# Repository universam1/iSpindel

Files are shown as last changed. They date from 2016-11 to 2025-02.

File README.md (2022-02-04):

# iSpindel - *DIY electronic Hydrometer*

**[www.ispindel.de](http://www.ispindel.de)**

***
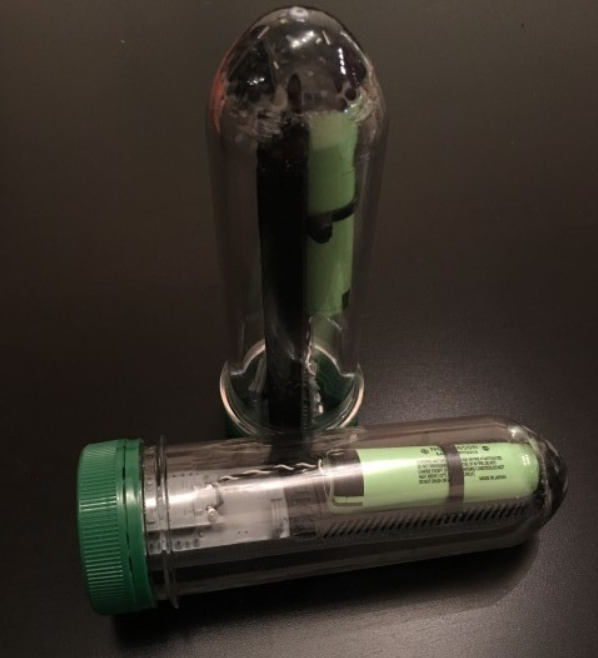
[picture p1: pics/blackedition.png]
Dashboard

***



***

## Featured in german brewing magazine [Braumagazin.de](http://braumagazin.de/?issue=2018-01)

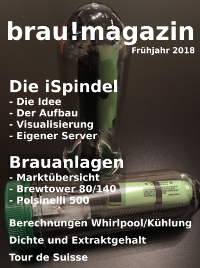
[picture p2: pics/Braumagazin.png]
Braumagazin 1-18 (http://braumagazin.de/?issue=2018-01)


***

If you like that project please vote for the [Hackaday.io *2017 Prize List*](https://hackaday.io/project/20421-ispindel)

Check out [IOT DEVICE PULLS ITS WEIGHT IN HOME BREWING](http://hackaday.com/2017/03/01/iot-device-pulls-its-weight-in-home-brewing/)

## There are FAQs:
### [Deutsche FAQ] - docs/FAQ.md
### [English FAQ] - docs/FAQ-en.md
### [中文 FAQ] - docs/FAQ-zh.md

## Documentation in other languages

### [English Documentation (work in progress)](docs/README_en.md) 🇺🇸

### [Nederlandse Vertaling (lopende werkzaamheden)](docs/README_nl.md) 🇳🇱

### [Documentação em Português (trabalho em andamento)](docs/README_pt.md) 🇧🇷

### [中文文档 (完善中)](docs/README_zh.md) CN

***

***Say thanks with a beer*** :beers:



***

## [Firmware download here](https://github.com/universam1/iSpindel/releases)

***

## ChangeLog

| Date | Note |
| :--- | :--- |
| 10.06.21 | Firmware 7.1.0: Added  support for [BierBot Bricks](https://bierbot.com/#/site/). |
| 05.06.21 | Firmware 7.0.0: migrate to LittleFS (SPIFFS is replaced in favor of LittleFS being its successor) |
| 04.02.21 | Firmware 6.5.1: New tilt equation, support for Brewblox via MQTT, improved calibration tools - thanks for contributions @tomsykes @bdelbosc @vitotai @thegreatgunbantoad and many others |
| 17.11.19 | Firmware 6.2.0: New Calibration routine: The calibration procedure takes now less than 5s only to determine offsets that set the current position of the Accelerometer close as possible to level! Also this new implementation solves a few issues reported where the values have not been saved reliably. Also, the configuration file routine has been improved to support larger strings that were clipped at some point |
| 10.11.19 | Firmware 6.1.3: Extending the length of URL parameter to support API Gateway URLs. Fixes of incompatibilities from #308. Support for latest ESP8266 SDK solving naming collisions |
| 8.11.19 | Firmware 6.1.2: hardening SPIFFS config save routine |
| 27.10.19 | Firmware 6.1.1: Added support for ThingSpeak (#305) (#308), improving documentation, fix for prometheus sender data (#303), updating to new PIO output path |
| 27.10.19 | Firmware 6.1.0:  migrating to ArduinoJSON v6 |
| 27.10.19 | Firmware 6.0.6:  expand size to support longer urls |
| 7.3.2019 | Firmware 6.0.5: Fix Javascript issue with selection of the Service Type |
| 19.12.2018 | Firmware 6.0.4: Higher precision for polynominal possible |
| 19.12.2018 | Firmware 6.0.3: Higher precision for gravity displayed in status page |
| 24.10.2018 | Firmware 6.0.2: Display issues on MacOS resolved |
| 22.08.2018 | **Firmware 6.0.0**:<br>1. Alternative pin for OneWire tempearuture sensor DS18B20 now possible. This allows a different PCB schema to use either pin `D1` or `D6`. <br>2. Auto detection of OneWire pin, successfull detected pin will be saved together with a config `save` action. Output of detailed debug information of OneWire Sensor during searches, helping those with hardware issues. <br>3. Increased battery lifetime of about 20% by reducing the runtime to ~2200ms through various tunings.<br>4. Using *Interrupts* instead of delays to read the Accelerometer, allows significant shorter read intervals <br>5. Shorter read cycles allow  *more precision*, increased samples from 7 to 39 samples that still fit into the necessary wait state for the Temp sensor! |
| 16.08.2018 | Firmware 5.9.1: Fixing Ubidots issue and extending MQTT |
| 09.08.2018 | Firmware 5.9.0: Support for MQTT, InfluxDB (Thanks to jmelhus, iceaway and thorrak) |
| 13.05.2018 | Firmware 5.8.6: allow longer fields for polynominal, SSID and Password |
| 15.03.2018 | Firmware 5.8.5: adding support for Prometheus Pushgateway, thanks to @jankeesv |
| 08.03.2018 | Firmware 5.8.4: adding support for logging temperature data in Fahrenheit and Kelvin, thanks to @iceaway |
| 05.03.2018 | Firmware 5.8.3: Support for InfluxDB as additional backend, thanks to @iceaway |
| 23.02.2018 | New drawer version 'mwx-Edition' using threaded bolt nut and washer - thanks to @mwx |
| 21.02.2018 | Firmware 5.8.2: Extend token size to 40 char to support longer Ubidots token |
| 14.02.2018 | Firmware 5.8.1: HTML encode special character in configuration forms, allows displaying the passwort correctly |
| 09.02.2018 | Firmware 5.8.0: Transmitting the Wifi strength RSSI to insight of the reception |
| 07.02.2018 | Firmware 5.7.1: Allow longer sleep intervals longer up to 99999s == 27 days |
| 03.02.2018 | Firmware 5.7.0: Introduce Factory Reset feature |
| 02.02.2018 | Firmware 5.6.2: Support for Wifi credentials with special characters |
| 07.11.2017 | Firmware 5.6.1: Restoring Wifi credentials, moved to HTTP client library, improved RFCAL resilience to gain more stable Wifi connection |
| 17.10.2017 | Firmware 5.5.4: Various fixes for CraftBeerPi, BrewPiLess and Ubidots |
| 28.09.2017 | Firmware 5.5.0: Recall saved Wifi credential thus persisting over configuration changes |
| 31.08.2017 | iSpindle.py Version 1.3.1: genericTCP Update (local server & prep for public server); Firmware 5.4.2: Memory improvements. |
| 29.08.2017 | Firmware 5.4.1: Rewrite of the upload class to streamline and allow further data items. Also add iSpindel.de as data server as preset. |
| 08.08.2017 | [calibration tool](http://www.ispindel.de/tools/calibration/calibration.htm) to calculate gravity as alternative to the Excel sheet |
| 05.07.2017 | Workaround for BrewPiLess |
| 30.06.2017 | Mentioned in http://preview.mailerlite.com/g6n5p3/660851237247259035/r2w6/ |
| 22.05.2017 | updated build docs |
| 22.05.2017 | switching build environment to platform.io |
| 01.05.2017 | Major Firmware update to 5! Calculate the Gravity now within the iSpindel by expression evaluation! The conversion polynom can be stored per iSpindel and sends as an additional metric (without a unit). Therefore, whether Plato or SG is prefered is up to the user defined polynom. There are two variable available `tilt` and `temp`. Zero point calibration. Firmware update OTA over the Air |
| 12.04.2017 | Mentioned in http://www.homebrewtalk.com/showthread.php?t=598187 |
| 01.03.2017 | Mentioned in hackaday.com http://hackaday.com/2017/03/01/iot-device-pulls-its-weight-in-home-brewing/ |
| 23.02.2017 | English documentation added |
| 14.02.2017 | English documentation added |
| 09.02.2017 | Firmware 4.1.6 |
| 31.01.2017 | Bilder Aufbau Platinenvariante |
| 26.01.2017 | Firmware 4.0: inifinte sleep time developed: the maximum 71min RTC time extends through step-sleeps . Wifi RF calibration introduced when calling configuration. fixed bug of emergency interval. fixed UI numeric formating |
| 25.02.2017 | Firmware 3.5.0: genericTCP: Python Skript um lokal die Daten in eine CSV Datei zu schreiben (thanks to Tozzi) |
| 23.12.2016 | CraftBeerPi Info, FW.3.4.4, Combo-Schlitten |
| 18.12.2016 | FAQ und Ubidots tool |
| 15.11.2016 | Firmware 3.4.2: Supporting now backends: CraftBeerPi, TControl,FHEM, generic HTTP. major Portal rework, added labels for convenience, upload speed improvements, Power saving on empty battery, added custom Battery conversion factor, Bugfixes |
| 11.12.2016 | Sources and drawer online |
| 11.12.2016 | FHEM upload documentation & firmware (thanks @MSBannert!) |
| 07.12.2016 | Schematics |
| 03.12.2016 | Firmware 2.1.2 Wifi improvements |
| 09.11.2016 | Calibration and Excel sheet for conversion to Plato, SG etc. |

***

> Contribution and support is appreciated especially regarding creation and translation of documentation. Feel free to provide a `pull request`.  
>
> Die `iSpindel` befindet sich in andauernder Entwicklung, siehe dazu [den Hobbybrauer.de Thread](http://hobbybrauer.de/forum/viewtopic.php?f=7&t=11235). Mithilfe ist herzlich willkommen und Ergänzungen bitte per Pull Request einreichen. Großes Dank an alle die Unterstützung leisten seitens Grundlagen erarbeiten oder passende Hardware zu finden.

## Inhaltverzeichnis

- [iSpindel - *DIY electronic Hydrometer*](#ispindel-diy-electronic-hydrometer)
  - [Featured in german brewing magazine Braumagazin.de](#featured-in-german-brewing-magazine-braumagazinde)
  - [There are FAQs:](#there-are-faqs)
    - [[Deutsche FAQ] - docs/FAQ.md](#deutsche-faq-docsfaqmd)
    - [[English FAQ] - docs/FAQ-en.md](#english-faq-docsfaq-enmd)
    - [[中文 FAQ] - docs/FAQ-zh.md](#中文-faq-docsfaq-zhmd)
  - [Documentation in other languages](#documentation-in-other-languages)
    - [English Documentation (work in progress) 🇺🇸](#english-documentation-work-in-progress-)
    - [Nederlandse Vertaling (lopende werkzaamheden) 🇳🇱](#nederlandse-vertaling-lopende-werkzaamheden-)
    - [Documentação em Português (trabalho em andamento) 🇧🇷](#documentação-em-português-trabalho-em-andamento-)
    - [中文文档 (完善中) CN](#中文文档-完善中-cn)
  - [Firmware download here](#firmware-download-here)
  - [ChangeLog](#changelog)
  - [Inhaltverzeichnis](#inhaltverzeichnis)
  - [Lizenz](#lizenz)
  - [Prinzip](#prinzip)
    - [*Metazentrum*](#metazentrum)
  - [Aufbau](#aufbau)
    - [Varianten](#varianten)
    - [Bauteile](#bauteile)
    - [Schaltplan](#schaltplan)
    - [Schlitten](#schlitten)
  - [Konfiguration](#konfiguration)
    - [Test Server](#test-server)
    - [Ubidots](#ubidots)
      - [Portal](#portal)
    - [BierBot Bricks](#bierbot-bricks)
    - [Scripting](#scripting)
  - [Anzeige](#anzeige)
    - [Ubidots Graphen](#ubidots-graphen)
    - [CraftBeerPi](#craftbeerpi)
    - [FHEM](#fhem)
    - [iSpindel-TCP-Server](#ispindel-tcp-server)
  - [Kalibrierung](#kalibrierung)
  - [Software](#software)
    - [Firmware flashen](#firmware-flashen)
    - [Compile from Source](#compile-from-source)

***

## Lizenz

> Jeglicher kommerzieller Nachbau oder Verwendung ist prinzipiell untersagt. Geltende Patente werden verletzt.
>
> All rights reserverd, any commercial use is hereby prohibited and will violate applicable patents.

***

## Prinzip

Die Messung der Dichte von Wasser mit Hilfe des krängenden Zylinders ist so einfach wie genial - man braucht keine externe Referenz (außer der Erde) und der Zylinder ist extrem leicht sauber zu halten. Der Neigungswinkel ändert sich im Verhältnis zum Auftrieb und damit im direkten Zusammenhang mit dem Zuckergehalt.
Kein unnötiges Öffnen zum spindeln und evtl. Kontaminieren!

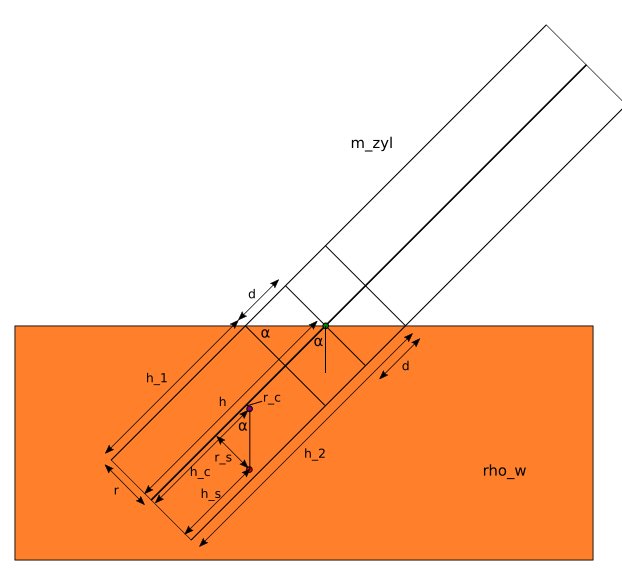
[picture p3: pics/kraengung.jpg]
Kränung


Daher die Idee, ein IoT device mit Wifi zusammen mit einem Beschleunigungssensor und Temperatursensor in einen schwimmenden Zylinder zu legen. Dort wacht er alle bsp. 5min auf, verbindet sich mit meinem Wlan und sendet seinen Neigungswinkel, Temperatur und Akkuspannung an einen Cloudservice wie [Ubidots](www.ubidots.com) oder einen lokalen Server.

### *Metazentrum*

Eigentlich dreht es sich hier um das "Metazentrum", der Zylinder wird solange rotieren bis das Metazentrum im Lot zum Auftriebspunkt ist. Diesen Wert messen wir.

Man kann insofern trimmen, dass man am Boden ein paar Gramm hinzufügt, damit stellt sich der Zylinder mehr auf, oder am Deckel, damit krängt er mehr. 

In der Software berechnent man aus den XYZ Beschleunigungswerten den Euler Winkel für X und Y und bildet daraus den Absolutwinkel. Diesen verrechnen wir mit den kalibrierten Eckwerten zum °Plato.

***

## Aufbau

### Varianten

> Alle drei Varianten sind funktionell identisch

1. [Variante A: Lochrasterplatine & Schlitten](docs/iSpindelbreadboard.md)  
Die Lochrasterplatine ermöglicht den Nachbau jederzeit mit 'Hausmitteln' 
1. [Variante B: nur Platine](docs/iSpindelPCB.md)  
Die fertige Platine über die Sammelbestellung bringt einen komfortablen Aufbau
1. [Variante C: Platine & Schlitten](docs/iSpindelPCB.md)  
Die obige Platine kann (über Trenn-Schnitt) mit dem Kunstoff Schlitten in Kombination verwendet werden der einen spielfreien Sitz garantiert.

### Bauteile

***siehe [Bauteile](docs/Parts.md)***

### Schaltplan

***siehe [Schaltplan](docs/Schaltplan.md)***

### Schlitten

***siehe [Bauteile](docs/Parts.md)***

***

## Konfiguration

### Test Server

[simple test server](tools/TestServer/Readme.md)

### Ubidots

- Zu Beginn muss ein kostenloser Account bei [Ubidots.com](https://ubidots.com) erstellt werden
- Im Menü  `API Credentials` erhält man seinen `Token` durch das die iSpindel die Berechtigung zum Schreiben der Daten erhält.  
***Diesen notieren.***  

Token

#### Portal

Durch mehrmaliges Drücken der `Reset Taste` erstellt der Wemos einen AccessPoint, mit dem verbunden man die nötigen Einstellugen vornehmen kann.

> Die `iSpindel` signalisiert dass sie sich im *Konfiguration-Modus* druch permanentes Blinken im Sekundentakt.  
Man verlässt den *Konfiguration-Modus* durch speichern seiner Einstellungen, durch betätigen des Menüpunkts `Start iSpindel` oder durch warten von 5 Minuten. Danach befindet sie sich im *Betriebsmodus* d.h. sie sendet ihre Daten und geht daraufhin direkt in den "Deep Sleep" Standby Modus. Daher ist sie im normalen Modus nicht erreibar.

- Der Ubidots  `Token` ~~und die  `IDs`~~, welche man oben notiert hat, werden nun an dieser Stelle eingetragen.  

- Ebenfalls stellt man hier den `Intervall` ein in dem sie Daten liefert. Dies hat direkt mit der Akku Lebensdauer zu tun. Es empfiehlt sich in der Praxis etwa `1800` Sekunden (= 30 Minuten) Takt zu wählen.

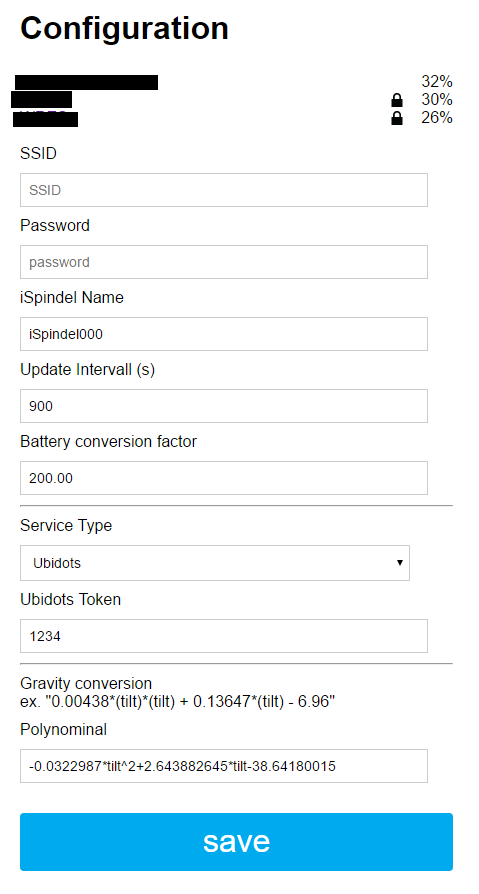
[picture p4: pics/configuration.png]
Setup
   

- Man erreicht es über

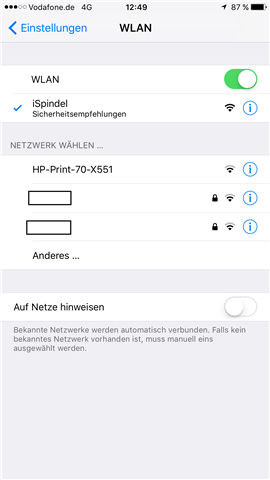
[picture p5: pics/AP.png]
AccessPoint
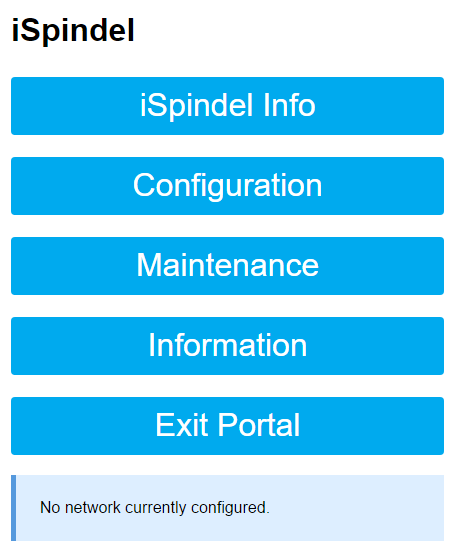
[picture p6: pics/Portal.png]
Portal
   

- Eine Übersicht der Daten kann man über den `Info` Menüpunkt einsehen

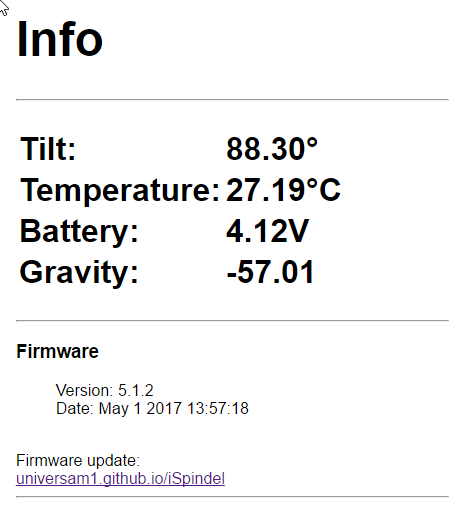
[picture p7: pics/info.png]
Info
  

Nach dem man obige Daten eingetragen und gespeichert hat, wird die Spindel sich mit dem Wlan und Ubidots verbinden und die Daten übertragen.  
Falls noch nicht vorhanden, wird selbständig ein neues `Device` erstellt und die Sensoren angelegt.  
Auf der Ubidots Weboberfläche wird man nun unter `Sources` sehen dass die Daten aktualisiert werden.  

Nun kann man im `Dashboard` sich seine Graphen nach Belieben zusammenstellen.

### BierBot Bricks

Die Einrichtung mit BierBot Bricks ist einfach und kostenlos. Ihr benötigt hierfür die iSpindel Firmware > `7.1.0`. 

1. Zunächst müsst ihr einen kostenlosen Account erstellen. [Zur Registrierung](https://bricks.bierbot.com/#/register).
2. Nach der Registrierung links im Menü auf "Bricks" (siehe 1. im Bild).
3. Dort klickt ihr nun auf den blauen "Add Brick" / "Brick hinzufügen" oben rechts.
4. Wählt den "iSpindel"-Tab im Popup und kopiert den API key in die Zwischenablage.
5. Ruft nun das Konfigurationsportal eurer iSpindel auf (die iSpindel erstellt einen Accesspoint durch mehrmaliges Drücken der Reset-Taste, s. [hier](#portal))
6. Wählt als Service "BierBot Bricks" aus (siehe 2 im Bild).
7. Fügt nun unter "Token/ API key" den API key aus euer Zwischenablage ein und klickt ganz unten auf den blauen Speichern-Button.
8. Geht nun zurück auf [bricks.bierbot.com](https://bricks.bierbot.com/#/) und wählt "Equipment" bzw. "Brauanlagen" auf der linken Seite aus (3 im Bild).
9. Erstellt nun ein neues Gerät (blauber Button rechts oben) vom Typ "**Fermenter**".
10. Weißt nun durch **Drag & Drop** von der iSpindel auf den entsprechenden Platz (grün markiert) des Fermenters den Würzesensor zu (optional könnt ihr dies nun auch für die Temperatur machen).
11. Klickt "Save" / "Speichern".
12. Um die Aufzeichnung zu starten, benötigen wir nun noch ein Rezept. Erstellt dieses unter Rezepte (es reicht eine Fermentationsrast), speichert es, und startet es über den oragenen Knopf in der Rezeptübersicht. 

**Fertig!**

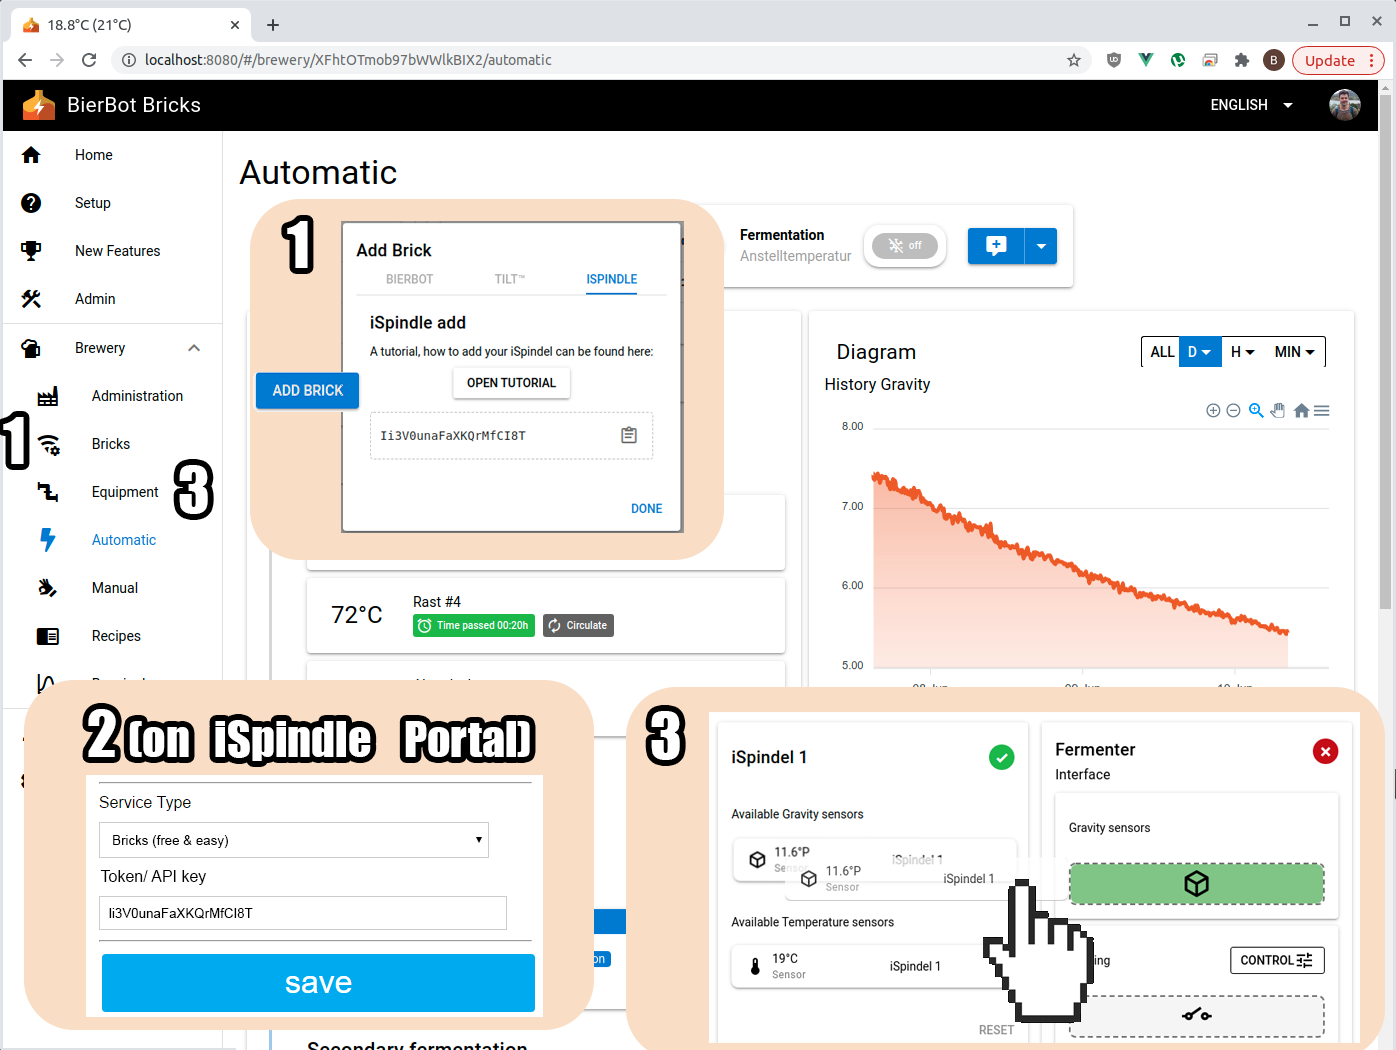
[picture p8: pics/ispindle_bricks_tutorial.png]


### Scripting

Ubidots kann ausserdem an vielen Stellen per Script bedient werden. Eine Dokumentation zu den Funktionen findet sich direkt bei Ubidots. Hiermit können zum Beispiel nicht mehr benötigte Daten in Variablen gelöscht werden.

- [siehe Ubidots-Scripting](docs/ubidotsscripting.md)

***
## Anzeige

Die `iSpindel` kann ihre Daten an verschieden backends senden. Es empfiehlt sich mit dem Cloudservice [Ubidots](www.Ubidots.com) zu beginnen, dort kann man sich einen kostenlosen Account erstellen und die Graphen sich darstellen. Man kann auch weitere Abwandlungen der Daten vornehmen, wie den Plato / SG Wert errechnen, den EVG usw.
Folgende backends werden mittlerweile unterstützt:

### Ubidots Graphen

- [Plato Formel](docs/Kalibrierung.md#formel)

### CraftBeerPi

> Beschreibung von @not:  
*Wenn Du die neueste Firmware auf Deine iSpindel geflasht hast musst Du auch craftbeerpi updaten: dazu brauchst Du den branch "hydrometer". Wenn Du die Spindel dann konfigurierst, gibst Du neben den Einstellungen für Dein WLAN im Dropdown-Menu "CraftbeerPi" an und darunter die IP Adresse Deines im selben Netzwerk gelegenen Craftbeerpi-Servers.
Danach sendet die Spindel an den Raspberry Pi -Rechner und Craftbeerpi registriert die Spindel automatisch . Wenn die Verbindung klappt, findest Du die Spindel "wie von Geisterhand" in der Hardware-Konfiguration von CBP.
Du siehst, dass Daten ankomen, wenn Du Deine Fermentation / Gärung im CBP anschaust, da sind dann nicht nur die Temperatur (ist und soll) , sondern auch Spindeltemperatur und Plato zu sehen (siehe Screenshot oben) mit letztem Zeitstempel.*  
`git clone -b hydrometer https://github.com/Manuel83/craftbeerpi.git`

### FHEM

- [upload zu FHEM](docs/upload-FHEM.md)

### iSpindel-TCP-Server

- [https://github.com/DottoreTozzi/iSpindel-TCP-Server](https://github.com/DottoreTozzi/iSpindel-TCP-Server)

***

## Kalibrierung

Zur Umrechnung von dem gemessenen **Winkel ° in °Plato, SG, %mas** o.ä. ist es initial nötig eine Referenzkurve zu kalibrieren. 
Die gewonnenen Referenzen können dann über eine Excel Tabelle oder das [Online Gravity Calibration tool](http://www.ispindel.de/tools/calibration/calibration.htm) in eine Funktion überführt werden, die zur Darstellung hinterlegt wird. 

Da jede selbstgebaute Spindel andere Messwerte ergeben wird, muss man diesen Prozess einmalig pro iSpindel durchführen.

[siehe Kalibrierung durchführen](docs/Kalibrierung.md)

***

## Software 

### Firmware flashen

- [Firmware flashen](docs/Firmware.md)

### Compile from Source

- [Compile from source](docs/compile.md)

***Gefällt es dir, na dann spende mir halt ein Bier***  :beers:



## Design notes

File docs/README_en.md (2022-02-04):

# iSpindle Documentation

***Translation is work in progress, feel free to contribute!
This translation might be out of sync with the original german one, please double check***

iSpindle (iSpindel) Documentation
===================

**DIY electronic Hydrometer**
***Please consider supporting this project***  



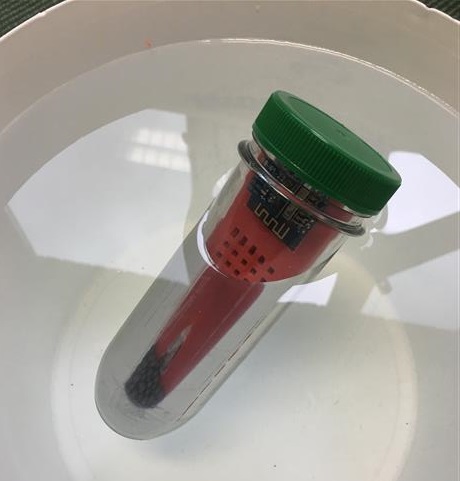
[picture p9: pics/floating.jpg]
iSpindle in clean water

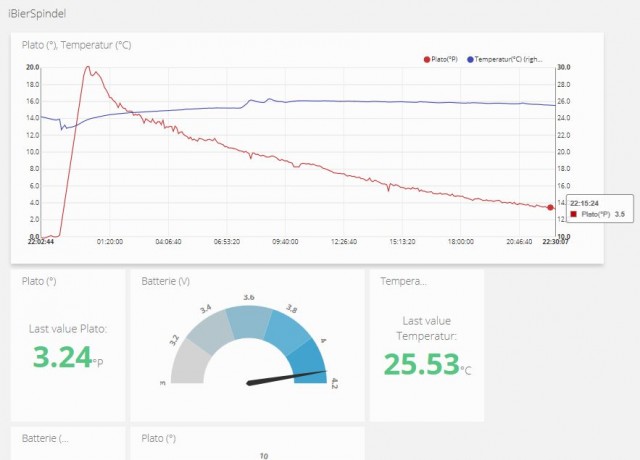
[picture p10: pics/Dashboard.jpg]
Dashboard


## Table of Contents

- [FAQ](FAQ-en.md)
- [Parts](Parts_en.md)
- [Calibration](Calibration_en.md)
- [Circuit Diagram](circuit_diagram_en.md)
- [Upload FHEM](upload-FHEM_en.md)
- [Ubidots scripting](ubidotsscripting_en.md)

- [iSpindle Documentation](#ispindle-documentation)
- [iSpindle (iSpindel) Documentation](#ispindle-ispindel-documentation)
  - [Table of Contents](#table-of-contents)
  - [License](#license)
  - [Principle](#principle)
    - [*Metacentric Height*](#metacentric-height)
  - [Construction](#construction)
    - [see Parts](#see-parts)
    - [see Sourcing](#see-sourcing)
    - [see Circuit Diagram](#see-circuit-diagram)
    - [see iSpindel Breadboard Mounting](#see-ispindel-breadboard-mounting)
    - [Drawer](#drawer)
  - [Configuration](#configuration)
    - [Test Server](#test-server)
    - [Ubidots](#ubidots)
      - [Portal](#portal)
    - [BierBot Bricks](#bierbot-bricks)
    - [Blynk](#blynk)
      - [Cloning the Example](#cloning-the-example)
      - [Using your own App](#using-your-own-app)
    - [MQTT](#mqtt)
      - [Home Assistant](#home-assistant)
      - [Other MQTT broker](#other-mqtt-broker)
  - [Graphical User Interface](#graphical-user-interface)
    - [Calibration](#calibration)
    - [Ubidots Graphen](#ubidots-graphen)
    - [CraftBeerPi](#craftbeerpi)
  - [Software](#software)
    - [Firmware flashing](#firmware-flashing)

***

## License

> All rights reserverd, any commercial use is hereby prohibited and will violate applicable patents.

***

## Principle

Powered by the thread [Alternative to the Spindle](http://hobbybrauer.de/forum/viewtopic.php?f=7&t=11157&view=unread#p170499), the idea was born to reproduce the commercially available electronic tilting spindle using low-cost components.

The system is based around the use of a heeling (or tilting) cylinder, an ingenious and easy concept - you do not need any external reference (except for gravity) and the cylinder is extremely easy to keep clean. The inclination angle changes in relation to the buoyancy and thus directly in relation to the sugar content. There is an angle formed between the center of mass and the center of bouyancy depending on the density of the fluid.

Kränung

Therefore the idea  is to place a Wifi-enable IoT device with an accelerometer and temperature sensor in a floating cylinder. The system will measure the sensors and every x-minutes it will connect to the Wifi and sends its tilt angle, temperature and battery voltage to a cloud service like Ubidots.com to store the data.

With an update interval of 30min it was possible to achive a battery lifetime of almost 3 months!

### *Metacentric Height*

Actually, this is the "metacentre", the cylinder will tilt as the liquid density changes in relation to its center of mass and center of bouyancy. The angle of tilt can then be measured. 

It is possible to trim the cylinder by adding a few grams on the bottom so that the cylinder is more upright, or on the lid, so that it is more tilted.

The software calculates the Euler angle for X and Y from the XYZ acceleration values and forms the absolute angle. We compute these with the calibrated parameters to ° Plato, SG or similar by correlating to measured references.

***

## Construction

### see [Parts](Parts_en.md)

### see [Sourcing](Parts_en.md)

### see [Circuit Diagram](circuit_diagram_en.md)

### see [iSpindel Breadboard Mounting](iSpindelbreadboard_en.md)

***

### Drawer
- A 3D Printed drawer is used to secure the electronics and battery inside the plastic housing as shown below. The 3D model can be found in the repository.
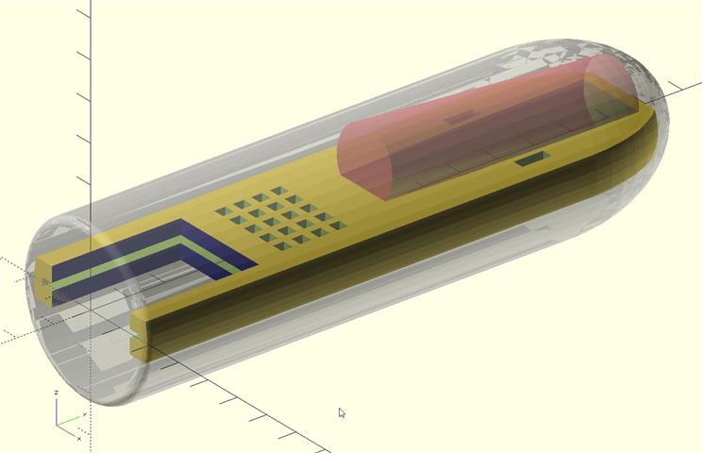
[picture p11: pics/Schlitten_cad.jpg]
Sled

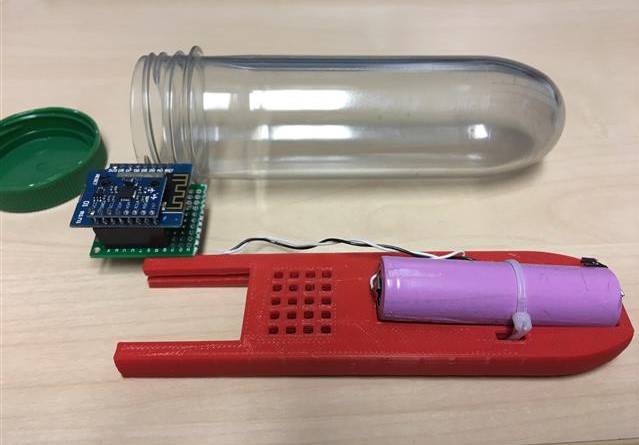
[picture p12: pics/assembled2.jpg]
Assembled

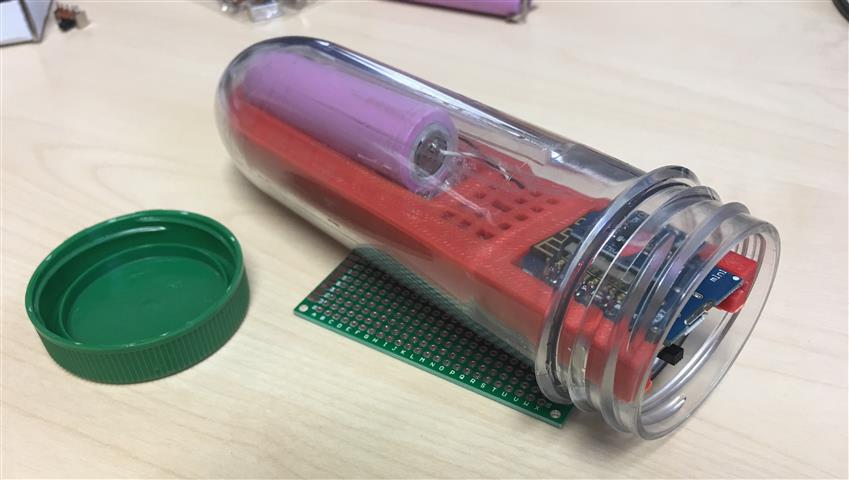
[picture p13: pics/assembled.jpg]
Assembled


<a href="http://www.youtube.com/watch?feature=player_embedded&v=gpVarh8BxhQ" target="_blank">Druck</a>

***

## Configuration

### Test Server

[simple test server](../tools/TestServer/Readme.md)

### Ubidots

- To start, you must create a free account at [Ubidots.com](https://ubidots.com)
- Next, you must go to the menu  ```API Credentials``` to get a ```Token``` to be used by the iSpindle to authorize writing data to the Ubidots account.
***Write this down.***  
Token  

#### Portal

By pressing the  ```Reset Button``` the Wemos creates an access point, which allows you to make the necessary settings to configure the device. **In `operation mode` this portal is not active or accessible because the principle of this design is based on shorted possible acitve time. Basically it will wake up, send its data and deep sleep again. This takes now less than 3s which is directly related to its long life run time.

> The ```iSpindel``` signals the `config mode` by blinking the LED at a 1s interval.  
By saving your settings or waiting timeout of 5min it will end the Portal thus AccessPoint and try to go into `operation mode`.

   Setup

   AccessPointPortal

  Info

> In Ubidots you can monitor the update of data unders ```Sources``` where the iSpindel will create a new device itself.  
In the ```Dashboard``` now you can create your nice graphs.

### BierBot Bricks

The setup with BierBot Bricks is easy and for free. You will need the iSpindle Firmware  `7.1.0` or later. 

1. Create a free BierBot Bricks account [here](https://bricks.bierbot.com/#/register).
2. After Registration, select "Bricks" in the menu on the left (see 1 in the picture).
3. Hit the blue "Add Brick" button in the top right corner.
4. Select "iSpindel" in the popup and copy the displayed API key into your clipboard.
5. Now open the configuration portal of your iSpindel (by pressing reset multiple times, see [portal](#portal) for more info).
6. Select "BierBot Bricks" as service (see 2 in the image).
7. Paste the api key from your clipboard into the "Token/ API key" field and hit the blue save bottom at the bottom.
8. Now go back to [bricks.bierbot.com](https://bricks.bierbot.com/#/) and select "Equipment" in the menu on the left (see 3 in the image).
9. Create a new device (blue button, top right corner), select "**Fermenter**" in the popup.
10. Now assign the gravity sensor from the iSpindle to the respective field of your fermeter by **drag & dropping** - the respective target dropzone on your fermenter will be highlighted green to guide you. You can do the same for your temperature sensor, but this is optional.
11. Hite "Save".
12. To start recording, we will also need a recipe. Go to "Recipes" on the left and create a recipe. You only need to setup one (dummy) fermentation step. Save the recipe and go back to the list of recipes. Start your recipe by clicking the orange play button.

**Done!**

Bricks tutorial

### Blynk

#### Cloning the Example

* For this example you will need 1800 (4x200 + 100 + 900) energy points, which allows to use the free version;
* Download Blynk App: [Android](http://j.mp/blynk_Android) [iOS](http://j.mp/blynk_iOS)
* Touch the QR-code icon and point the camera to the code below


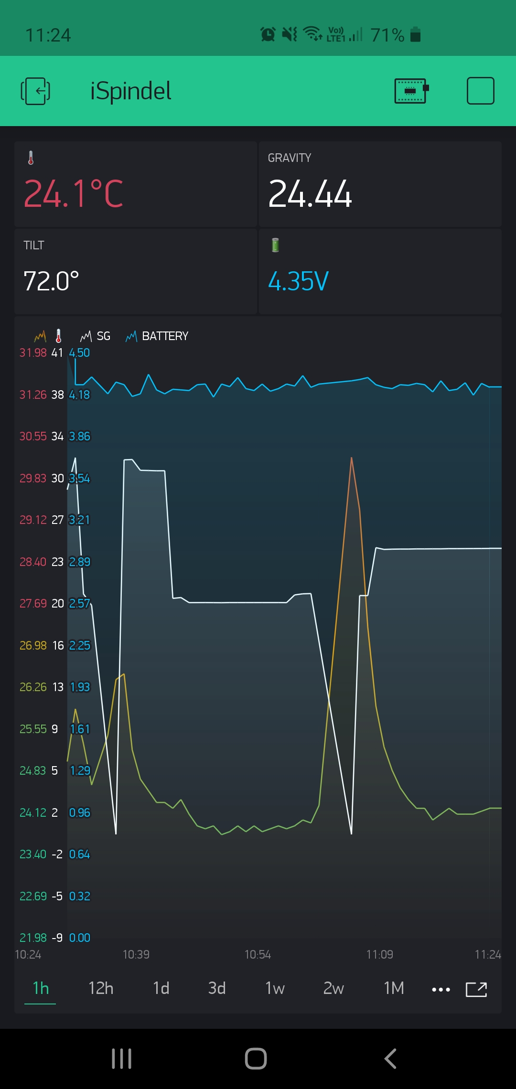
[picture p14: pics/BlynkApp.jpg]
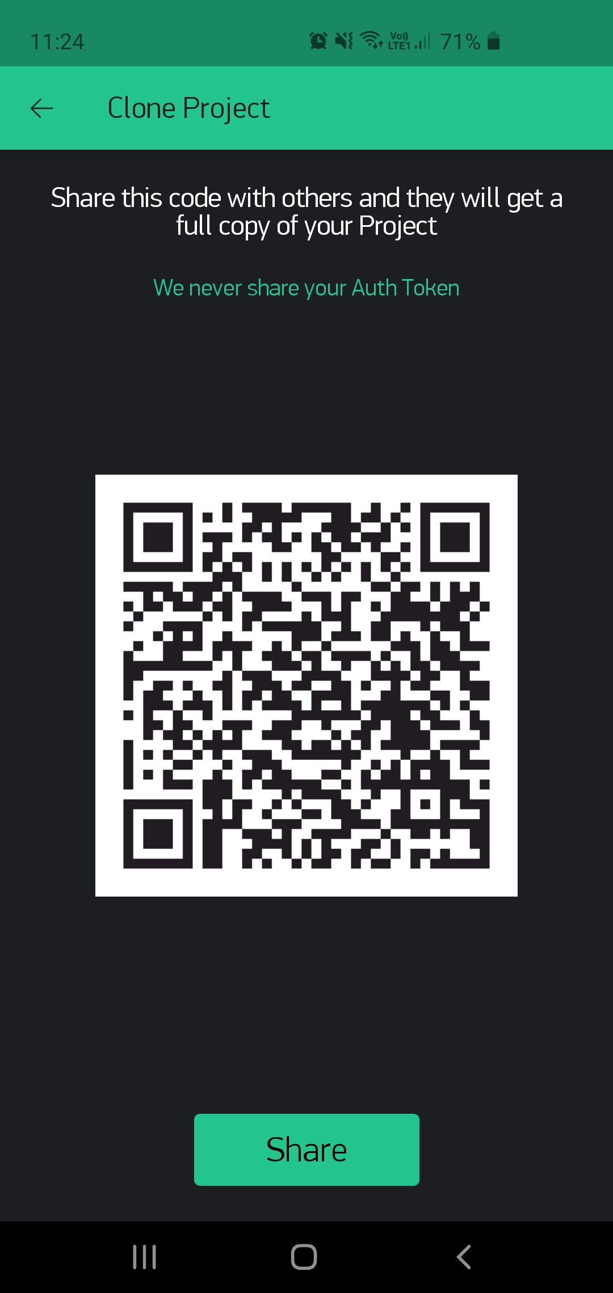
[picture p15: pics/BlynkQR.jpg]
  

* Enjoy the app!

#### Using your own App

* If you want to use your own App or modify the example the Virtual Pins are defined as follows:
1. V20 - Temperature withouth unit;
2. V30 - Battery without unit;
3. V1 - String Tilt in degress;
4. V2 - String Temperature degress `C or F or K`;
5. V3 - String Battery `Volts`;
6. V4 - Gravity;

### MQTT
* You can configure the MQTT broker (server) in the configuration page.

#### Home Assistant
* There is a check box to make iSpindel integration automatically in HomeAssistant using Mosquitto
#### Other MQTT broker
Each value transmitted bu iSplindle is sent on its own topic.
Topics are : 
* ispindel/```Devices' name```/temperature
* ispindel/```Devices' name```/tilt
* ispindel/```Devices' name```/battery
* ispindel/```Devices' name```/RSSI
* ispindel/```Devices' name```/gravity

***
## Graphical User Interface

### Calibration

> In order to convert the measured iSpindle angle to degrees Plato (°Plato), density (SG), or other units, it is necessary to first calibrate the sensor by making several reference measurements of sugar water of known gravities. These reference measurements can then be converted to a mathematical function which is stored for later measurements and display. Since each self-assembled iSpindle will  have different measured values, each device must be individually calibrated after assembly or reassembly to yield accurate measurements. A detailed procedure is below.

[Calibration Procedure](Calibration_en.md)

### Ubidots Graphen

- [Plato Formula](Calibration_en.md#forumla)

### CraftBeerPi

[CraftBeerPi](https://github.com/universam1/iSpindel/issues/3)
***

## Software 

### Firmware flashing

[Firmware flashing](Firmware_en.md)

***if you like it, let me know***  :beers:



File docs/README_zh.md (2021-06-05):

# iSpindle 文档

***翻译工作正在进行中，欢迎大家贡献力量！此翻译基于英语文档进行翻译，可能与德文原文不一致，请悉知***

iSpindle (ispindel) 文档
===================

**DIY 无线比重计**
***请考虑支持这个项目***  



iSpindle in clean water
Dashboard

## 目录

- [常见问题](FAQ-zh.md)
- [组件](Parts_zh.md)
- [校准](Calibration_zh.md)
- [电路图](circuit_diagram_zh.md)
- [FHEM 上传](upload-FHEM_zh.md)
- [Ubidots 脚本](ubidotsscripting_zh.md)

- [iSpindle 文档](#ispindle-文档)

  - [目录](#目录)
  - [声明许可](#声明许可)
  - [原理](#原理)
    - [*稳心高度*](#稳心高度)
  - [构造](#构造)
    - [详见 组件](#详见-组件)
    - [详见 零部件](#详见-零部件)
    - [详见 电路图](#详见-电路图)
    - [详见 iSpindel 面包板接入](#详见-ispindel-面包板接入)
    - [草图](#草图)
  - [配置](#配置)
    - [Ubidots](#ubidots)
    - [设置模式](#设置模式)
    - [Blynk](#blynk)
      - [演示案例](#演示案例)
      - [使用你自己的程序](#使用你自己的程序)
  - [图形用户界面](#图形用户界面)
    - [校准](#校准)
    - [Ubidots 曲线图](#ubidots-曲线图)
    - [CraftBeerPi](#craftbeerpi)
  - [软件](#软件)
    - [固件刷入](#固件刷入)

***

## 声明许可

> 作者保留所有权利，特此禁止任何违反适用专利的商业用途

***

## 原理

受 [Alternative to the Spindle](http://hobbybrauer.de/forum/viewtopic.php?f=7&t=11157&view=unread#p170499) 帖子启发, 诞生了采用低成本组件来复刻商业电子倾斜测量仪器的想法。

该系统是基于倾斜圆柱体的应用，这是一个巧妙而简单的概念。你不需要任何其它外部的参考（重力除外），而且圆柱体也是非常容易保持清洁的。倾斜角度的变化和浮力有关，因此与糖含量直接相关。质量中心与浮力中心之间会形成一个角度公式，取决于所在液体的密度。

Kränung

因此我们的想法是将一个带有加速度传感器以及温度传感器的无线物联网设备放进一个能浮起的圆柱体当中。该系统利用传感器进行测量，每隔x分钟连接到 Wifi 并将其倾斜角度、即时温度以及电池电量发送到云端服务器，比如 Ubidots.com ，以便存储数据。

在 30 分钟的更新间隔下，它可以实现 3 个月左右的电池寿命！

### *稳心高度*

实际上这就是 “稳心”，圆柱体会随着液体密度与其质量中心和浮力中心的变化而倾斜，倾斜角度可以被测量。

调整圆柱体可以通过在底部增加些少许克重，使圆柱体更加直立，或在盖子增加几克，使其更加倾斜。

软件会从 XYZ 加速器得到的 X 和 Y 的数值计算欧拉角度并形成绝对角度，我们通过柏拉图度、比重值或类似相关的测量参考值的校准参数来进行计算。

***

## 构造

### 详见 [组件](Parts_zh.md)

### 详见 [零部件](Parts_zh.md)

### 详见 [电路图](circuit_diagram_zh.md)

### 详见 [iSpindel 面包板接入](iSpindelbreadboard_zh.md)

***

### 草图
- 如下图所示，3D打印的板用来固定塑料外壳内部的电子元件和电池，该 3D 模型可以在代码仓库里找到
Sled
Assembled
Assembled

<a href="http://www.youtube.com/watch?feature=player_embedded&v=gpVarh8BxhQ" target="_blank">Druck</a>

***

## 配置

### Ubidots

- 首先，必须在 [Ubidots.com](https://ubidots.com) 创建一个免费的帐户
- 接下来, 你需要转至菜单  ```API Credentials``` 以获取 ```Token``` 用于 iSpindel 授权向 Ubidots 账户写入数据。
***把它记下来***  
Token  

### 设置模式

通过按下  ```复位按钮``` 创建一个接入点，将允许你进行必要的设置来配置设备。在 `操作模式` 下的接入口是不显示的而且也不可访问，因为设计的原则是基于尽可能地缩短活跃时间。基本上它从醒来到发送数据并再次深度睡眠，需要不到三秒的时间，这样能使系统长时间运行下去。

> ```iSpindel``` 通过以 1s 的间隔闪烁 LED 指示灯显示进入 `配置模式` 。 
通过保存您的设置或等待五分钟的超时，它将结束访问接入点并尝试回到 `操作模式` 。

   ![Setup](/pics/configuration.png)

   ![AccessPoint](/pics/AP.png)![Portal](/pics/Portal.png)

  ![Info](/pics/info.png)

> 在 Ubidots ```Sources``` 一栏你可以监控更新的数据，iSpindel 会自行创建一个新的设备.  
现在你可以在 ```Dashboard``` 中创建好看的图表。

### Blynk

#### 演示案例

* 以这个例子来说，你需要 1800 (4x200 + 100 + 900) 个能量值才可以使用免费的版本;
* 下载 Blynk 应用程序：[Android](http://j.mp/blynk_Android) [iOS](http://j.mp/blynk_iOS)
* 扫描点击二维码图标并将相机对准底下的代码。
<p><img src="https://image.ibb.co/gxZFDz/Untitled.png" height="95" /></p>

<img src="/pics/BlynkApp.jpg" width="35%" />  <img src="/pics/BlynkQR.jpg" width="35%" />

* 请享用！

#### 使用你自己的程序

* 如果你想使用自己的应用程序或者尝试进行修改，传输端口的定义如下：
1. V20 - 不含单位的温度;
2. V30 - 不含单位的电量;
3. V1 - 倾斜角度数值;
4. V2 - `摄氏/华氏/开尔文` 温度数值;
5. V3 - 电量数值 `伏特`;
6. V4 - 重力;

***
## 图形用户界面

### 校准

> 为了将测量的 iSpindle 角度转换为柏拉图度（°Plato）、比重值（SG）或其他单位，有必要首先对传感器进行校准，通过已知比重的糖溶液进行多次参考测量。然后可以将这些参考测量值转换为一个数学函数，存储起来以供后续的测量和显示。由于每个自行组装的 iSpindle 会有不一样的测量数值，所以每个设备在组装或重装后必须单独进行校准，以获得准确的测量结果，详细的过程如下所示。

[校正程序](Calibration_zh.md)

### Ubidots 曲线图

- [柏拉图度计算公式](Calibration_zh.md#forumla)

### CraftBeerPi

[CraftBeerPi](https://github.com/universam1/iSpindel/issues/3)
***

## 软件 

### 固件刷入

[刷入固件](Firmware_zh.md)

***如果你喜欢, 请多多支持***  :beers:

[![Donate](https://www.paypalobjects.com/de_DE/DE/i/btn/btn_donate_LG.gif)](https://www.paypal.me/universam)

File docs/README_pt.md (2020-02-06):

# Documentação do iSpindle

***A tradução é um trabalho em constante progresso. Fique à vontade para contribuir!
Esta tradução talvez esteja dessincronizada com a versão original escrita em alemão. Por favor, tenha isto em mente antes de ler esta versão.***

## [Components](Parts_pt.md)

## [Calibração](Calibration_pt.md)

## [Diagrama do Cirtuito](circuit_diagram_pt.md)

## [Upload para FHEM](upload-FHEM_pt.md)

## [Script para Ubidots](ubidotsscripting_pt.md)

Documentação do iSpindle (iSpindel)
===================

**Densímetro digital DIY**
***http://www.ispindel.de***

***Por favor, considere a possibilidade de patrocinar este projeto***  



iSpindle in clean water
Dashboard

## Table of Contents

- [Licença](#licença)
- [Princípio](#princípio)
  - [Peso metacêntrico](#peso-metacêntrico)
- [Construção](#construção)
  - [Componentes](#componentes)
  - [Diagrama do circuito](#diagrama-circuito)
  - [Gaveta](#gaveta)
- [Configuração](#configuração)
  - [Ubidots](#ubidots)
  - [Portal](#portal)
  - [Blynk](#blynk)
- [Interface Gráfica do Usuário](#interface-gráfica-usuário)
  - [Calibrando o iSpindle](#calibração)
  - [Gráficos Ubidots](#gráficos-ubidots)
  - [CraftBeerPi](#craftbeerpi)
- [Software](#software)

***

## Licença

> Todos os direitos são reservados. Qualquer uso comercial é proibido e violará as patentes aplicáveis.

***

## Princípio

Impulsionada por este tópico [Alternativa ao Spindle](http://hobbybrauer.de/forum/viewtopic.php?f=7&t=11157&view=unread#p170499), a ideia nasceu para reproduzir o produto comercial spindle utilizando componentes de baixo custo.

O sistema é baseado no conceito de inclinação de um cilindro, um conceito ao mesmo tempo simples e engenhoso - você não necessita de nenhuma referência externa (exceto da gravidade) e o cilindro é extremamente simples de limpar. O ângulo de inclinação muda devido ao empuxo e possui relação direta com a concentração de açúcar contida no líquido. Será formado um ângulo entre o centro de massa e o centro do empuxo que é dependente da densidade do líquido.

Kränung

Desta forma a ideia é incluir um dispositivo com funcionalidade Wifi com um acelerômetro e sensor de temperatura dentro de um cilindro que flutuará no líquido. O sistema medirá por meio dos sensores a cada x minutos, conectará à internet via Wifi e enviará informações sobre o ângulo, temperatura e tensão da bateria para um serviço na nuvem como Ubidots.com para armazenamento dos dados.

Com um intervale de update a cada 30 minutos é possível obter uma vida útil da bateria de praticamente 3 meses!

### *Peso metacêntrico*

Este é o conceito de "metacentro": O cilindro mudará o ângulo de inclinação quanda a densidade do líquido mudar em relação ao seu centro de massa e o centro de empuxo. O ângulo de inclinação então poderá ser medido. 

É possível mudar o ângulo de inclinação inicial do cilindro adicional alguns pesos na base do cilindro para que ele fique mais em pé ou na tampa para deixá-lo mais inclinado.

O software calcula o ângulo de Euler devido aos valores de X e Y dos valores de aceleração de XYZ e forma um ângulo absoluto. Nós registramos estes valores com os parâmetros ajustados para ° Plato, SG ou similar correlacionando com as referências medidas.

***

## Construção

### Veja [Componentes](Parts_pt.md)

### Veja [Fontes](Parts_pt.md)

### [Diagrama do Circuito](circuit_diagram_pt.md)
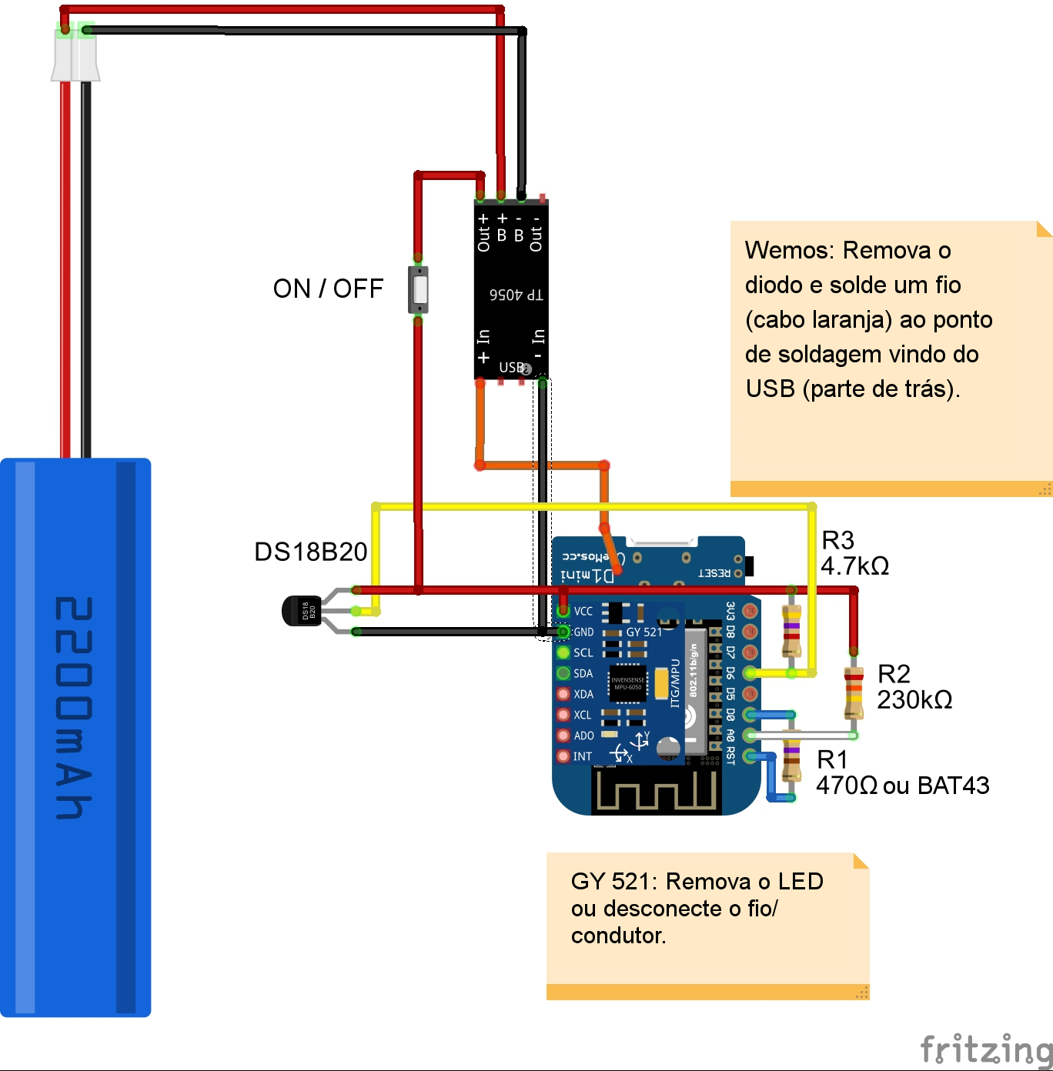
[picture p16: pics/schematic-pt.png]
Schematic


***

### Gaveta
- Uma gaveta impressa em 3D é utilizada para fixar todos os componentes além da bateria dentro do cilindro plástico conforme mostrado a seguir. O modelo 3D pode ser obtido no repositório.
Gaveta
Montada
Montada

<a href="http://www.youtube.com/watch?feature=player_embedded&v=gpVarh8BxhQ" target="_blank">Druck</a>

***

## Configuração

### Ubidots

- Para começar, você deve criar uma conta grátis em [Ubidots.com](https://ubidots.com)
- A seguir vá ao menu  ```API Credentials``` e copie uma ```Token``` para ser utilizada pelo iSpindle. O Token funciona como uma autorização concedida ao iSpindel para postar os dados na conta do Ubidots.
***Anote esta chave em algum lugar.***  
Token  

### Portal

Ao pressionar o botão ```Reset``` da placa Wemos, a mesma criará um ponto de acesso wireless, que permitirá fazer as alterações necessárias para configurar o dispositivo. **No modo `operação` este portal não ficará mais acessível uma vez que o princípio é que o dispositivo fique ativo o menor tempo possível durante o uso. Basicamente o dispositivo acordará, enviará os dados para o portal na nuvem e entrará em modo sleep novamente. Este tempo leva menos de 3 s e possui impacto direto na vida útil da bateria.

> O ```iSpindel``` sinaliza o modo `config` ao piscar o LED a intervalos de 1 s.
Ao salvar as configurações ou após expirar o tempo de 5 minutos o dispositivo encerrará o modo `access point` e iniciará o modo `operation`.

   Setup

   AccessPointPortal

  Info

> No site Ubidots você pode monitorar os dados enviados na aba ```Sources```, local onde o iSpindel criará um dispositivo por conta própria.  
Na aba ```Dashboard``` você poderá criar diversos gráficos customizados.

### Blynk

#### Clonar Exemplo do App

* Para esse exemplo você precisara de 1800 (4x200 + 100 + 900) pontos de energia, que estão inclusos inicialmente no App;
* Download Blynk App: [Android](http://j.mp/blynk_Android) [iOS](http://j.mp/blynk_iOS)
* Clique no icone QR-code e leia o codigo com a camera do celular


  

* Enjoy the app!

#### Using your own App

* Caso você quiser modificar o App ou criar seu próprio layout, a definição dos pinos e a seguinte:
1. V20 - Temperatura sem unidade;
2. V30 - Bateria sem unidade;
3. V1 - String Tilt em graus;
4. V2 - String Temperatura graus `C ou F ou K`;
5. V3 - String Bateria `Volts`;
6. V4 - Gravidade;

***
## Interface Gráfica do Usuário

### Calibração

> Para converter o ângulo medido pelo iSpindle para graus Plato (°Plato), densidade (SG), ou outras unidades, primeiro é necessário calibrar o sensor fazendo várias medições de ângulo a partir de valores de referência de densidade utilizando soluções de água com diferentes concentrações de açúcar. Estes valores de referência serão convertidos a partir de um modelo matemático que será armazenada para futuras medições e visualizações no Ubidots. Tendo em vista que cada dispositivo iSpindle terá diferentes valores medidos (em função dos tamanhos diferentes de tubos, gavetas e etc), cada dispositivo deverá ser calibrado após a montagem para garantir medições precisas. Um procedimento detalhado é mostrado a seguir.

[Procedimento de Calibração](Calibration_pt.md)

### Gráficos Ubidots

- [Fórmula Plato](Calibration_pt.md#formula)

### CraftBeerPi

[CraftBeerPi](https://github.com/universam1/iSpindel/issues/3)
***

## Software 

### Flash do Firmware

[Flash do Firmware](Firmware.md)

***Se gostou, nos escreva para contarw***  :beers:



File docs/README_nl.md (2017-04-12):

## [Samenbouwen](iSpindelbreadboard_nl.pdf)

## [Kalibreren](Calibration_nl.md)

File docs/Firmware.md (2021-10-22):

# Firmware

## Flashen über Web Interface

- download the latest .bin firmware from this repository

    <https://github.com/universam1/iSpindel/releases>

- in `Maintenance` menu select this file and press update

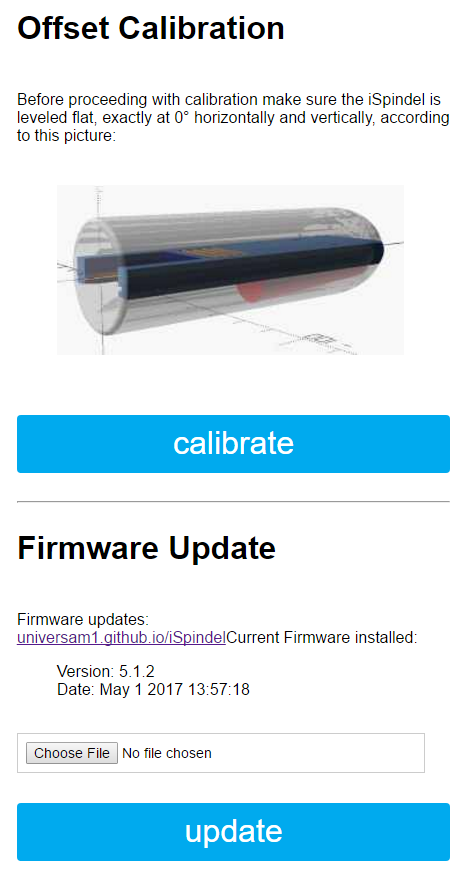
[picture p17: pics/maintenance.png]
flash web
    

## Flashen über USB (Windows)

- Download und Starten von [NodeMCU-Flasher](https://github.com/nodemcu/nodemcu-flasher/raw/master/Win32/Release/ESP8266Flasher.exe)
- neuestes Release aus [/releases Folder](https://github.com/universam1/iSpindel/releases) downloaden

    > Wichtig: `Download` button wählen um die Datei korrekt herunterzuladen

- COM Port den Wemos auswählen
- Tab `Config` als erste Datei die `.bin` auswählen
- Tab `Flashen` klicken, Fortschrittsbalken ist zu sehen
- Nach erfolgreichem Flash `RESET` Taste drücken

    > Evtl. über Serial Monitor (bsp. Arduino IDE) die Statusmeldungen sehen.

    > Der `Config Mode` ist aktiv wenn die LED im 1s Rhythmus blinkt. Man kann ihn beenden über Link im Portal oder über Timeout 5min.

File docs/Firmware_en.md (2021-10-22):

# Firmware

## Flashing via Web Interface

- download the latest .bin firmware from this repository

    <https://github.com/universam1/iSpindel/releases>

- in `Maintenance` menu select this file and press update

    flash web

## Flashing via USB (Windows)

- download and run: [NodeMCU-Flasher](https://github.com/nodemcu/nodemcu-flasher/raw/master/Win32/Release/ESP8266Flasher.exe)
- download the latest firmware Release from the [/releases Folder](https://github.com/universam1/iSpindel/releases/) Folder

    > Important: select the `Download` button to download the file correctly

- Select the COM port for the Wemos
- Use the `Config` tab to select the first `.bin` file
- Clicking the `Flash` button on the `operation` tab shows a progress bar
- After a successful Flash, press the `RESET` key

    > `Config Mode` is active while the LED is blinking at 1s intervals. It can be exited via the Link in the Portal or by waiting for the 5min timeout.

## Flashing via USB (Linux)

- download and unpack the latest version of [esptool](https://github.com/igrr/esptool-ck/releases). Then change directory into the newly unpacked directory, using terminal commands such as:

    ```bash
        wget https://github.com/igrr/esptool-ck/releases/download/0.4.12/esptool-0.4.12-linux64.tar.gz
        tar xf esptool-0.4.12-linux64.tar.gz
        cd esptool-0.4.12-linux64
    ```

- download the latest firmware from the [iSpindel Releases page](https://github.com/universam1/iSpindel/releases) e.g.

    ```bash
        wget https://github.com/universam1/iSpindel/releases/download/7.1.2/firmware.bin
    ```

- determine the iSpindel's device path. This may be found by listing all serial USB devices before and after plugging in the iSpindel e.g. before iSpindel is plugged in:

    ```bash
    ls -l /dev/ttyUSB*
    ls: cannot access '/dev/ttyUSB*': No such file or directory
    ```

    now after iSpindel is plugged in:

    ```bash
    ls -l /dev/ttyUSB*
    crw-rw-rw- 1 root dialout 188, 0 Dec 11 23:20 /dev/ttyUSB0
    ```

    showing that the iSpindel device name is /dev/ttyUSB0

- upload the firmware by running the esptool command with the discovered iSpindel device name (/dev/ttyUSB0 in this case):

    ```bash
    ./esptool -vv -cd nodemcu -cb 921600 -cp /dev/ttyUSB0 -ca 0x00000 -cf ./firmware.bin
    ```

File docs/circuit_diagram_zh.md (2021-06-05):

# 电路图

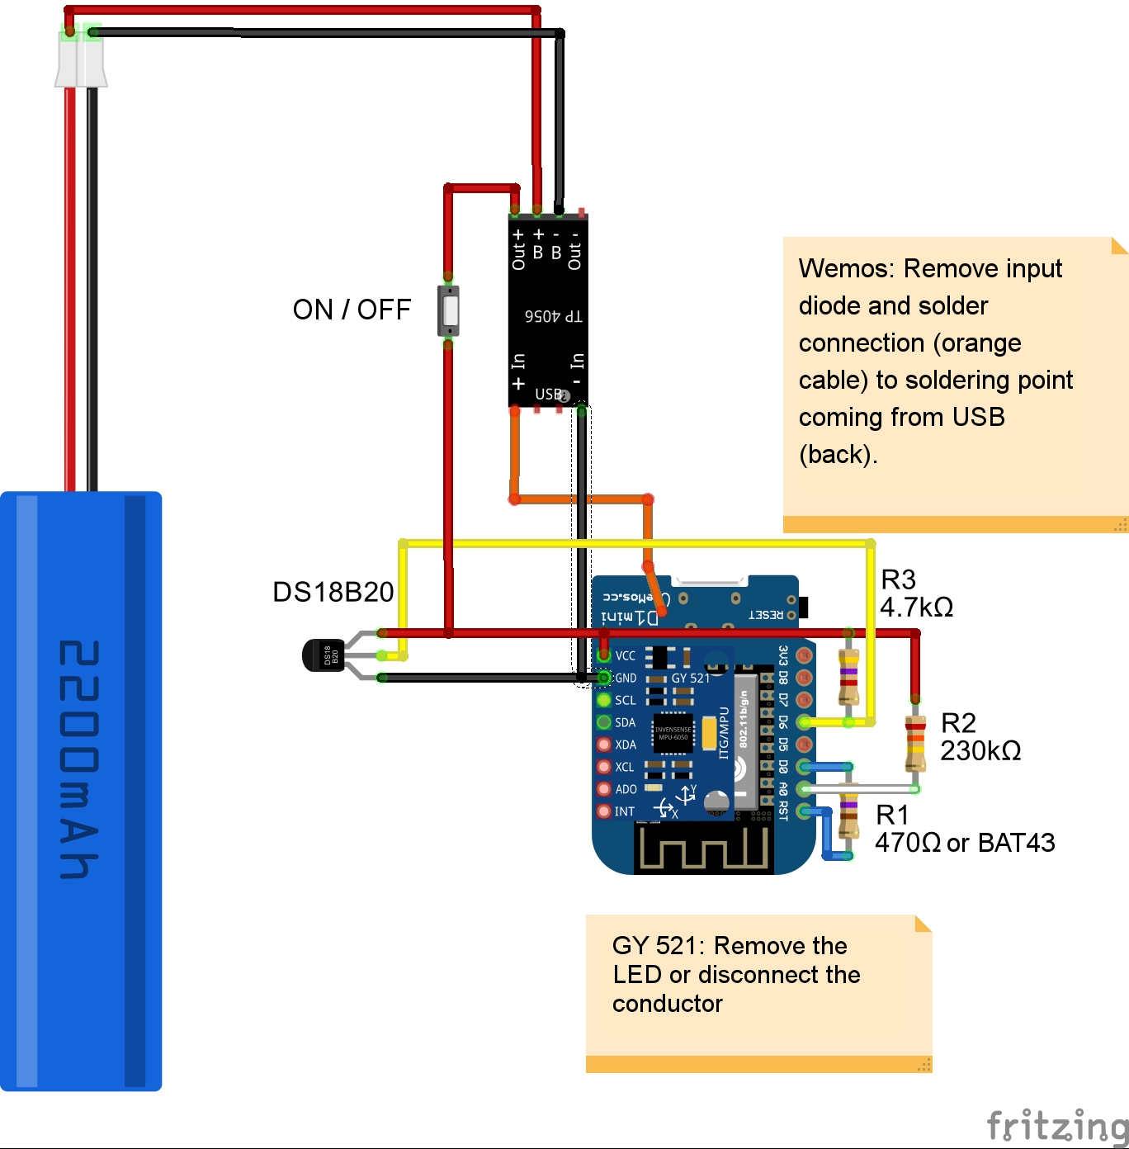
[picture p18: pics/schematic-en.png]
Schematic


## 连接分配

### GY-521

- D4 -> SCL of the GY-521
- D3 -> SDA of the GY-521
- 5V -> VCC
- GND -> GND
- 剩余的端口不被占用
- 拆下 GY LED 的电阻！(不再需要)

### 电阻

- BAT43 或者更好的肖特基二极管 (负极 to D0) 或在 D0 与 RST 之间的 330 欧姆电阻
- 230k ohms of A0 -> 5V
- 4k7 ohms of D6 -> 5V

### DS18B20

- DQ goes to D6
VCC and 5V
- GND -> GND

### Wemos

- 移除输入二极管 (通过 Lipomodul 充电板短路!)
- 切换 / 簧片 在 + 5V 和 Lipomodul `+ OUT` 之间
- GND -> GND

### 锂电池充电模块

- 电池 to `B +` and `B-`
- GND -> GND
- `+ OUT` switch to + 5V Wemos D1 mini
- `+ IN` to USB + 5V of the Wemos D1 mini (选项)

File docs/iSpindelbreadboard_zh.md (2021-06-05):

# 结构变体A：穿孔网格&底座

> 图片的视角始终是 ***左边*** 显示 Wemos cover/USB 端口的方向.

1. 从下面固定住引脚，这样可以降低堆积的高度，从而使所有的东西都能放入瓶中
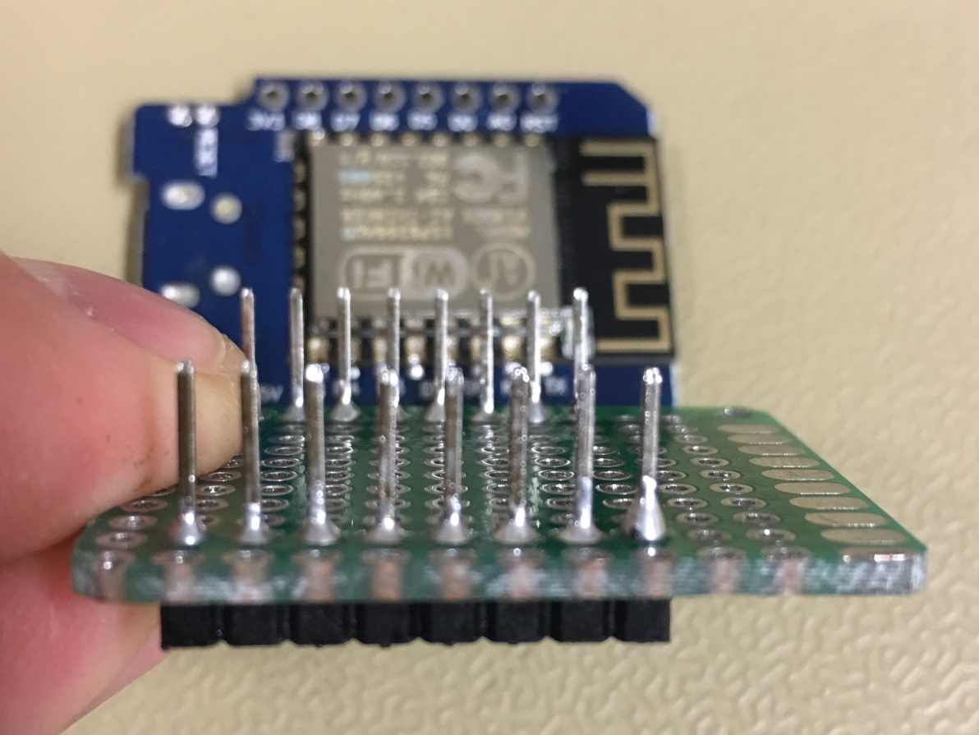
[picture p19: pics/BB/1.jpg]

2. 插入长短排针并焊接 Wemos
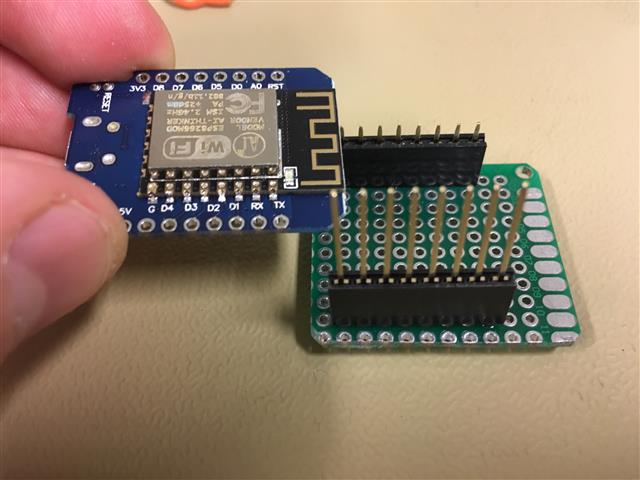
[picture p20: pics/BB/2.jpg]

3. 留下 4 个左边的针脚
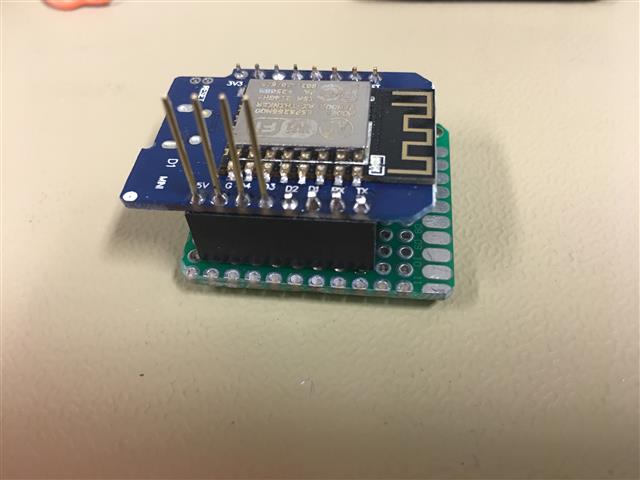
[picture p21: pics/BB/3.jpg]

4. 移除 GY-521 LED，右侧的 4 个引脚不能有任何接触
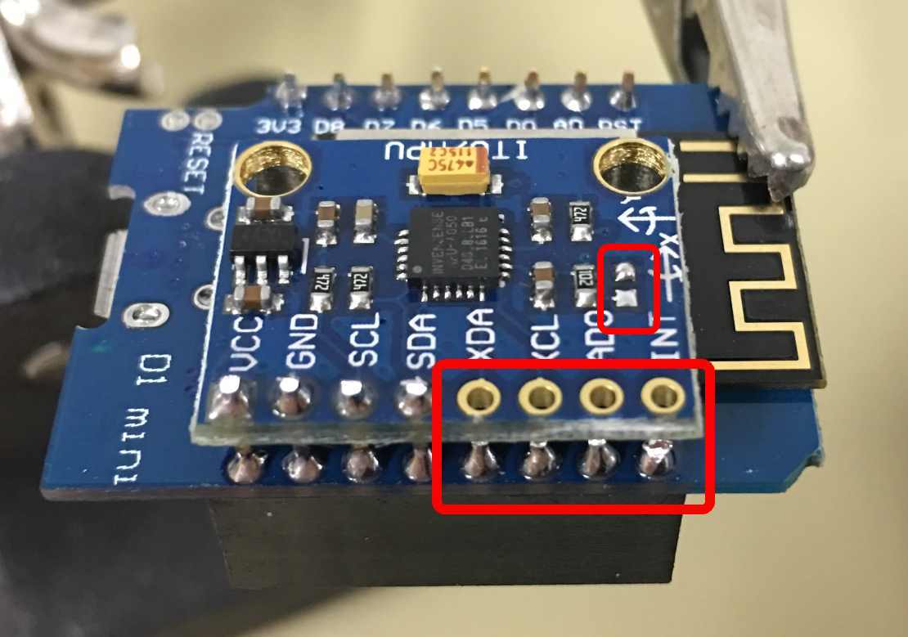
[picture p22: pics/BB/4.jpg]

5. 放置线桥、电阻和开关，焊接顶部使其操作更容易
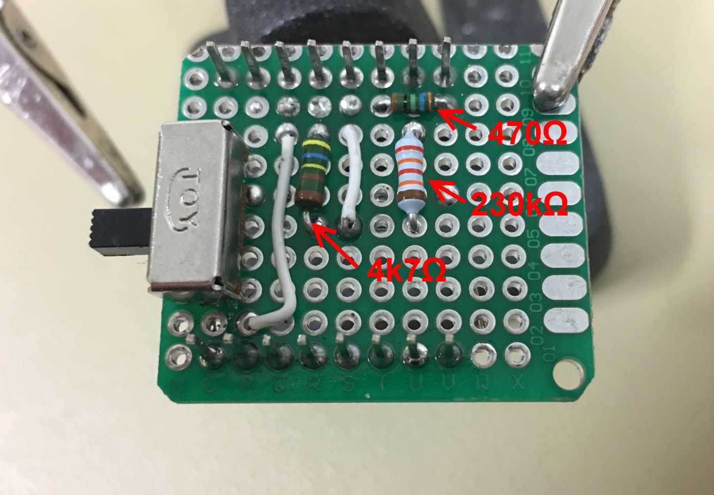
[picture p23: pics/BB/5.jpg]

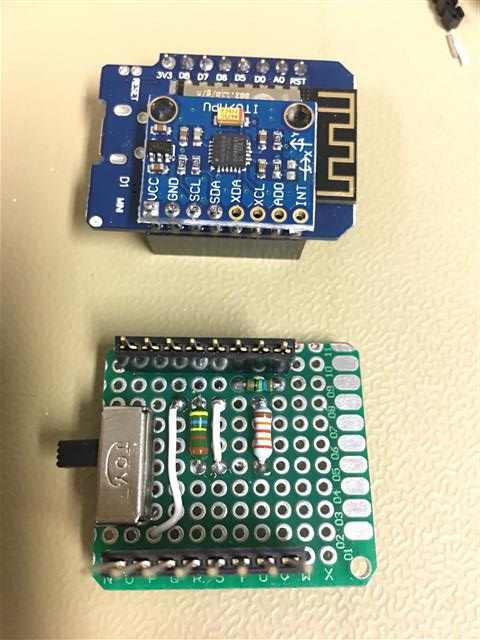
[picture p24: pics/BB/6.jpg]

6. 根据下图连线处于低位
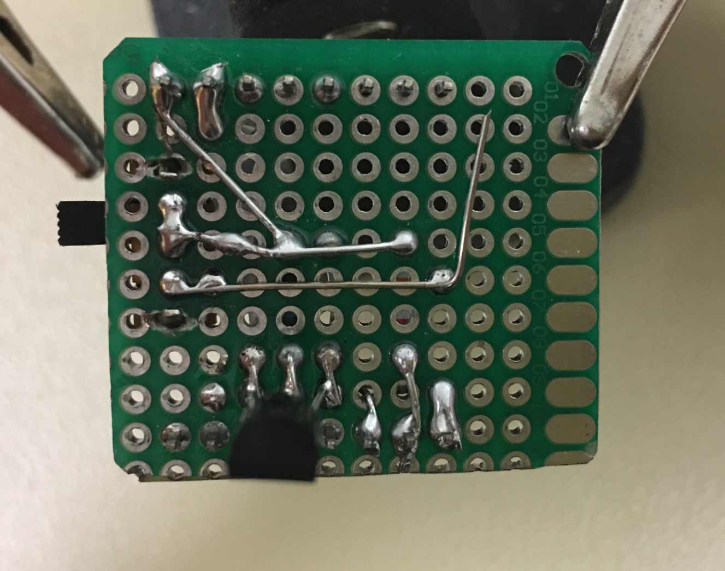
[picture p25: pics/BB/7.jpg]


7. 焊接 DS18B20，只有中间的引脚被 WeMo 引脚上的电阻夹住，不要将另外两个（Vcc、GND）连接到 Wemos 
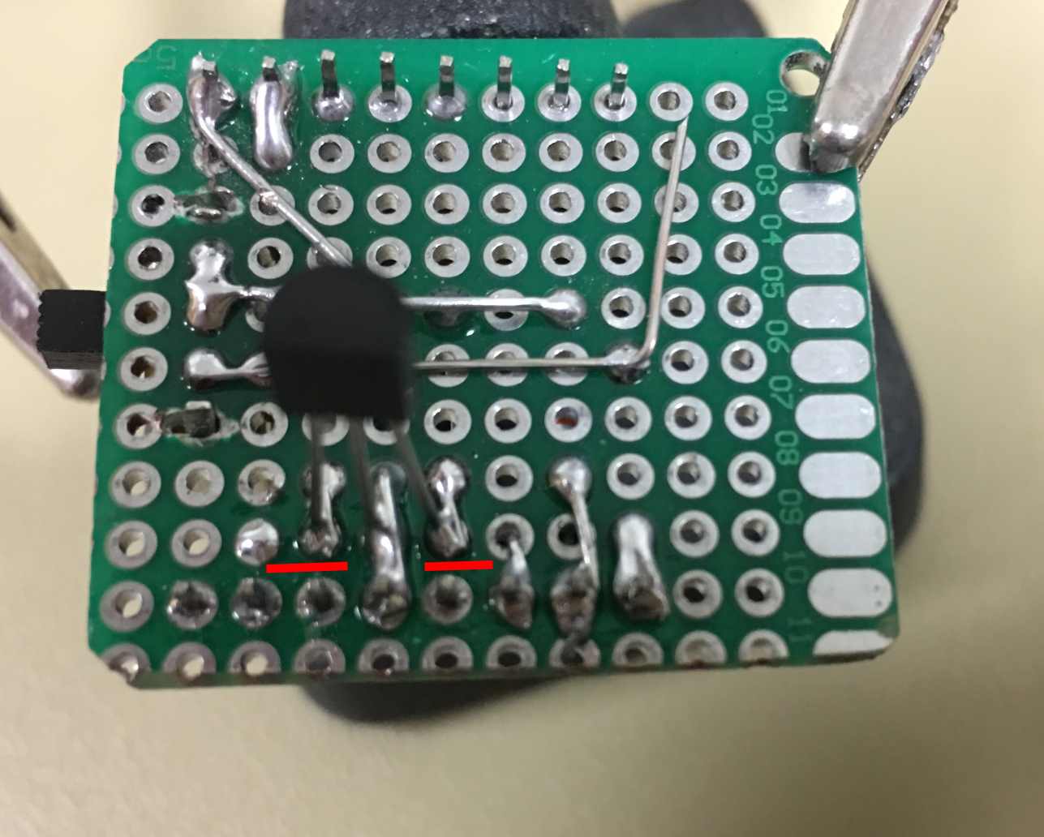
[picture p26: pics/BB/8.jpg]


8. 移除 Wemos 二极管
Install the 4 pins for the lipo charger TP4056. The connections are marked in red.
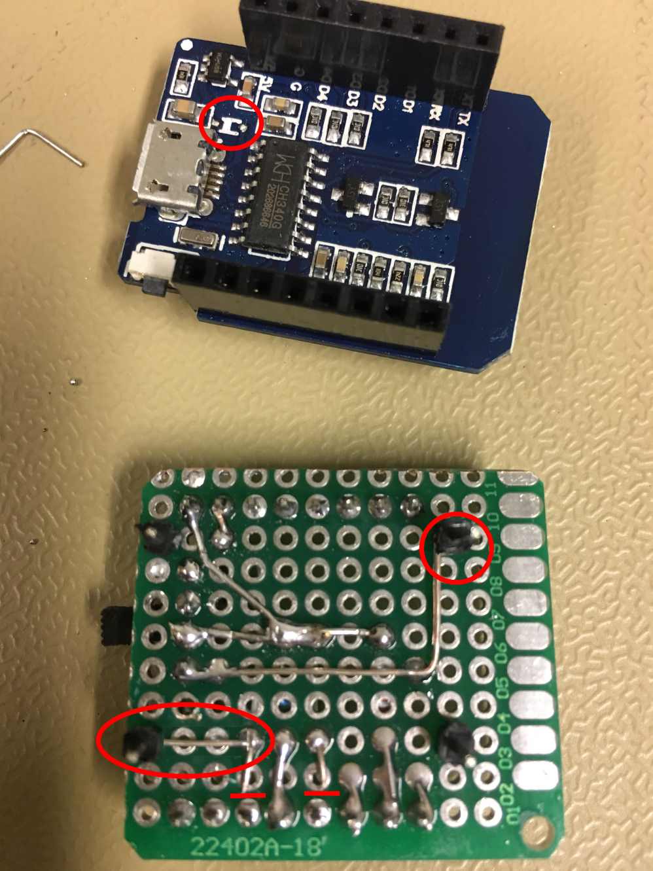
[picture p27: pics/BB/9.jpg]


9. 焊接充电模块，放置固定电池
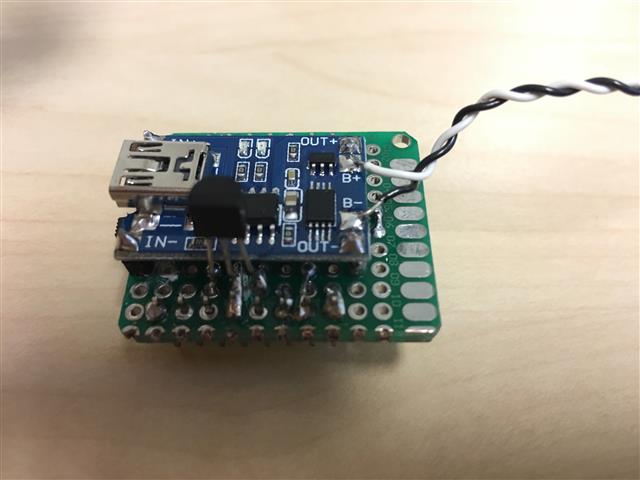
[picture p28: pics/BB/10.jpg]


10. 从俯视视角装配底座


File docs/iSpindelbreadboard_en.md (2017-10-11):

# Construction variant A: perforated grid & sled

> The view of the pictures is always *** left *** shows direction cover/USB port of the Wemos.

1. Pin the pin from below. This reduces the build-up height so everything fits into the petling.

1. Insert the short and long bushing strip and solder the Wemos.

1. Leave the 4 left pins.

1. Remove the GY-521 LED. The right 4 pins must not have any contact.

1. Place wire bridges, resistors and switches. Soldering top makes it easier.


1. Lower the wires according to the following diagram.


1. Solder the DS18B20, only the middle pin is pinched by the resistor on the pin of the Wemo. Do not connect the other two (Vcc, GND) to the Wemos.


1. Remove the Wemos diode.
Install the 4 pins for the lipo charger TP4056. The connections are marked in red.


1. Solder the charging module, the battery is soldered to it.


1. Assembled with the carriage viewed from below.


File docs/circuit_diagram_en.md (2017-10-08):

# Circuit diagram

Schematic

## Connection assignment

### GY-521

- D4 -> SCL of the GY-521
- D3 -> SDA of the GY-521
- 5V -> VCC
- GND -> GND
- remaining ports unoccupied
- Remove the resistor of the GY LED! (Retirement)

### Resistors

- BAT43 or better schottky diode (cathode to D0) or 330 ohms resistor between D0 and RST
- 230k ohms of A0 -> 5V
- 4k7 ohms of D6 -> 5V

### DS18B20

- DQ goes to D6
VCC and 5V
- GND -> GND

### Wemos

- Remove the input diode (short circuit via Lipomodul!)
- Switch / Reed between + 5V and Lipomodul `+ OUT`
- GND -> GND

### Lipo Lademodul

- Battery to `B +` and `B-`
- GND -> GND
- `+ OUT` switch to + 5V Wemos D1 mini
- `+ IN` to USB + 5V of the Wemos D1 mini (optional)

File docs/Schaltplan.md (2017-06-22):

# Schaltplan

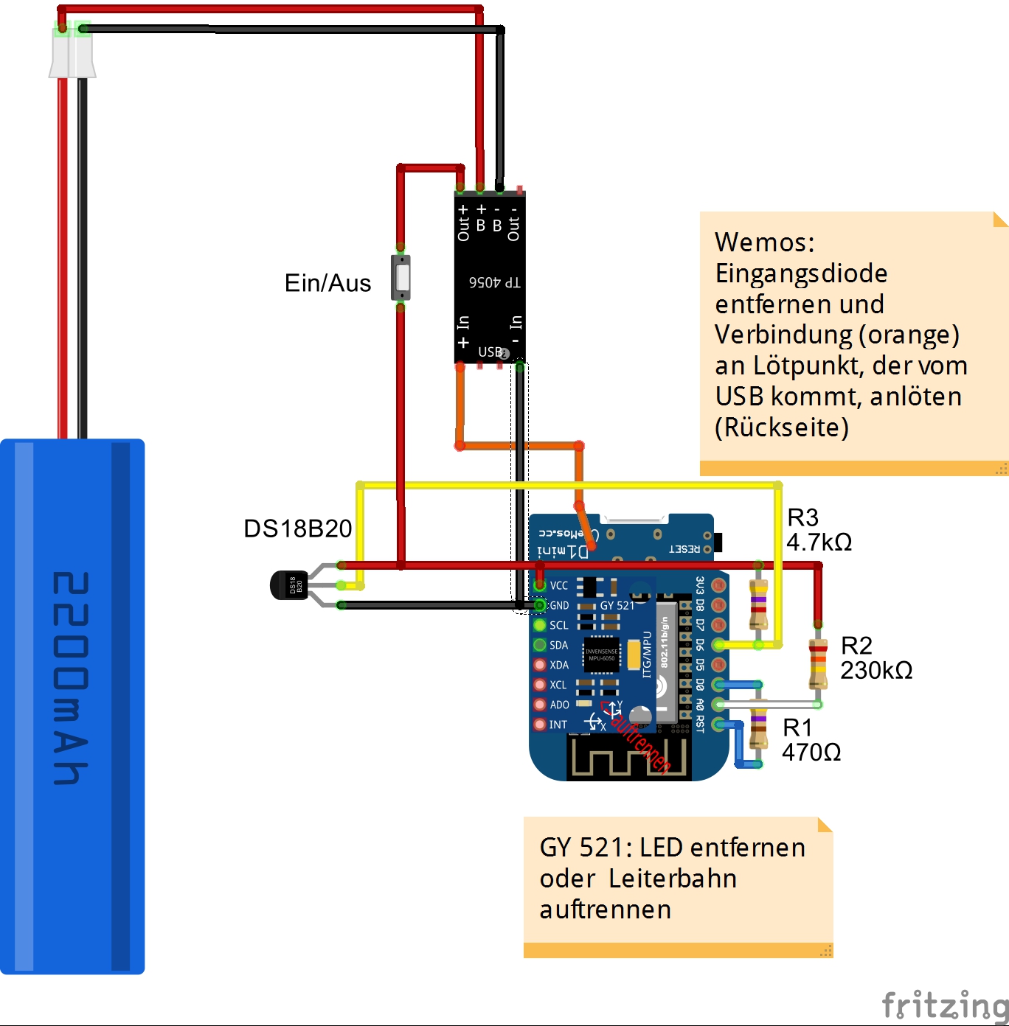
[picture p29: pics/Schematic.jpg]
Schaltplan


## Anschlussbelegung

### GY-521

- D4 --> SCL des GY-521
- D3 --> SDA des GY-521
- 5V --> VCC
- GND --> GND
- restliche ports unbelegt
- Vorwiderstand der GY LED entfernen! (Ruhestrom) 

### Widerstände

- BAT43 Schottky Diode (Kathode zu D0) oder 330 Ohm zwischen D0 und RST
- 230k Ohm von A0 --> 5V
- 4k7 Ohm von D6 --> 5V

### DS18B20

- DQ geht an D6
- VCC and 5V
- GND --> GND

### Wemos

- Eingangs - Diode entfernen (Kurzschluss über Lipomodul!)
- Schalter / Reed zwischen +5V und Lipomodul `+OUT`
- GND --> GND

### Lipo Lademodul

- Akku an `B+` und `B-`
- GND --> GND
- `+OUT` Schalter zu +5V Wemos
- `+IN` an USB +5V des Wemos (optional)

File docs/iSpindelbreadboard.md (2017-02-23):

# Aufbau Variante A: Lochrasterplatine & Schlitten

> Die Ansicht der Bilder ist immer ***links*** zeigt Richtung Deckel / USB Anschluss des Wemos.

1. Pin Stiftleiste von unten durchstecken. Dadurch reduzieren wir die Aufbauhöhe damit alles in den Petling passt.  
  
1. Kurze und lange Buchsenleiste aufstecken und Wemos verlöten.  
  
1. Die linken 4 Pins stehen lassen.  
  
1. Die LED des GY-521 entfernen. Die rechten 4 Pins dürfen keinen Kontakt haben.
  
1. Drahtbrücken, Widerstände und Schalter setzen. Oberseite anlöten macht es einfacher. 
  
  
1. Unterseite die Drähte nach folgendem Schema verdrahten. 
  

1. Den DS18b20 anlöten, nur der mittlere Pin wird durchgebrückt von dem Widerstand auf den Pin des Wemos. Die anderen beiden (Vcc, GND) nicht an den Wemos verbinden.
  

1. Die Diode des Wemos entfernen.  
Die 4 Pins für den Lipo Laderegler TP4056 anbringen. Rot markiert sind die Verbindungen die hergestellt werden.
  

1. Das Lademodul auflöten, der Akku wird daran angelötet.  
  

1. Der Zusammenbaut mit dem Schlitten von unten betrachtet.  


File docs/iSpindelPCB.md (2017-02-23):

# Aufbau Platine mit / ohne Schlitten

## Variante B: nur Platine

### Bilder
01-Schalterbruecke 
02-durchtrennt 
03-Schaltervarianten 
04-SMDReed-Oeffner 
05-Schiebeschalter 
06-Jumper 
07-Jumper 
08-Jumper 
09-Jumper 
10-Widerstaende 
11-SMD-Widerstaende 
12-LED-beim-GY521-entfernt 
13-GYVerschraubung 
14-GYPinleiste 
15-WemosVorbereitung 
16-Wemos-USB-Litze 
17-Jumper 
18-Loetbild-nurnoetigePinsloeten 
19-Akkuposition 
20-Akkuposition 
21-Laderegler 
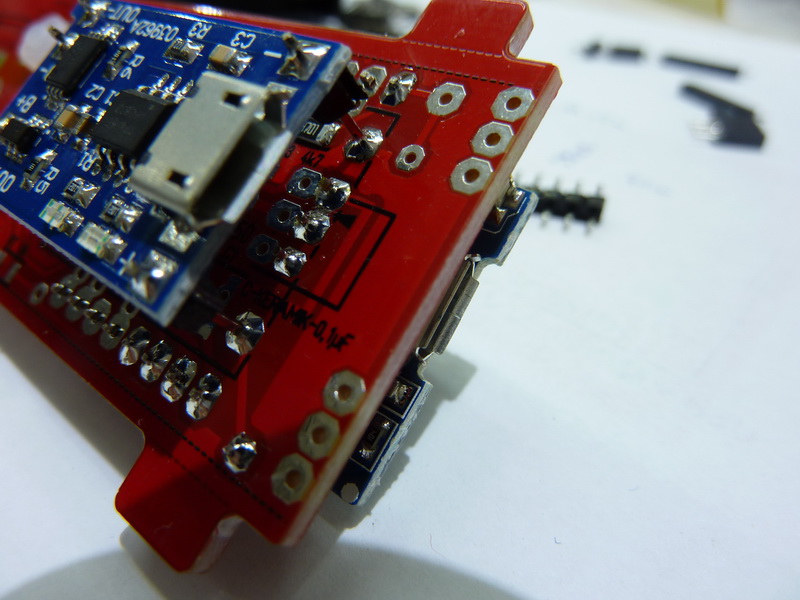
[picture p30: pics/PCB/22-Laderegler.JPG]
22-Laderegler 
23-Zentrierschraube 
24-Zentrierschraube 
25-Pinkuerzung 
26-Pinkuerzung 
27-Kunststoff-BearbeitungamMinuspoldesAkkuhalters_A_Bildgroesseaendern 
28-Kunststoff-BearbeitungamMinuspoldesAkkuhalters_B_Bildgroesseaendern 
29-Kunststoff-BearbeitungamMinuspoldesAkkuhalters_C_Bildgroesseaendern 
30-Akkuhalterposition 
31-Halterverschraubung 
32-Pluspol 
33-VarianteSMD-Reed 
42-MagnetA25mm 
43-MasgnetAmittigPlatine 
44-MagnetB16x11x35 
45-MagnetBmittigReed 
46-MagnetC30x7 

## Variante C: Platine & Schlitten

Um die Platine mit dem Schlitten zu verwenden, folgende Dinge berücksichtigen:
- Die Platine hat eine vorgesehene Schnittkante, in Höhe des Lochs der Schraube, an dieser abtrennen.
- Der DS18B20 wird folglich neben dem GY-521 angelötet
- Der Akku wird an BAT+ und BAT- des TP4056 angelötet

Die Platine in den Falz einschieben, so dass der Wemos sich auf der Akku abgewandten Seite befindet (im schwimmenden Zustand oben).

### Variante C - Step by Step   

#### 1. Platine an der Trennline durchtrennen und die "Ohren" entfernen    
I M G 9255

#### 2. GY-521 LED auslöten und 4 Pins einer Stiftleiste am GY-521 anlöten (VCC, GND, SCL, SDA).    
Die Stifte zeigen dabei nach unten (zur Seite ohne Bauelemente).    
I M G 9256
I M G 9256

#### 3. Abstandhalter der Stiftleiste entfernen   
I M G 9259
I M G 9260

#### 4. Heißklebepistole vorbereiten und den GY-521 so nah wie möglich auf die Platine kleben. Je dichter der GY auf der Platine sitzt, desto besser. Sollte die Klebeschicht zu dick sein, dann müssen später ggf. Stege aus dem Schlitten entfernt werden (s.unten).    
I M G 9262
I M G 9263
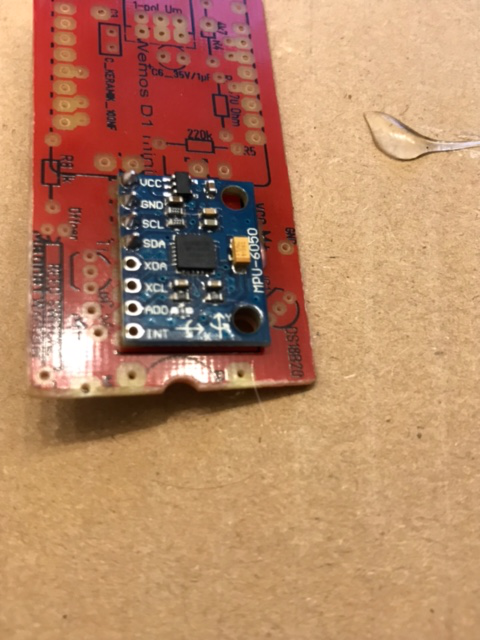
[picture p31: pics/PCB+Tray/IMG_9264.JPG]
I M G 9264


#### 5. Pins des GY-521 verlöten und einkürzen    
I M G 9265

#### 6. Wemos Stiftleisten in die Platine löten und Wemos Sockelleisten auf den Wemos löten    
I M G 9266

#### 7. Wemos Eingangsdiode auslöten   
I M G 9266

#### 8. Stifte für das Lademodul "kupferseitig" auf die Platine löten   
Das Einlöten geht recht leicht, wenn man die Stifte am Kunststoff festhält, "falsch herum" einlötet und den Kunststoffabstandhalter nach dem Einlöten zur Platine drückt.
Wichtig: Die Stifte sollen auf der anderen Seite der Platine nicht herausstehen!
I M G 9272

#### 9. Pins des Schalters ggf. passend zum Rastermaß der Platine leicht zurechtbiegen   
I M G 9273

#### 10. Den, mit dem Pfeil gekennzeichneten, Steg (zwischen den Schalterkontakten der Platine) durchtrennen.
I M G 9279

#### 11. Schalter einsetzen und einlöten     
I M G 9282 
I M G 9281

#### 12. Widerstände einsetzen und einlöten
I M G 9283
I M G 9284

#### 13. Temperatursensor (DS18B20) "kupferseitig" einsetzen und einlöten    
ACHTUNG! Polarität beachten!  Die flache Seite des DS18B20 zeigt beim kupferseitigen Auflöten zur Außenkante der Platine!
I M G 9288

#### 14. Akku Lademodul aufsetzen, verlöten und die Stifte einkürzen   
Lademodul ggf. mit etwas Heißkleber "stabilisieren".
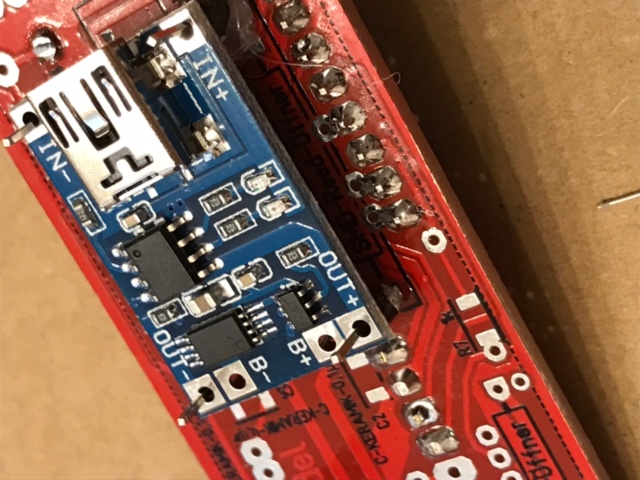
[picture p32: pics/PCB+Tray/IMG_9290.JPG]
I M G 9290

I M G 9291

#### 15. fertige Ansicht der Platine    
I M G 9292
I M G 9293

#### 16. Platine in den Schlitten schieben   
Falls die Klebeschicht zwischen Platine und GY-521 zu dick war, dann müssen ggf. ein paar Stege aus dem Schlitten entfernt werden   
I M G 9294
I M G 9296

#### 17. Kabel an den Akku löten und Akku auf dem Schlitten fixiern  
SEHR VORSICHTIG! Akku beim Löten nicht überhitzen! Brand- und Explosionsgefahr!
I M G 9297
I M G 9298

#### 18. Kabel des Akkus am Lademodul anlöten und lose Kabel mit Heißkleber fixieren
I M G 9299

#### 19. Spindel trimmen    

Vorschlag für etwa 25° Neigung in Leitungswasser
I M G 9300     

Vorschlag für etwa 15° Neigung in Leitungswasser    
I M G 9301

#### 20. Fertiger Schlitten mit Platine
I M G 9303

#### 21. fertige iSpindel
I M G 9304

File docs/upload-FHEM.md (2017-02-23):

# Datenupload nach FHEM

iSpindel kann die Daten an einen lokalen [FHEM](http://fhem.de/fhem.html) Server übertragen, von wo aus sie visualisiert und weiter verarbeitet werden können ( zum Beispiel zum Steuern der Gärtemperatur).
FHEM erwartet Daten per Http Get request:

    http://server:8083/fhem?cmd.Test=set%20iSpindel%2011.5%2022.3%203.3&XHR=1

Zielhost und Port (server:8083) sowie den Namen der Spindel (hier "iSpindel") müssen im KonfigurationsUI der Spindel gesetzt werden. Alle zu Übertragenden Daten werden in der Url mit einem Get übertragen.  Die Reihenfolge ist Neigung - Temperatur - Batterie. Leerzeichen müssen durch %20 ersetzt werden.

In FHEM  (d.h. fhem.cfg) muss ein Device mit dem Namen der Spindel angelegt werden (hier: "iSpindel") sowie noch ein bisschen Perl-Logik, um den Datensatz in die Einzelwerte aufzutrennen. Die resultierenden Werte werden dem Device iSpindelData zugewiesen und können von dort weiterverarbeitet werden.

 ```
    define iSpindel dummy
    define iSpindelData dummy
    
    define iSpindel_Notify notify iSpindel {  \
     my @x= split(/\s/,ReadingsVal("iSpindel","state",0));; \
     my $Neigung=$x[0];; \
     my $Temp=$x[1];; \
     my $Battery=$x[2];; \
     my $Plato=CalcPlato($Neigung, $Temp);; \
     fhem "setreading  iSpindelData Neigung $Neigung";;\
     fhem "setreading  iSpindelData Temp $Temp";;\
     fhem "setreading  iSpindelData Battery $Battery";;\
     fhem "setreading  iSpindelData Plato $Plato";;\
    }
    
    define iSpindel_Values readingsGroup iSpindelData:Temp iSpindelData:Neigung iSpindelData:Battery iSpindelData:Plato
    attr iSpindel_Values room Bier
    
    define FileLog_iSpindel FileLog ./log/iSpindel-%Y.log iSpindelData.*
    attr FileLog_iSpindel logtype text
    
    define weblink_iSpindel SVG FileLog_iSpindel:SVG_FileLog_iSpindel_1:CURRENT
    attr weblink_iSpindel room Bier
```

Die Funktion CalcPlato(Neigung, Temperatur) kann man am besten in 99_MyUtils.pm ablegen:

```
    sub CorrectPlato($$)  #(P, T)
    {
      my $mPlato=shift;
      my $Temp=shift;
      my @k=(56.084,   -0.17885,   -0.13063);
      if ($mPlato>=5) { @k=(69.685,    -1.367,      -0.10621);};
      if ($mPlato>=10){  @k=(77.782,    -1.7288,    -0.10822);};
      if ($mPlato>=15){  @k=(87.895,    -2.3601,    -0.10285);};
      if ($mPlato>=20){  @k=(97.052,    -2.7729,    -0.10596);};
    
      my $cPlato=$k[0]+$k[1]*$Temp+$k[2]*$Temp*$Temp;
      return $mPlato-$cPlato/100;
    }
    
    sub CalcPlato($$)   #(Angle, T)
    {
      my $tilt=shift;
      my $Temp=shift;
      # Get this from Excel Calibration at 20 Degrees 
      my $mPlato=0.00438551*($tilt)*($tilt) + 0.13647658*($tilt) - 6.968821422;
      return CorrectPlato($mPlato,$Temp);
    }
```

Dir Formel für  $mPlato muss dem Kalibrierungsexcelsheet entnommen werden. Zusätzlich wird in CorrectPlato() noch eine Temperaturkorrektur des Platowertes durchgeführt  (Erfordert Kalibrierung bei 20 Grad). Die Temperaturkorrektur ist gültig für den Bereich von 5 bis 30 Grad Celsius.

Zuguterletzt muss nur noch das Diagramm für die Spindelwerte definiert werden; das geht mit dem FHEM -GPlot Editor kinderleicht und könnte in etwa so aussehen:
Definition iSpindel Diagramm

Damit FHEM die Diagramme mit gleitendem Zeitbereich darstellt (anstatt alle 24 Std umzuschalten) muss noch folgendes in die fhem.cfg rein:

    attr WEB endPlotNow 1

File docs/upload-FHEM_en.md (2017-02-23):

# Data upload to FHEM

ISpindel can transfer the data to a local [FHEM](http://fhem.de/fhem.html) server from where it can be visualized and further processed (for example, to control the fermentation temperature).
FHEM expects data by Http Get request:

    http://server:8083/fhem?cmd.Test=set%20iSpindel%2011.5%2022.3%203.3&XHR=1

The target host and port (server: 8083) as well as the name of the spindle (here "iSpindel") must be set in the configurationUI of the spindle. All data to be transferred are transferred in the Url with a Get. The order is tilt - temperature battery. Spaces must be replaced with% 20.

In FHEM (ie fhem.cfg), a device with the name of the spindle (here: "iSpindel") and a bit of Perl logic must be created in order to split the data record into the individual values. The resulting values are assigned to the device iSpindelData and can be further processed from there.

 ```
    define iSpindel dummy
    define iSpindelData dummy
    
    define iSpindel_Notify notify iSpindel {  \
     my @x= split(/\s/,ReadingsVal("iSpindel","state",0));; \
     my $Neigung=$x[0];; \
     my $Temp=$x[1];; \
     my $Battery=$x[2];; \
     my $Plato=CalcPlato($Neigung, $Temp);; \
     fhem "setreading  iSpindelData Neigung $Neigung";;\
     fhem "setreading  iSpindelData Temp $Temp";;\
     fhem "setreading  iSpindelData Battery $Battery";;\
     fhem "setreading  iSpindelData Plato $Plato";;\
    }
    
    define iSpindel_Values readingsGroup iSpindelData:Temp iSpindelData:Neigung iSpindelData:Battery iSpindelData:Plato
    attr iSpindel_Values room Bier
    
    define FileLog_iSpindel FileLog ./log/iSpindel-%Y.log iSpindelData.*
    attr FileLog_iSpindel logtype text
    
    define weblink_iSpindel SVG FileLog_iSpindel:SVG_FileLog_iSpindel_1:CURRENT
    attr weblink_iSpindel room Bier
```

The function CalcPlato (slope, temperature) can be stored in 99_MyUtils.pm:

```
    sub CorrectPlato($$)  #(P, T)
    {
      my $mPlato=shift;
      my $Temp=shift;
      my @k=(56.084,   -0.17885,   -0.13063);
      if ($mPlato>=5) { @k=(69.685,    -1.367,      -0.10621);};
      if ($mPlato>=10){  @k=(77.782,    -1.7288,    -0.10822);};
      if ($mPlato>=15){  @k=(87.895,    -2.3601,    -0.10285);};
      if ($mPlato>=20){  @k=(97.052,    -2.7729,    -0.10596);};
    
      my $cPlato=$k[0]+$k[1]*$Temp+$k[2]*$Temp*$Temp;
      return $mPlato-$cPlato/100;
    }
    
    sub CalcPlato($$)   #(Angle, T)
    {
      my $tilt=shift;
      my $Temp=shift;
      # Get this from Excel Calibration at 20 Degrees 
      my $mPlato=0.00438551*($tilt)*($tilt) + 0.13647658*($tilt) - 6.968821422;
      return CorrectPlato($mPlato,$Temp);
    }
```

The formula for $mPlato must be taken from the calibration sample sheet. CorrectPlato () is also used to perform a temperature correction of the Platower (requires calibration at 20 degrees). The temperature correction is valid for the range of 5 to 30 degrees Celsius.

Lastly, only the diagram for the spindle values has to be defined; This is very easy with the FHEM -GPlot editor and could look something like this:
Definition iSpindel Diagram

Definition iSpindel Diagram

    attr WEB endPlotNow 1

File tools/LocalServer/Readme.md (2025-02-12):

# Local Server

This server collects and plot data for iSpindel on LAN.

Since this simple server uses HTTP, do NOT expose it to the public network!

It can be run simply with `Golang` build environment installed via `go run .` 

An optional `-p` flag can be used to specify the port to run on (Default is `8080`).

E.g. `go run . -p 9000`

Configure the iSpindel with the following settings:

* Method: HTTP
* Host: your local server IP
* Port: port you are running on (default 8080)
* Path: /data

You can run this in a tmux, or as a service.

Data collected are saved as `.csv` under `.../LocalServer/data/<ispindel_name>.csv`.
Therefore changing the device name would start a new save file.

Author: kaihuang201

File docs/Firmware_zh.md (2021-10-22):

# 固件

## 通过 网页接口 刷入

- 从项目仓库里下载最新的 .bin 固件

    <https://github.com/universam1/iSpindel/releases>

- 在 `Maintenance` 一项里选择固件文件并按更新

    flash web

## 通过 USB 刷入 (Windows)

- 下载并运行：[NodeMCU-Flasher](https://github.com/nodemcu/nodemcu-flasher/raw/master/Win32 从 [/releases 路径文件夹](https://github.com/universam1/iSpindel/releases)

    > 重要提示：选择 “下载” 按钮以正确下载文件

- 选择 Wemos 的 COM 端口
- 使用 `Config` 选项 悬着第一个 `.bin` 固件
- 点击 `Flash` 选项显示进度条
- 刷入固件后, 点击 `RESET` 重置键

    > 当 LED 灯以 1 秒的间隔闪烁时，`配置模式` 会处于激活状态，可以通过退出设置模式或等待五分钟超时来退出该模式。

## 通过 USB 刷入 (Linux)

- 下载并解压最新版本的 [esptool](https://github.com/igrr/esptool-ck/releases)，然后使用终端命令将目录更改为新解压的目录，示例：

    ```bash
        wget https://github.com/igrr/esptool-ck/releases/download/0.4.12/esptool-0.4.12-linux64.tar.gz
        tar xf esptool-0.4.12-linux64.tar.gz
        cd esptool-0.4.12-linux64
    ```

- 从 [iSpindel Releases page](https://github.com/universam1/iSpindel/releases) 下载最新的固件，例如：

    ```bash
        wget https://github.com/universam1/iSpindel/releases/download/7.1.2/firmware.bin
    ```

- 确定设备 iSpindel 的路径，这可以通过列出插入 iSpindel 前后的所有串行 USB 设备找到，比如可能在 iSpindel 插入之前。

    ```bash
    ls -l /dev/ttyUSB*
    ls: cannot access '/dev/ttyUSB*': No such file or directory
    ```

    在 iSpindel 插入之后：

    ```bash
    ls -l /dev/ttyUSB*
    crw-rw-rw- 1 root dialout 188, 0 Dec 11 23:20 /dev/ttyUSB0
    ```

    上面显示 iSpindel 设备名称是 /dev/ttyUSB0

- 用找到的 iSpindel 设备名称 (在这个例子是 /dev/ttyUSB0) 通过运行 esptool 指令来上传固件：

    ```bash
    ./esptool -vv -cd nodemcu -cb 921600 -cp /dev/ttyUSB0 -ca 0x00000 -cf ./firmware.bin
    ```

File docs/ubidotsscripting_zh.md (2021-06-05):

# Ubidots 脚本

## Curl
Curl 是一个开源命令行工具。例如， HTML 消息可以发送到 Ubidots.- https://curl.haxx.se/

## Ubidots API
许多 Ubidots 的功能可以通过 HTML-messages 进行脚本控制。
例如，当一个变量不再需要时，可以完全删除它的数据。
- https://ubidots.com/docs/api/#rest-api-reference

## Curl 脚本 用于数据擦除
- 下载 [压缩包](https://github.com/universam1/iSpindel/raw/master/tools/delete_all_values_ispindel.zip) 
- 随即解压文件
- 使用文本编辑器编辑里面的 "delete_all_values_ispindel.bat" ，然后替换成

  `<ID of your variable for Ubidots>`
  
  清空 ID of the variable, 使用你 Ubidots 上的进行代替
  
  `<Token of your account at Ubidots>`
  
  你的密钥。
- 当然你可以随意多次复制该行，如果你想同时清空几个变量的话。
- 启动 "delete_all_values_ispindel.bat" 然后 variable (s) 应该会被清空

## Curl 脚本显示最后一次测量值
- 下载 [压缩包](https://github.com/universam1/iSpindel/raw/master/tools/get_five_values_ispindel.zip) 
- 随即解压文件
- 使用你文本编辑器编辑里面的 "get_five_values_ispindel.bat" ，然后替换成

  `<ID of your variable for Ubidots>`
  
  这个 ID of the variable，你能在 Ubidots 上找到并代替
  
  `<Token of your account at Ubidots>`
  
  你的密钥。
- 当然你可以随意多次复制该行，如果你想同时清空几个变量的话。
- 启动 "get_five_values_ispindel.bat" 读取最后五个 variable (s) 数值。

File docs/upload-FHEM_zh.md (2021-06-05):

# 数据上传到 FHEM

 iSpindel 可以将数据传输到本地的 [FHEM](http://fhem.de/fhem.html) 服务器上，在那里可以对数据进行可视化和进一步处理 (例如，控制发酵温度)。
FHEM 通过 Http Get 请求获取数据:

    http://server:8083/fhem?cmd.Test=set%20iSpindel%2011.5%2022.3%203.3&XHR=1

目标地址和端口 (服务器: 8083) 以及设备的名称 (这里是 "iSpindel") 必须在 spindel 的 configurationUI 里设置好。所以要传输的数据都通过 Get 在 URL 中进行传输。顺序是 倾斜角度 - 温度 电量。空格必须用 % 20 替代。

在 FHEM (ie fhem.cfg)，设备必须创建一个名称 (这里是："iSpindel")以及一些 Perl logic 运算符，以便将数据记录拆分为各个值。产生的数据结果被分配给设备 iSpindelData 并且从那里进一步处理。

 ```
    define iSpindel dummy
    define iSpindelData dummy
    
    define iSpindel_Notify notify iSpindel {  \
     my @x= split(/\s/,ReadingsVal("iSpindel","state",0));; \
     my $Neigung=$x[0];; \
     my $Temp=$x[1];; \
     my $Battery=$x[2];; \
     my $Plato=CalcPlato($Neigung, $Temp);; \
     fhem "setreading  iSpindelData Neigung $Neigung";;\
     fhem "setreading  iSpindelData Temp $Temp";;\
     fhem "setreading  iSpindelData Battery $Battery";;\
     fhem "setreading  iSpindelData Plato $Plato";;\
    }
    
    define iSpindel_Values readingsGroup iSpindelData:Temp iSpindelData:Neigung iSpindelData:Battery iSpindelData:Plato
    attr iSpindel_Values room Bier
    
    define FileLog_iSpindel FileLog ./log/iSpindel-%Y.log iSpindelData.*
    attr FileLog_iSpindel logtype text
    
    define weblink_iSpindel SVG FileLog_iSpindel:SVG_FileLog_iSpindel_1:CURRENT
    attr weblink_iSpindel room Bier
```

函数 CalcPlato (曲线斜率，温度) 可以存储在 99_MyUtils.pm:

```
    sub CorrectPlato($$)  #(P, T)
    {
      my $mPlato=shift;
      my $Temp=shift;
      my @k=(56.084,   -0.17885,   -0.13063);
      if ($mPlato>=5) { @k=(69.685,    -1.367,      -0.10621);};
      if ($mPlato>=10){  @k=(77.782,    -1.7288,    -0.10822);};
      if ($mPlato>=15){  @k=(87.895,    -2.3601,    -0.10285);};
      if ($mPlato>=20){  @k=(97.052,    -2.7729,    -0.10596);};
    
      my $cPlato=$k[0]+$k[1]*$Temp+$k[2]*$Temp*$Temp;
      return $mPlato-$cPlato/100;
    }
    
    sub CalcPlato($$)   #(Angle, T)
    {
      my $tilt=shift;
      my $Temp=shift;
      # Get this from Excel Calibration at 20 Degrees 
      my $mPlato=0.00438551*($tilt)*($tilt) + 0.13647658*($tilt) - 6.968821422;
      return CorrectPlato($mPlato,$Temp);
    }
```

 $mPlato 的公式必须取自校准样本表，CorrectPlato () 还用于对 Platower 进行温度校正 (需要在 20 度下进行校准)。温度校正在 5 到 30 摄氏度的范围内有效。

最后，只剩下图表中的设备测量数值还需定义，使用 FHEM -GPlot 编辑器很容易做到这一点，看起来像这样：
Definition iSpindel Diagram

定义 iSpindel 图表

    attr WEB endPlotNow 1

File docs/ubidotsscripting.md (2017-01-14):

# Scripting für Ubidots

## Curl
Curl ist ein open source command line tool. Hiermit können HTML-Nachrichten z.B. nach Ubidots gesendet werden.
- https://curl.haxx.se/

## Ubidots API
Viele Funktionen von Ubidots lassen sich über Script mittels HTML-Nachrichten steuern.
So lassen sich z.B. die Daten einer Variable komplett löchen, wenn sie nicht mehr benötigt werden.
- https://ubidots.com/docs/api/#rest-api-reference

## Curl Script zur Datenlöschung
- Download [ZIP-Datei](https://github.com/universam1/iSpindel/raw/master/tools/delete_all_values_ispindel.zip) 
- Enthaltener Ordner an beliebiger Stelle entpacken 
- Die enthaltene "delete_all_values_ispindel.bat" mit dem Editor bearbeiten, dort dann statt

  `<ID eurer Variable bei Ubidots>`
  
  die ID der Variable, welche ihr bei Ubidots leeren wollt eintragen und statt
  
  `<Token eures Accounts bei Ubidots>`
  
  euer Token.
- Die Zeile könnt ihr natürlich so oft kopieren, wie ihr wollt, wenn ihr mehrer Variablen gleichzeitig leeren wollt.
- Die "delete_all_values_ispindel.bat" starten und die Variable(n) sollten leer sein.

## Curl Script zur Anzeige der letzten Messwerte
- Download [ZIP-Datei](https://github.com/universam1/iSpindel/raw/master/tools/get_five_values_ispindel.zip) 
- Enthaltener Ordner an beliebiger Stelle entpacken 
- Die enthaltene "get_five_values_ispindel.bat" mit dem Editor bearbeiten, dort dann statt

  `<ID eurer Variable bei Ubidots>`
  
  die ID der Variable, welche ihr bei Ubidots auslesen wollt eintragen und statt
  
  `<Token eures Accounts bei Ubidots>`
  
  euer Token.
- Die Zeile könnt ihr natürlich so oft kopieren, wie ihr wollt, wenn ihr mehrer Variablen gleichzeitig auslesen wollt.
- Die "get_five_values_ispindel.bat" starten und die letzten 5 Werte der Variable(n) sollten ausgelesen werden.

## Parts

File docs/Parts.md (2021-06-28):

# Bauteile

Folgende Bauteile werden benötigt:

## Kunstoff Zylinder

- Kunststoff Zylinder `Petling`. Diese `PET-Preform` sind z.B. in eBay erhältlich.

***

## Schlitten

- Kunststoff Schlitten ([download](https://github.com/universam1/iSpindel/raw/master/drawer/))

Schlitten

Dieser wird dann benötigt, wenn keine Leiterplatte (PCB) verwendet wird.

***

## Akku

- `18650 LiIo Zelle` (z.B. `Panasonic NCR18650B`)

***

## Elektronische Bauteile

- [Wemos D1 mini](https://www.wemos.cc/en/latest/d1/d1_mini.html)
- `GY-521` Gyro & Beschleunigungssensor (MPU-6050 auf passendem Breakout-Board)
- [`DS18B20` Temperatursensor](https://www.maximintegrated.com/en/products/analog/sensors-and-sensor-interface/DS18B20.html)
- Lochrasterplatine 3x4 cm oder Platine aus Sammelbestellung
  - [iSpindel PCB 4.0](https://www.pcbway.com/project/shareproject/iSpndel_4_0.html)
  - [iSpindel The Jeffrey 2.69](https://www.pcbway.com/project/shareproject/iSpindel_The_Jeffrey_2_69___Open_Source_Distilling.html)
- Widerstände
  - 4k7 Ohm
  - 220 kOhm
  - 330 Ohm oder BAT 43 Diode
- [Mikro Schalter](http://www.reichelt.de/Schiebeschalter/SS-ESP201/3/index.html) oder bei Platine [Reed Wechsler](http://www.reichelt.de/Reedrelais/KSK-1C90/3/index.html)   
- Lipo Lademodul `TP4056` (6 pin recommended)

***

# Zusätzliche Informationen

## Shopping Liste:
- [reichelt.de](https://www.reichelt.de/my/1848159) (Hinweis: Abängig von der Platine einen der beiden Batteriehalter wählen)

## GY-521 (Gyro & Beschleunigungssensor)
Es gibt einige Klone des Sensors auf dem Markt. Diese können von schlechter Qualität sein und funktionieren ggf. nicht korrekt. Daher den Sensor am besten bei einem vertrauenswürdigen Händler kaufen – z.B. über den Link in der oben verlinkten Wemos Dokumentation.

Außerdem kann es hilfreich sein, gleich mehrere Sensoren zu bestellen und diese vor dem Verlöten auf dem Board zu testen.

Hier findest du zwei Möglichkeiten den Gyrosensor zu testen:
- [Issue 429 (comment)](https://github.com/universam1/iSpindel/issues/429#issuecomment-766389383) oder [Issue 512 (comment)](https://github.com/universam1/iSpindel/issues/512#issuecomment-864923729)
- [Issue 512 (comment)](https://github.com/universam1/iSpindel/issues/512)

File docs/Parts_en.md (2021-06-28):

# Parts

Following parts are required:

## Plastic cylinder

- plastic cylinder `Petling`. These containers are available at eBay as PET-Preforms.

***

## Drawer

- plastic drawer ([download](https://github.com/universam1/iSpindel/raw/master/drawer/))

Drawer

Only needed if you are not using a printed circuit board.

***

## Battery pack

- `18650 LiIo cell` (e.g. `Panasonic NCR18650B`)

***

## Components

- [Wemos D1 mini](https://www.wemos.cc/en/latest/d1/d1_mini.html)
- `GY-521` Gyro & Acceleration Sensor (MPU-6050 on suitable breakout board)
- [`DS18B20` Temperature Sensor](https://www.maximintegrated.com/en/products/analog/sensors-and-sensor-interface/DS18B20.html)
- Square grid 3x4 cm or a printed circuit board
  - [iSpindel PCB 4.0](https://www.pcbway.com/project/shareproject/iSpndel_4_0.html)
  - [iSpindel The Jeffrey 2.69](https://www.pcbway.com/project/shareproject/iSpindel_The_Jeffrey_2_69___Open_Source_Distilling.html)
- Resistors
  - 4k7 ohms
  - 220k ohms
  - 330 ohms or BAT43 diode
- [Microswitches](http://www.reichelt.de/Schiebeschalter/SS-ESP201/3/index.html) or at the PCB [Reed Wechsler](http://www.reichelt.de/Reedrelais/KSK-1C90/3/index.html)
- Lipo charger `TP4056` (6 pin recommended)

***

# Additional information

## Shopping lists:
- [reichelt.de](https://www.reichelt.de/my/1848159) (Note: select the correct battery holder depending on the used board)

## GY-521 (Gyro & Acceleration Sensor)
There are several clone sensors available that can be of poor quality. So make sure to buy them from a reliable source, e.g. the one linked in the above liked Wemos documentation.

Other then that, it can be helpful to order not just one sensor and test them before soldering them onto the board.

Here you find 2 options how to proceed with testing gyro sensors:
- [Issue 429 (comment)](https://github.com/universam1/iSpindel/issues/429#issuecomment-766389383) or [Issue 512 (comment)](https://github.com/universam1/iSpindel/issues/512#issuecomment-864923729)
- [Issue 512 (comment)](https://github.com/universam1/iSpindel/issues/512)

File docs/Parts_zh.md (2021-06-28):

# 组件

需要以下部件：

## 塑料圆形容器

- 塑料圆柱体 `瓶胚`，这些容器可在 eBay 上以 PET 定制件的形式买到。

***

## 草图

- 塑料模板 [下载](https://github.com/universam1/iSpindel/raw/master/drawer/)

Sled
***

## 电池盒

- `18650 锂电池` (例如` 松下 NCR18650B`)

***

## 零部件

- [Wemos D1 mini](https://www.wemos.cc/en/latest/d1/d1_mini.html) 开发板
- `GY-521`  陀螺仪和加速传感器 ( MPU-6050 在适合的分线板上)
- [DS18B20 温度传感器](https://www.maximintegrated.com/en/products/analog/sensors-and-sensor-interface/DS18B20.html)
- 3x4cm 方形网格或印制电路板
- 电阻
  - 4k7 ohms
  - 220k ohms
  - 330 ohms or BAT43 二极管
- [微型开关](http://www.reichelt.de/Schiebeschalter/SS-ESP201/3/index.html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)
或 电路板上的 [换簧器](http://www.reichelt.de/Reedrelais/KSK-1C90/3/index.html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)
- 锂电充电板 `TP4056` (推荐 6 针)

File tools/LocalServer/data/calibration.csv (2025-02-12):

timestamp | gravity | angle | temperature | temp_units | battery | interval | name | ID | RSSI | token
2025-02-11 16:26:07 | 26.61 | 76.24 | 20.81 | C | 4.11 | 10 | SpinHydro | 6548473 | -62 | 8hyLBUGgsPvEzoDyJpzu
2025-02-11 16:26:18 | 26.61 | 76.24 | 20.81 | C | 4.11 | 10 | SpinHydro | 6548473 | -62 | 8hyLBUGgsPvEzoDyJpzu
2025-02-11 16:26:30 | 26.62 | 76.25 | 20.75 | C | 4.11 | 10 | SpinHydro | 6548473 | -60 | 8hyLBUGgsPvEzoDyJpzu
2025-02-11 16:26:41 | 26.62 | 76.26 | 20.75 | C | 4.11 | 10 | SpinHydro | 6548473 | -61 | 8hyLBUGgsPvEzoDyJpzu
2025-02-11 16:26:52 | 26.62 | 76.26 | 20.81 | C | 4.11 | 10 | SpinHydro | 6548473 | -61 | 8hyLBUGgsPvEzoDyJpzu
2025-02-11 16:27:03 | 26.62 | 76.26 | 20.75 | C | 4.11 | 10 | SpinHydro | 6548473 | -61 | 8hyLBUGgsPvEzoDyJpzu
2025-02-11 16:27:14 | 26.63 | 76.28 | 20.75 | C | 4.11 | 10 | SpinHydro | 6548473 | -62 | 8hyLBUGgsPvEzoDyJpzu
2025-02-11 16:27:25 | 26.62 | 76.27 | 20.75 | C | 4.11 | 10 | SpinHydro | 6548473 | -60 | 8hyLBUGgsPvEzoDyJpzu
2025-02-11 16:27:36 | 26.63 | 76.27 | 20.75 | C | 4.11 | 10 | SpinHydro | 6548473 | -61 | 8hyLBUGgsPvEzoDyJpzu
2025-02-11 16:27:48 | 26.64 | 76.30 | 20.75 | C | 4.11 | 10 | SpinHydro | 6548473 | -57 | 8hyLBUGgsPvEzoDyJpzu
2025-02-11 16:27:59 | 26.64 | 76.30 | 20.75 | C | 4.11 | 10 | SpinHydro | 6548473 | -60 | 8hyLBUGgsPvEzoDyJpzu
2025-02-11 16:28:10 | 26.64 | 76.30 | 20.75 | C | 4.11 | 10 | SpinHydro | 6548473 | -62 | 8hyLBUGgsPvEzoDyJpzu
2025-02-11 16:28:23 | 26.64 | 76.30 | 20.75 | C | 4.10 | 10 | SpinHydro | 6548473 | -57 | 8hyLBUGgsPvEzoDyJpzu
2025-02-11 16:28:34 | 26.64 | 76.30 | 20.81 | C | 4.10 | 10 | SpinHydro | 6548473 | -60 | 8hyLBUGgsPvEzoDyJpzu
2025-02-11 16:28:46 | 26.65 | 76.31 | 20.81 | C | 4.11 | 10 | SpinHydro | 6548473 | -59 | 8hyLBUGgsPvEzoDyJpzu
2025-02-11 16:28:57 | 26.65 | 76.32 | 20.81 | C | 4.11 | 10 | SpinHydro | 6548473 | -58 | 8hyLBUGgsPvEzoDyJpzu
2025-02-11 16:29:08 | 26.64 | 76.30 | 20.81 | C | 4.11 | 10 | SpinHydro | 6548473 | -58 | 8hyLBUGgsPvEzoDyJpzu
2025-02-11 16:29:19 | 26.64 | 76.31 | 20.81 | C | 4.11 | 10 | SpinHydro | 6548473 | -53 | 8hyLBUGgsPvEzoDyJpzu
2025-02-11 16:29:30 | 26.64 | 76.31 | 20.81 | C | 4.11 | 10 | SpinHydro | 6548473 | -58 | 8hyLBUGgsPvEzoDyJpzu
2025-02-11 16:35:15 | 24.95 | 72.99 | 20.50 | C | 4.11 | 10 | SpinHydro | 6548473 | -55 | 8hyLBUGgsPvEzoDyJpzu
2025-02-11 16:35:27 | 24.87 | 72.83 | 20.50 | C | 4.11 | 10 | SpinHydro | 6548473 | -56 | 8hyLBUGgsPvEzoDyJpzu
2025-02-11 16:35:38 | 24.81 | 72.73 | 20.50 | C | 4.11 | 10 | SpinHydro | 6548473 | -55 | 8hyLBUGgsPvEzoDyJpzu
2025-02-11 16:35:49 | 24.76 | 72.62 | 20.50 | C | 4.11 | 10 | SpinHydro | 6548473 | -55 | 8hyLBUGgsPvEzoDyJpzu
2025-02-11 16:36:00 | 24.68 | 72.45 | 20.50 | C | 4.11 | 10 | SpinHydro | 6548473 | -56 | 8hyLBUGgsPvEzoDyJpzu
2025-02-11 16:36:11 | 24.63 | 72.36 | 20.50 | C | 4.11 | 10 | SpinHydro | 6548473 | -55 | 8hyLBUGgsPvEzoDyJpzu
2025-02-11 16:36:33 | 24.59 | 72.28 | 20.50 | C | 4.11 | 10 | SpinHydro | 6548473 | -54 | 8hyLBUGgsPvEzoDyJpzu
2025-02-11 16:36:45 | 24.58 | 72.26 | 20.50 | C | 4.11 | 10 | SpinHydro | 6548473 | -56 | 8hyLBUGgsPvEzoDyJpzu
2025-02-11 16:36:56 | 24.57 | 72.25 | 20.44 | C | 4.11 | 10 | SpinHydro | 6548473 | -55 | 8hyLBUGgsPvEzoDyJpzu
2025-02-11 16:37:07 | 24.56 | 72.23 | 20.44 | C | 4.11 | 10 | SpinHydro | 6548473 | -54 | 8hyLBUGgsPvEzoDyJpzu
2025-02-11 16:37:18 | 24.55 | 72.21 | 20.44 | C | 4.11 | 10 | SpinHydro | 6548473 | -55 | 8hyLBUGgsPvEzoDyJpzu
2025-02-11 16:37:29 | 24.53 | 72.17 | 20.44 | C | 4.11 | 10 | SpinHydro | 6548473 | -54 | 8hyLBUGgsPvEzoDyJpzu
2025-02-11 16:37:40 | 24.52 | 72.16 | 20.50 | C | 4.11 | 10 | SpinHydro | 6548473 | -55 | 8hyLBUGgsPvEzoDyJpzu
2025-02-11 16:37:51 | 24.51 | 72.13 | 20.44 | C | 4.11 | 10 | SpinHydro | 6548473 | -55 | 8hyLBUGgsPvEzoDyJpzu
2025-02-11 16:38:03 | 24.50 | 72.12 | 20.44 | C | 4.11 | 10 | SpinHydro | 6548473 | -55 | 8hyLBUGgsPvEzoDyJpzu
2025-02-11 16:38:14 | 24.51 | 72.12 | 20.44 | C | 4.11 | 10 | SpinHydro | 6548473 | -54 | 8hyLBUGgsPvEzoDyJpzu
2025-02-11 16:38:25 | 24.50 | 72.11 | 20.44 | C | 4.11 | 10 | SpinHydro | 6548473 | -57 | 8hyLBUGgsPvEzoDyJpzu
2025-02-11 16:38:36 | 24.48 | 72.07 | 20.44 | C | 4.11 | 10 | SpinHydro | 6548473 | -55 | 8hyLBUGgsPvEzoDyJpzu
2025-02-11 16:38:47 | 24.47 | 72.06 | 20.44 | C | 4.11 | 10 | SpinHydro | 6548473 | -54 | 8hyLBUGgsPvEzoDyJpzu
2025-02-11 16:38:58 | 24.47 | 72.05 | 20.44 | C | 4.11 | 10 | SpinHydro | 6548473 | -54 | 8hyLBUGgsPvEzoDyJpzu
2025-02-11 16:39:09 | 24.46 | 72.03 | 20.44 | C | 4.11 | 10 | SpinHydro | 6548473 | -54 | 8hyLBUGgsPvEzoDyJpzu
2025-02-11 16:39:20 | 24.45 | 72.02 | 20.44 | C | 4.11 | 10 | SpinHydro | 6548473 | -56 | 8hyLBUGgsPvEzoDyJpzu
2025-02-11 16:39:32 | 24.45 | 72.02 | 20.44 | C | 4.11 | 10 | SpinHydro | 6548473 | -56 | 8hyLBUGgsPvEzoDyJpzu
2025-02-11 16:39:43 | 24.45 | 72.01 | 20.44 | C | 4.11 | 10 | SpinHydro | 6548473 | -56 | 8hyLBUGgsPvEzoDyJpzu
2025-02-11 16:39:54 | 24.45 | 72.00 | 20.44 | C | 4.11 | 10 | SpinHydro | 6548473 | -55 | 8hyLBUGgsPvEzoDyJpzu
2025-02-11 16:40:05 | 24.44 | 72.00 | 20.44 | C | 4.11 | 10 | SpinHydro | 6548473 | -56 | 8hyLBUGgsPvEzoDyJpzu
2025-02-11 16:40:16 | 24.43 | 71.98 | 20.44 | C | 4.11 | 10 | SpinHydro | 6548473 | -55 | 8hyLBUGgsPvEzoDyJpzu
2025-02-11 16:40:27 | 24.43 | 71.97 | 20.44 | C | 4.11 | 10 | SpinHydro | 6548473 | -55 | 8hyLBUGgsPvEzoDyJpzu
2025-02-11 16:40:41 | 24.43 | 71.97 | 20.44 | C | 4.10 | 10 | SpinHydro | 6548473 | -56 | 8hyLBUGgsPvEzoDyJpzu
2025-02-11 16:40:52 | 24.42 | 71.96 | 20.50 | C | 4.11 | 10 | SpinHydro | 6548473 | -55 | 8hyLBUGgsPvEzoDyJpzu
2025-02-11 16:41:03 | 24.43 | 71.97 | 20.50 | C | 4.11 | 10 | SpinHydro | 6548473 | -55 | 8hyLBUGgsPvEzoDyJpzu
2025-02-11 16:41:14 | 24.43 | 71.97 | 20.50 | C | 4.11 | 10 | SpinHydro | 6548473 | -54 | 8hyLBUGgsPvEzoDyJpzu
2025-02-11 16:41:26 | 24.42 | 71.95 | 20.50 | C | 4.11 | 10 | SpinHydro | 6548473 | -55 | 8hyLBUGgsPvEzoDyJpzu
2025-02-11 16:41:37 | 24.43 | 71.97 | 20.50 | C | 4.11 | 10 | SpinHydro | 6548473 | -57 | 8hyLBUGgsPvEzoDyJpzu
2025-02-11 16:44:29 | 24.84 | 72.77 | 20.56 | C | 4.10 | 10 | SpinHydro | 6548473 | -60 | 8hyLBUGgsPvEzoDyJpzu
2025-02-11 16:44:40 | 24.84 | 72.78 | 20.56 | C | 4.11 | 10 | SpinHydro | 6548473 | -60 | 8hyLBUGgsPvEzoDyJpzu
2025-02-11 16:44:51 | 24.84 | 72.77 | 20.56 | C | 4.11 | 10 | SpinHydro | 6548473 | -59 | 8hyLBUGgsPvEzoDyJpzu
2025-02-11 16:45:03 | 24.84 | 72.77 | 20.56 | C | 4.11 | 10 | SpinHydro | 6548473 | -60 | 8hyLBUGgsPvEzoDyJpzu
2025-02-11 16:45:14 | 24.85 | 72.79 | 20.56 | C | 4.11 | 10 | SpinHydro | 6548473 | -58 | 8hyLBUGgsPvEzoDyJpzu
2025-02-11 16:45:25 | 24.84 | 72.77 | 20.56 | C | 4.11 | 10 | SpinHydro | 6548473 | -60 | 8hyLBUGgsPvEzoDyJpzu
2025-02-11 16:45:36 | 24.84 | 72.77 | 20.50 | C | 4.11 | 10 | SpinHydro | 6548473 | -59 | 8hyLBUGgsPvEzoDyJpzu
2025-02-11 16:45:47 | 24.85 | 72.79 | 20.50 | C | 4.11 | 10 | SpinHydro | 6548473 | -60 | 8hyLBUGgsPvEzoDyJpzu
2025-02-11 16:45:58 | 24.84 | 72.78 | 20.56 | C | 4.11 | 10 | SpinHydro | 6548473 | -60 | 8hyLBUGgsPvEzoDyJpzu
2025-02-11 16:46:12 | 24.83 | 72.76 | 20.50 | C | 4.10 | 10 | SpinHydro | 6548473 | -63 | 8hyLBUGgsPvEzoDyJpzu
2025-02-11 16:46:23 | 24.82 | 72.74 | 20.56 | C | 4.10 | 10 | SpinHydro | 6548473 | -60 | 8hyLBUGgsPvEzoDyJpzu
2025-02-11 16:46:34 | 24.83 | 72.75 | 20.56 | C | 4.11 | 10 | SpinHydro | 6548473 | -59 | 8hyLBUGgsPvEzoDyJpzu
2025-02-11 16:46:45 | 24.81 | 72.72 | 20.56 | C | 4.11 | 10 | SpinHydro | 6548473 | -60 | 8hyLBUGgsPvEzoDyJpzu
2025-02-11 16:46:56 | 24.81 | 72.72 | 20.56 | C | 4.11 | 10 | SpinHydro | 6548473 | -60 | 8hyLBUGgsPvEzoDyJpzu
2025-02-11 16:47:07 | 24.81 | 72.72 | 20.56 | C | 4.10 | 10 | SpinHydro | 6548473 | -60 | 8hyLBUGgsPvEzoDyJpzu
2025-02-11 16:47:19 | 24.81 | 72.72 | 20.56 | C | 4.11 | 10 | SpinHydro | 6548473 | -59 | 8hyLBUGgsPvEzoDyJpzu
2025-02-11 16:47:30 | 24.83 | 72.75 | 20.56 | C | 4.11 | 10 | SpinHydro | 6548473 | -60 | 8hyLBUGgsPvEzoDyJpzu
2025-02-11 16:47:43 | 24.83 | 72.76 | 20.56 | C | 4.10 | 10 | SpinHydro | 6548473 | -70 | 8hyLBUGgsPvEzoDyJpzu
2025-02-11 16:47:54 | 24.83 | 72.76 | 20.56 | C | 4.11 | 10 | SpinHydro | 6548473 | -69 | 8hyLBUGgsPvEzoDyJpzu
2025-02-11 16:48:05 | 24.83 | 72.76 | 20.62 | C | 4.11 | 10 | SpinHydro | 6548473 | -68 | 8hyLBUGgsPvEzoDyJpzu
2025-02-11 16:48:17 | 24.80 | 72.71 | 20.62 | C | 4.10 | 10 | SpinHydro | 6548473 | -67 | 8hyLBUGgsPvEzoDyJpzu
2025-02-11 16:48:28 | 24.83 | 72.76 | 20.56 | C | 4.11 | 10 | SpinHydro | 6548473 | -67 | 8hyLBUGgsPvEzoDyJpzu
2025-02-11 16:48:39 | 24.83 | 72.76 | 20.62 | C | 4.11 | 10 | SpinHydro | 6548473 | -66 | 8hyLBUGgsPvEzoDyJpzu
2025-02-11 16:48:50 | 24.84 | 72.78 | 20.56 | C | 4.11 | 10 | SpinHydro | 6548473 | -68 | 8hyLBUGgsPvEzoDyJpzu
2025-02-11 16:49:01 | 24.84 | 72.78 | 20.56 | C | 4.10 | 10 | SpinHydro | 6548473 | -67 | 8hyLBUGgsPvEzoDyJpzu
2025-02-11 16:49:12 | 24.83 | 72.76 | 20.56 | C | 4.11 | 10 | SpinHydro | 6548473 | -67 | 8hyLBUGgsPvEzoDyJpzu
2025-02-11 16:49:23 | 24.84 | 72.77 | 20.56 | C | 4.11 | 10 | SpinHydro | 6548473 | -67 | 8hyLBUGgsPvEzoDyJpzu
2025-02-11 16:49:35 | 24.83 | 72.75 | 20.56 | C | 4.11 | 10 | SpinHydro | 6548473 | -67 | 8hyLBUGgsPvEzoDyJpzu
2025-02-11 16:49:46 | 24.84 | 72.78 | 20.56 | C | 4.11 | 10 | SpinHydro | 6548473 | -67 | 8hyLBUGgsPvEzoDyJpzu
2025-02-11 16:49:57 | 24.84 | 72.77 | 20.56 | C | 4.10 | 10 | SpinHydro | 6548473 | -67 | 8hyLBUGgsPvEzoDyJpzu
2025-02-11 16:50:08 | 24.83 | 72.76 | 20.56 | C | 4.11 | 10 | SpinHydro | 6548473 | -66 | 8hyLBUGgsPvEzoDyJpzu
2025-02-11 16:50:19 | 24.85 | 72.79 | 20.56 | C | 4.10 | 10 | SpinHydro | 6548473 | -66 | 8hyLBUGgsPvEzoDyJpzu
2025-02-11 16:50:30 | 24.84 | 72.77 | 20.56 | C | 4.10 | 10 | SpinHydro | 6548473 | -69 | 8hyLBUGgsPvEzoDyJpzu
2025-02-11 16:50:44 | 24.83 | 72.76 | 20.56 | C | 4.10 | 10 | SpinHydro | 6548473 | -68 | 8hyLBUGgsPvEzoDyJpzu
2025-02-11 16:51:00 | 24.83 | 72.76 | 20.56 | C | 4.10 | 10 | SpinHydro | 6548473 | -71 | 8hyLBUGgsPvEzoDyJpzu
2025-02-11 16:51:11 | 24.83 | 72.76 | 20.75 | C | 4.10 | 10 | SpinHydro | 6548473 | -68 | 8hyLBUGgsPvEzoDyJpzu
2025-02-11 16:51:22 | 24.84 | 72.78 | 20.75 | C | 4.10 | 10 | SpinHydro | 6548473 | -67 | 8hyLBUGgsPvEzoDyJpzu
2025-02-11 16:51:33 | 24.85 | 72.80 | 20.81 | C | 4.10 | 10 | SpinHydro | 6548473 | -67 | 8hyLBUGgsPvEzoDyJpzu
2025-02-11 16:51:45 | 24.85 | 72.79 | 20.81 | C | 4.10 | 10 | SpinHydro | 6548473 | -67 | 8hyLBUGgsPvEzoDyJpzu
2025-02-11 16:51:56 | 24.85 | 72.80 | 20.75 | C | 4.10 | 10 | SpinHydro | 6548473 | -68 | 8hyLBUGgsPvEzoDyJpzu
2025-02-11 16:52:07 | 24.85 | 72.80 | 20.75 | C | 4.11 | 10 | SpinHydro | 6548473 | -65 | 8hyLBUGgsPvEzoDyJpzu
2025-02-11 16:52:20 | 24.85 | 72.80 | 20.75 | C | 4.10 | 10 | SpinHydro | 6548473 | -69 | 8hyLBUGgsPvEzoDyJpzu
2025-02-11 16:52:31 | 24.85 | 72.80 | 20.75 | C | 4.10 | 10 | SpinHydro | 6548473 | -68 | 8hyLBUGgsPvEzoDyJpzu
2025-02-11 16:52:43 | 24.85 | 72.80 | 20.75 | C | 4.10 | 10 | SpinHydro | 6548473 | -73 | 8hyLBUGgsPvEzoDyJpzu
2025-02-11 16:55:19 | 24.22 | 71.56 | 20.62 | C | 4.10 | 10 | SpinHydro | 6548473 | -67 | 8hyLBUGgsPvEzoDyJpzu
2025-02-11 16:55:30 | 24.21 | 71.55 | 20.62 | C | 4.10 | 10 | SpinHydro | 6548473 | -65 | 8hyLBUGgsPvEzoDyJpzu
2025-02-11 16:55:41 | 24.22 | 71.57 | 20.62 | C | 4.10 | 10 | SpinHydro | 6548473 | -65 | 8hyLBUGgsPvEzoDyJpzu
2025-02-11 16:55:52 | 24.22 | 71.57 | 20.62 | C | 4.10 | 10 | SpinHydro | 6548473 | -65 | 8hyLBUGgsPvEzoDyJpzu
2025-02-11 16:56:03 | 24.23 | 71.58 | 20.56 | C | 4.11 | 10 | SpinHydro | 6548473 | -63 | 8hyLBUGgsPvEzoDyJpzu
2025-02-11 16:56:20 | 24.23 | 71.59 | 20.56 | C | 4.10 | 10 | SpinHydro | 6548473 | -65 | 8hyLBUGgsPvEzoDyJpzu
2025-02-11 16:56:36 | 24.22 | 71.57 | 20.69 | C | 4.10 | 10 | SpinHydro | 6548473 | -66 | 8hyLBUGgsPvEzoDyJpzu
2025-02-11 16:56:47 | 24.24 | 71.60 | 20.81 | C | 4.10 | 10 | SpinHydro | 6548473 | -64 | 8hyLBUGgsPvEzoDyJpzu
2025-02-11 16:56:58 | 24.24 | 71.60 | 20.88 | C | 4.10 | 10 | SpinHydro | 6548473 | -66 | 8hyLBUGgsPvEzoDyJpzu
2025-02-11 16:57:09 | 24.25 | 71.62 | 20.88 | C | 4.10 | 10 | SpinHydro | 6548473 | -65 | 8hyLBUGgsPvEzoDyJpzu
2025-02-11 16:57:20 | 24.25 | 71.62 | 20.88 | C | 4.10 | 10 | SpinHydro | 6548473 | -65 | 8hyLBUGgsPvEzoDyJpzu
2025-02-11 16:57:32 | 24.23 | 71.59 | 20.81 | C | 4.10 | 10 | SpinHydro | 6548473 | -65 | 8hyLBUGgsPvEzoDyJpzu
2025-02-11 16:57:43 | 24.23 | 71.59 | 20.81 | C | 4.10 | 10 | SpinHydro | 6548473 | -65 | 8hyLBUGgsPvEzoDyJpzu
2025-02-11 16:57:54 | 24.24 | 71.60 | 20.81 | C | 4.10 | 10 | SpinHydro | 6548473 | -65 | 8hyLBUGgsPvEzoDyJpzu
2025-02-11 16:58:05 | 24.24 | 71.59 | 20.75 | C | 4.10 | 10 | SpinHydro | 6548473 | -65 | 8hyLBUGgsPvEzoDyJpzu
2025-02-11 16:58:16 | 24.24 | 71.60 | 20.75 | C | 4.10 | 10 | SpinHydro | 6548473 | -64 | 8hyLBUGgsPvEzoDyJpzu
2025-02-11 16:58:27 | 24.23 | 71.59 | 20.75 | C | 4.10 | 10 | SpinHydro | 6548473 | -65 | 8hyLBUGgsPvEzoDyJpzu
2025-02-11 16:58:38 | 24.25 | 71.61 | 20.69 | C | 4.10 | 10 | SpinHydro | 6548473 | -65 | 8hyLBUGgsPvEzoDyJpzu
2025-02-11 16:58:50 | 24.26 | 71.65 | 20.75 | C | 4.10 | 10 | SpinHydro | 6548473 | -66 | 8hyLBUGgsPvEzoDyJpzu
2025-02-11 16:59:01 | 24.26 | 71.64 | 20.69 | C | 4.10 | 10 | SpinHydro | 6548473 | -66 | 8hyLBUGgsPvEzoDyJpzu
2025-02-11 16:59:14 | 24.25 | 71.62 | 20.69 | C | 4.10 | 10 | SpinHydro | 6548473 | -66 | 8hyLBUGgsPvEzoDyJpzu
2025-02-11 16:59:25 | 24.25 | 71.63 | 20.75 | C | 4.10 | 10 | SpinHydro | 6548473 | -66 | 8hyLBUGgsPvEzoDyJpzu
2025-02-11 16:59:36 | 24.26 | 71.65 | 20.75 | C | 4.10 | 10 | SpinHydro | 6548473 | -67 | 8hyLBUGgsPvEzoDyJpzu
2025-02-11 16:59:48 | 24.26 | 71.65 | 20.69 | C | 4.10 | 10 | SpinHydro | 6548473 | -68 | 8hyLBUGgsPvEzoDyJpzu
2025-02-11 16:59:59 | 24.26 | 71.63 | 20.69 | C | 4.10 | 10 | SpinHydro | 6548473 | -68 | 8hyLBUGgsPvEzoDyJpzu
2025-02-11 17:00:12 | 24.25 | 71.63 | 20.69 | C | 4.10 | 10 | SpinHydro | 6548473 | -70 | 8hyLBUGgsPvEzoDyJpzu
2025-02-11 17:00:26 | 24.25 | 71.63 | 20.69 | C | 4.10 | 10 | SpinHydro | 6548473 | -68 | 8hyLBUGgsPvEzoDyJpzu
2025-02-11 17:00:37 | 24.25 | 71.62 | 20.75 | C | 4.10 | 10 | SpinHydro | 6548473 | -69 | 8hyLBUGgsPvEzoDyJpzu
2025-02-11 17:00:50 | 24.25 | 71.63 | 20.81 | C | 4.10 | 10 | SpinHydro | 6548473 | -70 | 8hyLBUGgsPvEzoDyJpzu
2025-02-11 17:01:01 | 24.25 | 71.63 | 20.88 | C | 4.10 | 10 | SpinHydro | 6548473 | -67 | 8hyLBUGgsPvEzoDyJpzu
2025-02-11 17:01:13 | 24.25 | 71.63 | 20.88 | C | 4.10 | 10 | SpinHydro | 6548473 | -67 | 8hyLBUGgsPvEzoDyJpzu
2025-02-11 17:01:26 | 24.25 | 71.63 | 20.81 | C | 4.10 | 10 | SpinHydro | 6548473 | -70 | 8hyLBUGgsPvEzoDyJpzu
2025-02-11 17:01:37 | 24.27 | 71.66 | 20.88 | C | 4.10 | 10 | SpinHydro | 6548473 | -65 | 8hyLBUGgsPvEzoDyJpzu
2025-02-11 17:01:48 | 24.26 | 71.64 | 20.88 | C | 4.10 | 10 | SpinHydro | 6548473 | -73 | 8hyLBUGgsPvEzoDyJpzu
2025-02-11 17:01:59 | 24.26 | 71.64 | 20.88 | C | 4.10 | 10 | SpinHydro | 6548473 | -67 | 8hyLBUGgsPvEzoDyJpzu
2025-02-11 17:02:10 | 24.26 | 71.65 | 20.88 | C | 4.10 | 10 | SpinHydro | 6548473 | -70 | 8hyLBUGgsPvEzoDyJpzu
2025-02-11 17:02:22 | 24.26 | 71.64 | 20.81 | C | 4.10 | 10 | SpinHydro | 6548473 | -71 | 8hyLBUGgsPvEzoDyJpzu
2025-02-11 17:02:33 | 24.26 | 71.63 | 20.81 | C | 4.10 | 10 | SpinHydro | 6548473 | -71 | 8hyLBUGgsPvEzoDyJpzu
2025-02-11 17:02:46 | 24.25 | 71.63 | 20.81 | C | 4.10 | 10 | SpinHydro | 6548473 | -73 | 8hyLBUGgsPvEzoDyJpzu
2025-02-11 17:02:57 | 24.26 | 71.64 | 20.81 | C | 4.10 | 10 | SpinHydro | 6548473 | -71 | 8hyLBUGgsPvEzoDyJpzu
2025-02-11 17:03:11 | 24.25 | 71.63 | 20.88 | C | 4.10 | 10 | SpinHydro | 6548473 | -73 | 8hyLBUGgsPvEzoDyJpzu
2025-02-11 17:03:22 | 24.26 | 71.64 | 20.88 | C | 4.10 | 10 | SpinHydro | 6548473 | -71 | 8hyLBUGgsPvEzoDyJpzu
2025-02-11 17:03:33 | 24.26 | 71.65 | 20.88 | C | 4.10 | 10 | SpinHydro | 6548473 | -72 | 8hyLBUGgsPvEzoDyJpzu
2025-02-11 17:03:44 | 23.49 | 70.15 | 20.88 | C | 4.10 | 10 | SpinHydro | 6548473 | -58 | 8hyLBUGgsPvEzoDyJpzu
2025-02-11 17:03:55 | 24.65 | 72.39 | 20.88 | C | 4.10 | 10 | SpinHydro | 6548473 | -62 | 8hyLBUGgsPvEzoDyJpzu
2025-02-11 17:04:06 | 24.84 | 72.78 | 20.88 | C | 4.10 | 10 | SpinHydro | 6548473 | -65 | 8hyLBUGgsPvEzoDyJpzu
2025-02-11 17:04:18 | 24.30 | 71.72 | 20.81 | C | 4.10 | 10 | SpinHydro | 6548473 | -76 | 8hyLBUGgsPvEzoDyJpzu
2025-02-11 17:04:29 | 24.35 | 71.81 | 20.81 | C | 4.10 | 10 | SpinHydro | 6548473 | -86 | 8hyLBUGgsPvEzoDyJpzu
2025-02-11 17:04:43 | 24.35 | 71.82 | 20.75 | C | 4.10 | 10 | SpinHydro | 6548473 | -73 | 8hyLBUGgsPvEzoDyJpzu
2025-02-11 17:04:54 | 24.34 | 71.80 | 20.81 | C | 4.10 | 10 | SpinHydro | 6548473 | -67 | 8hyLBUGgsPvEzoDyJpzu
2025-02-11 17:05:05 | 24.35 | 71.82 | 20.81 | C | 4.10 | 10 | SpinHydro | 6548473 | -64 | 8hyLBUGgsPvEzoDyJpzu
2025-02-11 17:05:16 | 24.34 | 71.80 | 20.81 | C | 4.10 | 10 | SpinHydro | 6548473 | -64 | 8hyLBUGgsPvEzoDyJpzu
2025-02-11 17:07:18 | 23.81 | 70.76 | 20.69 | C | 4.10 | 10 | SpinHydro | 6548473 | -64 | 8hyLBUGgsPvEzoDyJpzu
2025-02-11 17:07:30 | 23.76 | 70.67 | 20.62 | C | 4.10 | 10 | SpinHydro | 6548473 | -62 | 8hyLBUGgsPvEzoDyJpzu
2025-02-11 17:07:41 | 23.76 | 70.67 | 20.69 | C | 4.10 | 10 | SpinHydro | 6548473 | -63 | 8hyLBUGgsPvEzoDyJpzu
2025-02-11 17:07:52 | 23.77 | 70.69 | 20.62 | C | 4.10 | 10 | SpinHydro | 6548473 | -63 | 8hyLBUGgsPvEzoDyJpzu
2025-02-11 17:08:03 | 23.78 | 70.70 | 20.62 | C | 4.10 | 10 | SpinHydro | 6548473 | -64 | 8hyLBUGgsPvEzoDyJpzu
2025-02-11 17:08:14 | 23.78 | 70.70 | 20.56 | C | 4.10 | 10 | SpinHydro | 6548473 | -64 | 8hyLBUGgsPvEzoDyJpzu
2025-02-11 17:08:59 | 23.79 | 70.72 | 20.56 | C | 4.10 | 10 | SpinHydro | 6548473 | -64 | 8hyLBUGgsPvEzoDyJpzu
2025-02-11 17:09:10 | 23.79 | 70.73 | 20.56 | C | 4.10 | 10 | SpinHydro | 6548473 | -64 | 8hyLBUGgsPvEzoDyJpzu
2025-02-11 17:09:21 | 23.78 | 70.71 | 20.50 | C | 4.10 | 10 | SpinHydro | 6548473 | -64 | 8hyLBUGgsPvEzoDyJpzu
2025-02-11 17:09:32 | 23.77 | 70.69 | 20.56 | C | 4.10 | 10 | SpinHydro | 6548473 | -63 | 8hyLBUGgsPvEzoDyJpzu
2025-02-11 17:09:43 | 23.79 | 70.72 | 20.50 | C | 4.10 | 10 | SpinHydro | 6548473 | -64 | 8hyLBUGgsPvEzoDyJpzu
2025-02-11 17:09:54 | 23.78 | 70.71 | 20.50 | C | 4.10 | 10 | SpinHydro | 6548473 | -63 | 8hyLBUGgsPvEzoDyJpzu
2025-02-11 17:10:05 | 23.78 | 70.70 | 20.50 | C | 4.10 | 10 | SpinHydro | 6548473 | -63 | 8hyLBUGgsPvEzoDyJpzu
2025-02-11 17:10:19 | 23.78 | 70.71 | 20.50 | C | 4.10 | 10 | SpinHydro | 6548473 | -63 | 8hyLBUGgsPvEzoDyJpzu
2025-02-11 17:10:30 | 23.78 | 70.70 | 20.56 | C | 4.10 | 10 | SpinHydro | 6548473 | -63 | 8hyLBUGgsPvEzoDyJpzu
2025-02-11 17:10:44 | 23.78 | 70.70 | 20.56 | C | 4.10 | 10 | SpinHydro | 6548473 | -64 | 8hyLBUGgsPvEzoDyJpzu
2025-02-11 17:10:55 | 23.78 | 70.71 | 20.62 | C | 4.10 | 10 | SpinHydro | 6548473 | -63 | 8hyLBUGgsPvEzoDyJpzu
2025-02-11 17:11:08 | 23.77 | 70.68 | 20.62 | C | 4.10 | 10 | SpinHydro | 6548473 | -63 | 8hyLBUGgsPvEzoDyJpzu
2025-02-11 17:11:19 | 23.78 | 70.71 | 20.69 | C | 4.10 | 10 | SpinHydro | 6548473 | -63 | 8hyLBUGgsPvEzoDyJpzu
2025-02-11 17:11:30 | 23.78 | 70.70 | 20.69 | C | 4.10 | 10 | SpinHydro | 6548473 | -64 | 8hyLBUGgsPvEzoDyJpzu
2025-02-11 17:11:42 | 23.78 | 70.71 | 20.69 | C | 4.10 | 10 | SpinHydro | 6548473 | -63 | 8hyLBUGgsPvEzoDyJpzu
2025-02-11 17:11:53 | 23.78 | 70.71 | 20.62 | C | 4.10 | 10 | SpinHydro | 6548473 | -63 | 8hyLBUGgsPvEzoDyJpzu
2025-02-11 17:12:04 | 23.79 | 70.73 | 20.69 | C | 4.10 | 10 | SpinHydro | 6548473 | -63 | 8hyLBUGgsPvEzoDyJpzu
2025-02-11 17:12:15 | 23.79 | 70.72 | 20.62 | C | 4.10 | 10 | SpinHydro | 6548473 | -63 | 8hyLBUGgsPvEzoDyJpzu
2025-02-11 17:12:28 | 23.78 | 70.71 | 20.62 | C | 4.10 | 10 | SpinHydro | 6548473 | -63 | 8hyLBUGgsPvEzoDyJpzu
2025-02-11 17:12:42 | 23.78 | 70.70 | 20.69 | C | 4.10 | 10 | SpinHydro | 6548473 | -62 | 8hyLBUGgsPvEzoDyJpzu
2025-02-11 17:12:53 | 23.78 | 70.71 | 20.69 | C | 4.10 | 10 | SpinHydro | 6548473 | -63 | 8hyLBUGgsPvEzoDyJpzu
2025-02-11 17:13:07 | 23.78 | 70.71 | 20.75 | C | 4.10 | 10 | SpinHydro | 6548473 | -63 | 8hyLBUGgsPvEzoDyJpzu
2025-02-11 17:13:18 | 23.79 | 70.73 | 20.75 | C | 4.10 | 10 | SpinHydro | 6548473 | -64 | 8hyLBUGgsPvEzoDyJpzu
2025-02-11 17:13:29 | 23.79 | 70.73 | 20.81 | C | 4.10 | 10 | SpinHydro | 6548473 | -63 | 8hyLBUGgsPvEzoDyJpzu
2025-02-11 17:13:40 | 23.79 | 70.72 | 20.81 | C | 4.10 | 10 | SpinHydro | 6548473 | -64 | 8hyLBUGgsPvEzoDyJpzu
2025-02-11 17:13:51 | 23.78 | 70.71 | 20.75 | C | 4.10 | 10 | SpinHydro | 6548473 | -63 | 8hyLBUGgsPvEzoDyJpzu
2025-02-11 17:14:02 | 23.78 | 70.71 | 20.75 | C | 4.10 | 10 | SpinHydro | 6548473 | -63 | 8hyLBUGgsPvEzoDyJpzu
2025-02-11 17:14:13 | 23.79 | 70.73 | 20.75 | C | 4.10 | 10 | SpinHydro | 6548473 | -63 | 8hyLBUGgsPvEzoDyJpzu
2025-02-11 17:14:24 | 23.78 | 70.71 | 20.75 | C | 4.10 | 10 | SpinHydro | 6548473 | -63 | 8hyLBUGgsPvEzoDyJpzu
2025-02-11 17:14:36 | 23.79 | 70.72 | 20.69 | C | 4.10 | 10 | SpinHydro | 6548473 | -63 | 8hyLBUGgsPvEzoDyJpzu
2025-02-11 17:14:47 | 23.78 | 70.71 | 20.69 | C | 4.10 | 10 | SpinHydro | 6548473 | -63 | 8hyLBUGgsPvEzoDyJpzu
2025-02-11 17:14:58 | 23.78 | 70.71 | 20.69 | C | 4.10 | 10 | SpinHydro | 6548473 | -63 | 8hyLBUGgsPvEzoDyJpzu
2025-02-11 17:15:09 | 23.78 | 70.71 | 20.69 | C | 4.10 | 10 | SpinHydro | 6548473 | -63 | 8hyLBUGgsPvEzoDyJpzu
2025-02-11 17:15:20 | 23.79 | 70.72 | 20.62 | C | 4.10 | 10 | SpinHydro | 6548473 | -63 | 8hyLBUGgsPvEzoDyJpzu
2025-02-11 17:15:31 | 23.78 | 70.71 | 20.62 | C | 4.10 | 10 | SpinHydro | 6548473 | -63 | 8hyLBUGgsPvEzoDyJpzu
2025-02-11 17:15:42 | 23.78 | 70.71 | 20.69 | C | 4.10 | 10 | SpinHydro | 6548473 | -62 | 8hyLBUGgsPvEzoDyJpzu
2025-02-11 17:15:54 | 23.78 | 70.71 | 20.62 | C | 4.10 | 10 | SpinHydro | 6548473 | -62 | 8hyLBUGgsPvEzoDyJpzu
2025-02-11 17:16:05 | 23.78 | 70.71 | 20.62 | C | 4.10 | 10 | SpinHydro | 6548473 | -63 | 8hyLBUGgsPvEzoDyJpzu
2025-02-11 17:16:16 | 23.79 | 70.72 | 20.62 | C | 4.10 | 10 | SpinHydro | 6548473 | -62 | 8hyLBUGgsPvEzoDyJpzu
2025-02-11 17:16:29 | 23.78 | 70.72 | 20.56 | C | 4.10 | 10 | SpinHydro | 6548473 | -63 | 8hyLBUGgsPvEzoDyJpzu
2025-02-11 17:16:40 | 23.79 | 70.73 | 20.62 | C | 4.10 | 10 | SpinHydro | 6548473 | -63 | 8hyLBUGgsPvEzoDyJpzu
2025-02-11 17:16:52 | 23.79 | 70.72 | 20.62 | C | 4.10 | 10 | SpinHydro | 6548473 | -63 | 8hyLBUGgsPvEzoDyJpzu
2025-02-11 17:17:03 | 23.79 | 70.72 | 20.62 | C | 4.10 | 10 | SpinHydro | 6548473 | -63 | 8hyLBUGgsPvEzoDyJpzu
2025-02-11 17:17:16 | 23.78 | 70.70 | 20.62 | C | 4.10 | 10 | SpinHydro | 6548473 | -63 | 8hyLBUGgsPvEzoDyJpzu
2025-02-11 17:17:27 | 23.79 | 70.73 | 20.69 | C | 4.10 | 10 | SpinHydro | 6548473 | -63 | 8hyLBUGgsPvEzoDyJpzu
2025-02-11 17:17:38 | 23.79 | 70.72 | 20.69 | C | 4.10 | 10 | SpinHydro | 6548473 | -62 | 8hyLBUGgsPvEzoDyJpzu
2025-02-11 17:17:50 | 23.79 | 70.73 | 20.69 | C | 4.10 | 10 | SpinHydro | 6548473 | -63 | 8hyLBUGgsPvEzoDyJpzu
2025-02-11 17:18:03 | 23.78 | 70.71 | 20.69 | C | 4.10 | 10 | SpinHydro | 6548473 | -65 | 8hyLBUGgsPvEzoDyJpzu
2025-02-11 17:18:14 | 23.78 | 70.71 | 20.69 | C | 4.10 | 10 | SpinHydro | 6548473 | -63 | 8hyLBUGgsPvEzoDyJpzu
2025-02-11 17:18:25 | 23.78 | 70.71 | 20.75 | C | 4.10 | 10 | SpinHydro | 6548473 | -64 | 8hyLBUGgsPvEzoDyJpzu
2025-02-11 17:18:36 | 23.79 | 70.73 | 20.75 | C | 4.10 | 10 | SpinHydro | 6548473 | -61 | 8hyLBUGgsPvEzoDyJpzu
2025-02-11 17:18:48 | 23.80 | 70.74 | 20.75 | C | 4.10 | 10 | SpinHydro | 6548473 | -61 | 8hyLBUGgsPvEzoDyJpzu
2025-02-11 17:18:59 | 23.80 | 70.74 | 20.75 | C | 4.10 | 10 | SpinHydro | 6548473 | -61 | 8hyLBUGgsPvEzoDyJpzu
2025-02-11 17:22:08 | 23.39 | 69.95 | 20.50 | C | 4.10 | 10 | SpinHydro | 6548473 | -63 | 8hyLBUGgsPvEzoDyJpzu
2025-02-11 17:22:25 | 23.39 | 69.95 | 20.50 | C | 4.10 | 10 | SpinHydro | 6548473 | -71 | 8hyLBUGgsPvEzoDyJpzu
2025-02-11 17:22:36 | 23.39 | 69.94 | 20.62 | C | 4.10 | 10 | SpinHydro | 6548473 | -61 | 8hyLBUGgsPvEzoDyJpzu
2025-02-11 17:22:49 | 23.40 | 69.97 | 20.69 | C | 4.10 | 10 | SpinHydro | 6548473 | -65 | 8hyLBUGgsPvEzoDyJpzu
2025-02-11 17:23:00 | 23.39 | 69.96 | 20.69 | C | 4.10 | 10 | SpinHydro | 6548473 | -72 | 8hyLBUGgsPvEzoDyJpzu
2025-02-11 17:23:11 | 23.40 | 69.96 | 20.69 | C | 4.10 | 10 | SpinHydro | 6548473 | -68 | 8hyLBUGgsPvEzoDyJpzu
2025-02-11 17:23:22 | 23.40 | 69.97 | 20.69 | C | 4.10 | 10 | SpinHydro | 6548473 | -61 | 8hyLBUGgsPvEzoDyJpzu
2025-02-11 17:23:34 | 23.40 | 69.98 | 20.69 | C | 4.10 | 10 | SpinHydro | 6548473 | -64 | 8hyLBUGgsPvEzoDyJpzu
2025-02-11 17:23:45 | 23.39 | 69.95 | 20.69 | C | 4.10 | 10 | SpinHydro | 6548473 | -65 | 8hyLBUGgsPvEzoDyJpzu
2025-02-11 17:23:58 | 23.40 | 69.97 | 20.69 | C | 4.10 | 10 | SpinHydro | 6548473 | -71 | 8hyLBUGgsPvEzoDyJpzu
2025-02-11 17:24:15 | 23.39 | 69.95 | 20.69 | C | 4.10 | 10 | SpinHydro | 6548473 | -68 | 8hyLBUGgsPvEzoDyJpzu
2025-02-11 17:24:26 | 23.40 | 69.97 | 20.81 | C | 4.10 | 10 | SpinHydro | 6548473 | -64 | 8hyLBUGgsPvEzoDyJpzu
2025-02-11 17:24:37 | 23.40 | 69.97 | 20.88 | C | 4.10 | 10 | SpinHydro | 6548473 | -61 | 8hyLBUGgsPvEzoDyJpzu
2025-02-11 17:24:48 | 23.41 | 69.98 | 20.88 | C | 4.10 | 10 | SpinHydro | 6548473 | -64 | 8hyLBUGgsPvEzoDyJpzu
2025-02-11 17:24:59 | 23.41 | 69.99 | 20.81 | C | 4.10 | 10 | SpinHydro | 6548473 | -66 | 8hyLBUGgsPvEzoDyJpzu
2025-02-11 17:25:10 | 23.41 | 69.99 | 20.81 | C | 4.10 | 10 | SpinHydro | 6548473 | -66 | 8hyLBUGgsPvEzoDyJpzu
2025-02-11 17:25:22 | 23.40 | 69.96 | 20.81 | C | 4.10 | 10 | SpinHydro | 6548473 | -83 | 8hyLBUGgsPvEzoDyJpzu
2025-02-11 17:25:33 | 23.40 | 69.97 | 20.81 | C | 4.10 | 10 | SpinHydro | 6548473 | -70 | 8hyLBUGgsPvEzoDyJpzu
2025-02-11 17:25:44 | 23.40 | 69.97 | 20.81 | C | 4.10 | 10 | SpinHydro | 6548473 | -71 | 8hyLBUGgsPvEzoDyJpzu
2025-02-11 17:25:55 | 23.41 | 69.99 | 20.75 | C | 4.10 | 10 | SpinHydro | 6548473 | -67 | 8hyLBUGgsPvEzoDyJpzu
2025-02-11 17:26:06 | 23.41 | 69.99 | 20.75 | C | 4.10 | 10 | SpinHydro | 6548473 | -67 | 8hyLBUGgsPvEzoDyJpzu
2025-02-11 17:26:17 | 23.40 | 69.97 | 20.75 | C | 4.10 | 10 | SpinHydro | 6548473 | -62 | 8hyLBUGgsPvEzoDyJpzu
2025-02-11 17:26:28 | 23.40 | 69.97 | 20.69 | C | 4.10 | 10 | SpinHydro | 6548473 | -61 | 8hyLBUGgsPvEzoDyJpzu
2025-02-11 17:26:42 | 23.42 | 70.01 | 20.69 | C | 4.10 | 10 | SpinHydro | 6548473 | -63 | 8hyLBUGgsPvEzoDyJpzu
2025-02-11 17:26:53 | 23.41 | 69.99 | 20.69 | C | 4.10 | 10 | SpinHydro | 6548473 | -62 | 8hyLBUGgsPvEzoDyJpzu
2025-02-11 17:27:04 | 23.41 | 69.98 | 20.75 | C | 4.10 | 10 | SpinHydro | 6548473 | -65 | 8hyLBUGgsPvEzoDyJpzu
2025-02-11 17:27:15 | 23.41 | 69.99 | 20.75 | C | 4.10 | 10 | SpinHydro | 6548473 | -63 | 8hyLBUGgsPvEzoDyJpzu
2025-02-11 17:27:26 | 23.41 | 69.98 | 20.69 | C | 4.10 | 10 | SpinHydro | 6548473 | -62 | 8hyLBUGgsPvEzoDyJpzu
2025-02-11 17:27:37 | 23.40 | 69.96 | 20.69 | C | 4.10 | 10 | SpinHydro | 6548473 | -63 | 8hyLBUGgsPvEzoDyJpzu
2025-02-11 17:27:49 | 23.39 | 69.95 | 20.69 | C | 4.10 | 10 | SpinHydro | 6548473 | -62 | 8hyLBUGgsPvEzoDyJpzu
2025-02-11 17:28:00 | 23.40 | 69.96 | 20.62 | C | 4.10 | 10 | SpinHydro | 6548473 | -63 | 8hyLBUGgsPvEzoDyJpzu
2025-02-11 17:28:11 | 23.39 | 69.95 | 20.62 | C | 4.10 | 10 | SpinHydro | 6548473 | -63 | 8hyLBUGgsPvEzoDyJpzu
2025-02-11 17:28:22 | 23.40 | 69.96 | 20.62 | C | 4.10 | 10 | SpinHydro | 6548473 | -62 | 8hyLBUGgsPvEzoDyJpzu
2025-02-11 17:28:33 | 23.39 | 69.95 | 20.62 | C | 4.10 | 10 | SpinHydro | 6548473 | -62 | 8hyLBUGgsPvEzoDyJpzu
2025-02-11 17:28:44 | 23.38 | 69.93 | 20.62 | C | 4.10 | 10 | SpinHydro | 6548473 | -63 | 8hyLBUGgsPvEzoDyJpzu
2025-02-11 17:28:55 | 23.39 | 69.94 | 20.56 | C | 4.10 | 10 | SpinHydro | 6548473 | -62 | 8hyLBUGgsPvEzoDyJpzu
2025-02-11 17:29:09 | 23.38 | 69.94 | 20.62 | C | 4.10 | 10 | SpinHydro | 6548473 | -66 | 8hyLBUGgsPvEzoDyJpzu
2025-02-11 17:29:20 | 23.38 | 69.93 | 20.62 | C | 4.10 | 10 | SpinHydro | 6548473 | -68 | 8hyLBUGgsPvEzoDyJpzu
2025-02-11 17:29:34 | 23.40 | 69.97 | 20.62 | C | 4.10 | 10 | SpinHydro | 6548473 | -61 | 8hyLBUGgsPvEzoDyJpzu
2025-02-11 17:29:45 | 23.40 | 69.97 | 20.69 | C | 4.10 | 10 | SpinHydro | 6548473 | -61 | 8hyLBUGgsPvEzoDyJpzu
2025-02-11 17:33:05 | 23.08 | 69.34 | 20.50 | C | 4.10 | 10 | SpinHydro | 6548473 | -68 | 8hyLBUGgsPvEzoDyJpzu
2025-02-11 17:33:16 | 23.01 | 69.20 | 20.50 | C | 4.10 | 10 | SpinHydro | 6548473 | -74 | 8hyLBUGgsPvEzoDyJpzu
2025-02-11 17:33:27 | 23.09 | 69.37 | 20.50 | C | 4.10 | 10 | SpinHydro | 6548473 | -71 | 8hyLBUGgsPvEzoDyJpzu
2025-02-11 17:33:38 | 23.10 | 69.38 | 20.50 | C | 4.10 | 10 | SpinHydro | 6548473 | -71 | 8hyLBUGgsPvEzoDyJpzu
2025-02-11 17:33:54 | 23.09 | 69.36 | 20.50 | C | 4.10 | 10 | SpinHydro | 6548473 | -69 | 8hyLBUGgsPvEzoDyJpzu
2025-02-11 17:34:28 | 23.09 | 69.36 | 20.81 | C | 4.10 | 10 | SpinHydro | 6548473 | -71 | 8hyLBUGgsPvEzoDyJpzu
2025-02-11 17:34:39 | 23.10 | 69.38 | 20.94 | C | 4.10 | 10 | SpinHydro | 6548473 | -66 | 8hyLBUGgsPvEzoDyJpzu
2025-02-11 17:34:52 | 23.10 | 69.38 | 20.94 | C | 4.10 | 10 | SpinHydro | 6548473 | -74 | 8hyLBUGgsPvEzoDyJpzu
2025-02-11 17:35:03 | 23.10 | 69.38 | 21.00 | C | 4.10 | 10 | SpinHydro | 6548473 | -73 | 8hyLBUGgsPvEzoDyJpzu
2025-02-11 17:35:14 | 23.10 | 69.39 | 21.06 | C | 4.10 | 10 | SpinHydro | 6548473 | -77 | 8hyLBUGgsPvEzoDyJpzu
2025-02-11 17:35:26 | 23.10 | 69.38 | 21.00 | C | 4.10 | 10 | SpinHydro | 6548473 | -71 | 8hyLBUGgsPvEzoDyJpzu
2025-02-11 17:35:37 | 23.10 | 69.38 | 21.00 | C | 4.10 | 10 | SpinHydro | 6548473 | -70 | 8hyLBUGgsPvEzoDyJpzu
2025-02-11 17:35:48 | 23.10 | 69.38 | 20.94 | C | 4.10 | 10 | SpinHydro | 6548473 | -71 | 8hyLBUGgsPvEzoDyJpzu
2025-02-11 17:35:59 | 23.09 | 69.37 | 20.94 | C | 4.10 | 10 | SpinHydro | 6548473 | -72 | 8hyLBUGgsPvEzoDyJpzu
2025-02-11 17:36:10 | 23.09 | 69.37 | 20.94 | C | 4.10 | 10 | SpinHydro | 6548473 | -74 | 8hyLBUGgsPvEzoDyJpzu
2025-02-11 17:36:21 | 23.10 | 69.38 | 20.88 | C | 4.10 | 10 | SpinHydro | 6548473 | -68 | 8hyLBUGgsPvEzoDyJpzu
2025-02-11 17:36:32 | 23.10 | 69.39 | 20.88 | C | 4.10 | 10 | SpinHydro | 6548473 | -68 | 8hyLBUGgsPvEzoDyJpzu
2025-02-11 17:36:46 | 23.10 | 69.38 | 20.88 | C | 4.10 | 10 | SpinHydro | 6548473 | -71 | 8hyLBUGgsPvEzoDyJpzu
2025-02-11 17:36:57 | 23.11 | 69.40 | 20.88 | C | 4.10 | 10 | SpinHydro | 6548473 | -74 | 8hyLBUGgsPvEzoDyJpzu
2025-02-11 17:37:08 | 23.09 | 69.37 | 20.88 | C | 4.10 | 10 | SpinHydro | 6548473 | -70 | 8hyLBUGgsPvEzoDyJpzu
2025-02-11 17:37:19 | 23.10 | 69.38 | 20.88 | C | 4.10 | 10 | SpinHydro | 6548473 | -75 | 8hyLBUGgsPvEzoDyJpzu
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

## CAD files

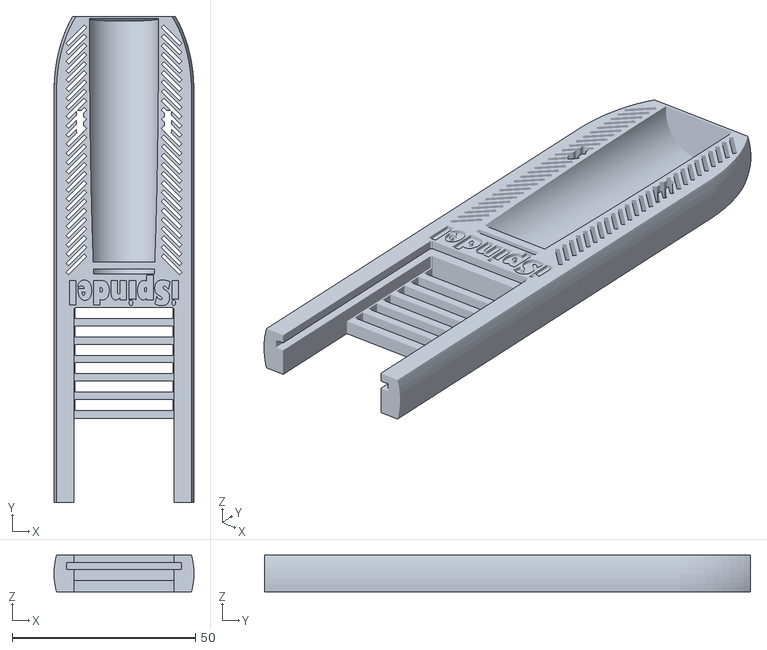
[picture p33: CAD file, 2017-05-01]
drawer/drawer-combo-short-spring.stl
38.2 x 132.7 x 10.0

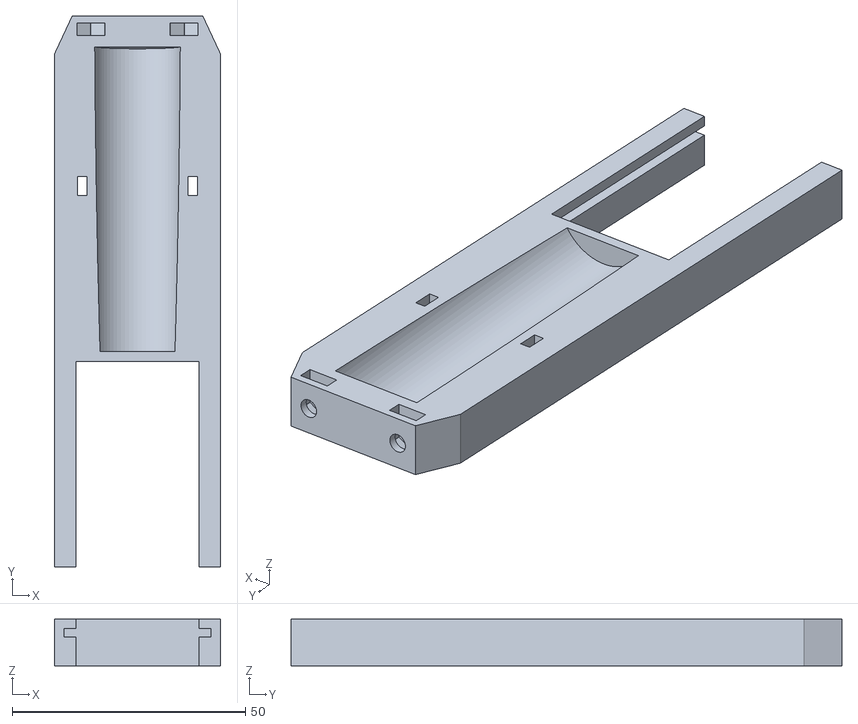
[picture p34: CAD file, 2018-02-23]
drawer/mwx-Edition/iSpindelBackbone2.stl
35.6 x 118.0 x 10.0

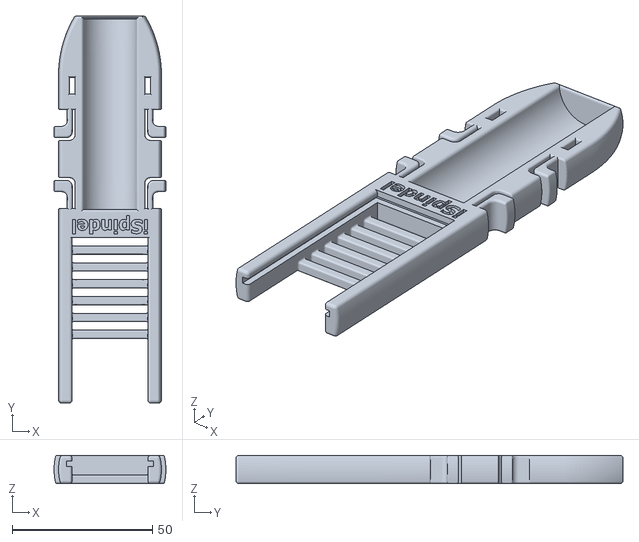
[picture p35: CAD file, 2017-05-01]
drawer/iSpindel mechatronics.stl
39.9 x 138.0 x 10.0

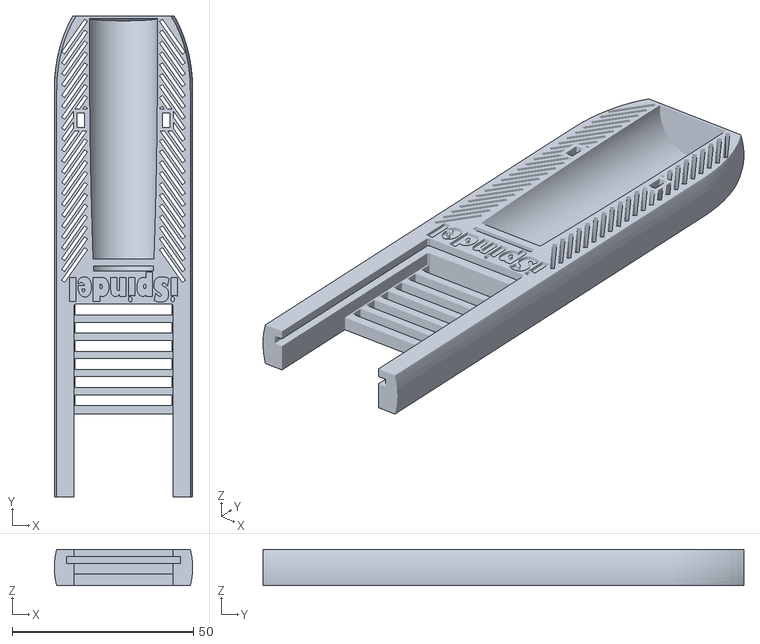
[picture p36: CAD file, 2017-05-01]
drawer/drawer-combo-short-spring2.stl
38.2 x 132.7 x 10.0

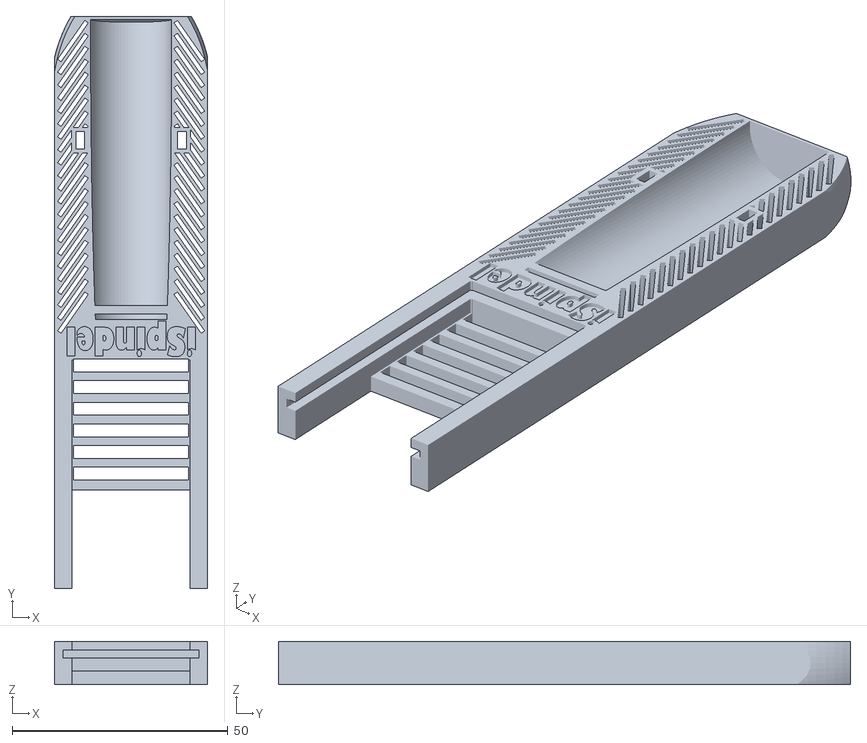
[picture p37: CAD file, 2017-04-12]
drawer/drawer-36x133-thing2231986.stl
35.5 x 132.7 x 10.0

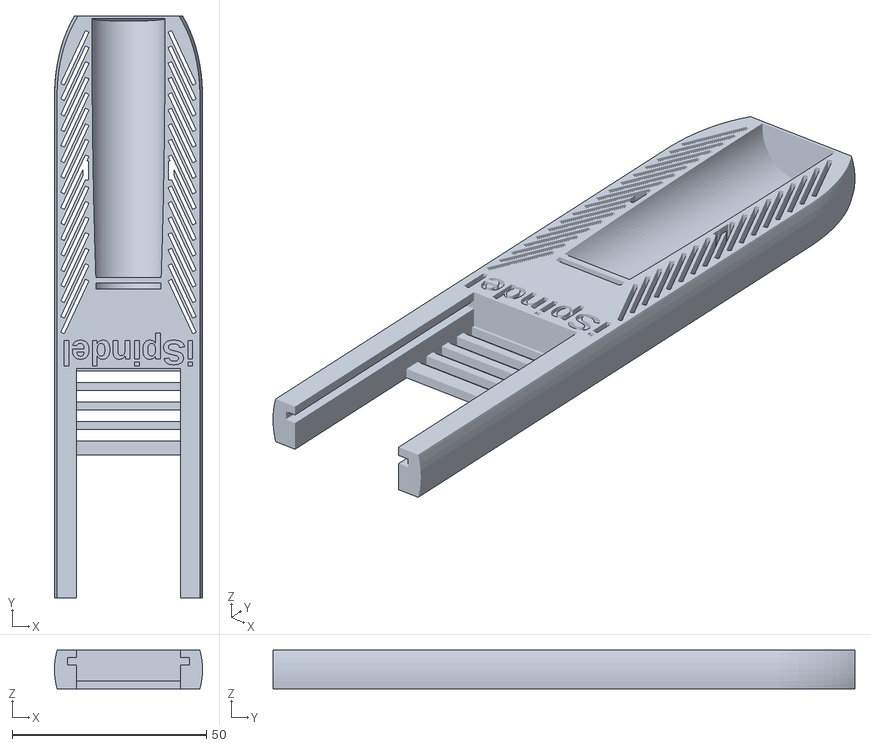
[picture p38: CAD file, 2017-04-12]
drawer/drawer-38x150-Geocaching.stl
38.1 x 149.7 x 10.0

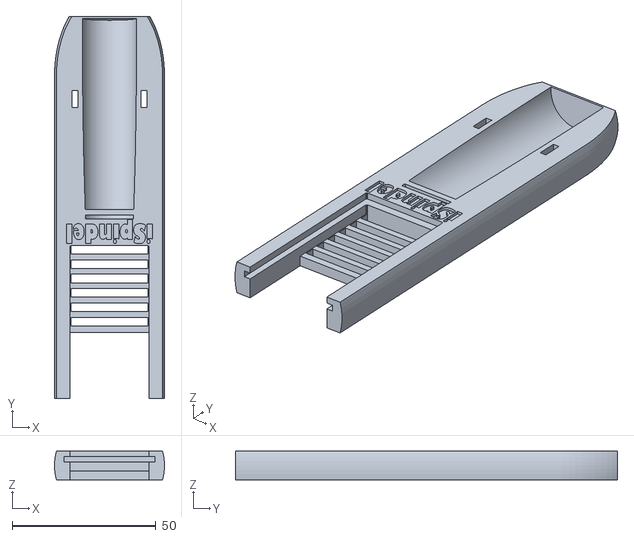
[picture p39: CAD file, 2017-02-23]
drawer/drawer-38x133.stl
38.2 x 132.7 x 10.0

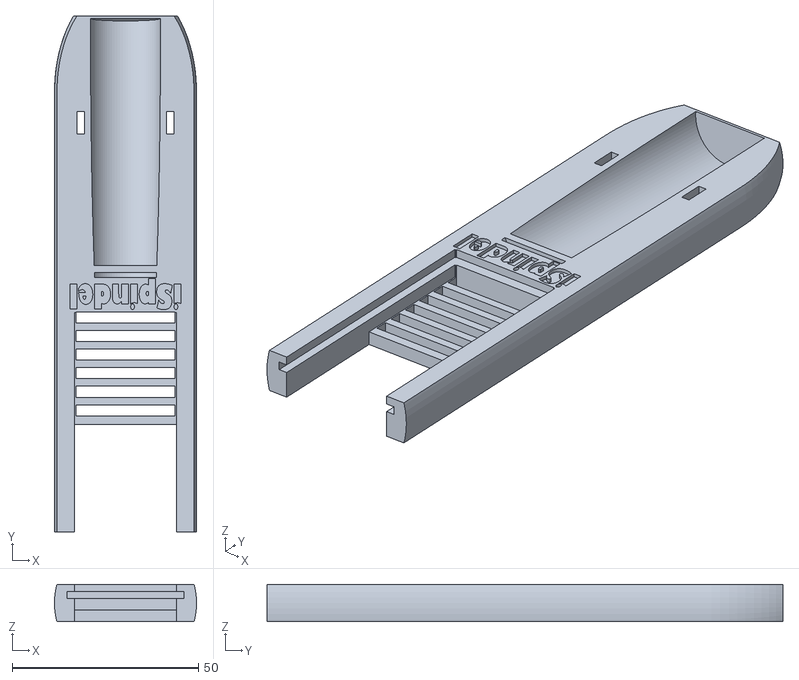
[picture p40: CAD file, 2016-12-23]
drawer/drawer-38x139.stl
38.2 x 138.7 x 10.0

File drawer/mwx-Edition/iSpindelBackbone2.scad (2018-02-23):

$fn=128;

l=118;    // total length
pl=44;    // boasrd length

co=15;    // cut offset

nw=6;     // nut width
nd=2.7;   // nut slot wifth
nso=-1.5; // nut slot offset

h=3.5;    // mounting hole diameter
ho=10;    // mounting hole offset

difference() {
  union() {

    difference() {
      union() {
        difference() {
          translate([-17.78,0,-5]) cube([4.6,l,10]);
          translate([-15.75,-1,1.15]) cube([2.65,47,1.9]);
        }
        difference() {
          translate([17.78-4.6,0,-5]) cube([4.6,l,10]);
          translate([15.75-2.65,-1,1.15]) cube([2.65,47,1.9]);
        }
        translate([-17.78,pl,-5]) cube([17.78*2,l-pl,10]);
      }


      translate([14,l,0]) 
        rotate([0,0,25]) 
          translate([0,-20,-10]) cube([40,40,20]);
      
      translate([-14,l,0]) 
        rotate([0,0,-25]) 
          translate([-40,-20,-10]) cube([40,40,20]);

      rotate([-3,0,0])
        translate([0,65+pl+2,12]) 
          rotate([90,0,0]) 
            cylinder(65.2,18.5/2,18.5/2);

      translate([-12.8,pl+3+(65.2/2),-6]) cube([2,4,12]);
      translate([12.8-2,pl+3+(65.2/2),-6]) cube([2,4,12]);

      translate([ho,l+0.01,0]) rotate([90,0,0]) cylinder(8,h/2,h/2);
      translate([-ho,l+0.01,0]) rotate([90,0,0]) cylinder(8,h/2,h/2);

      translate([-ho,l+nso,0]) rotate([90,30,0]) nut(nw,nd);
      translate([-nw/2-ho,l-nd+nso,0]) cube([nw,nd,10]);

      translate([ho,l+nso,0]) rotate([90,30,0]) nut(nw,nd);
      translate([-nw/2+ho,l-nd+nso,0]) cube([nw,nd,10]);

    }
  }
}

module nut(d,h) { 
  translate([0,0,h/2]) {
    cube(size = [d/1.75,d,h], center = true);
    rotate([0,0,60]) cube(size = [d/1.75,d,h], center = true);
    rotate([0,0,-60]) cube(size = [d/1.75,d,h], center = true);
  }
}

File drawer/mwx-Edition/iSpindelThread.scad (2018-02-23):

$fn=64;

bl=28;   // base length
bh=4;    // base height
  
bw=10;   // outer base width

cl=8;    // cutout length
ch=2;    // cutout height

tl=22;   // thread 

cr=3;    // corner radius

sw=5.2;  // sensor hole width

h=3.5;   // mounting hole diameter
ho=10;   // mounting hole offset

hh=6.5;  // screw head diameter
hd=2.5;  // screw head depth

difference() {
  union() {
    translate([0,0,bh]) thread("M12",tl);
    translate([-bl/2,-bw/2,0]) cube([bl,bw,bh]); 
  }

  translate([0,0,-1]) cylinder(tl+bh+2,sw/2,sw/2);

  translate([-ho,0,-1]) cylinder(bh+2,h/2,h/2);
  translate([ho,0,-1]) cylinder(bh+2,h/2,h/2);

  translate([-ho,0,bh-hd]) cylinder(bh+2,hh/2,hh/2);
  translate([ho,0,bh-hd]) cylinder(bh+2,hh/2,hh/2);

  translate([-(cl/2),-7,-0.01]) cube([cl,14,ch]);
}

module thread(name="M12",length=20){
  df=_get_screw_fam(name);
  lead=df[3];
  orad=df[1]/2;
  _thread(orad,length,lead);
}

module _thread(orad,tl,p) { 
  r = [orad-0/18*p, orad-1/18*p, orad-2/18*p, orad-3/18*p, orad-4/18*p, orad-5/18*p,
    orad-6/18*p, orad-7/18*p, orad-8/18*p, orad-9/18*p, orad-10/18*p, orad-11/18*p,
    orad-12/18*p, orad-13/18*p, orad-14/18*p, orad-15/18*p, orad-16/18*p, orad-17/18*p,
    orad-p];

  translate([0,0,tl/2])
  linear_extrude(height = tl, convexity = 10, twist = -360.0*tl/p, center = true)
    polygon([[ r[ 0]*cos(  0), r[ 0]*sin(  0)], [r[ 1]*cos( 10), r[ 1]*sin( 10)],
      [ r[ 2]*cos( 20), r[ 2]*sin( 20)], [r[ 3]*cos( 30), r[ 3]*sin( 30)],
      [ r[ 4]*cos( 40), r[ 4]*sin( 40)], [r[ 5]*cos( 50), r[ 5]*sin( 50)],
      [ r[ 6]*cos( 60), r[ 6]*sin( 60)], [r[ 7]*cos( 70), r[ 7]*sin( 70)],
      [ r[ 8]*cos( 80), r[ 8]*sin( 80)], [r[ 9]*cos( 90), r[ 9]*sin( 90)],
      [ r[10]*cos(100), r[10]*sin(100)], [r[11]*cos(110), r[11]*sin(110)],
      [ r[12]*cos(120), r[12]*sin(120)], [r[13]*cos(130), r[13]*sin(130)],
      [ r[14]*cos(140), r[14]*sin(140)], [r[15]*cos(150), r[15]*sin(150)],
      [ r[16]*cos(160), r[16]*sin(160)], [r[17]*cos(170), r[17]*sin(170)],
      [ r[18]*cos(180), r[18]*sin(180)], [r[17]*cos(190), r[17]*sin(190)],
      [ r[16]*cos(200), r[16]*sin(200)], [r[15]*cos(210), r[15]*sin(210)],
      [ r[14]*cos(220), r[14]*sin(220)], [r[13]*cos(230), r[13]*sin(230)],
      [ r[12]*cos(240), r[12]*sin(240)], [r[11]*cos(250), r[11]*sin(250)],
      [ r[10]*cos(260), r[10]*sin(260)], [r[ 9]*cos(270), r[ 9]*sin(270)],
      [ r[ 8]*cos(280), r[ 8]*sin(280)], [r[ 7]*cos(290), r[ 7]*sin(290)],
      [ r[ 6]*cos(300), r[ 6]*sin(300)], [r[ 5]*cos(310), r[ 5]*sin(310)],
      [ r[ 4]*cos(320), r[ 4]*sin(320)], [r[ 3]*cos(330), r[ 3]*sin(330)],
      [ r[ 2]*cos(340), r[ 2]*sin(340)], [r[ 1]*cos(350), r[ 1]*sin(350)]
      ]);
}

function _get_screw_fam(n) = data_screw_fam[search([n], data_screw_fam)[0]];

data_screw_fam = [
  // desc,th_outerdia,th_innerdia,lead,key,key_depth,head_height,head_dia,nut_key,nut_height
  ["M1.6", 1.6, "xx", 0.35, 1.5,  0.7, 1.6,   3, 3.2,  1.3],
  ["M2",     2, "xx",  0.4, 1.5,    1,   2, 3.8,   4,  1.6],
  ["M2.5", 2.5, "xx", 0.45,   2,  1.1, 2.5, 4.5,   5,    2],
  ["M3",     3, "xx",  0.5, 2.5,  1.3,   3, 5.5, 5.5,  2.4],
  ["M4",     4, "xx",  0.7,   3,    2,   4,   7,   7,  3.2],
  ["M5",     5, "xx",  0.8,   4,  2.5,   5, 8.5,   8,  4.7],
  ["M6",     6, "xx",    1,   5,    3,   6,  10,  10,  5.2],
  ["M8",     8, "xx", 1.25,   6,    4,   8,  13,  13,  6.8],
  ["M10",   10, "xx",  1.5,   8,    5,  10,  16,  16,  8.4],
  ["M12",   12, "xx", 1.75,  10,    6,  12,  18,  18, 10.8],
  ["M16",   16, "xx",    2,  14,    8,  16,  24,  24, 14.8],
  ["M20",   20, "xx",  2.5,  17,   10,  20,  30,  30,   18],
];

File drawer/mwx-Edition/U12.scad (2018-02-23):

$fn=128;

difference() {
	cylinder(2.4,11.5,11.5);
	translate([0,0,-1]) cylinder(5,6.25,6.25);
}

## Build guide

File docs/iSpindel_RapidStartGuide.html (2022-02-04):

iSpindel Rapid Start - Contents

1. Overview

1. Preface

2. Cherry Philip Board Layout

2. Batteries

3. Charging

4. First Contact - WiFi connection

5. BrewFather Connection

6. Gravity Calculation Polynomial Generation (Rapid Version)

The longer ‘iSpindel_QuickStartGuide.pptx’ guide can be found here:

https://github.com/universam1/iSpindel/tree/master/docs

(https://github.com/universam1/iSpindel/tree/master/docs)

1 Overview - Preface

The iSpindel uses the same theory as the Tilt. The angle of

an unbalanced floating body can be plotted against the

gravity and hence gravity derived from that angle.

First up the documentation is pretty good and it’s here:

http://www.ispindel.de/docs/README_en.html

(http://www.ispindel.de/docs/README_en.html)

1 Overview – Cherry Philip v4.0 Board

Layout

1. Battery

2. Resistors and

Diode

3. Lipo Charger

4. Reset Contacts

5. Temp Sensor

6. Gyro Board

7. Wemos Board

8. Charge Port

9. On/Off switch

10.Programming Port

1

2

3

5

6

7

8

4

9

4

10

2 Batteries

There are a lot of fake batteries out there so stay away from eBay and

use Amazon with great care

They can be dangerous but usually are just very low capacity

Batteries are any of the 18650 types and should weigh over 42g.

If the seller doesn’t advertise battery weight don’t buy from them

If the capacity is much over 3000 mAh it’s fake, like the one opposite

I’d suggest only buying from sites with a real address and phone number

who only really sell batteries

These guys seem legitimate:

https://18650.uk/shop/button-top-batteries/

https://www.buyabattery.co.uk/

https://www.batterystation.co.uk/

• The battery

above is fake

no one makes

a 9800 mAh

battery

(https://18650.uk/shop/button-top-batteries/) (https://www.buyabattery.co.uk/)

(https://www.batterystation.co.uk/)

3 Charging

There is no need to remove the PCB from the tube to charge the

iSpindel, simply plug a USB cable into the charging port noted on slide 3

(Label 8)

Red LED means charging

Blue/Green LED means charged

If the battery is not making contact you will notice that one of the LEDs

on the charge board (Slide 3, Label 3) lights and the other dimly

flickers.

4 First Contact – WiFi connection

Make sure the battery has a good charge in it, see Slide 5 for

charging

Turn on the iSpindel and the blue LED (near the top) should blink

repeatedly. (If the LED does not blink short the reset contacts

twice, see Slide 3, Label 4).

On a mobile device go to your WiFi and join the iSpindel network

It should prompt you to Sign-In, when you do it will take you to

its portal

Left long enough this portal will time out (not while you are

connected though) to save battery. The device will go to sleep,

wake up to send a reading and go back to sleep. To make it

serve its portal again you need to short the reset contacts twice.

5 BrewFather Connection

Your iSpindel is setup to report in SG. For brewfather, you must end the name

of your device with “[SG]”. I.e. “MyiSpindel[SG]”

See the Brewfather instructions they are pretty good:

https://docs.brewfather.app/integrations/ispindel

(https://docs.brewfather.app/integrations/ispindel)

6 Gravity Calculation Polynomial Generation

(Rapid Version)

Pop your iSpindel in room temperature tap water

Connect to the portal to read the iSpindel tilt reading

The following spreadsheet can be used to estimate the

polynomial needed based on readings from other Cherry Philip

based iSpindels:

https://drive.google.com/file/d/1HSDzV-Ri2Rl4ieSaZXOEopSM4OtsoCW1/view?usp=sharing

Follow the instructions to generate the polynomial and copy

into the Polynomail box in the iSpindel setup page.

iSpindelRapidPoly

Estimator

(https://drive.google.com/file/d/1HSDzV-Ri2Rl4ieSaZXOEopSM4OtsoCW1/view?usp=sharing)

Enjoy playing with the iSpindel project!

Thanks go to:

The project creator: https://github.com/universam1

The PCB Designer: https://github.com/cherryphilip74

(https://github.com/universam1) (https://github.com/cherryphilip74)

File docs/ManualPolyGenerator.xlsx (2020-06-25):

Angle | SG
18 | 0.977643497 |  |  |  | Poly for iSpindel | (1.0000E-6*(tilt^3))+(-1.3137E-4*(tilt^2))+(6.9680E-3*tilt)+(8.8895E-1)
21 | 0.986605712
24 | 0.994337213
27 | 1.001 | 1 | 2 | 3 | 4
30 | 1.006756073 | 1e-06 | -0.000131373 | 0.006967952 | 0.888953213
33 | 1.011767432 | 1.0000E-6 | -1.3137E-4 | 6.9680E-3 | 8.8895E-1
36 | 1.016196077
39 | 1.020204008
42 | 1.023953225
45 | 1.027605728
48 | 1.031323517
51 | 1.035268592
54 | 1.039602953
57 | 1.0444886
60 | 1.050087533
63 | 1.056561752
66 | 1.064073257
69 | 1.072784048

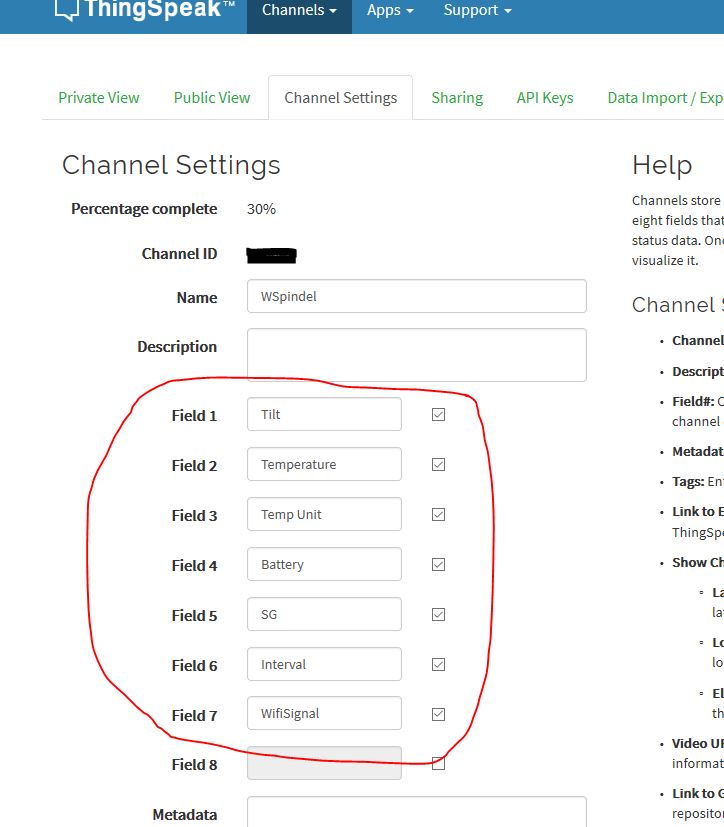
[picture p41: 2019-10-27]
pics/ThingSpeakSetup2.JPG

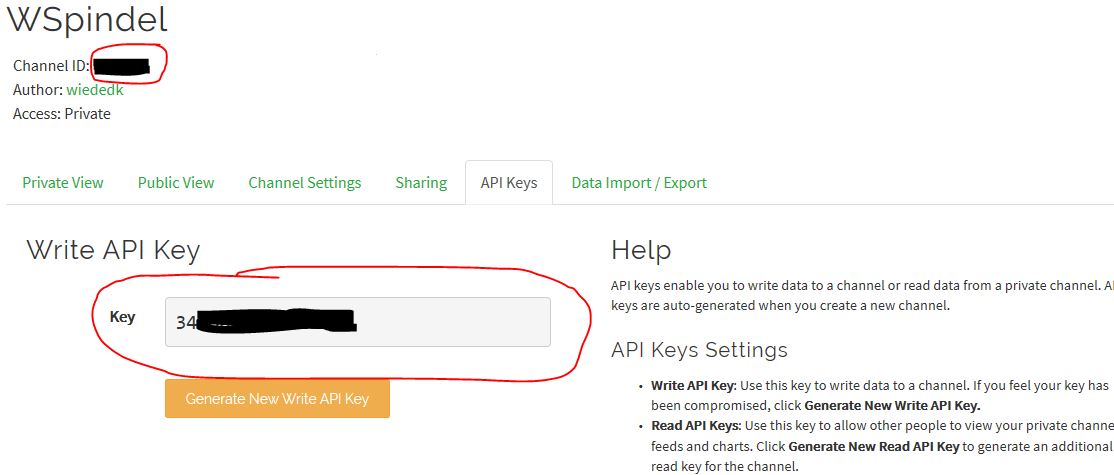
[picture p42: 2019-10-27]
pics/ThingSpeakSetup1.JPG

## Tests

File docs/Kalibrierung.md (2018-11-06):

# Kalibrierung

>Zur Umrechnung von Winkel ° in °Plato, SG, %mas o.Ä. ist es initial nötig eine Referenzkurve zu kalibrieren. Die gewonnenen Referenzen können dann vereinfacht über eine Excel Tabelle in eine Funktion überführt werden, die zur Darstellung hinterlegt wird. Da jede selbstgebaute Spindel andere Messwerte ergeben wird, muss man diesen Prozess einmalig durchführen.

>Stelle sicher dass die iSpindel im normalen Wasser ca. 25° Neigung von der Vertikalen aufweist. Gegebenenfalls noch weiter austarieren. Meistens sind ca. 20g an zusätzlichem Gewicht nötig.

***

# Inhalt

- [Kalibrierung](#kalibrierung)
- [Inhalt](#inhalt)
  - [Variante A (vereinfacht)](#variante-a-vereinfacht)
  - [Variante B Schnellvergärung (genauer)](#variante-b-schnellverg%C3%A4rung-genauer)
  - [Variante C Referenzen ziehen (empfohlen)](#variante-c-referenzen-ziehen-empfohlen)
- [Formel](#formel)
- [Speichern](#speichern)
  - [in iSpindel hinterlegen](#in-ispindel-hinterlegen)
  - [Alternativ: in Ubidots nach-berechnen](#alternativ-in-ubidots-nach-berechnen)

***

## Variante A (vereinfacht)

> Zum Ablessen des Neigungswinkels empfiehlt es sich, die iSpindel mit Ubidots zu verbinden und einen sehr kurzen Intervall (20 Sekunden) zu setzen. Damit kann die Neigung über die Webseite verfolgt werden.  
>  
>  Alternativ: Im Konfigurationsmodus kann die ```Info``` Seite aufgerufen werden und dort den Winkel abgelesen werden.

1. iSpindel in Reinwasser 0 °Plato legen, ***Winkel notieren (sollte ca. 25° Neigung aus der Vertikalen sein)***
2. Zuckerwasser mit ca. 20 °Plato herstellen, oder höchsten Wert den man voraussichtlich erreichen wird. ***Plato messen und Winkel notieren***  
*Beispiel 400ml Wasser + 100g Kristallzucker auflösen*
1. Wasser weiter verdünnen auf ca. 15 °Plato, ***Plato messen und Winkel notieren***   
*Beispiel +166ml Wasser hinzufügen*
1. Wasser weiter verdünnen auf ca. 10 °Plato, ***Plato messen und Winkel notieren***   
*Beispiel +333ml Wasser hinzufügen*
1. Wasser weiter verdünnen auf ca. 7,5 °Plato, ***Plato messen und Winkel notieren***   
*Beispiel +333ml Wasser hinzufügen*
1. Wasser weiter verdünnen auf ca. 5 °Plato, ***Plato messen und Winkel notieren***   
*Beispiel +666ml Wasser hinzufügen*
1. Wasser weiter verdünnen auf ca. 2,5 °Plato, ***Plato messen und Winkel notieren***   
*Beispiel +2000ml Wasser hinzufügen*

**gemessene Werte werden in das [Excel Sheet](#formel) eingetragen** 

***

## Variante B Schnellvergärung (genauer)

**Diese Variante ist genauer, da der CO2 Auftriebsfehler mit ein - kalibriert wird**

> Zum Ablessen des Neigungswinkels empfiehlt es sich, die iSpindel mit Ubidots zu verbinden und einen sehr kurzen Intervall (20 Sekunden) zu setzen. Damit kann die Neigung über die Webseite verfolgt werden.  

1. iSpindel in Reinwasser 0 °Plato legen, ***Winkel notieren (sollte ca. 25° Neigung aus der Vertikalen sein)***
1. Zuckerwasser mit ca. 20 °Plato herstellen, oder höchsten Wert den man voraussichtlich erreichen wird.  
*Beispiel 800ml Wasser + 200g Kristallzucker auflösen*
1. Hefe hinzufügen und Spindel einlegen. ***Plato messen und Winkel notieren*** 
1. bis x. :  Nun nimmt man regelmässig Plato Messwerte und den jeweilig korrelierenden Winkel und trägt dies in die Excel Tabelle ein. 
> Achtung: Sollte man hier einen Refraktometer verwenden darf man die Korrektur dessen nicht vergessen: [Refraktometerrechner](http://www.maischemalzundmehr.de/index.php?inhaltmitte=toolsrefraktorechner)

## Variante C Referenzen ziehen (empfohlen)

> Die einfachste und vermeintlich genaueste Variante ist sie in eine Gärung zu bringen und einige Referenzen zu ziehen. Man notiert sich die Stammwürze und den entsprechenden Winkel den man zB. bei Ubidots zu diesem Zeitpunkt sieht. Im Verlauf der Gärung nimmt man weiter 3 oder mehr solcher Referenzen ( gespindelte Stammwürze / Winkel ) notiert diese bis zum Gärende. Damit erhält man praxisnahe Werte die übrigens den CO2 Einfluss beinhalten bzw. berücksichtigen.
Danach kann man mit dem errechnen der Formel fortfahren, und diesen fest in der iSpindel dann hinterlegen.

***

# Formel
Folgende Varianten existieren um das Polynome leicht zu errechnen:

- ## [Online Gravity Calibration tool](http://www.ispindel.de/tools/calibration/calibration.htm)

Die Messwerte werden in das Feld `Plato` oder `Brix` eingetragen mit dem korrespondierendem Neigungswinkel unter `Tilt`. Daraus errechnet sich dann ein Polynom 2. oder 3. Grades welches dann in der Firmware hinterlegt wird.

***

- ## Excel Tabelle

> Obige Meßwerte können nun anhand dieser Excel Tabelle in eine annähernde Formel überführt werden.  
Diese hinterlegt man in Ubidots um die Anzeige des °Plato zu erhalten.  
> Andere Darstellung wie EVG, %mas, SG, Alc. werden nach gleichem Prinzip über eine ```Derived``` Variable aus vorhandenen Werten errechnet

1. Die obigen Meßwerte in die Excel Tabelle eintragen  
  [Download Excel Tabelle](Kalibrierung.xlsm)
1. ```Formel update``` Macro durch den Button starten, stellt die Trendlinie als Formal dar  
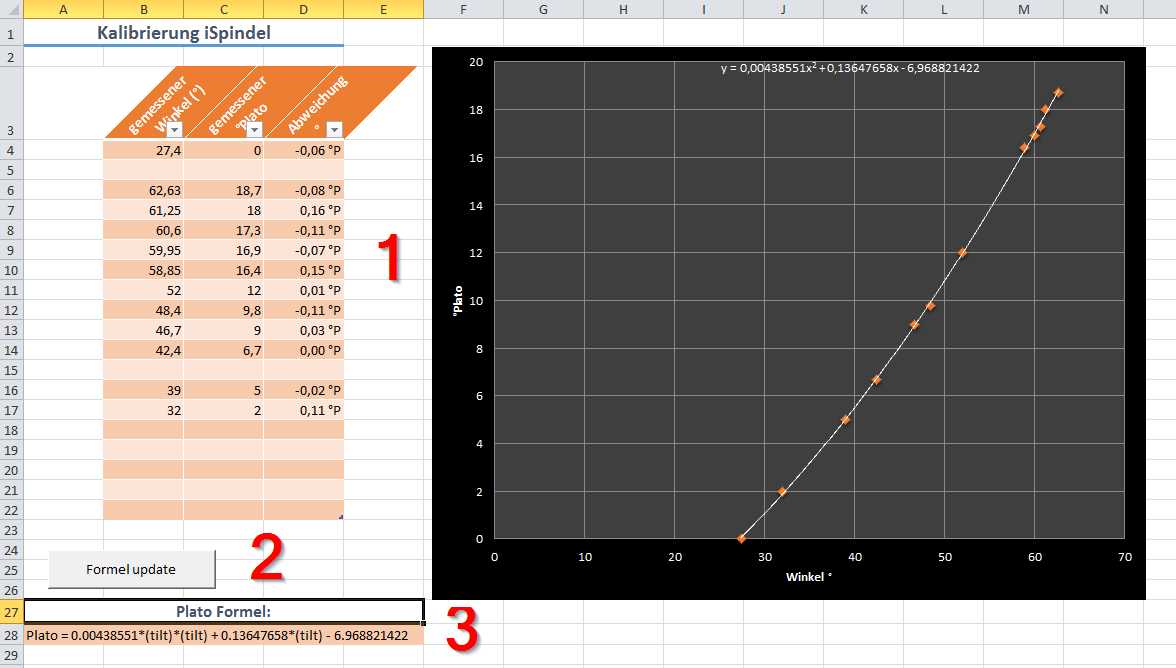
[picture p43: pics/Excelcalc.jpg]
Formel update


# Speichern

## in iSpindel hinterlegen

> Das Polynome kann nun in der iSpindel gespeichert werden, welcher in Laufzeit evaluiert und berechnet wird. Damit liefert die iSpindel nun die Dichte direkt als Datensatz.

Plato

## Alternativ: in Ubidots nach-berechnen

1. Ubidots eine ```Derived``` Variable erstellen, d.h. eine berechnete die auf anderen Daten aufbaut.  
1. Bei Ubidots auf Sources gehen
1. Source ISpindel wählen
1. (+) Add variable wählen
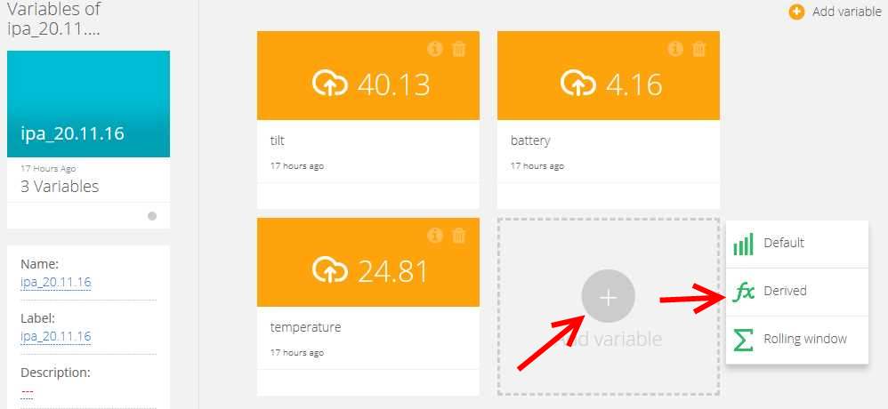
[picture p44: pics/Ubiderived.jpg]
1. Derived wählen 
1. Dort kann dann die Excel Formel eingetragen werden.  
```tilt``` ersetzt man durch ```instert Variable``` und wählt dort ```tilt``` aus 
![Plato](/pics/Ubiplato.jpg)
1. Im ```Dashboard``` erstellt man dann einen neuen Graphen mit den Datenquelle ```Plato```

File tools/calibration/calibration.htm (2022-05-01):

iSpindel Calibration

Gravity Unit: Measurement: Reading: Temperature Corrected. Wort Temperature CAL@ Reading:°P @Wort Correction: Tilt: SG: Plato: °P Add Data

Save Load:

| Tilt | Plato SG | Degree 1 Value | Degree 1 Error | Degree 2 Value | Degree 2 Error | Degree 3 Value | Degree 3 Error
Degree 1:
Degree 2:
Degree 3:

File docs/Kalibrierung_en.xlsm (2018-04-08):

Calibration of the iSpindel |  |  |  | Plato Formel: | -0.050364959*tilt^2 + 6.868698667*tilt - 185.8498673
Measured Angle (°) | Measured SG | Measured °Plato | Deviation °
39.000 | 1.000 | -0.003 | -5.427
44.400 | 1.010 | 2.561 | -17.272
65.150 | 1.047 | 11.674 | -36.197
70.990 | 1.070 | 17.056 | -30.885

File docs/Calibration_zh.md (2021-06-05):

# 校准

> iSpindle 漂浮在麦汁当中的倾斜角度可以转换成柏拉图度（ºPlato）、比重值（SG）或者其他单位。为了能够做到这一点，应该在 iSpindle 的倾斜度与所选择单位之间建立起参照.。必须对参考值进行测量，并使用 Excel 表格制作图表以及生成公式。 Excel 会计算 iSpindle 的倾斜角度与柏拉图度、比重值或其他单位之间的关系。 由于每个自己做的 iSpindle 会有所不同，因此需要对单独每个 iSpindle 进行参考测量，但只需要进行一次。

***

# 目录
- [简易方法 (I)](#easy-method-(I))
- [改进方法利用快速发酵 (II)](#improved-method-using-fast-fermenting-(II))
- [ Excel 图表公式](#formula)

***

## 简易方法 (I)

建议您将 iSpindel 与 [Ubidots](https://ubidots.com/) 连接，方便读取测量的倾斜角度。此外，明智的做法是更改 iSpindel 中的设置，以便每 20 秒发送一次新的读数。在如此短的时间间隔内，可以在 [Ubidots](https://ubidots.com/) 网站上轻松地跟踪测量结果。

1. 将 iSpindel 放入干净的清水中 (柏拉图 0 度，比重值 1.000) 
> ***记下 iSpindel 的倾斜角度***

2. 制作达到最大预期密度的糖水溶液。如果你要酿造初始比重较高的烈性啤酒，你应该在这个高比重范围内的预期参考测量值。对于大多数酿酒师来说，比重在 1.085 左右或 柏拉图 20 度 左右的目标密度溶液就够了。   
> *糖溶液示例: 400 毫升 和 100 克糖*     
> ***测量比重值或者柏拉图度并和 iSpindel 倾斜角度一起记下来***

3. 用水稀释上述溶液，直到它达到 柏拉图 15 度 或者 比重 1.061       
>*示例：用 166 毫升水稀释第 2 点的溶液*     
>***测量比重值或者柏拉图度并和 iSpindel 倾斜角度一起记下来***        

4. 从上一点稀释溶液，直到达到约 柏拉图 10 度 或者 比重 1.040       
>*示例：用 333 毫升水稀释第 3 点的溶液*        
>***测量比重值或者柏拉图度并和 iSpindel 倾斜角度一起记下来***     

5. 从上一点稀释溶液，直到达到约 柏拉图 7.5 度 或者 比重 1.030
>*示例：用 333 毫升水稀释第 4 点的溶液*        
>***测量比重值或者柏拉图度并和 iSpindel 倾斜角度一起记下来***     

6. 从上一点稀释溶液，直到达到约 柏拉图 5 度 或者 比重 1.020
>*示例：用 666 毫升水稀释第 5 点的溶液*        
>***测量比重值或者柏拉图度并和 iSpindel 倾斜角度一起记下来***   

7. 从上一点稀释溶液，直到达到约 柏拉图 2.5 度 或者 比重 1.010     
>*示例：用 2000 毫升水稀释第 6 点的溶液*      
>***测量比重值或者柏拉图度并和 iSpindel 的倾斜角度一起记下来        
>在 Excel 表格中输入测量点（见下文），此 Excel 表格将计算出参考公式***

***
 
## 改进方法利用快速发酵 (II)

这种方法更为精确，因为它会考虑到发酵过程中产生的二氧化碳对 iSpindel 造成的影响。

建议您将 iSpindel 与 [Ubidots](https://ubidots.com/) 连接，方便读取测量的倾斜角度。此外，明智的做法是更改 iSpindel 中的设置，以便每 20 秒发送一次新的读数。在如此短的时间间隔内，可以在 [Ubidots](https://ubidots.com/) 网站上轻松地跟踪测量结果。

1. 将 iSpindel 放入干净的（自来）水中 (柏拉图 0 度，比重值 1.000)       
>***记下 iSpindel 测量的倾斜角度***

2. 制作达到最大预期密度的糖水溶液。如果你要酿造初始比重较高的烈性啤酒，你应该在这个高比重范围内的预期参考测量值。对于大多数酿酒师来说，比重在 1.085 左右或 柏拉图 20 度 左右的目标密度溶液就够了。  
>*糖溶液示例: 800 毫升 水 + 200 克 冰糖*

3. 加入酵母到糖溶液，让 iSpindel 在溶液中漂浮         
>***测量比重值或者柏拉图度并和 iSpindel 倾斜角度一起记下来***

4. 每隔一段时间测量液体的比重值以及 iSpindle 相应的倾斜角度，直至发酵结束。      
>***在 Excel 表格中输入记录下来的测量值，得出校准曲线公式***     
>
>***注意：如果使用折光仪来测量白利糖度，则必须重新计算得到的测量值，加上酒精度数以进行校正*** 

***

# 公式

- ## [在线比重校准工具](http://www.ispindel.de/tools/calibration/calibration.htm)

可以在不同的选项 比重/柏拉图或者白利糖度 中输入相对应的测量值以及倾斜角度。它将计算出第二回和第三回的角度公式，获取倾斜角度的读数就可以预测出比重值或柏拉图度。必须在固件中输入角度公式才能得到比重值或柏拉图度的数值。

***

- ## Excel 表格

获取的测量值可以输入到Excel表格中,该表格将计算出一个公式来预测给定倾斜值的比重值或柏拉图度。这个公式必须输进固件配置中，以便能够获取比重值或柏拉图度的读数。
其它读数例如表观衰减度或者酒精百分比，可以通过使用 [Ubidots](https://ubidots.com/) 中的 'Derived Variable'（衍生变量)以类似的方式获得。

1. 首先在 Excel 中输入测量值：
[下载 Excel 表格](https://github.com/universam1/iSpindel/blob/master/docs/Kalibrierung_zh.xlsm)
2. 通过点击按钮启动宏 **公式更新** ，接着公式将会被更新。 
Excelcalc
3. 在 [Ubidots](https://ubidots.com/) 账号中必须添加 **Derived Variable** （衍生变量）。这是一个以其他变量为来源进行计算的变量，这可以通过执行接下来的步骤来完成。
4. 在 [Ubidots](https://ubidots.com/) 中转到 **Source** 这一项
5. 选择 iSpindel 为来源
6. 点击 **(+) 添加变量** 
7. 选择 **Derived** 这一项      
Derived
1. 现在你可以将 Excel 中的公式填写进去。公式中 ***(tilt)*** 的部分必须被替换掉。为此请单击 ***insert variable*** 然后选取 **tilt**，给新创建的变量一个有意义的名字，比如比重或柏拉图。    
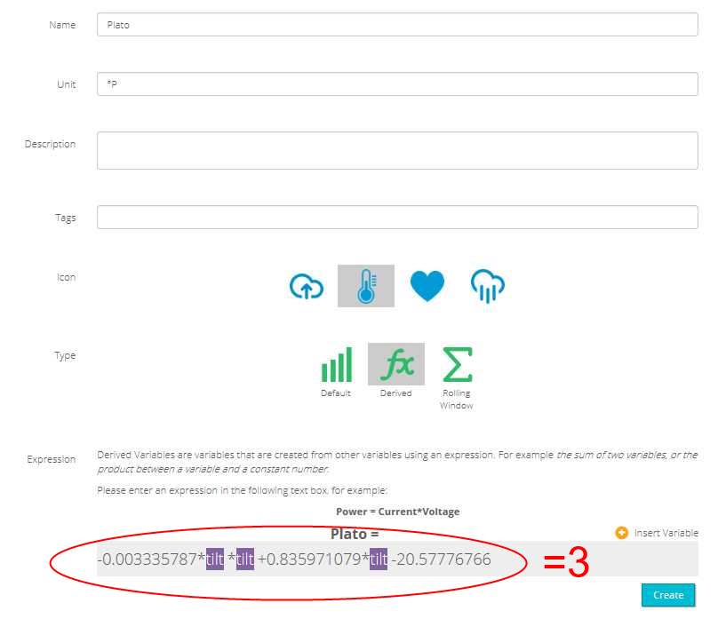
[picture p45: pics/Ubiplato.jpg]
Ubiplato

9. 在 **Dashboard** 你可以创建测量数据的图形演示。

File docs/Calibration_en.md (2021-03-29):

# Calibration

>The tilt of the iSpindle floating in the wort can be converted into degrees Plato (ºPlato), density (SG) or other units. To be able to do so, a reference should be made between the degrees of tilt of the iSpindle and the chosen unit. Reference values will have to be measured and with the use of an Excel table a graph and formula is made. Excel will calculate the relation between the tilt of the iSpindle and Plato degrees, density or others. As each self built iSpindle will differ, the reference measurement is needed to be done for each individual iSpindle, but only once. 

***

# Content
- [Easy method (I)](#easy-method-(I))
- [Improved method using fast fermenting (II)](#improved-method-using-fast-fermenting-(II))
- [Formula Excel tabel](#formula)

***

## Easy method (I)

It's recommended you connect the iSpindel with [Ubidots](https://ubidots.com/) for easy reading of the measured tilts. Furthermore it is wise to change settings of the iSpindel so it sends new readings every 20 seconds. With such a short interval the measurements can be easily followed on the [Ubidots](https://ubidots.com/) website.

1. Put the iSpindel in clean water (0 degrees Plato, SG 1.000).   
> ***Write down the tilt of the iSpindel***

2. Make a solution of sugar in water with the highest anticipated density. If you are brewing strong beers with a high starting density, you should have reference measurements in this high range. For most brewers a solution with a density around 1.085 or around 20 degrees Plato will do.      
> *Example for sugar solution: 400 ml with 100 g sugar*     
> ***Measure the density or the degrees Plato and write it down with the tilt of the iSpindel***

3. Dilute the solution above with water until it reaches 15 degrees Plato or density 1.061       
>*Example for sugar solution: dilute the solution of point 2 with 166 ml of water*     
>***Measure the density or the degrees Plato and write it down with the tilt of the iSpindel***        

4. Dilute the solution from the point above till it reaches approximately 10 degrees Plato, SG 1.040 of 10 degrees Brix.       
>*Example: Dilute the solution from point 3 with 333 ml of water.*        
>***Measure the density or the degrees Plato and write it down with the tilt of the iSpindel***     

5. Dilute the solution from the point above till it reaches approximately 7.5 degrees Plato, SG 1.030 or 7.5 degrees Brix.
>*Example: Dilute the solution from point 4 with 333 ml of water.*        
>***Measure the density or the degrees Plato and write it down with the tilt of the iSpindel***     

6. Dilute the solution from the point above till it reaches approximately 5 degrees Plato, SG 1.020 or 5 degrees Brix
>*Example: Dilute the solution from point 5 with 666 ml of water*        
>***Measure the density or the degrees Plato and write it down with the tilt of the iSpindel***   

7. Dilute the solution from the point above till it reaches approximately 2.5 degrees Plato, SG 1.010 or 2.5 degrees Brix.     
>*Example: Dilute the solution from point 6 with 2000 ml of water.*      
>***Measure the density or the degrees Plato and write it down with the tilt of the iSpindel        
>Enter the measured points in the Excel sheet (see below). This Excel sheet will calculate the formula for the reference***

***
 
## Improved method using fast fermenting (II)

This method is more precise since it will take the affect of CO2 formed during fermenting into account.

It's recommended you connect the iSpindel with [Ubidots](https://ubidots.com/) for easy reading of the measured tilts. Furthermore it is wise to change settings of the iSpindel so it sends new readings every 20 seconds. With such a short interval the measurements can be easily followed on the [Ubidots](https://ubidots.com/) website.

1. Put the iSpindel in clean (tap) water (0 º Plato or SG 1.000)      
>***Write down the measured tilt of the iSpindel***

2. Make a solution of sugar in water with the highest anticipated density. If you are brewing strong beers with a high starting density you should have reference measurements in this high range. For most brewers a solution with a density around 1.085 or around 20 degrees Plato will do.     
>*Example: 800 ml of water + 200 g crystal sugar.*

3. Add yeast to the sugar solution and let the iSpindel float in the solution         
>***Measure the density or the degrees Plato and write it down with the tilt of the iSpindel***

4. Measure the density of the fluid and the corresponding tilt of the iSpindle at regular intervals till the end of fermentation has been reached.      
>***Enter the measured values in the Excel sheet. This sheet will show the formula of the calibration curve.***     
>
>****Caution: if you measure in Brix value with a refractometer you have to recalculate the measured value to correct for the alcohol reading*** 

***

# Formula

- ## [Online Gravity Calibration tool](http://www.ispindel.de/tools/calibration/calibration.htm)

The measured values can be entered in the field SG/Plato or BRIX plus the corresponding Tilt. It will calculate a formula of 2nd or 3rd degree that will predict the density or the degrees of Plato given an tilt value. This formula has to be entered in Firmware to be able to get readings in density or degrees Plato.

***

- ## Excel Sheet

The measured values can be entered in the Excel sheet. This sheet will calculate a formula that will predict the density or the degrees of Plato given an tilt value. This formula has to be entered in Firmware to be able to get readings in density or degrees Plato.
Other readings, such as apparent attenuation or alcohol % can be obtained in similar manners with the use of a 'Derived Variable' in [Ubidots](https://ubidots.com/).

1. First enter the measured values in Excel:    
[Download Excel table](https://github.com/universam1/iSpindel/blob/master/docs/Kalibrierung_en.xlsm)
2. Start the macro **Formule update** by clicking on the button. The formula will be updated.     
Excelcalc
3. In the account of [Ubidots](https://ubidots.com/) a **Derived Variable** has to be added. This is a variable that is calculated with other variables as source. This can be done by following the next steps.
4. In [Ubidots](https://ubidots.com/) go to **Source**
5. Choose iSpindel as source
6. Click on **(+) Add variable** 
7. Choose **Derived**      
Derived
8. Now you can fill in the formula from Excel. De parts in the formula shown as ***(tilt)*** has to be replaced. To do so click on ***insert variable*** and choose **tilt**. Give the newly created variable a name that does make sense, i.e. Density or Plato     
Ubiplato
9. Under **Dashboard** you can create graphical presentations of your data.

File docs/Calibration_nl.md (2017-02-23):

# Kalibreren

>Om de hellingshoek van de iSpindle van graden (º) in ºplato, SG of andere waarden om te rekenen is het nodig om eerst een referentiegrafiek te maken. De gevonden referentiewaarden worden daarbij eenvoudig door middel van een Excel tabel in een functie omgezet. Omdat iedere zelfgebouwde meter een andere waarde zal geven moet deze referentiemeting eenmalig voor iedere meter uitgevoerd worden. De referentiemeting kan in graden Plato of als SG met een hydrometer uitgevoerd worden.

***

# Inhoud
- [Vereenvoudigde methode (I)](#vereenvoudigde-methode-(I))
- [Precieze methode via snelvergisting (II)](#precieze-methode-via-snelvergisting-(II))
- [Formule Excel tabel](#formule)

***

## Vereenvoudigde methode (I)

Voor het aflezen van de hellingshoek wordt aanbevolen om de iSpindel via Ubidots te verbinden en de iSpindel in te stellen op een korte meetinterval (20 seconden). Daardoor kan de helling van de sensor eenvoudig via een webpagina gevolgd worden.

1. iSpindel in schoon water leggen (0ºPlato, SG 1.000).   
> ***Noteer de hellingshoek***

1. Suikerwater maken met de voor de toekomst verwachtte hoogste meetwaarde. Als je bijvoorbeeld erg sterke bieren brouwt (hoge begin SG) dan zal je ook in dit hogere bereik een referentiewaarde moeten hebben. Voor de meeste brouwers zal suikerwater met ca. 20ºPlato of SG 1.083 voldoen.      
> *Voorbeeld suikeroplossing: Oplossing van 400 ml water en 100 g kristalsuiker.*     
> ***Meet je gemaakte oplossing (in SG of ºPlato) en noteer deze waarde met de bijbehorende hellingshoek van de iSpindel***

1. De oplossing van punt 2 met water verdunnen tot circa 15ºPlato of SG 1.061.      
>*Voorbeeld: oplossing van punt 2  verdunnen met 166 ml water.*     
>***Meet de gemaakte oplossing (SG of ºPlato) en noteer deze waarde met de bijbehorende hellingshoek van de iSpindel.***        

1. De oplossing van punt 3 met water verdunnen tot circa 10 graden Plato, SG 1,040 of 10 graden Brix.       
>*Voorbeeld: Oplossing van punt 3 met 333 ml water.*        
>***Meet de gemaakte oplossing (SG of Plato) en noteer met de bijbehorende hoek van de iSpindel.***     

1. De oplossing van punt 4 met water verdunnen tot circa 7,5 graden Plato, SG 1,030 of 7,5 graden Brix.
>*Voorbeeld: Oplossing van punt 4 met 333 ml water.*        
>***Meet de gemaakte oplossing (SG of Plato) en noteer met de bijbehorende hoek van de iSpindel.***     

1. De oplossing van punt 5 met water verdunnen tot circa 5 graden Plato, SG 1,020 of 5 graden Brix
>*Voorbeeld: Oplossing van punt 5 met 666 ml water.*        
>***Meet de gemaakte oplossing (SG of Plato) en noteer met de bijbehorende hoek van de iSpindel.***     

1. De oplossing van punt 6 met water verdunnen tot circa 2,5 graden Plato, SG 1,010 of 2,5 graden Brix.     
>*Voorbeeld: Oplossing van punt 6  met 2000 ml water.*      
>***Meet de gemaakte oplossing (SG of Plato) en noteer met de bijbehorende hoek van de iSpindel.        
>De gemeten waarden invoeren in het Excel blad. Hieruit volgt direct de formule van de referentiegrafiek.***

***
 
## Precieze methode via snelvergisting (Variant B)

Deze variant is preciezer, omdat er rekening wordt gehouden met de invloed van CO2 gedurende de vergisting.

Voor het aflezen van de hellingshoek wordt aanbevolen om de iSpindel  via Ubidots te verbinden en de iSpindel in te stellen op een korte meetinval (20 seconden). Daardoor kan de helling van de sensor eenvoudig via een webpagina gevolgd worden.
1. Ispindel in schoon water leggen (0 º Plato of SG 1,000)      
>***Noteer de hoek***

1. Suikerwater maken met het hoogste voor de toekomst verwachtte bereik. Voor de meeste brouwers zal 20 ºplato of  SG 1,083 voldoende zijn.     
>*Voorbeeld: 800 ml water + 200 g kristalsuiker.*

1. Gist toevoegen en de iSpinel in de vloeistof leggen.         
>***Meet je gemaakte oplossing (SG of Plato) en noteer met de bijbehorende hoek van de iSpindel.***

1. Tot het onderste bereik van de meetrange is bereikt regelmatig de vloeistof meten en de bijbehorende hoek noteren.       
>***De gemeten waarden invoeren in het Excel blad. Hieruit volgt direct de formule van de referentiegrafiek.***     
>
>****Opletten: bij een meting in Brix moet wel de correctie meegenomen worden.**** 

***

## Formule

De meetwaarden kunnen aan de hand van de Excel tabel in een formule gezet worden die het verloop bij benadering kan berekenen. Deze formule wordt in Ubidots ingevoerd om de weergaven in graden Plato of SG te verkrijgen.
Andere weergaven, zoals bijvoorbeeld de SVG of alcohol % zijn op vergelijkbare manier via een **Derived variabele** te berekenen.

1. De hierboven verkregen meetwaarden invoeren in de Excel tabel.       
[Download Excel tabel](https://github.com/universam1/iSpindel/blob/master/docs/Kalibrierung.xlsm)
2. Macro **Formule update** starten door op de button te klikken. De formule wordt dan bijgewerkt.      
Excelcalc
3. In je account van Ubidots een **Derived Variabele** maken. Dat is een variabele die van andere gegevens afhankelijk is. Volg hiervoor de onderstaande stappen:
4. Ga in Ubidots naar Sources
5. Kies de iSpindel als source (bron).
6. (+) Add variable kiezen
7. Derived kiezen.      
Ubiderived
8. Hier kan de Excel formule ingevoerd worden. De onderdelen ***(tilt)*** die uit Excel komen moet je hier vervangen door op ***insert Variable*** te klikken en tilt te kiezen. Geef de variabele een logische naam (Bijvoorbeeld SG of Plato)     
Ubiplato
9. Op het Dashboard kan je dan een nieuwe grafiek maken met als data bron je zojuist gemaakte variabele SG of Plato.

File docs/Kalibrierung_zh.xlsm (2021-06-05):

iSpindel 校准 |  |  |  |  | 公式: | 0.009032287*tilt^2 - 0.486907804*tilt + 5.695521157
 | 角度 | 比重值 | 柏拉图度 | 标准偏差
Measured Angle (°) | Measured SG | Measured °Plato | Deviation °
39.000 | 1.000 | -0.003 | -0.447
44.400 | 1.010 | 2.561 | 0.678
65.150 | 1.047 | 11.674 | -0.638
70.990 | 1.070 | 17.056 | 0.407

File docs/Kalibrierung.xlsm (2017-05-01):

Kalibrierung iSpindel
 | gemessener Winkel (°) | gemessener °Plato | Abweichung °
 | 39 | 0 | -0.54 °P
 | 44.4 | 2.8 | 0.82 °P
 | 65.15 | 11.5 | -0.77 °P
 | 70.99 | 17 | 0.49 °P
Plato Formel:
0.008699786*tilt^2 - 0.457563239*tilt + 5.15023517

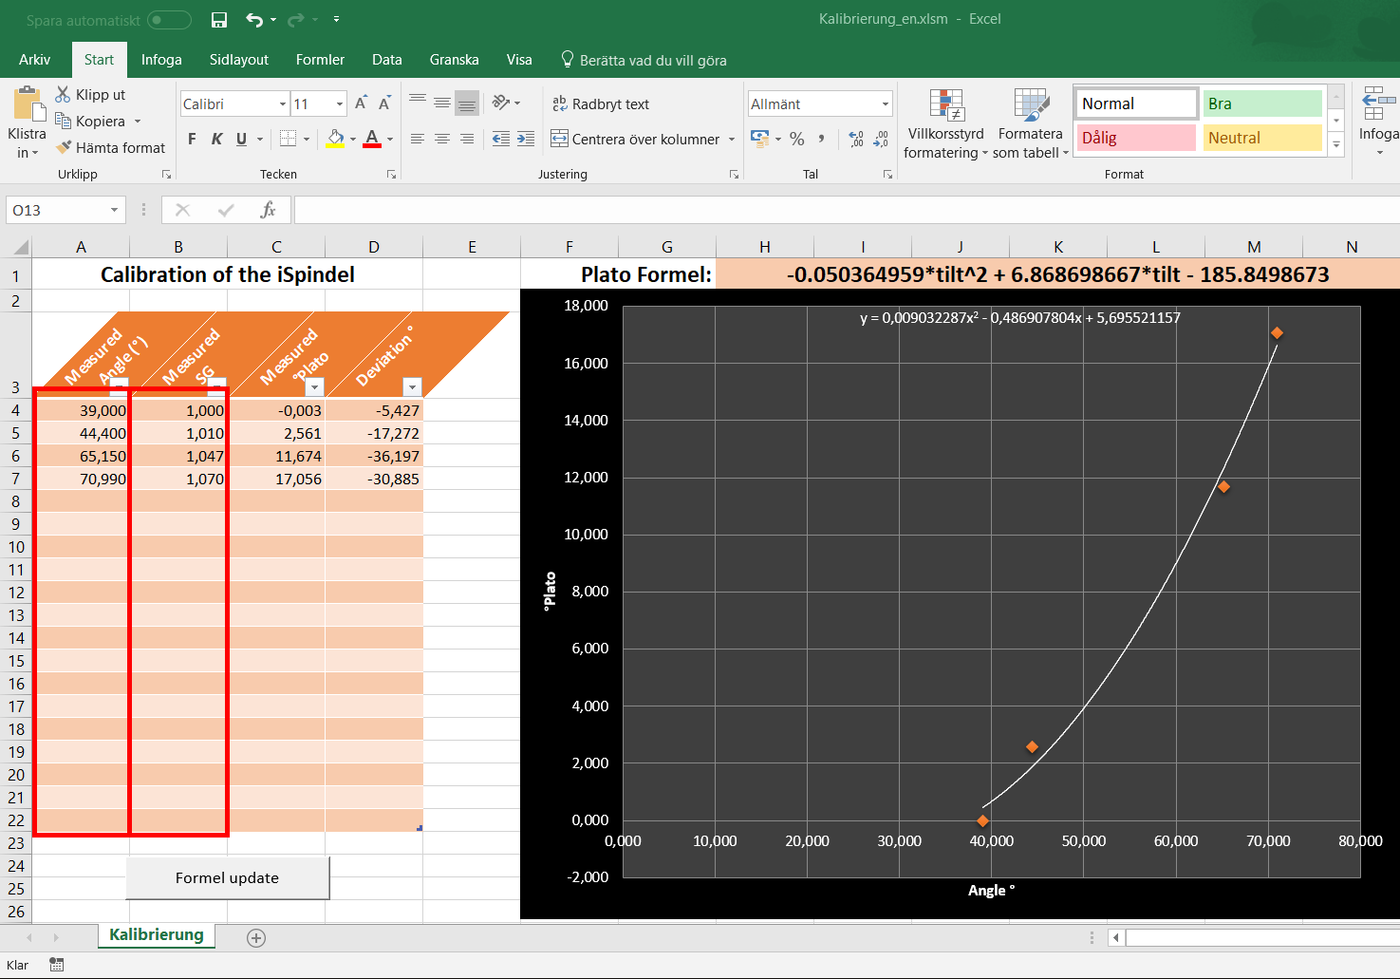
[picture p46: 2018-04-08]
pics/Calibration_Sheet_EN_marked_fields.png

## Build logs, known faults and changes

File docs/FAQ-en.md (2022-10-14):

# Questions and answers FAQ

- ***Do I have to tare the iSpindle with weights?***  
It is indispensable to enable the iSpindle functionality! Add weights such as nuts, lead balls etc. to the bottom  until the inclination is 25° from the vertical. See also example pictures in the documentation. Normally about 20g are sufficient. +/- 5° deviations are often still acceptable.
If you're too close to 30deg, it will be too close to 90 deg at high sg measurements (your starting sg won't be accurate).
If you're too close to 15deg, it will be too close to 0 deg at low sg measurements (you won't be able to read sg's below .95).

- ***It doesn't work, I don't see anything***  
The best way to find out what the iSpindle is doing  is to read its log. This can be done via a serial monitor like HTerm or Arduino IDE. Connect the spindle via Micro USB, then open the £COM Port with the serial monitor above and read it. Set baud rate to `115200`. It brings light into the dark.

Here is a youtube how-to (in German): https://youtu.be/6xDW5GbIbUw

- ***How get to the iSpindel - the portal***  
Switch it on, press the reset button 3-4 times which sets up an access point. That means you will see a new Wifi network "iSpindel_######" where you connect to with your computer, smartphone or tablet. Now the browser should automatically redirect you to the page [http://192.168.4.1](http://192.168.4.1). If not, navigate there yourself.
If you are now on the portal page, under `Configuration` you can enter your token and the wifi password that you need for your network. Then click on `save` and it will send the data to Ubidots. This means that the **iSpindel is not reachable in normal operation**, until you manually start the portal again.

- ***Why can't I access the iSpindle in normal operation***  
The critical part of the battery life time is that the iSpindle is active as short as possible and maximum time being in`deep sleep`! The Wemos in active operation requires more than 300x of energy, so this trick is indispensable to achieve the runtime.

- ***The Micro USB port is for program updates?***
Correct, see Firmware Update

- ***How can I calibrate the voltage display?***
From firmware 3.0 on you can adjust the conversion factor. By default, factor 191.8 is used. You can adjust by this formula:
````
(displayed voltage / measured voltage) * current factor (191.8) = new factor

The new factor should be between current factor more or less 20% (191.8*0.8 - 191.8*1.2).
````
- ***Can I operate it in a stainless steel container? Is it possible to get through the faradic cage?***
To achieve a sufficient WLAN signal strength you can do the following things:

  - Break open the faradic cage. This is possible by electrically separating the lid from the pot. Can be achieved by applying a silicone sealant between the two parts.
  - Use a passive antenna. Use a shielded cable that is stripped from both ends (i. e. Lambda/4), where one side ends in the pot, exactly 32mm. This is transmitted passively from the inside to the outside and vice versa. A good example can be found here: http://hobbybrauer.de/forum/viewtopic.php?p=208782#p208782
  - Install a wifi range extender next to the barrel to increase the signal level.

-  ***What should I do if my iSpindel isn't working properly after flashing it with the firmware?***

For unclear reasons sometimes it looks like flashing of the iSpindel went well while it actually didn’t which could lead to unpredictable behavior.
This behavior could be but is not limited to:
-	the blue LED of the wemos stays on permanently
-	parts of configuration is not saved, e.g. offset tilt

The solution to this can be initializing the memory of the wemos before flashing it with the iSpindel firmware.(as if you were formatting a new harddrive before you can use it)

Here is how to do that using NODEMUCU FIRMWARE PROGRAMMER

To initialize:

In the Config Tab
````
		1st column		2nd column
1st Line:	INTERNAL://NODEMCU	0x00000
2nd Line:	INTERNAL://BLANK	0x01000
````
In the Advanced Tab
Set the Baudrate to 115200

In the Operation Tab
Click Flash(E) and wait till the flashing is done

To flash with the iSpindel firmware:

In the Config Tab
````
		1st column		2nd column
1st Line: 	C:\iSpindel-6.0.6.bin 	0x00000
````
Where “C:\iSpindel-6.0.6.bin” is to be replaced by the path to your firmware file
Make sure all the other lines in the Config tab are cleared and only the checkbox in front of your firmware path is checked.

In the Advanced Tab
Set the Baudrate to 115200

In the Operation Tab
Click Flash(E) and wait till the flashing is done

It now should work properly.

Source: https://www.homebrewtalk.com/forum/threads/ispindle-diy-electronic-hydrometer.598187/page-19#post-8366882

-  ***Improvements that have issues***
These are "frequently suggested improvements" that have issues that aren't obvious at first; feel free to try them, but
keep watch for problems:

1. "Let's seal it and use inductive charging!"
  a)The Qi chargers are larger than the PETling so they have to be bent.  Some Qi chargers get very unhappy about 
    that (overheating/fire), while others work but are *very* picky about placement on the Qi charging pad.
    There are inductive chargers that fit inside the cap [not Qi] (eg: https://amzn.to/3wslaLO , but they haven't 
    been tried yet).
    *Try it, but watch for heat!*

  b)The seal for the PETling is at the top/inside; yeast and bacteria  will get in the "threaded area" and will be 
    impossible to wash out.  Right now, it's recommended to take the cap off and clean/sanitize the cap and the 
    PETling separately.

2. Doesn't krausen/CO2 affect the readings?
  It certainly does with the commercial version; if you think it's settled prematurely, rock/stir your wort and 
  see what happens.
  
3. Can the iSpindel be used in a pressurized fermenter?
  You can try... the default PETling seal is "on the inside" so that it makes a better seal as the pressure inside 
  increases (sodas are carbonated), which is the wrong direction, but the screw theads do make a seal, so...

- ***Why do I get a connection error with HTTPS POST?***  
Unlike HTTP, the HTTPS POST method requires using the full URL to the server for the Server Address setting. e.g. `https://example.com` instead of just the hostname `example.com`.

## AWS IoT Conectivity

ADVANCED USERS ONLY

Recently we have started to add support for AWS IOT Core using the Secure MQTT option.

This option currently requires you to manually input your keys and certs into the secrets.h file, compile and upload yourself.
We are looking to add the ability to upload a certificate in future.

0. Configure AWS IoT core including creating your thing, certificates, policies and download your certs and keys
1. Download the Repo
2. Edit secrets.h to supply AWS Root Cert, Device Private Cert, Device Private Key
3. Compile and upload to your iSpindel
4. Configure using the config menu as normal with the AWSIOTMQTT option

Note: Secure MQTT (required by AWS) using a lot more battery as the device has to be on longer during each send. It needs to sync to an NTP server and establish and encrypted connection - both of which require processing time and hence battery use on the ESP8266.

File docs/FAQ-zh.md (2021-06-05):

# 常见问题解答

- ***我是否必须通过增加克重来平衡 iSpindle ?***  
将螺母、铅球等重物添加到底部，直到与垂直方向倾斜 25° ，是使 iSpindle 功能正常运行必不可少的条件。另见文档里的示例图片，一般 20g 左右就够了，+/- 5° 偏差通常仍然使可以接受的。如果太接近 30 度，在高比重测量时就会太接近 90 度（你的初始比重将不准确）；如果太接近 15 度，在低比重测量时就会太接近 0 度（你将无法读取低于 0.95 的比重值）。

- ***它没有在运行, 我看不到任何反应***  
找出 iSpindle 正在发生什么的最好方法是读取其日志，这可以通过像 HTerm 或 Arduino IDE 这样的串行监视器来完成。通过 Micro USB 连接设备，然后用上面的串口监视器打开 £COM 端口并读取它。设置波特率为 `115200` ，将给黑暗带来光明。

  这里有一个油管上的教程 (德语): https://youtu.be/6xDW5GbIbUw

- ***如何进入 iSpindel 设置模式入口***  
打开设备, 按复位键 3-4 次，建立一个接入点。这就意味着你将看到一个新的 Wif i网络 "iSpindel_######" ，你可以用你的电脑、智能手机或平板电脑进行连接。网页浏览器应该会自动将您重定向到页面 [http://192.168.4.1](http://192.168.4.1)， 如果不是，请自行导航到那里。
如果你在设置模式的界面, 在 `配置` 一项里可以输入你的密钥和无线密码。然后点击 `保存` ，接着它会把数据上传到 Ubidots。这意味着 **正常操作下无法访问 iSpindel **，直到你再次手动启动设置模式。

- ***为什么我无法在正常操作中访问 iSpindle***  
电池寿命的关键部分是 iSpindle 处于活动状态的时间越短越好，并且要尽可能长时间处于深度睡眠状态！主动运行的 Wemos 需要超过 300 倍的电量，所以这个技巧对于实现目标运行时间是必不可少的。

- ***Micro USB 端口是用于程序更新？***
没错，请参阅固件更新

- ***我如何校准电压显示？***
从固件 3.0 开始，你可以调整转换系数。默认情况下的使用因子是 191.8，可以通过下面的公式进行调整:
````
(displayed voltage / measured voltage) * current factor (191.8) = new factor

新的系数应介于当前系数之间，或多或少约为20% (191.8*0.8 - 191.8*1.2)
````
- ***我可以在不锈钢容器里连接上吗？信号是否有可能穿透法拉第牢笼？***
为了达到足够的 WLAN 信号强度，你可以做以下事情:

  - 打开法拉第笼，将盖子从桶身电性分离开来，通过在两部分之间涂抹硅酮密封剂来实现。
  - 使用外部天线，从两端剥去的屏蔽电缆（即 Lambda/4），并让另一端朝向桶内，正好3.2毫米。这是从内部被动传递到外部，反之亦然。一个很好的例子可以在这里找到：http://hobbybrauer.de/forum/viewtopic.php?p=208782#p208782
  - 在桶旁边安装一个 wifi 放大器以增加信号强度

-  ***如果我在刷入固件后 iSpindel 无法正常工作，我该怎么办?***

由于不明的原因，有时看起来 iSpindel 刷入过程非常顺利。但实际上并不是的，这可能导致各种不可预测的状况。
状况的发生可能是但不限于以下几种:
-	Wemos 的蓝色 LED 灯一直常亮
-	部分配置未被保存，如倾角偏移

解决这个问题的办法是，在给 iSpindel 刷入固件之前，先初始化 wemos 的内存（就像你在使用一个新的硬盘之前对它进行格式化一样）。

以下是如何使用 NODEMUCU FIRMWARE PROGRAMMER 进行操作

初始化：

在 Config 项
````
		1st column		2nd column
1st Line:	INTERNAL://NODEMCU	0x00000
2nd Line:	INTERNAL://BLANK	0x01000
````
在 Advanced 项
设置 Baudrate 为 115200

在 Operation 项
点击 Flash(E)，然后等待固件刷入完成

要和 iSpindel 的固件一同刷入：

在 Config 项
````
		1st column		2nd column
1st Line: 	C:\iSpindel-6.0.6.bin 	0x00000
````
替代 “C:\iSpindel-6.0.6.bin” 到你下载固件文件的路径，确保清除掉 Config 项里面的所有其它行，只有固件路径前面的复选框被选中。

在 Advanced 项
设置 Baudrate 为 115200

在 Operation 项
点击 Flash(E)，然后等待固件刷入完成

现在它应该可以正常工作了。

来源: https://www.homebrewtalk.com/forum/threads/ispindle-diy-electronic-hydrometer.598187/page-19#post-8366882

-  ***改进过后仍有问题***
这些是 "经常建议的改进"，其问题在一开始并不明显；勇于尝试，但要时刻关注问题的出现：

1. "让我们把它密封起来，并使用无线充电!"
   
  a) Qi 充电器比瓶胚大，所以需要被弯曲。部分这样做会导致充电过热或着火，另一些可以正常工作但对 Qi 充电板的位置会 *非常* 挑剔。
    有些感应式充电器能放在盖子里面 [不是 Qi] (例如: https://amzn.to/3wslaLO , 但还没有尝试过)。
    *试试看，但要注意热量！*

  b) 瓶胚的密封是在顶层内部, 酵母和细菌会进入 "螺纹区域" ，无法清洗掉。现在的建议是将瓶盖取下来，分别对盖子和瓶胚进行清洗、消毒。

2. 主发酵期产生的二氧化碳不会影响读数吗？
  商业版本的机器肯定也会有的。如果你认为它过早地沉淀下来，摇晃并搅拌你的麦汁，看看会发生什么。
  
3. iSpindel 能否用于加压发酵罐？
  你可以试试... 常规的瓶胚密封是 "在里面" 的，这样随着内部压力的增加，它的密封性能会更好 (苏打被碳酸化)，这是一个错误的方向，但是螺纹的确可以密封，所以...

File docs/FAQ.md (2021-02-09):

# Fragen und Antworten FAQ

- ***Muss ich die iSpindel mit Gewichten tarieren?***  
Dies ist unabdingbar um die Funktion der iSpindel überhaupt zu ermöglichen! Füge am Boden des Petlings Gewichte wie Muttern, Bleikugeln o.ä. hinzu bis die Neigung 25° von der Vertikalen beträgt. Siehe dazu auch Beispielbilder in der Dokumentation. Normalerweise sind etwa 20g ausreichend. +/- 5° Abweichung sind oft noch akzeptabel.

- ***Es funktioniert nicht, ich sehe nichts***  
Am Besten du liest mit was die Spindel als Informationen ausgiebt. Das geht über einen Serial Monitor wie HTerm oder Arduino. Die Spindel per Micro USB anschliessen, dann den Com Port mit obigen Serial Monitor öffnen und mitlesen, Baud `115200`. 
Ein Youtube HowTo: https://youtu.be/6xDW5GbIbUw

- ***Wie komme ich auf die iSpindel - das Portal***  
Anschalten, 3-4 maliges drücken der Reset Taste stellt sie einen Access Point auf. D.h. du siehst ein neues WLAN "iSpindel_######" mit dem du dich verbindest. Jetzt wirst den Browser automatisch auf die Seite [http://192.168.4.1](http://192.168.4.1) dich weiterleiten. Falls nicht steuer sie selbst an.
Wenn du nun auf der Portalseite bist, unter `Configuration` dann kannst du deinen Token eingeben und das WLAN Passwort dass du für dein Netzwerk benötigst. dann klickst du auf `safe` und sie wird ihre Daten an Ubidots senden. Damit ist sie im Normalbetrieb und nicht mehr zu erreichen

- ***mein Wlan-Passwort bleibt nicht gespeichert***  
Das ist korrekt, wenn man das Portal wieder startet (reset Taste) werden die Wlan Daten gelöscht. Zur Zeit so implementiert.

- ***Wenn die Spindel außerhalb des Sekundenintvallblinkmodus ist, kann ich sie erst wieder erreichen wenn ich die Resettaste betätigt habe***  
Reset Taste wäre nur sinnvoll wenn man was ändern möchte. Normalerweise wacht sie selber auf nach dem Intervall und geht in 'Normalbetrieb'. 
Man kann die Spindel im Normalbetrieb _nicht_ erreichen, sie sendet ausschließlich. (Powermanagement)

- ***Warum kann ich auf die iSpindel nicht im Normalbetrieb zugreifen***  
Der kritische Teil der Laufzeit ist dass die iSpindel so kurz wie nur möglich aktiv ist und sich die maximale Zeit im `deep sleep`  befindet! Der Wemos im Aktiv - Betrieb hat einen über 300x Energiebedarf, um daher die Laufzeit zu erreichen ist dieser Trick unumgänglich.
- ***Die Micro USBBuchse ist für Programmaktualisierungen?***
Korrekt, siehe Firmwareaktualisierung
- ***Wie kann ich die Spannungsanzeige kalibrieren?***
Ab Firmware 3 kann man den Umrechnungfaktor anpassen. Standardmässig ist der Faktor 191.8, diesen umrechnen:
```
angezeigte Spannung / gemessene Spannung  * jetziger Faktor (191.8) = neuer Faktor
```
- ***Kann ich sie in einem Edelstahl Behälter betreiben? Geht es auch durch den faradischen Käfig?***
Um eine ausreichende WLAN Signalstärke zu erreichen kann man z.B. folgende Dinge unternehmen:

  - Den faradischen Käfig aufbrechen. Dies ist möglich, indem man den Deckel vom Topf elektrisch trennt. Kann durch Aufbringen einer Silikondichtmasse zwischen die beiden Teile erreicht werden.
  - Eine passive Antenne einsetzen. Benutzen Sie ein abgeschirmtes Kabel, das von beiden Enden (d. h. Lambda/4), wo eine Seite im Topf endet, exakt 3,2mm abgemantelt ist. Diese wird passiv von innen nach außen und umgekehrt übertragen. Ein gutes Beispiel gibt es hier: http://hobbybrauer.de/forum/viewtopic.php?p=208782#p208782
  - Einen Wifi Range Extender direkt neben dem Fass installieren, um den Signalpegel zu erhöhen.

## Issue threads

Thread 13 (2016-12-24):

Use DS18S20 instead of DS18B20

jaapz, 2016-12-24:
My supplier sent me the wrong temperature chips, so instead of the DS18B20 I got the DS18S20. This sensor does not support setting the resolution but other than that it should work the same.
However, I'm getting the "OW disconnected" error, which means (i think) that the one wire protocol did not initialise correctly. I commented out the part where the resolution is set and rebuilt the software. I'm still getting the error though...

Do you think this is a hardware problem, or are there other parts of the code that need to be changed to also support the DS18S20 temperature sensor?

jaapz, 2016-12-24:
As far as I can see the sensor should just work fine, the DallasTemperature library doesn't do anything when setting the resolution on this type of sensor... I'm going to re-check my breadboard for any mistakes.

universam1, 2016-12-25:
I think the S20 should work out of the box without modification. But I would highly discourage using it because the lower resolution makes it pretty useless for monitoring fermentation or even more the temperature controlling we do with CBP or TControl.

jaapz, 2016-12-25:
Yeah, I've already ordered the B20 because the 0.5 degrees resolution is pretty bad.
Anyway, I'm getting the OW disconnected error still, and I have checked and re-checked my breadboard, but I couldn't find any problems, the temperature sensor is connected exactly like on the schematics.

I have already tried shortening the data cable, it was about 10cm long so I thought maybe that was too much. The shorter cable is a 2 or 3 cm long but I'm still getting the error.

Do you have any idea where the problem might lie?

Happy holidays by the way.

universam1, 2016-12-25:
I did also have a dead DS18b20 delivered, lost quite some time figuring that out. So just replacing might solve.

jaapz, 2016-12-25:
I tried two different S20's already, but not with the shorter data cable. I'm going to try that later today, thanks.

jaapz, 2016-12-26:
Never mind, looks like when the GY-521 chip is faulty it also affected the initialisation of the 1-Wire bus. I replaced the GY-521 chip and both the gyro and the temperature chip work now.

universam1, 2016-12-26:
That's very interesting observation, just had the exact same happening with me today...

Closed 2016-12-26.

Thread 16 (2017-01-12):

JSON to TCP Socket (no http)

DottoreTozzi, 2017-01-12:
As we already discussed by email, I'd like to write a small, very basic Python script that receives the iSpindle's data over a TCP socket, without any higher-level application protocol such as http.
The goal is to have a dedicated platform independent server for the spindle, with minimum overhead and battery drain.

The first step will be to simply write the data to a CSV file on a network share for Excel import.
Later I want to expand the capabilities to include database support and perhaps some http server functionality for client-side data retrieval.
The source code will of course be made available (it's Python, anyway..).

In order to accomplish this, I suggest the spindle sends a JSON string in the already defined format to a configurable IP Address (host name resolution would be nice-to-have) and TCP port (I suggest 9501 as a default).
After the transmission, the connection could simply be closed by the spindle, or I implement some response (no problem), for example ASCII 6 (ACK), and ASCII 21 (NAK) in case the transmission failed for some reason, perhaps even triggering the spindle to retry for a defined number of times before giving up.

On my side, I'm fully open to suggestions. Whatever works best for you.

Thanks again for your hard work!

DottoreTozzi, 2017-01-13:
I've had quite a productive night shift, so the first preliminary version of my script is done.
It's just ~50 lines of code. My first Python script ever, but I can already tell I quite like it.
Things can be done really fast with it.
Took me just a couple of hours to put this together, even as a complete noob. ;)

Right now, all my script does is listen to port 9501 and send ACK (ASCII 6) if data is received according to specifications, NAK (ASCII 21) if it's not. Excel Timestamps are incorporated in the CSV output per default. Connection won't be dropped by the server by default, however, this would just be a matter of uncommenting a line or two inside the code.

For now, it then just appends the data to a CSV file.
The filename is generated from "name" and "ID" of the JSON input, so it should be thread-safe under normal circumstances, even if two or more spindles try to connect at the same time.
The TCP listener forks accordingly.

No external libraries are required, it all "just works" in plain vanilla Python 2.7 or later.
Configuration still means editing the file itself. No big deal, though.

I've attached it, so you can play with it when you find some time.

Cheers
Stephan

[iSpindle.py.gz](https://github.com/universam1/iSpindel/files/703574/iSpindle.py.gz)

universam1, 2017-01-13:
Awesome!

Had no time to test your work but I did my part as well! :)

Please try https://github.com/universam1/iSpindel/raw/genericTCP/bin/testing/iSpindel.3.6.0.bin
There is currently no testing against your response, but it's printed to Serial for your debugging.
You will be able to select as API now "TCP".

Let me know how things go, you can check the code at the "genericTCP" branch.

DottoreTozzi, 2017-01-14:
OK I've had some trouble flashing the firmware from my mac, (Windows inside a VM didn't work) and had to use native Windows in Bootcamp, which worked...

After that, during configuration, the Wemos crashed a few times.
Can't reproduce that now, however, it seems to work now.
Also, switching to TCP mode at first still showed the Ubidots token as input field, only when switching to it for a second time, it showed the ip address and port fields.

Now it works and the good news is I am receiving data.

But:
My script expects the JSON to come in one line.
Looks like the spindle sends the leading "{" first, then the rest of the JSON.
This could of course also be just due to my q&d implementation.

Here's my debug output:
`waiting for connection... listening on port: 9501
('192.168.2.28', 25603) received:'{'
('192.168.2.28', 25603) Error: Expecting object: line 1 column 1 (char 0)
('192.168.2.28', 25603) NAK sent. Waiting for Retry.
('192.168.2.28', 25603) received:'"name":"iSpindel01","ID":"14236088","angle":31.09,"temperature":25.25,"battery":4.30}'
('192.168.2.28', 25603) Error: Extra data: line 1 column 7 - line 1 column 86 (char 6 - 85)
('192.168.2.28', 25603) NAK sent. Waiting for Retry.`

DottoreTozzi, 2017-01-14:
Never mind, I've fixed it.
It will now gather incoming data until it encounters "}" (as it should have in the first place).
The socket is being closed after that (or when it times out).
[iSpindle.py.gz](https://github.com/universam1/iSpindel/files/705742/iSpindle.py.gz)

Works like a charm now. Might want to take a look at the other issues I've mentioned before, though.

Latest version of my tiny lil' script:
[iSpindle.py.gz](https://github.com/universam1/iSpindel/files/705745/iSpindle.py.gz)

universam1, 2017-01-14:
Great I will to cache the tcp data before sending if that makes a difference.
Also I wonder what a close signal should be sent.
It is not closing because it is waiting for the reply of your script, I guess that's the reason. Can you ack and close?

DottoreTozzi, 2017-01-14:
Yes that's what I've done now. I send ACK or NAK and close the connection server side.

universam1, 2017-01-14:
Nice, do you mind to add your script and a bit description to the Repo?

DottoreTozzi, 2017-01-14:
Sure thing! Just been waiting for your OK to do so. Where should I put it?

universam1, 2017-01-16:
Great!
What about this folder https://github.com/universam1/iSpindel/tree/master/tools maybe make a subfolder and add some description in `/docs` folder?
Thanks

DottoreTozzi, 2017-01-17:
Done. Sorry for spamming Pull Requests, I've worked with GIT before but sometimes its features are still a bit elusive... (ashamed smily here)...

universam1, 2017-01-17:
Thats just perfect! Thanks so much, have to link to your work now in the Readme's. If there's something more to do feel free to open.

Closed 2017-01-17.

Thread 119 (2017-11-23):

Remove WEMOS input diode

cwilling, 2017-11-23:
This is just a request for clarification about removing the WEMOS input diode, as mentioned in [this circuit diagram](https://github.com/universam1/iSpindel/blob/master/docs/circuit_diagram_en.md) and issue #47.

Is it correct to say that any danger only occurs when the iSpindel is connected by the USB port? For developers, connection by USB is sometimes more convenient e.g. for faster firmware flashing, but the normal user would not normally use this mode.

A second related question; if WEMOS is connected by USB but no battery attached, is the danger still there? I presume no charging current would be drawn in this case (LiPo  led is green if it has USB power attached with no battery).

universam1, 2017-12-12:
Yes this is correct.

einaruk, 2018-02-26:
As I understand from circuit diagram, even if you do not remove the diode, but be careful to turn OFF the switch when you connect the Wemos to USB, there is no danger of creating overvoltage on the battery, thus no risk. (No risk only, If you are very careful and do not forget to switch off every time you connect the Wemos to USB.)
Correct?

JensW2000, 2018-02-26:
Nope! If you do not the Wemos diode, and put an USB cable into the Wemos port, then the battery gets uncontrolled 5V. This can cause a battery explosion in worst case. The better cases are possible damage of the Wemos, the TP4056 or both.

You would like to remove the diode, right? :-)

einaruk, 2018-02-27:
Hi @JensW2000,
  I guess you missed the prerequisite for my statement. I said, "if you switch off the switch".
If you switch off the switch when connecting to USB, how can you deliver 5V to battery?

Am I missing sth? I do not know the function details of the LiPo charger but will 5V input to +IN pin create any damage?

Thanks

Closed 2017-12-12.

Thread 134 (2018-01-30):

WiFi config not saving?

jfarcher, 2018-01-30:
Started building a couple of devices tonight, flashed the image to 2 Wemos D1 with gyros attached,
I'm getting the initial config mode portal, but when I add the SSID and passphrase it doesn't seem to save.
Upon attaching a serial monitor, both devices are slightly different.
device 1 after reboot:

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

> ERROR config corrupted
> ...........
> ERROR no Wifi credentials

> going to Config Mode
> reboot RFCAL
> sd␀$��|␀�l�<␃␌␄␄�␄l�␄c|��␃�␓�r�#l�c��gn�dog���␄c␜8ćlsd;l␛�;�g�c�'c8␀�

and it just freezes

Second device:
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

> going to Config Mode
> reboot RFCAL
> {l␀l��|␀�d�|␂␄␄␌�␌d�␌b<��␃�␛�{�c$�#��og�l'o���␌#␜p��${ls$␓�s��n�c�ocp␀�

Both devices hang there until the reset button is pressed, which then drops them back into config mode.

Any ideas?

jfarcher, 2018-01-30:
I just flashed the original (Arduino based) WiFiManager example to the device and it configures wifi and saves the configuration ok.

universam1, 2018-01-30:
You are missing the ~300Ohm resistor btw. D0 and RST!
Try to shortcut these pins for testing.

jfarcher, 2018-01-30:
I haven't finished soldering up the boards yet, didn't realise there was a dependency for everything to be in place. Will try shorting out d0 and rst this evening.

Thanks

universam1, 2018-01-30:
These kind of issue reports usually cost a beer! 😋

jfarcher, 2018-01-30:
Shorted D0 and RST with a resistor, the boot process doesn't seem to hang any more but its still failing to save the settings.
FW 5.6.2
2.1.0(deb1901)
Worker run!
Boot-Mode: 5
mounting FS... mounted!
reading config file
opened config file

parsed json
applying offsets
parsed config:
{"Name":"iSpindel000","Token":"","Sleep":900,"Server":"","API":0,"Port":80,"URL":"","Vfact":191.8,"SSID":"",
"PSK":"","POLY":"-0.00031*tilt^2+0.557*tilt-14.054","aX":640,"aY":3280,"aZ":1070}...........
ERROR no Wifi credentials

jfarcher, 2018-01-30:
I guess I'll get all fully soldered up and retry once all components are connected.

universam1, 2018-01-30:
Can you post the log immediately when pressing the save button?
What browser are you using? Chrome is optimized for.

jfarcher, 2018-01-30:
Log:
*WM: Sent wifi save page
ERROR: OW DISCONNECTED

Exception (9):
epc1=0x40104a55 epc2=0x00000000 epc3=0x00000000 excvaddr=0xffffffff depc=0x00000000

ctx: sys
sp: 3ffffdb0 end: 3fffffb0 offset: 01a0

>>>stack>>>
3fffff50:  00000056 00000001 40104186 3ffee890
3fffff60:  4022a599 3ffef670 00000001 00000000

3fffff70:  4023eb57 00000004 00000000 00000000
3fffff80:  3fff22a4 4023e506 3fffdab0 00000000
3fffff90:  3fffdcc0 3ffea820 00000000 40249637
3fffffa0:  3ffea820 40000f49 3fffdab0 40000f49
<<<stack<<<

 ets Jan  8 2013,rst cause:2, boot mode:(3,6)

load 0x4010f000, len 1384, room 16
tail 8
chksum 0x2d
csum 0x2d
v00000000
~ld

And I'm using Chrome.

jfarcher, 2018-01-30:
Further up the log:

*WM: WiFi save
*WM: Parameter
*WM: name
*WM: iSpindel000
*WM: Parameter
*WM: sleep
*WM: 900
*WM: Parameter
*WM: vfact
*WM: 191.80

*WM: Parameter
*WM:
*WM:
*WM: Parameter
*WM:
*WM:
*WM: Parameter
*WM: selAPI
*WM: 0
*WM: Parameter
*WM: token
*WM:
*WM: Parameter
*WM: server
*WM:
*WM: Parameter
*WM: port
*WM: 80
*WM: Parameter
*WM: url
*WM:
*WM: Parameter
*WM:
*WM:
*WM: Parameter
*WM: POLYN

*WM: -0.00031*tilt^2+0.557*tilt-14.054
*WM: Sent wifi save page

Not sure if its by design, but there doesn't seem to be any SSID or WiFi details listed

universam1, 2018-01-31:
Uh line #2 is already the answer, you have no DS18b20 connected and as you see that’s where it is crashing!
Looks like it’s going to be a sixpack 😁

jfarcher, 2018-01-31:
Yeah, as I previously mentioned I didn't realise there was a reliance on all components to be present to test.

Cheers.

Closed 2018-01-31.

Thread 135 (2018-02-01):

Tilt = 0.00

kjenset, 2018-02-01:
Hi

My ISpindel not showing the degrees. I have tried the calibration under maintenance, but even after 15min the blue led dosen't change from solid to blink.

The temperature is correct and the connection to ubidots works!

Any clue?

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

Regards
Kjenset

JensW2000, 2018-02-01:
Either the connections to the GY-251 have cold solder joints or a short circuit or the GY-521 is broken.

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

Naesstrom, 2019-10-22:
What was the problem, mine is showing 0.0 to

studawg66, 2020-01-22:
Did anyone find the answer to this?  I have re-soldered joints and replaced the gyro board and I still get 0.0. The LED on the gyro module is lit when it gets power and all other functions work just fine. Any ideas?  Can I just add jumper wires from the board to the D1 board to see if my PCB is bad?

Naesstrom, 2020-01-28:
I read somewhere else that the adress of the gyro might differ from one source to another and that makes it show 0 as tilt... Wish there would be a fix in the software for it since I have 5 ispindels soldered and ready that doesn't work right now!

universam1, 2020-01-28:
High guessing. Please attach your console logs at least

studawg66, 2020-01-28:
In my case, 2 out of the 5 gyros I ordered (same batch) did not work.  I tried some troubleshooting of the GY-521 board, but couldn't identify the issue.  Replaced the GY-521 with a new one and the iSpindel reads the angle as it should.  I have read that these GY-521 boards are really flaky.  If you are going to build 5 iSpindels, order 10 of the GY-521 to be safe.  They are cheap.

Naesstrom, 2020-01-29:
I wonder if it's related to this: https://github.com/universam1/iSpindel/issues/302
That some gyros have the correct adress and some don't depending on production

studawg66, 2020-01-29:
Could be related, but mine were from the same batch and the two that reported 0.0 reported 0.0 to Ubidots as well, so that seems to be a different issue.

Closed 2018-02-02.

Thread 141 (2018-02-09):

Alternative hardware

FernandoGarcia, 2018-02-09:
Hi!

I found this project yesterday and seems very cool.

I have to say thanks to all contributors.

Looking to buy parts I found [this board](https://pt.aliexpress.com/item/WeMos-D1-Esp-Wroom-02-Motherboard-ESP8266-Mini-WiFi-Nodemcu-Module-18650-Battery/32828007433.html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,searchweb201602_2_10152_10151_10065_10344_10068_10547_10342_10343_10340_10548_10341_10084_10083_10618_10307_5722313_5711215_10313_10059_10534_100031_10103_10624_10623_10622_10621_10620_10142,searchweb201603_28,ppcSwitch_5&algo_expid=a254017a-f86e-4c8f-a426-b56a76ebab79-0&algo_pvid=a254017a-f86e-4c8f-a426-b56a76ebab79&priceBeautifyAB=0) that seems very good option to replace Wemos + TP4056 + Micro switch and 330 ohms resistor (or BAT43 diode).

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

It has an Esp-Wroom-02 on board, the description say it's as a nodeMCU.

For me the big advantage is that this board don't need be turned off to charging. So using a wireless charger won't be need to open the container at all.

Someone know this board? It's a good option?

Best regards.

universam1, 2018-02-09:
Nice board indeed.

Now first, there is no obligation to turn the iSpindel off during charging, not sure what you mean with this.

Not to open the container any more is not a technical problem by all means but a hygienical!  It turned out to infect the worth sooner or later by yeast you can’t remove in the thread.

Now the biggest problem is the weight displacement. The battery has to be in the very bottom while the antenna has to be on the very top, above the water level. That unfortunately seems to be a problem with this board.

Good luck and report back.

FernandoGarcia, 2018-02-09:
Hi!

I found [this posts](https://www.homebrewtalk.com/forum/threads/ispindle-diy-electronic-hydrometer.598187/page-13#post-8108612) talking about the problem with switch and calibration.

Best regards.

FernandoGarcia, 2018-02-21:
I bought the parts let's see what happens. :D

universam1, 2018-03-26:
no progress on this one, closing for now

FernandoGarcia, 2018-08-30:
Hi @universam1!

I built the controller using this board.

I'll post a tutorial coming soon.

The pinout used is:
A0 for battery monitor;
D1 - D2 for I2C BUS;
D7 for DS18B20.

Here the link for 3D printed part.

https://www.thingiverse.com/thing:3075683

Best regards.

universam1, 2018-08-30:
Be informed that I do not tolerate that my project is being sold or commercialized without my permission. Check the license associated.

FernandoGarcia, 2018-08-30:
Of course!

I'm not selling any hardware or software just tube and support.

FernandoGarcia, 2018-08-30:
Maybe you should call yours advocates for this guy. :D

https://produto.mercadolivre.com.br/MLB-1062940698-ispindel-densimetro-digital-montado-completo-_JM

aagilang, 2025-01-19:
how to flash this board.. i cant connect

FernandoGarcia, 2025-01-19:
Hi!
This board is a waste of time and money.
The battery won't last 2 days.
It has serious engineering problems.
Anyway [here](https://github.com/FernandoGarcia/iSpindel-for-MQTT-only/blob/master/platformio.ini) you can see the configuration to flash this board.
Best regards.

Closed 2018-03-26.

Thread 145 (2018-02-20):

Circuit diagram

Perimec, 2018-02-20:
Dear,
thanks again for the wonderful tool that you have been developing here.

I'm building my first ispidel and I have a question regarding the circuit diagram (https://github.com/universam1/iSpindel/blob/master/docs/circuit_diagram_en.md). The orange cable connecting the the +in lipo to the +5v of the wemos is optional if understood correctly. What is it for? and then if I will not use it, shall I still remove the input diode on the wemos? and what does it mean in the description : Remove the input diode (short circuit via Lipomodul!)??? is that optional too?

thanks in advance

universam1, 2018-02-21:
The orange is optional, you can also just use the USB connector of the charging module to charge.

The diode is to be removed to prevent uncontrolled charging of the LiPo through the USB connector of the Wemos, so if you love your home you should remove it in order to prevent battery explosion. :)

Closed 2018-02-21.

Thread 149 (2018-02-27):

Please help me -Ispindel config - no com port

SimonHanson, 2018-02-27:
Windows 10
When i plug in my ispendel i can not getting a com port showing in device manager
Therefore cant flash it

JensW2000, 2018-02-27:
Do you probably forgot to install the CH350G Device driver?
https://wiki.wemos.cc/downloads

SimonHanson, 2018-02-27:
Installed still not working

________________________________
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

JensW2000, 2018-02-27:
Please connect a USB cable to the charging module (TP4056).
Wich lights does lit after a single reset? What lights does lit if you turn off the power switch?

SimonHanson, 2018-03-04:
Switch position one
PLug in USB Blue light on, tiny orange flash on the other led
hit reset  nothing

Switch position 2
Plug in uds blue and orange lights on
hit reset blue light on the other board

SimonHanson, 2018-03-05:
Please can anyone help me with this problem

universam1, 2018-03-26:
no progress on this one, closing

SimonHanson, 2018-03-26:
I still need to get an answer

________________________________
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

Closed 2018-03-26.

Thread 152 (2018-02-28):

Configuration problem (wrong SSID & firmware problem)

juhanius, 2018-02-28:
Hi,

After soldering the iSpindel kit, I did not manage to proceed with the instructions. When switched on and after pressing reset, the appearing wifi is not named "iSpindel", but "ESP_4EED91".
The wifi allows me to connect, but doesn't appear to do anything. The address 192.168.4.1 is not found. Also, the blue LED keeps blinking in about 2 s interval also beyond the 5 minute period.

I continued with these instructions in order to access the log:
https://www.youtube.com/watch?v=6xDW5GbIbUw

I managed to access the device with Baud rate 74880 (not 115200, which were instructed). What happens is when I press the reset button, the following appears in the log:

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

Nothing else seems to happen. When pressing reset again, exactly the same log text reappears.

I tried to flash the firmware, (with these instructions, Windows & USB: https://github.com/universam1/iSpindel/blob/master/docs/Firmware_en.md) but NodeMCU only gives me the following error: "Error:Serial port connect failed, please check it."
NodeMCU seems to automatically find the device in COM3 port (from where I found the log with PuTTY), but I have no idea how to proceed here. I tried both baudrates (115200, which was in the documentation and 74880, which worked with PuTTY and the log), but with no success.

I understood that configuring the device even without first updating the firmware should be possible. So, is there something wrong with this device? Or is the problem only in the firmware update (where I apparently don't know how to use the NodeMCU)?

All help is appreciated!

universam1, 2018-02-28:
Without uploading the firmware the esp8266 is brain dead! How did you come to the conclusion this is not required?

You might need to install the drivers first, go to Wemos to download them for your operating system. Then you can select the com port an upload.

juhanius, 2018-02-28:
Ah, like I somehow suspected, the main problem indeed was between chair and keyboard! As the firmware upload was not listed as a step in the configuration instructions, I assumed that there would be an existing firmware. Thank you for clarifying this!
The driver download solved this, resulting in succesfully uploading the firmware. However, now the log looks like this after pressing reset:

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

The "ERROR: OW DISCONNECTED" keeps repeating. Is this a symptom of a faulty temperature sensor or some other component? (or a faulty soldering).

Closed 2018-03-02.

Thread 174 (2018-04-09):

Still no com port - second kit not working

SimonHanson, 2018-04-09:
This is the second kit i have had put together professionally for me.
First ones there was no com port showing in device manager?
Second one it showed a com3  for a very brief amount of time and it them never re-appeared
Any advice on helping me to get it sorted

universam1, 2018-04-09:
check your usb cable, is it only a charging one?
Try another computer, on Windows. Driver installed?
Did you charge the battery fully?

SimonHanson, 2018-04-09:
I have USB cable attached to both ports
Witch position should the switch be in
      one with blue light on red flashed very low
      one with blue and red on
Tried i win 10 and win 7 computer
Driver is installed
How long does it take to charge the battery?

JensW2000, 2018-04-09:
Blue AND Red together means that you've soldered somewhere a short circuit or either the Wemos or the GY-521 is broken.

SimonHanson, 2018-04-09:
Any more advice?

JensW2000, 2018-04-09:
Not sure what kind of advice you are looking for Simon.
Take a good magnifying glass and search all solder joints for short circuits. The 3 DS18B20 pins are often a candidate for this.
If can't find any short circurits, then solder down the GY-521. If the battery can then be charged and the firmware can be flashed, the GY-521 is defective. Otherwise the Wemos is broken (or maybe both - Wemos and GY-521).

Closed 2018-07-12.

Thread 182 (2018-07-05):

Temperature reads 25 C or ambient then -127 C at random intervals on two of three ispindels built.

yakam-doolday, 2018-07-05:
Hi,
Its not the temp probe or the rest of the circuit, I have narrowed it down the wemos, but i don't know whats wrong, anybody got any ideas?

I have used the pcb thats available and tested all three boards with the wemos that definitely works.
The two that work intermittently read the correct angle all the time but the temp suddenly goes from ambient say 25 degrees to -127 degree randomly, and the wemos won't save the wifi configuration either.
Please help, I am not an expert in electronics or computing but have managed to make one work.

yakam-doolday, 2018-07-06:
Thanks for your reply ollinator2000.
The 18b20 sensor the resistors and the diode are all on a separate board that the wemos/GY-521 plug into.  All 3 of these boards work. However 2 of the wemos/GY-521 do not wok reliably.  I will try to capture the data from the serial monitor and post here this weekend.

yakam-doolday, 2018-07-06:
Whoops pressed the wrong button.

yakam-doolday, 2018-07-06:
After 10hrs Investigating this, I've found and fixed the problem.
The batch of 5 wemos'es I ordered from china, all had the ESP8266 sub board soldered to the wemos board with the absolute minimum of solder if any. The A0 pin was just resting on the pad hence the intermittent temperature readings.  Got my magnifying glass out and resoldered all 16 connections to wemos board.  Now working.
Everyone beware cheap isn't always better. Cheap just wasted about 10 hours of my life.

Closed 2018-07-06.

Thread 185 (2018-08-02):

deep sleep even with a BAT43

craboune, 2018-08-02:
Hi everybody,

I encounter some issues with my ispindel even if I have replaced the 390 ohms resistance by a diode BAT43.
I can communicate with my ispindel and also load a firmware without difficulties.
I use Ubidots server to send my data. I bought component on the website 3D-mechatronics.de

When I finished to configure my ispindel on my wifi lan, the blue led stops blinking and that all. I have yet set a period of 15s but nothing happened. I have only one data point on ubidots ...

could you help me please ?

crab a lost french brewer ;-)))

thank a lot

here is my log (PuTTY)

 FW 5.8.6
2.2.1(cfd48f3)
Worker run!
Boot-Mode: 5
mounting FS... mounted!
reading config file
opened config file

parsed json
applying offsets
parsed config:
{"Name":"Red","Token":"A1E-0xIdXsxiew7Jzeaxxxxxxxxxxxxxxxxxxx","Sleep":15,"Server":"                                                                                                                                                             Monitor.beer","API":0,"Port":80,"URL":"/ispindel/?craboune","DB":"ispindel","Job                                                                                                                                                             ":"ispindel","Instance":"000","Vfact":191.8,"TS":0,"SSID":"Appart","PSK":"xxxxxxxxxxxxxxxxx","POLY":"2*tilt","aX":-3387,"aY":-257,"aZ":1209}
                                                               woken from deepsl                                                                                                                                                             eep, normal mode

WARNING: low Battery
Spl 0: 48.12
Spl 1: 50.84
Spl 2: 53.38
Spl 3: 58.56
Spl 4: 62.73
Spl 5: 65.44
Spl 6: 68.29

a: -1756        -15470  5992    absTilt: 58.22  T: 32.32        V: 2.94 owT: 31.                                                                                                                                                             37      Gravity: 116.44
After waiting 3001ms, result 3
IP: 192.168.0.30

calling Ubidots
{"tilt":58.22008,"temperature":31.375,"battery":2.940563,"gravity":116.4402,"int                                                                                                                                                             erval":15,"RSSI":-67}Sender: Ubidots posting
POST /api/v1.6/devices/Red?token=A1E-0xIdXsxiew7Jzeaxxxxxxxxxxxxxxxxxxxxxxx HTTP/1.1
Host: things.ubidots.com
User-Agent: ESP8266
Connection: close
Content-Type: application/json
Content-Length: 101

POST /api/v1.6/devices/Red?token=A1E-0xIdXsxiew7Jzeaxxxxxxxxxxxxxxxxxxxxxxxx HTTP/1.1
Host: things.ubidots.com
User-Agent: ESP8266
Connection: close
Content-Type: application/json
Content-Length: 101

HTTP/1.1 200 OK
Server: nginx
Date: Thu, 02 Aug 2018 21:36:42 GMT
Content-Type: application/json
Transfer-Encoding: chunked
Connection: close
Vary: Accept-Encoding
Vary: Cookie
Allow: GET, POST, HEAD, OPTIONS

d1
{"temperature": [{"status_code": 201}], "battery": [{"status_code": 201}], "tilt                                                                                                                                                             ": [{"status_code": 201}], "interval": [{"status_code": 201}], "gravity": [{"sta                                                                                                                                                             tus_code": 201}], "rssi": [{"status_code": 201}]}
0

WARNING: low Battery

Final-sleep: 3600s; RT:5861

universam1, 2018-08-04:
Look at the two last lines, you are falling into emergency mode because of voltage issue. Fix that and all will work.

craboune, 2018-08-05:
hi,
thanks for your reply. I saw the warning " low battery" but the battery was pretty full or something like that but not discharged. It is a Samsung 18650 - 3,6V - 3500mAh

the voltage was about 2.9V during the test (seen on ubidots dashboard)

do you think the issue still provides from the battery ?

thank a lot

universam1, 2018-08-05:
Yes, you need to correct the voltage factor

craboune, 2018-08-05:
Ok, thank you very much because it seems working well now !
I completely recharged the battery and the Ispindel is now sending datas. That's great !

may I ask you a last question please ?

the voltage factor is the same as "battery conversion factor" I suppose that I found in the configuration setup of Ispindel ? So how can I modify / correct the voltage factor ? do I need to measure something (battery voltage, ...)

many thanks !

Closed 2018-08-04.

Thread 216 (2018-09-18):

Possible Deep sleep issue ?

tonarii, 2018-09-18:
Hi, i'm sorry to post a new issue that might not be a new one, but i don't know if i have a deep sleep issue or if this is from something else.
I used last Cherry Philip PCB (frome here on issue #154) and replaced the 470 resitor by the Bat 43 diode Schottky.
Here is a report when i try to send data to my database.
I would like to know if this can be a soldering problem or something like that.
Thanks.
Regards.
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

JohnnyGunn, 2018-09-20:
Hi,

I'm using the same PCB and I'm getting the same issue on the most recent firmware. I can sync to Ubidots, but I'm only getting 1 set of readings, the first ones. No updates to any of the readings after that.

JohnnyGunn, 2018-09-21:
My issue has been resolved. I updated the firmware via the portal, and reduced the interval time to 5 seconds for testing and all is good now.

tonarii, 2018-09-21:
Hi, ok good to know and good for you :)
Me i'm waiting for some news parts to build a brand new device and see if it's ok or not.
I will try the update from the portal.

tonarii, 2018-09-27:
To close, i proceed to a clean and fresh build and now it's working properly :)

MattCordell, 2018-10-03:
Was about to post my logs for help (having the same issue, same board). However, I used the 330ohm instead of Diode... I'll try update firmware via the portal tonight (Hopefully that works).

tonarii, 2018-10-03:
To me the issue came from a soldering problem, i hope you'll fix your ispindel :)

MattCordell, 2018-10-03:
OK Thanks. Fortunately I purchased 5 of all the parts I needed. Except the Diode... Looks like I'll need to track one of those down. I don't think I'm going to be able to pull the one I've built apart to access the resistors (already done it once, not fun). Sigh.

tonarii, 2018-10-03:
I agree not fun at all ! ^^

simduchaine, 2019-02-27:
I seem to have the same problem. @tonarii what was your soldering problem?

Closed 2018-09-27.

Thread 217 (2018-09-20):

offset calibration result not maintained after power off

lweydert, 2018-09-20:
Hi iSpindel developpers and contributors,

Thanks for the whole project and for its great documentation.

When surfing through the iSpindels configuration websites I came accross the "Offset Calibration" procedure from "Maintenance" screen.
My current assumption is that this "offset calibration" intends to align the accelerometer orientation with the tube direction (for example when during soldering, the user slightly misaligns the accelerometer with the wemos, which happened also in my case).
I preformed the "offset calibration" and in fact the procedure itself went well.
After calibration the new tilt value was close to 90° when lying on a horizontal surface and the new tilt values also seemed okay when tilting the iSpindel .

The problem I am facing now is that after powering off and on the iSpindel,
the offset calibration result seems to get lost (so not properly saved after/during the "offset calibration" procedure).
To make my current iSpindel work,
I would have to redo this "offset calibration" procedure after every power on.

I flashed the latest firmware 6.0.0 and
I base my findings based on the tilt values shown in the "iSpindel Info" website.

Hence here my questions:
1) Is this behavior according to the iSpindels intended behavior ? (Should the offset calibration procedure be done at every use after power on)
2) If yes, what is the reason for forcing the user to do it ? I assume that if everything is well fixed and no mechanical changes occured on the iSpindel, this should not be necessary ?

Thanks for your help,
Cheers

universam1, 2018-09-20:
Check the console logs especially about message for loading the offsets.

Actually after the calibration the iSpindel reboots and you monitor good calibration that is calculated from stored config. Hence your observation is not technically totally possible but the log output may give you the insight.
Another option is that your sensor is somewhere broken.

lweydert, 2018-09-24:
Dear universam1,

Many thanks for you super fast support !

I checked the console log and indeed offset values were correctly saved.
Also the console log indicated that sensor tests during the offset calibration went fine.
Despite  the following console log:
"reading config file
applying offsets
parsed config:
{"Name":"iSpindelBoufferBouwen","Token":"A1E-qHLPoqFUGeZA84kgxBJPt7yuyxaxCp","Sleep":300,"Server":"","API":0,"Port":80,"URL":"","DB":"ispindel","Username":"","Password":"","Job":"ispindel","Instance":"000","Vfact":191.8,"TS":0,"OWpin":12,"SSID":"0024A5BCBC1E","PSK":"3y4da87g6msbn","POLY":"-0.00031*tilt^2+0.557*tilt-14.054","aX":563,"aY":2040,"aZ":1227}"
I still experienced that the tilt value did not seem to consider the offset calibration results after manually powering off/on.

I also used the X,Y,Z values from console log in order to check whether sensor readings make sense appropriate and they do.

For above reasons, I decided to downgrade firmware version to 5.8.6. and
now my iSpindel works as expected (keeps the calibration result also after manual power off/on).

Thanks for your support.

the51craw, 2019-05-18:
> Check the console logs especially about message for loading the offsets.
> Actually after the calibration the iSpindel reboots and you monitor good calibration that is calculated from stored config. Hence your observation is not technically totally possible but the log output may give you the insight.
> Another option is that your sensor is somewhere broken.

Hi universam1, and thanks for this great firmware!

I really hate to contradict you now, on my first contact with you, but 'not technically totally possible' seems to be possible after all. I have found that my iSpindel looses calibration data (but not settings) after power cycle using f/w 6.0.0 or later.  However, calibration data is saved as expected after power cycle using f/w 5.8.6.

There is a difference between reboot and power cycle, and the problem probably lies there. I have analyzed the source code between versions 5.8.6 and 6.0.0, but there are a lot of differences. Unfortunately the two versions in between are not supplied as binaries, and I do not have the platform.io compiler, so I cannot narrow it down further.

I believe that this may be what happens:
After calibration the platform saves the calibration data and reboots.
During reboot, the calibration data fails to be read back for some reason (problem during write or read).
Since the platform has been under power all the time, the calibration therefore remains in RAM.
When power cycling the platform, RAM data is lost, and the calibration data still cannot be read.

However, there was one different that caught my eye. Near the bottom of the source code (line 1023) the following line was removed from version 6.0.0:

delay(100); // workaround for https://github.com/esp8266/Arduino/issues/2750

I checked the issue, and it is still open, so I believe that line should not have been removed.

I would gladly supply log information (and also read the log myself) but I have not been able to figure out how to obtain them from the platform. (I have worked a lot with embedded platforms, so I feel a bit silly for not finding out...)

Hope this helps.

stefschin, 2019-05-20:
Hi, I have same problem with one of mine Ispindels with 6.0.5 firmware version. As I have others without problems I assume that firmware isn't the problem, as say Samuel, I assume it's a hardware problem with sensor... I need more tests to confirm that

universam1, 2019-05-20:
From my experience if the voltage of the battery is under 4V I could encounter issues to update the flash storage properly.
Turns out that the ESP8266 requires a higher voltage for this write operation than for normal intervals.

Especially this chip is very famous to be picky with power supply or creating various issues if under voltage.
Might be good to check how that actually looks like on these devices. And _always_ take the effort to attach the USB - serial console and monitor whats actually happening. The output should give you perfect insight if the data could be saved and read back later

stefschin, 2019-05-21:
My console monitor shows after calibration shows:

```
Testing device connections...
MPU6050 connection successful
averaging 1000 readings each time
expanding:
	XAccel			YAccel				ZAccel
[0,0] --> [22675,22408]	[0,0] --> [25171,24816]	[0,0] --> [5656,5912]
[-1000,0] --> [13502,22408]	[-1000,0] --> [16975,24816]	[0,0] --> [5654,5912]
[-2000,0] --> [4133,22408]	[-2000,0] --> [8599,24816]	[0,0] --> [5647,5912]
[-3000,0] --> [-5257,22408]	[-3000,0] --> [225,24816]	[0,0] --> [5649,5912]
[-3000,0] --> [-5474,22408]	[-4000,0] --> [-8169,24816]	[0,0] --> [5641,5912]
	XAccel			YAccel				ZAccel
[-3000,0] --> [-5474,22034]	[-4000,0] --> [-8169,24416]	[0,0] --> [5641,5644]
[-3000,0] --> [-5474,22657]	[-4000,0] --> [-8169,25141]	[0,1000] --> [5641,14207]
[-3000,0] --> [-5474,22661]	[-4000,0] --> [-8169,25142]	[0,2000] --> [5641,22945]
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
stefschin, 2019-05-21:
And after power ON:

```
s$
FW 6.0.6
3.0.0-dev(c0f7b44)
Worker run!
mounting FS... mounted!
reading config file
applying offsets
parsed config:
{"Name":"iSpindel002","Token":"97utjst0v334l8he32pgu89xxx","Sleep":30,"Server":"brew-spy.com","API":3,"Port":80,"URL":"/api/ispindel","DB":"ispindel","Username":"","Password":"","Job":"ispindel","Instance":"000","Vfact":198.1,"TS":0,"OWpin":12,"SSID":"WiFi-Arnet-rxxx","PSK":"xxx","POLY":"-0.00031*tilt^2+0.557*tilt-14.054","aX":-2417,"aY":-3001,"aZ":1231}
Boot-Mode: Deep-Sleep Wake

woken from deepsleep, normal mode
Samples:42 min:67.74 max:67.85 time:756
x: 7468 y: 17424 z: -4110
Tilt: 67.79
Tacc: 21.79
Volt: 4.01
Temp: 20.62
Gravity: 22.28
IP: 192.168.1.5

calling HTTP
{"name":"iSpindel002","ID":13067955,"token":"97utjst0v334l8he32pgu89xxx","angle":67.79447,"temperature":20.625,"temp_units":"C","battery":4.008077,"gravity":22.28273,"interval":30,"RSSI":-55}HTTPAPI: posting
code: 200
{
  "status" : 200,
  "ts" : "2019-05-20 23:01:10",
  "data" : { }
}

Final-sleep: 30s; RT: 1885
```
Can you traslate me where is the problem that Offset configuration goes back from 90º to 67º aprox?

ErikdBr, 2019-05-21:
I had the exact same problem, offset tilt went back from 89.999 something to 67 after a power off after  calibration and on the next day a power on.
I started the calibration again and laid the Ispindel on the exact same location where I measured the offset before. Outcome was about the same tilt of 89,something. Saved the configuration and power off and on again, after that everything seems fine. Voltage was above 4V and version of the firmware is 6.05

the51craw, 2019-05-21:
So, ErikdBr, if I understand you right, this is a problem that occurs only sometimes, not always nor never?
In that case maybe timing is an issue. Maybe the save operation not always is completed at the re-boot that occurs after calibration.

the51craw, 2019-05-21:
universam1, what you write makes absolute sense. So, there is nothing to do in the firmware unless some re-read check is done with an extra try to write. I do not think that makes much of a difference, it is better so make the recommendation to always fully charge the battery before calibration. Thanks for your info!

ErikdBr, 2019-05-21:
@the51craw It occured after the very first calibration. Next time I will pay more attention to this particular eledged problem, I still have to remove the input diode on the wemos and tweak the exact postion of the Ispindel in the tube. So I have to do the calibration over again anyway.

ErikdBr, 2019-05-22:
This is defenitely a problem. Yesterday I turned my Ispindel on and laid it flat on a 100% spirit level surface.
I expect to see a tilt of about 90 but I got 68.

stefschin, 2019-05-22:
Me too, every time I turn my Ispindel on I get 66-68 degrees. With full battery charge, maybe my battery is not working well, I will try with other hardware with same battery.

ErikdBr, 2019-05-22:
@stefschin did you remove the input diode on the wemos? If you didn't, did you by any chance hook up the wemos thru usb while a battery was attached?

stefschin, 2019-05-31:
Yes @ErikdBr , input diode is removed. I change Wemos D1 and problem still there. I changed the rest of hardware and just keep battery, and now is working great. Maybe it's a hardware problem that doesn't affect when it's version 5.8.6... I will continue to track the issue

CBBC2020, 2020-04-18:
Can anyone help me with my problem whereby my ISpindel is failing to connect to Brewfather. I attach Arduino Serial monitor output. TIA.
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

Closed 2018-09-24.

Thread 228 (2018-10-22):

Strange behaviour - Not sending data if not restarting under USB cable and Putty

Perimec, 2018-10-22:
Hi,
I'm experience a very strange behaviour of the inspidel. I have installed the lasted available firmware (6.0.1 even if it says 6.0.0 on the information tab). the inspidel is not sending data. It send the data only when pressing the reset button. However, if I reset while connecting the usb cable and with putty open, everything work fine. I have also tried to removed the usb connection and everything works after that.

I have tried also to switch it off and on again (while not connected and after that it was working) and again it stop sending data.

It seems that to let it start working i need the usb connection and putty.

I must admit, that because some wrong resistor on the battery reading, the battery is reading the wrong voltage of 4.7 but rather than that all the rest seems fine

thanks in advance for the help

Perimec, 2018-10-22:
Hi,
I'm experience a very strange behaviour of the inspidel. I have installed the lasted available firmware (6.0.1 even if it says 6.0.0 on the information tab). the inspidel is not sending data. It send the data only when pressing the reset button. However, if I reset while connecting the usb cable an using putty, everything work fine.

I must admit, that because some wrong resistor on the battery reading, the battery is reading the wrong voltage of 4.7 but rather than that all the rest seems fine

thanks in advance for the help

Perimec, 2018-10-22:
and yes confirmed, even removing the usb connection, everything work.

Perimec, 2018-10-22:
PS: I did not removed the diode on the wemos... going to do it asap... but still it should be not the problem for this.

universam1, 2018-10-23:
Set the interval to 10s and let it post several times. Attach these console logs here that should shed some light.

BTW there is the battery correction factor you need to adjust to reflect your correct voltage, but make sure your battery is charged fully!

Perimec, 2018-10-23:
Thanks :) I will do it later today :)

Perimec, 2018-10-23:
Hi, following the log.

I have checked again the connection, there was a small problem with the voltage. Fixed it and all the rest seems ok. However still not working propertly. If I plug the usb, it works fine (even after removing the USB), otherwise it doesn't work (send data only when pressing the reset).

thanks again for the help.

{dd▒▒|▒d▒<
▒
l▒c|▒▒▒{▒b▒
b▒▒og▒dno▒▒▒
cp▒▒$sd{dp▒o▒
▒d
▒▒
c
g▒|d▒
▒c▒▒no▒l▒▒d`▒gn$`'s▒▒▒o
c▒lr▒▒n
#
▒l▒
l`▒n▒
     FW 6.0.0
2.2.1(cfd48f3)
Worker run!
mounting FS... mounted!
reading config file
offsets not available
parsed config:
{"Name":"iSpindel000","Token":"XXXXXXXXXXXXXXX","Sleep":20,"S                                                                                                      erver":"","API":0,"Port":80,"URL":"","DB":"ispindel","Username":"","Password":""                                                                                                      ,"Job":"ispindel","Instance":"000","Vfact":229,"TS":0,"OWpin":12,"SSID":"Telenor                                                                                                      9498vel","PSK":"XXXXXXXXXXXX","POLY":"-0.00031*tilt^2+0.557*tilt-14.054","aX":0                                                                                                      ,"aY":0,"aZ":0}
Boot-Mode: Deep-Sleep Wake

woken from deepsleep, normal mode
Samples:42 min:85.22 max:86.01 time:755
x: 876 y: 16544 z: -966
Tilt: 85.57
Tacc: 25.69
Volt: 4.47
Temp: 21.44
Gravity: 31.34
After waiting 501ms, result 3
IP: 10.0.0.55

calling Ubidots
{"tilt":85.57055,"temperature":21.4375,"battery":4.471616,"gravity":31.33888,"in                                                                                                      terval":20,"RSSI":-63}
                      Sender: Ubidots posting
POST /api/v1.6/devices/iSpindel000?token=XXXXXXXXXXXXXXXXX HTTP                                                                                                      /1.1
Host: things.ubidots.com
User-Agent: ESP8266
Connection: close
Content-Type: application/json
Content-Length: 102

HTTP/1.1 200 OK
Server: nginx
Date: Tue, 23 Oct 2018 19:55:28 GMT
Content-Type: application/json
Transfer-Encoding: chunked
Connection: close
Vary: Accept-Encoding
Vary: Cookie
Allow: GET, POST, HEAD, OPTIONS

d1
{"temperature": [{"status_code": 201}], "battery": [{"status_code": 201}], "tilt                                                                                                      ": [{"status_code": 201}], "interval": [{"status_code": 201}], "gravity": [{"sta                                                                                                      tus_code": 201}], "rssi": [{"status_code": 201}]}
0

Final-sleep: 20s; RT: 2743
sdl▒▒|▒l▒|▒
l▒b|▒▒▒{▒c▒
c▒▒oo▒lgn▒▒▒
cx▒▒dsl{dx▒n▒
▒dĜ
bo▒|l▒▒c▒▒'n▒l▒▒l ▒gd`gsǓ▒o
c
▒l{▒▒gc
▒d▒
d`▒g▒
     FW 6.0.0
2.2.1(cfd48f3)
Worker run!
mounting FS... mounted!
reading config file
offsets not available
parsed config:
{"Name":"iSpindel000","Token":"XXXXXXXXXXXXXXXXXX,"Sleep":20,"S                                                                                                      erver":"","API":0,"Port":80,"URL":"","DB":"ispindel","Username":"","Password":""                                                                                                      ,"Job":"ispindel","Instance":"000","Vfact":229,"TS":0,"OWpin":12,"SSID":"Telenor                                                                                                      9498vel","PSK":"XXXXXXXXXXXXXX","POLY":"-0.00031*tilt^2+0.557*tilt-14.054","aX":0                                                                                                      ,"aY":0,"aZ":0}
Boot-Mode: Deep-Sleep Wake

woken from deepsleep, normal mode
Samples:42 min:85.63 max:85.77 time:755
x: 814 y: 16456 z: -960
Tilt: 85.69
Tacc: 25.59
Volt: 4.47
Temp: 21.50
Gravity: 31.40
After waiting 2101ms, result 3
IP: 10.0.0.55

calling Ubidots
{"tilt":85.69248,"temperature":21.5,"battery":4.471616,"gravity":31.40032,"inter                                                                                                      val":20,"RSSI":-58}
                   Sender: Ubidots posting
POST /api/v1.6/devices/iSpindel000?token=XXXXXXXXXXXXXXXXXXXXXX HTTP                                                                                                      /1.1
Host: things.ubidots.com
User-Agent: ESP8266
Connection: close
Content-Type: application/json
Content-Length: 99

HTTP/1.1 200 OK
Server: nginx
Date: Tue, 23 Oct 2018 19:55:52 GMT
Content-Type: application/json
Transfer-Encoding: chunked
Connection: close
Vary: Accept-Encoding
Vary: Cookie
Allow: GET, POST, HEAD, OPTIONS

d1
{"temperature": [{"status_code": 201}], "battery": [{"status_code": 201}], "tilt                                                                                                      ": [{"status_code": 201}], "interval": [{"status_code": 201}], "gravity": [{"sta                                                                                                      tus_code": 201}], "rssi": [{"status_code": 201}]}
0

Final-sleep: 20s; RT: 4273
rll▒▒|▒l▒|
▒l▒
c|▒▒▒▒s▒c▒
c▒▒nn▒lgg▒▒▒cp▒▒l;lslx▒g▒▒
l▒▒
cn▒|l▒
▒c▒▒gg▒d▒▒l`▒g
l`o;▒▒▒nc
▒${▒▒g
c▒d▒
d`▒g▒
     FW 6.0.0
2.2.1(cfd48f3)
Worker run!
mounting FS... mounted!
reading config file
offsets not available
parsed config:
{"Name":"iSpindel000","Token":"XXXXXXXXXXXXXXXXXXX","Sleep":20,"S                                                                                                      erver":"","API":0,"Port":80,"URL":"","DB":"ispindel","Username":"","Password":""                                                                                                      ,"Job":"ispindel","Instance":"000","Vfact":229,"TS":0,"OWpin":12,"SSID":"Telenor                                                                                                      9498vel","PSK":"XXXXXXXXXXXXXXX","POLY":"-0.00031*tilt^2+0.557*tilt-14.054","aX":0                                                                                                      ,"aY":0,"aZ":0}
Boot-Mode: Deep-Sleep Wake

woken from deepsleep, normal mode
Samples:42 min:86.02 max:86.12 time:754
x: 646 y: 16450 z: -946
Tilt: 86.07
Tacc: 25.49
Volt: 4.47
Temp: 21.50
Gravity: 31.59
After waiting 600ms, result 3
IP: 10.0.0.55

calling Ubidots
{"tilt":86.07482,"temperature":21.5,"battery":4.471616,"gravity":31.59292,"inter                                                                                                      val":20,"RSSI":-56}
                   Sender: Ubidots posting
POST /api/v1.6/devices/iSpindel000?token=XXXXXXXXXXXXXXXXXXXXX HTTP                                                                                                      /1.1
Host: things.ubidots.com
User-Agent: ESP8266
Connection: close
Content-Type: application/json
Content-Length: 99

HTTP/1.1 200 OK
Server: nginx
Date: Tue, 23 Oct 2018 19:56:14 GMT
Content-Type: application/json
Transfer-Encoding: chunked
Connection: close
Vary: Accept-Encoding
Vary: Cookie
Allow: GET, POST, HEAD, OPTIONS

d1
{"temperature": [{"status_code": 201}], "battery": [{"status_code": 201}], "tilt                                                                                                      ": [{"status_code": 201}], "interval": [{"status_code": 201}], "gravity": [{"sta                                                                                                      tus_code": 201}], "rssi": [{"status_code": 201}]}
0

Final-sleep: 20s; RT: 2936
sll▒▒|▒l▒|
▒l▒
c|▒▒▒▒s▒c▒
c▒▒no▒lgg▒▒▒cx▒▒lrlslx▒g▒
▒
l▒▒
cn▒|l▒
▒c▒▒gg▒dćl`▒g
d`or▒▒▒n
#
▒l{▒▒g
c▒d▒
d`▒▒g▒
      FW 6.0.0
2.2.1(cfd48f3)
Worker run!
mounting FS... mounted!
reading config file
offsets not available
parsed config:
{"Name":"iSpindel000","Token":"XXXXXXXXXXXXXXXXXX","Sleep":20,"S                                                                                                      erver":"","API":0,"Port":80,"URL":"","DB":"ispindel","Username":"","Password":""                                                                                                      ,"Job":"ispindel","Instance":"000","Vfact":229,"TS":0,"OWpin":12,"SSID":"Telenor                                                                                                      9498vel","PSK":"XXXXXXXXXXXX","POLY":"-0.00031*tilt^2+0.557*tilt-14.054","aX":0                                                                                                      ,"aY":0,"aZ":0}
Boot-Mode: Deep-Sleep Wake

woken from deepsleep, normal mode
Samples:42 min:85.72 max:85.97 time:756
x: 724 y: 16482 z: -946
Tilt: 85.87
Tacc: 25.33
Volt: 4.47
Temp: 21.44
Gravity: 31.49
After waiting 2001ms, result 3
IP: 10.0.0.55
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
Perimec, 2018-10-26:
Hi, so anything strange that youy can spot?

thanks

Perimec, 2018-10-26:
check the voltage... 4.1V.... charged sometime ago... then I really don't know where it can be the problem.. I shuld check the voltage under load. keep you posted.. but I can use as it is anyway... just need to let it start while connected under USB...

thanks again for this amazing project.

bye

Perimec, 2018-10-26:
bzttery fine also under loading...

rasale12, 2018-12-07:
Hello Perimec
i've the same problem, my two ispindle sends data to craftbeerpi only when I push the reset button. i never use Putty, what i have to do with?

Perimec, 2018-12-10:
just download putty, select the rigth com port and then plug the usb in the wemos. Reastart the womos and wait check the info on the screen

universam1, 2019-02-27:
no activity here, going to close

Closed 2019-02-27.

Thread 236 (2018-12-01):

wifi visibility problem

rasale12, 2018-12-01:
Hello folks, i'm trying my new setup for controlling the fermentation of 4 keg with craftbeerpi and all works fine. I want to use 2 ispindle i've bought for take the input temperature but i didn't find the devices over wi-fi. I pull the switch of the ispindle, the blu led blink 3 times very fast but nothing happens..

Misenkooo, 2018-12-01:
You need to press it twice within a second to switch into config mode - blue diode must be blinking. Otherwise you will never see them because they are not in AP mode. You may connect in into PC and check in debug mode what's going on.

rasale12, 2018-12-07:
Hello, now i config my two ispindle and I connect to my wifi network. I create in craftbeerpi my 2 fermenter and I create 3 sensor (temperature, battery voltage, density) each ones. At the moment I create the sensor I can see the right value but there is no refresh (i set 15s in ap mode). If reset manually the ispindle pressing the switch there is a refresh of the value. what's going wrong?
thank you
Alessio

universam1, 2018-12-10:
Your reset pin wiring is not correct. Also always investigate the log output first

Closed 2018-12-10.

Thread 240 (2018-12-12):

Missing reports from iSpindel

terragady, 2018-12-12:
I have set iSpindel to report every 15 minutes, I do use brewpiless in the AP+Station mode so iSpindel is directly reporting to BrewPiless network.
Every some time I am missing reports, sometimes even 2-3 in a row. Does anyone has this issue?

universam1, 2018-12-14:
check your wifi reception RSSI to be good enough

terragady, 2018-12-14:
RSSI of brewpiless? I can check only that but this is RSSI of BrewPiLess <-> my router and iSpindel is reporting directly to BPL station (to 192.168.4.1) and not my home network as there is no signal in the freezer of my home network. The BPL device is attached to freezer wall so the distance is 10-15cm between iSpindel and BPL, of course there is also a freezer wall in between but it should be good.
Anyway to check the RSSI of iSpindel<->BPL connection? Now it is in mid fermentation so can not switch to service mode in iSpindel

Misenkooo, 2018-12-14:
I had the same problem, transmission was very unreliable and lost lot of reports despite a repeater next to the fermentor. Also had very poor battery life. Switched to firmware v5.x and problems solved. But I switched to raspberry pi and tcp server so this may helped as well.

terragady, 2018-12-14:
yes I also heard from Vito that on his test setup iSpindel was stopping reporting after some time and he went back to version before v6. I have no problems with battery life. 14 days went from 4.21 to 4.18 with 15min interval time and some playing and calibrating at the beginning.
@Misenkooo you mean you do not use BPL at all? You just collect data from iSpindel on RPi? Is that right?

For next brew or tests after brew I will switch back to 5.x version and check if that helps.

universam1, 2018-12-18:
If the iSpindel cannot make a Wifi connection within 5s it will break and go to sleep until next iteration. This can happen if you are on the border of wifi limits. Thats why I mention check the RSSI sent metric to see if that is the case.

Closed 2019-05-19.

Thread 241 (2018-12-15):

Single post to Ubidots

mrpalmer84, 2018-12-15:
Hi there,

I've got the iSpindel built and running, looking at the config pages it appears that the accelerometers and temp sensors are working well. The same with ubidots, however, I only ever get one post to Ubidots coming out of config and then nothing more, reading the logs I get one good output then something unintelligible, probably related to baud rate, and then nothing more. Is this something that someone has had before?

Thanks

R

tizoc, 2018-12-16:
I had this issue, looking at the logs my conclusion was that there was a timeout when trying to connect to the router. I changed the source code to increase the timeout (the value is hardcoded and not configurable), and thats how I solved the issue.

What I did was increase this number: https://github.com/universam1/iSpindel/blob/master/pio/src/iSpindel.cpp#L1200

A better solution would be to make this configurable.

mrpalmer84, 2018-12-16:
Thank you for the suggestion.

Unfortunately that doesn't appear to be my issue, I raised the wait to 15000 and with the 100 millisecond delay per iteration that should have produced a noticable delay to the output in the log if I was looping there but it appeared immediately on the 20s that I have configured to debug this.

Thanks anyway

R

tizoc, 2018-12-16:
@mrpalmer84 one thing, note that the variable that holds the wait variable is an `uint_8`, that makes 255 the maximum value you can use there, you may want to try 255 instead (or increase the delay from 100 to something bigger).

If you apply this diff you are going to get a new setting that lets you set the timeout in seconds:

https://gist.github.com/tizoc/81b241498879af15496220e7ec86a1b0

255 seconds is the maximum value, but if thats not enough to solve timeout issues nothing is.

@universam1 let me know if you want me to submit that change as a pull request (not sure if you are interested in adding that setting).

mrpalmer84, 2018-12-17:
Hi there,

I checked again, it doesn't appear to be the Wifi issue (at least as far as I can tell). I dropped some debugging logging in the disconnected while loop and I never hit it when listening with putty.

The last few lines of my log output are:

Final-sleep: 20s; RT: 3661
rld▒▒|▒d▒|
▒d▒b|▒▒▒▒r▒cl▒c▒▒nn▒lgg▒▒▒
cp▒▒lslsl▒s▒g▒c▒gcx

I'm hoping this means something to someone, I suspect that the baud rate is reset so I'm not getting good logging after waking

R

universam1, 2018-12-18:
thats a definite hardware issue. Your device does not boot up after reset. Either your power is too low (test it with voltage >4V) or the ESP is really broken. Also a floating RST pin could make that issue.

universam1, 2018-12-18:
@tizoc This value is actually a 'fuse' to prevent your iSpindle to forever unhappily wait on a Wifi connection when not possible for some reason, and draining your battery in a short time. Anyway you are in an unhappy connection state, but next iteration might be better - better than a dead battery.

Closed 2018-12-18.

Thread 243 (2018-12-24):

6.x.x not come into config mode

brunoheins, 2018-12-24:
Hi,
I’m trying to update to 6.x version but I can’t start the config mode. The flashing led is very short when I reboot the ESP to enter configuration mode. I see the wifi point, but the power drops when I try to connect. I don't know what's wrong, but it doesn't happen with 5.x.x versions only for all 6.x version.
Any idea?

universam1, 2018-12-24:
Where is the log file?

brunoheins, 2018-12-24:
Log for 5.9.4 version - working config mode

PORT OPEN 115200

Communication with MCU..Got answer! Communication with MCU established.
AutoDetect firmware...

Can't autodetect firmware, because proper answer not received (may be unknown firmware).
Please, reset module or continue.
FW 5.9.1
3.0.0-dev(c0f7b44)
Worker run!
Boot-Mode: 5
mounting FS... mounted!

ERROR config corrupted
...........
ERROR no Wifi credentials

going to Config Mode
I2C ERROR: 0 con:0
ERROR: OW DISCONNECTED
I2C ERROR: 0 con:0
ERROR: OW DISCONNECTED
*WM: Scan done
*WM: DUP AP: #NET-CLARO-WIFI
*WM: DUP AP: #NET-CLARO-WIFI
*WM: Adding parameter
*WM: name
*WM: Adding parameter
*WM: sleep
*WM: Adding parameter
*WM: vfact
*WM: Adding parameter
*WM:
*WM: Adding parameter
*WM:
*WM: Adding parameter
*WM: tempscale
*WM: Adding parameter
*WM:
*WM: Adding parameter
*WM:
*WM: Adding parameter
*WM: selAPI
*WM: Adding parameter
*WM: token
*WM: Adding parameter
*WM: server
*WM: Adding parameter
*WM: port
*WM: Adding parameter
*WM: url
*WM: Adding parameter
*WM: db
*WM: Adding parameter
*WM: username
*WM: Adding parameter
*WM: password
*WM: Adding parameter
*WM: job
*WM: Adding parameter
*WM: instance
*WM: Adding parameter
*WM:
*WM: Adding parameter
*WM: POLYN
started Portal
*WM: SET AP
*WM:
*WM: Configuring access point...
*WM: iSpindel
*WM: Custom AP IP/GW/Subnet
*WM: AP IP address:
*WM: 192.168.244.1
*WM: HTTP server started
I2C ERROR: 0 con:0
ERROR: OW DISCONNECTED
I2C ERROR: 0 con:0
ERROR: OW DISCONNECTED
I2C ERROR: 0 con:0
ERROR: OW DISCONNECTED
I2C ERROR: 0 con:0
ERROR: OW DISCONNECTED
I2C ERROR: 0 con:0
ERROR: OW DISCONNECTED

PORT CLOSED

brunoheins, 2018-12-24:
log for 6.0.4 - not working config mode

PORT OPEN 115200

Communication with MCU..Got answer! Communication with MCU established.
AutoDetect firmware...

Can't autodetect firmware, because proper answer not received (may be unknown firmware).
Please, reset module or continue.

FW 6.0.4
2.2.1(cfd48f3)
Worker run!
mounting FS... mounted!
scanning for OW device on pin: 5
No devices found!
scanning for OW device on pin: 12
No devices found!
scanning for OW device on pin: 116
No devices found!
scanning for OW device on pin: 121
No devices found!
ERROR: cannot find a OneWire Temperature Sensor!
Acc Test Connection ERROR!
Boot-Mode: External System
power-cycle or reset detected, config mode

Double Reset detected
...........
ERROR no Wifi credentials

going to Config Mode
reboot RFCAL

FW 6.0.4
2.2.1(cfd48f3)
Worker run!
mounting FS... mounted!
scanning for OW device on pin: 5
No devices found!
scanning for OW device on pin: 12
No devices found!
scanning for OW device on pin: 116
No devices found!
scanning for OW device on pin: 121
No devices found!
ERROR: cannot find a OneWire Temperature Sensor!
Acc Test Connection ERROR!
Boot-Mode: Deep-Sleep Wake

Double Reset detected
...........
ERROR no Wifi credentials

going to Config Mode
Acc Test Connection ERROR!

Exception (28):
epc1=0x4020e5c3 epc2=0x00000000 epc3=0x00000000 excvaddr=0x00000000 depc=0x00000000

ctx: sys
sp: 3fffed00 end: 3fffffb0 offset: 01a0

>>>stack>>>
3fffeea0:  00339913 c160dd2f 3fff1ffc 401006dc
3fffeeb0:  00000002 00000004 3fff1ffc 4020118d
3fffeec0:  00339913 3ffef6a0 3fff1ffc 40209bc0
3fffeed0:  3ffe8e0f 3fffef10 00000000 00000000
3fffeee0:  3ffe8e14 3fffef08 00000000 00000000
3fffeef0:  00000000 00000000 00000000 40209478
3fffef00:  00339913 3ffef6a0 3ffefed8 4020eed2
3fffef10:  00000000 00000000 3ffefca0 40209314
3fffef20:  00339913 3ffef6a0 3fff1d7c 40209c4c
3fffef30:  60000600 3fff1d7c 3ffef6a0 40249175
3fffef40:  402491ba 3fffdab0 00000000 3fffdcb0
3fffef50:  3ffef6c8 3fffdab0 00000000 00000004
3fffef60:  40000f49 40000f49 3fffdab0 40000f49
3fffef70:  40000e19 40001878 00000002 00000000
3fffef80:  3fffff10 aa55aa55 00000045 4010441c
3fffef90:  40104422 00000002 00000000 86bac8be
3fffefa0:  4010000d 558042ff abffe145 28596d93
3fffefb0:  40100764 3fffef4c 40100705 3ffffb78
3fffefc0:  3fffffd0 00000000 00000000 feefeffe
3fffefd0:  feefeffe feefeffe feefeffe feefeffe
3fffefe0:  feefeffe feefeffe feefeffe feefeffe
3fffeff0:  feefeffe feefeffe feefeffe feefeffe
3ffff000:  feefeffe feefeffe feefeffe feefeffe
3ffff010:  feefeffe feefeffe feefeffe feefeffe
3ffff020:  feefeffe feefeffe feefeffe feefeffe
3ffff030:  feefeffe feefeffe feefeffe feefeffe
3ffff040:  feefeffe feefeffe feefeffe feefeffe
3ffff050:  feefeffe feefeffe feefeffe feefeffe
3ffff060:  feefeffe feefeffe feefeffe feefeffe
3ffff070:  feefeffe feefeffe feefeffe feefeffe
3ffff080:  feefeffe feefeffe feefeffe feefeffe
3ffff090:  feefeffe feefeffe feefeffe feefeffe
3ffff0a0:  feefeffe feefeffe feefeffe feefeffe
3ffff0b0:  feefeffe feefeffe feefeffe feefeffe
3ffff0c0:  feefeffe feefeffe feefeffe feefeffe
3ffff0d0:  feefeffe feefeffe feefeffe feefeffe
3ffff0e0:  feefeffe feefeffe feefeffe feefeffe
3ffff0f0:  feefeffe feefeffe feefeffe feefeffe
3ffff100:  feefeffe feefeffe feefeffe feefeffe
3ffff110:  feefeffe feefeffe feefeffe feefeffe
3ffff120:  feefeffe feefeffe feefeffe feefeffe
3ffff130:  feefeffe feefeffe feefeffe feefeffe
3ffff140:  feefeffe feefeffe feefeffe feefeffe
3ffff150:  feefeffe feefeffe feefeffe feefeffe
3ffff160:  feefeffe feefeffe feefeffe feefeffe
3ffff170:  feefeffe feefeffe feefeffe feefeffe
3ffff180:  feefeffe feefeffe feefeffe feefeffe
3ffff190:  feefeffe feefeffe feefeffe feefeffe
3ffff1a0:  feefeffe feefeffe feefeffe feefeffe
3ffff1b0:  feefeffe feefeffe feefeffe feefeffe
3ffff1c0:  feefeffe feefeffe feefeffe feefeffe
3ffff1d0:  feefeffe feefeffe feefeffe feefeffe
3ffff1e0:  feefeffe feefeffe feefeffe feefeffe
3ffff1f0:  feefeffe feefeffe feefeffe feefeffe
3ffff200:  feefeffe feefeffe feefeffe feefeffe
3ffff210:  feefeffe feefeffe feefeffe feefeffe
3ffff220:  feefeffe feefeffe feefeffe feefeffe
3ffff230:  feefeffe feefeffe feefeffe feefeffe
3ffff240:  feefeffe feefeffe feefeffe feefeffe
3ffff250:  feefeffe feefeffe feefeffe feefeffe
3ffff260:  feefeffe feefeffe feefeffe feefeffe
3ffff270:  feefeffe feefeffe feefeffe feefeffe
3ffff280:  feefeffe feefeffe feefeffe feefeffe
3ffff290:  feefeffe feefeffe feefeffe feefeffe
3ffff2a0:  feefeffe feefeffe feefeffe feefeffe
3ffff2b0:  feefeffe feefeffe feefeffe feefeffe
3ffff2c0:  feefeffe feefeffe feefeffe feefeffe
3ffff2d0:  feefeffe feefeffe feefeffe feefeffe
3ffff2e0:  feefeffe feefeffe feefeffe feefeffe
3ffff2f0:  feefeffe feefeffe feefeffe feefeffe
3ffff300:  feefeffe feefeffe feefeffe feefeffe
3ffff310:  feefeffe feefeffe feefeffe feefeffe
3ffff320:  feefeffe feefeffe feefeffe feefeffe
3ffff330:  feefeffe feefeffe feefeffe feefeffe
3ffff340:  feefeffe feefeffe feefeffe feefeffe
3ffff350:  feefeffe feefeffe feefeffe feefeffe
3ffff360:  feefeffe feefeffe feefeffe feefeffe
3ffff370:  feefeffe feefeffe feefeffe feefeffe
3ffff380:  feefeffe feefeffe feefeffe feefeffe
3ffff390:  feefeffe feefeffe feefeffe feefeffe
3ffff3a0:  feefeffe feefeffe feefeffe feefeffe
3ffff3b0:  feefeffe feefeffe feefeffe feefeffe
3ffff3c0:  feefeffe feefeffe feefeffe feefeffe
3ffff3d0:  feefeffe feefeffe feefeffe feefeffe
3ffff3e0:  feefeffe feefeffe feefeffe feefeffe
3ffff3f0:  feefeffe feefeffe feefeffe feefeffe
3ffff400:  feefeffe feefeffe feefeffe feefeffe
3ffff410:  feefeffe feefeffe feefeffe feefeffe
3ffff420:  feefeffe feefeffe feefeffe feefeffe
3ffff430:  feefeffe feefeffe feefeffe feefeffe
3ffff440:  feefeffe feefeffe feefeffe feefeffe
3ffff450:  feefeffe feefeffe feefeffe feefeffe
3ffff460:  feefeffe feefeffe feefeffe feefeffe
3ffff470:  feefeffe feefeffe feefeffe feefeffe
3ffff480:  feefeffe feefeffe feefeffe feefeffe
3ffff490:  feefeffe feefeffe feefeffe feefeffe
3ffff4a0:  feefeffe feefeffe feefeffe feefeffe
3ffff4b0:  feefeffe feefeffe feefeffe feefeffe
3ffff4c0:  feefeffe feefeffe feefeffe feefeffe
3ffff4d0:  feefeffe feefeffe feefeffe feefeffe
3ffff4e0:  feefeffe feefeffe feefeffe feefeffe
3ffff4f0:  feefeffe feefeffe feefeffe feefeffe
3ffff500:  feefeffe feefeffe feefeffe feefeffe
3ffff510:  feefeffe feefeffe feefeffe feefeffe
3ffff520:  feefeffe feefeffe feefeffe feefeffe
3ffff530:  feefeffe feefeffe feefeffe feefeffe
3ffff540:  feefeffe feefeffe feefeffe feefeffe
3ffff550:  feefeffe feefeffe feefeffe feefeffe
3ffff560:  feefeffe feefeffe feefeffe feefeffe
3ffff570:  feefeffe feefeffe feefeffe feefeffe
3ffff580:  feefeffe feefeffe feefeffe feefeffe
3ffff590:  feefeffe feefeffe feefeffe feefeffe
3ffff5a0:  feefeffe feefeffe feefeffe feefeffe
3ffff5b0:  feefeffe feefeffe feefeffe feefeffe
3ffff5c0:  feefeffe feefeffe feefeffe feefeffe
3ffff5d0:  feefeffe feefeffe feefeffe feefeffe
3ffff5e0:  feefeffe feefeffe feefeffe feefeffe
3ffff5f0:  feefeffe feefeffe feefeffe feefeffe
3ffff600:  feefeffe feefeffe feefeffe feefeffe
3ffff610:  feefeffe feefeffe feefeffe feefeffe
3ffff620:  feefeffe feefeffe feefeffe feefeffe
3ffff630:  feefeffe feefeffe feefeffe feefeffe
3ffff640:  feefeffe feefeffe feefeffe feefeffe
3ffff650:  feefeffe feefeffe feefeffe feefeffe
3ffff660:  feefeffe feefeffe feefeffe feefeffe
3ffff670:  feefeffe feefeffe feefeffe feefeffe
3ffff680:  feefeffe feefeffe feefeffe feefeffe
3ffff690:  feefeffe feefeffe feefeffe feefeffe
3ffff6a0:  feefeffe feefeffe feefeffe feefeffe
3ffff6b0:  feefeffe feefeffe feefeffe feefeffe
3ffff6c0:  feefeffe feefeffe feefeffe feefeffe
3ffff6d0:  feefeffe feefeffe feefeffe feefeffe
3ffff6e0:  feefeffe feefeffe feefeffe feefeffe
3ffff6f0:  feefeffe feefeffe feefeffe feefeffe
3ffff700:  feefeffe feefeffe feefeffe feefeffe
3ffff710:  feefeffe feefeffe feefeffe feefeffe
3ffff720:  feefeffe feefeffe feefeffe feefeffe
3ffff730:  feefeffe feefeffe feefeffe feefeffe
3ffff740:  feefeffe feefeffe feefeffe feefeffe
3ffff750:  feefeffe feefeffe feefeffe feefeffe
3ffff760:  feefeffe feefeffe feefeffe feefeffe
3ffff770:  feefeffe feefeffe feefeffe feefeffe
3ffff780:  feefeffe feefeffe feefeffe feefeffe
3ffff790:  feefeffe feefeffe feefeffe feefeffe
3ffff7a0:  feefeffe feefeffe feefeffe feefeffe
3ffff7b0:  feefeffe feefeffe feefeffe feefeffe
3ffff7c0:  feefeffe feefeffe feefeffe feefeffe
3ffff7d0:  feefeffe feefeffe feefeffe feefeffe
3ffff7e0:  feefeffe feefeffe feefeffe feefeffe
3ffff7f0:  feefeffe feefeffe feefeffe feefeffe
3ffff800:  feefeffe feefeffe feefeffe feefeffe
3ffff810:  feefeffe feefeffe feefeffe feefeffe
3ffff820:  feefeffe feefeffe feefeffe feefeffe
3ffff830:  feefeffe feefeffe feefeffe feefeffe
3ffff840:  feefeffe feefeffe feefeffe feefeffe
3ffff850:  feefeffe feefeffe feefeffe feefeffe
3ffff860:  feefeffe feefeffe feefeffe feefeffe
3ffff870:  feefeffe feefeffe feefeffe feefeffe
3ffff880:  feefeffe feefeffe feefeffe feefeffe
3ffff890:  feefeffe feefeffe feefeffe feefeffe
3ffff8a0:  feefeffe feefeffe feefeffe feefeffe
3ffff8b0:  feefeffe feefeffe feefeffe feefeffe
3ffff8c0:  feefeffe feefeffe feefeffe feefeffe
3ffff8d0:  feefeffe feefeffe feefeffe feefeffe
3ffff8e0:  feefeffe feefeffe feefeffe feefeffe
3ffff8f0:  feefeffe feefeffe feefeffe feefeffe
3ffff900:  feefeffe feefeffe feefeffe feefeffe
3ffff910:  feefeffe feefeffe feefeffe feefeffe
3ffff920:  feefeffe feefeffe feefeffe feefeffe
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
vytux-com, 2018-12-24:
It's been noted before that this firmware will only work if everything is properly built and you seem to be missing the temp sensor so of cause it's not going to work.

BTW both versions are giving you the same error

universam1, 2018-12-25:
Thanks for the comment, that’s indeed true and the case here. Hence we can close the issue

brunoheins, 2018-12-29:
You're right, I did not read the notes. I'm sorry for this. Happy 2019 for everyone. Tks!!

Closed 2018-12-25.

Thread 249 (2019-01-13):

iSpindel not working on battery power

xned, 2019-01-13:
Not sure if this is good place to post this but I could not find any other English forums, feel free to refer me to a forum better suited for this issue.

Background (feel free to skip to the problem part):
I order the iSpindel kit from http://3D-Mechatronics.de, received it well packaged and with no visible damage to any components.

I soldered the components according to the English soldering guide (https://brewlab.blog/wp-content/uploads/2017/10/DIY_Spindel_Anleitung_En.pdf) I don't think my soldering was any worse than it normally is so it should be okay.

I did final assembly, powered trough the charging USB and flashed firmware trough the WeMos USB. That done I managed to connect to the iSpindel SSID, did basic config for WiFi, changed interval to every 20sec for testing and setup, created a ubidots account, put the token in the iSpindel config and looking at ubidots I can see that the iSpindel created a device and is sending data.

The Problem:
When disconnecting the USB to the charger the iSpindel dies. All diodes go dark and it stops reporting data. I Thought it might just be power saving (deep sleep) so I left if for a couple of hours, still no data. I'm not sure how the WeMos is powered but I saw someone mentioned the 5v pin so I took a multimeter to that and what I can see is that when the charger is connected to USB and everything is working I get about 4v on the 5v pin, running on battery it fluctuates from0,8v to 1,7v. Measuring directly on the battery I get 3,65V.

Any idea what I'm doing wrong here? Or do I maybe have a bad battery or charging unit?

universam1, 2019-02-27:
Probably the battery charging module is defect

Closed 2019-02-27.

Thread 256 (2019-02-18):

6.0.4 - cloud service parameters not saved

ploufe, 2019-02-18:
Hi,

Since I updated my device in 6.0.4. version I can no longer saved my service cloud configuration.
I'd like to use a HTTP server.
I write all config parameters, clic on "save" button,
but after reboot my ispindle always display "Ubidot" (instead of "HTTP")...

Any idea to solve it?

universam1, 2019-02-18:
Please send a log output

ckrack, 2019-02-24:
I can confirm the problem on 6.0.2

I'm posting my log - I set the TCP server yesterday and upon first switching the device on it sends data correctly.

```log
12:32:44.040 -> FW 6.0.2
12:32:44.040 -> 3.0.0-dev(c0f7b44)
12:32:44.040 -> Worker run!
12:32:44.040 -> mounting FS... mounted!
12:32:44.040 -> reading config file
12:32:44.040 -> offsets not available
12:32:44.040 -> parsed config:
12:32:44.075 -> {"Name":"Spindel_Stern","Token":"foobar","Sleep":900,"Server":"example.com","API":6,"Port":61085,"URL":"","DB":"ispindel","Username":"","Password":"","Job":"ispindel","Instance":"000","Vfact":191.8,"TS":0,"OWpin":12,"SSID":"Foobar","PSK":"foobar","POLY":"-0.00031*tilt^2+0.557*tilt-14.054","aX":0,"aY":0,"aZ":0}
Boot-Mode: Deep-Sleep Wake
12:32:44.248 ->
12:32:44.248 -> woken from deepsleep, normal mode
Samples:42 min:63.64 max:63.67 time:755
12:32:45.014 -> x: -9992 y: 12492 z: -1928
12:32:45.014 -> Tilt: 63.66
12:32:45.014 -> Tacc: 16.72
12:32:45.014 -> Volt: 5.34
12:32:45.048 -> Temp: 19.44
12:32:45.048 -> Gravity: 20.15
12:32:45.048 -> After waiting 201ms, result 3
12:32:45.255 -> IP: 192.168.178.40
12:32:45.255 ->
12:32:45.255 -> calling TCP
12:32:45.255 -> {"name":"Spindel_Stern","ID":3937792,"token":"foobar","angle":63.66018,"temperature":19.4375,"temp_units":"C","battery":5.338894,"gravity":20.14841,"interval":900,"RSSI":-68}
12:32:45.322 -> Sender: TCP stream

12:32:47.485 -> Final-sleep: 900s; RT: 3512
rld⸮⸮|⸮l⸮|

⸮
d⸮ c|⸮⸮ ⸮ ⸮r⸮c⸮
#⸮⸮no⸮loo⸮⸮⸮
c
x⸮⸮drlslp⸮o⸮

⸮
l
⸮⸮   c
o⸮| l⸮

⸮#⸮⸮no⸮$⸮⸮l` ⸮  oo l`   gr⸮⸮⸮'  c ⸮ l {ےg

c
⸮ l⸮

l` ⸮⸮o⸮
12:34:41.982 -> FW 6.0.2
12:34:41.982 -> 3.0.0-dev(c0f7b44)
12:34:41.982 -> Worker run!
12:34:41.982 -> mounting FS... mounted!
12:34:41.982 -> reading config file
12:34:41.982 -> offsets not available
12:34:41.982 -> parsed config:
12:34:41.982 -> {"Name":"Spindel_Stern","Token":"foobar","Sleep":900,"Server":"example.com","API":6,"Port":61085,"URL":"","DB":"ispindel","Username":"","Password":"","Job":"ispindel","Instance":"000","Vfact":191.8,"TS":0,"OWpin":12,"SSID":"Foobar","PSK":"foobar","POLY":"-0.00031*tilt^2+0.557*tilt-14.054","aX":0,"aY":0,"aZ":0}
rld⸮⸮|⸮d⸮|

 ⸮ d⸮ c|⸮⸮ ⸮ ⸮s⸮c⸮ b⸮⸮oo⸮lgg⸮⸮⸮
c
p⸮dslslp⸮g⸮

⸮ d ⸮⸮

c
g⸮| l⸮  ⸮b⸮⸮oo⸮l⸮⸮l` ⸮  oo
l`   gsǓ⸮n  c
⸮ l r⸮⸮g
 c ⸮ l⸮

l  ⸮⸮o⸮
12:34:42.177 -> FW 6.0.2
12:34:42.177 -> 3.0.0-dev(c0f7b44)
12:34:42.177 -> Worker run!
12:34:42.211 -> mounting FS... mounted!
12:34:42.211 -> reading config file
12:34:42.211 -> offsets not available
12:34:42.211 -> parsed config:
12:34:42.211 -> {"Name":"Spindel_Stern","Token":"foobar","Sleep":900,"Server":"example.com","API":6,"Port":61085,"URL":"","DB":"ispindel","Username":"","Password":"","Job":"ispindel","Instance":"000","Vfact":191.8,"TS":0,"OWpin":12,"SSID":"Foobar","PSK":"foobar","POLY":"-0.00031*tilt^2+0.557*tilt-14.054","aX":0,"aY":0,"aZ":0}
;ld⸮⸮|⸮l⸮|

⸮
d⸮ b|⸮⸮ ⸮ ⸮r⸮b⸮
c⸮⸮no⸮$oo⸮⸮⸮
c
x⸮⸮drlrlp⸮o⸮

⸮
l
⸮⸮   c o⸮| l⸮

⸮c⸮⸮no⸮d⸮⸮l` ⸮  oo l`   gr⸮⸮⸮g  c ⸮ l {⸮⸮g

c
⸮ l⸮

l` ⸮⸮n⸮
12:34:42.630 -> FW 6.0.2
12:34:42.630 -> 3.0.0-dev(c0f7b44)
12:34:42.630 -> Worker run!
12:34:42.663 -> mounting FS... mounted!
12:34:42.663 -> reading config file
12:34:42.663 -> offsets not available
12:34:42.663 -> parsed config:
12:34:42.663 -> {"Name":"Spindel_Stern","Token":"foobar","Sleep":900,"Server":"example.com","API":6,"Port":61085,"URL":"","DB":"ispindel","Username":"","Password":"","Job":"ispindel","Instance":"000","Vfact":191.8,"TS":0,"OWpin":12,"SSID":"Foobar","PSK":"foobar","POLY":"-0.00031*tilt^2+0.557*tilt-14.054","aX":0,"aY":0,"aZ":0}
rld⸮⸮|⸮l⸮|

⸮
d⸮ c|⸮⸮ ⸮ ⸮r⸮c⸮
#⸮⸮no⸮$oo⸮⸮⸮
c
x⸮drlslp⸮o⸮

⸮
l
⸮⸮   c
o⸮| l⸮

⸮#⸮⸮no⸮$⸮⸮l` ⸮  oo l`   gr⸮⸮⸮'  c ⸮ l {ےg

c
⸮ l⸮

l` ⸮⸮o⸮
12:34:43.021 -> FW 6.0.2
12:34:43.021 -> 3.0.0-dev(c0f7b44)
12:34:43.021 -> Worker run!
12:34:43.021 -> mounting FS... mounted!
12:34:43.021 -> reading config file
offsets not available
12:34:43.058 -> parsed config:
12:34:43.058 -> {"Name":"Spindel_Stern","Token":"foobar","Sleep":900,"Server":"example.com","API":6,"Port":61085,"URL":"","DB":"ispindel","Username":"","Password":"","Job":"ispindel","Instance":"000","Vfact":191.8,"TS":0,"OWpin":12,"SSID":"Foobar","PSK":"foobar","POLY":"-0.00031*tilt^2+0.557*tilt-14.054","aX":0,"aY":0,"aZ":⸮{dl⸮⸮|⸮l⸮|

⸮
l⸮
c|⸮⸮ ⸮ ⸮{⸮c⸮
c⸮⸮gg⸮dno⸮⸮⸮
c
p⸮l{d{dp⸮n⸮    ⸮
l
⸮⸮

b n⸮| d⸮

⸮c⸮⸮gg⸮d⸮⸮d` ⸮  gn d`   o{⸮⸮⸮g

c
⸮ l {⸮⸮o

#
⸮ d⸮
      l` ⸮⸮g⸮
12:34:43.334 -> FW 6.0.2
12:34:43.334 -> 3.0.0-dev(c0f7b44)
12:34:43.334 -> Worker run!
12:34:43.367 -> mounting FS... mounted!
12:34:43.367 -> reading config file
12:34:43.367 -> offsets not available
12:34:43.367 -> parsed config:
12:34:43.367 -> {"Name":"Spindel_Stern","Token":"foobar","Sleep":900,"Server":"example.com","API":6,"Port":61085,"URL":"","DB":"ispindel","Username":"","Password":"","Job":"ispindel","Instance":"000","Vfact":191.8,"TS":0,"OWpin":12,"SSID":"Foobar","PSK":"foobar","POLY":"-0.00031*tilt^2+0.55⸮{dd⸮⸮|⸮l⸮|

⸮
l⸮ b|⸮⸮ ⸮ ⸮{⸮b⸮
c⸮⸮nn⸮doo⸮⸮⸮
c
x⸮l{lrlp⸮o⸮

⸮
l
⸮⸮   c o⸮| l⸮

⸮c⸮⸮nn⸮d⸮⸮l` ⸮  no d`   gr⸮⸮⸮g
 c ⸮ l {⸮⸮o

b
⸮ $⸮

l` ⸮⸮n⸮
12:34:43.755 -> FW 6.0.2
12:34:43.755 -> 3.0.0-dev(c0f7b44)
12:34:43.755 -> Worker run!
12:34:43.791 -> mounting FS... mounted!
12:34:43.791 -> reading config file
12:34:43.791 -> offsets not available
12:34:43.791 -> parsed config:
12:34:43.791 -> {"Name":"Spindel_Stern","Token":"foobar","Sleep":900,"Server":"example.com","API":6,"Port":61085,"URL":"","DB":"ispindel","Username":"","Password":"","Job":"ispindel","Instance":"000","Vfact":191.8,"TS":0,"OWpin":12,"SSID":"Foobar","PSK":"foobar","POLY":"-0.00031*tilt^2+0.557*tilt-14.054","aX":0,"aY":0,"aZ":0}
{dd⸮⸮|⸮l⸮|

⸮
l⸮ b|⸮⸮ ⸮ ⸮{⸮b⸮
c⸮⸮nn⸮doo⸮⸮⸮
c
x⸮⸮l{drlp⸮o⸮

⸮
l
⸮⸮
  b o⸮| l⸮

⸮c⸮⸮nn⸮d⸮⸮l` ⸮  nn d`   o;⸮⸮⸮g

c ⸮ l {⸮⸮o

b
⸮ d⸮

l` ⸮⸮n⸮
12:34:44.182 -> FW 6.0.2
12:34:44.182 -> 3.0.0-dev(c0f7b44)
12:34:44.182 -> Worker run!
12:34:44.216 -> mounting FS... mounted!
12:34:44.216 -> reading config file
12:34:44.216 -> offsets not available
12:34:44.216 -> parsed config:
12:34:44.216 -> {"Name":"Spindel_Stern","Token":"foobar","Sleep":900,"Server":"example.com","API":6,"Port":61085,"URL":"","DB":"ispindel","Username":"","Password":"","Job":"ispindel","Instance":"000","Vfact":191.8,"TS":0,"OWpin":12,"SSID":"Foobar","PSK":"foobar","POLY":"-0.00031*tilt^2+0.557*tilt-14.054","aX":0,"aY":0,"aZ":0}
sdl⸮⸮|⸮l⸮|    ⸮
l⸮
c|⸮⸮ ⸮ ⸮{⸮c⸮
c⸮⸮gg⸮l'n⸮⸮⸮ c
p⸮l{d{dx⸮g⸮    ⸮ l
⸮⸮

c
'⸮| d⸮  ⸮c⸮⸮gg⸮l⸮⸮d` ⸮  gg
d`   o{⸮⸮⸮o

b
⸮ d s⸮⸮o  c
⸮ d⸮

    d` ⸮⸮g⸮
12:34:44.596 -> FW 6.0.2
12:34:44.596 -> 3.0.0-dev(c0f7b44)
12:34:44.596 -> Worker run!
12:34:44.629 -> mounting FS...{ld⸮⸮|⸮l⸮|

⸮
l⸮ b|⸮⸮ ⸮ ⸮r⸮b⸮
c⸮⸮no⸮doo⸮⸮⸮
c
x⸮lrlrlp⸮o⸮

⸮
l
⸮⸮   c o⸮| l⸮

⸮c⸮⸮no⸮d⸮⸮l` ⸮  oo l`   gr⸮⸮⸮g  c ⸮ l {⸮⸮g

c
⸮ l⸮
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
ploufe, 2019-02-24:
Thanks because I don't know how to get the log :)

universam1, 2019-02-27:
@ckrack Would you therefor state that the functionality is fine, only displaying might be wrong?

@ploufe See the FAQ doc how to get the terminal debug log

ckrack, 2019-02-27:
Hi @universam1.
Yes, I could not reproduce an actually incorrect saving - although I thought there was at first, when I "lost" a floating spindle to Ubidots.

It's a problem with the mirroring between the form inputs on the config page.
There is one `<select #API>` and one <input hidden #selAPI>`.
I saved the HTML of the config locally and it works fine, TCP is selected after loading.
However, when loaded via the Captive on the actual device, it's not selected.

I debugged it in the console in several breakpoints.

````
document.getElementById('selAPI').value

"6"
document.getElementById('API').value

""
document.getElementById('API').value

""
document.getElementById('API').value

""
document.getElementById('API').value = document.getElementById('selAPI').value;

"6"
document.getElementById('API').value

""
document.getElementById('API').value

"0"
document.getElementById('API').value = document.getElementById('selAPI').value;

"6"
```

Seems like setting the value of #API (which is the select) does not work as expected.

ckrack, 2019-02-27:
Actually this should work in all browsers - the problem is, that the `<option>`s are rendered twice.
This might confuse browsers.. My fix uses `querySelector`, which will stop after the first option it found.

```html
<select id="API" onchange="sAPI(this.options[this.selectedIndex].value);"><option value="0">Ubidots</option><option value="2">CraftBeerPi</option><option value="3">HTTP</option><option value="4">TControl</option><option value="5">FHEM</option><option value="6">TCP</option><option value="7">iSpindel.de</option><option value="8">InfluxDB</option><option value="9">Prometheus</option><option value="10">MQTT</option><option value="0">Ubidots</option><option value="2">CraftBeerPi</option><option value="3">HTTP</option><option value="4">TControl</option><option value="5">FHEM</option><option value="6">TCP</option><option value="7">iSpindel.de</option><option value="8">InfluxDB</option><option value="9">Prometheus</option><option value="10">MQTT</option></select>
```

ploufe, 2019-02-28:
I'm totaly unskill to understand the discution, but I just share that I downgrade my ispindle on 6.0.1 version and it solve the issue

ckrack, 2019-02-28:
I think this addition leads to the options appearing twice:
https://github.com/universam1/iSpindel/commit/07141b9d9e2a3b6fb4122155f7111a4f485f3431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

universam1, 2019-02-28:
Thanks @ckrack for debugging the conditions!

universam1, 2019-03-07:
@ckrack there was another issue with the order of the calls. Fixed with 6.0.5. Please make sure to `reset` under `Maintenance` menu

universam1, 2019-03-14:
Assuming this is fixed

Closed 2019-03-14.

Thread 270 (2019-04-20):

InfluxDB not working in 6.0.5

pompel82, 2019-04-20:
InfluxDB reporting is not working in 6.0.5. I reverted to 6.0.2 and it solved the issue. Have seen other issues reported on this e.g. #215, #218 but these are closed and fix included (I assume) in 6.0.5 so seems this is another issue or fix is not working. Don't have any info on the error, could not find any trace of connection in influxdb log and no info found in network packet capture so seems iSpindel is not even connecting to the influxdb server.

SunSun1979, 2019-04-21:
+1, have this problem, revert to 6.0.2

finchlt, 2019-05-04:
I did a little debugging on this issue this morning. Seems that the fix for #257 and #258 changed the URL generation logic to build a complete URL string instead of pass in the host, port, uri separately.
Prior (works for me):
``
http.begin(server, port, uri);
``
Currently:
``
http.begin(server + ':' + port + uri);
``
So it seems that for the current code it doesn't correctly parse the protocol. (i.e. http://). The code looks for the first ':' character and since this won't be until after the server string this won't work. If you include http:// in the server host configuerd in the config webpage it works or if you add http:// to the URL string programmatically. However the Http client library usage of the current method signature below is deprecated so the fix is probably revert the #258 merge the figure more what caused PR #257.
``
http.begin(String url);
``
I can put together a pull request later today or tomorrow.

universam1, 2019-05-05:
Thanks that’s welcome!

Antti1111, 2019-06-29:
Is the same problem 6.0.6 ?

FW 6.0.6
3.0.0-dev(c0f7b44)
Worker run!
mounting FS... mounted!
reading config file
applying offsets
parsed config:
{"Name":"iSpindel","Token":"","Sleep":900,"Server":"192.168.0.192","API":8,"Port":8086,"URL":"","DB":"spindel","Username":"spindel","Password":"spindel","Job":"","Instance":"","Vfact":191.8,"TS":0,"OWpin":12,"SSID":"AABBCC","PSK":"12062013","POLY":"-0.00031*tilt^2+0.557*tilt-14.054","aX":-691,"aY":-821,"aZ":1903}
Boot-Mode: Deep-Sleep Wake

woken from deepsleep, normal mode
Samples:42 min:63.53 max:63.54 time:755
x: 12696 y: 12746 z: 922
Tilt: 63.54
Tacc: 26.65
Volt: 4.17
Temp: 27.00
Gravity: 20.08
After waiting 200ms, result 3
IP: 192.168.0.204

calling InfluxDB
Sending to db: spindel w/ credentials: spindel:spindel
INFLUXDB: posting to db: /write?db=spindel
POST data: measurements,source=iSpindel tilt=63.5372,temperature=27,temp_units="C",battery=4.171011,gravity=20.08476,interval=900,RSSI=-62
code: -1
[HTTP] POST... failed, error: connection refused

Final-sleep: 900s; RT: 1413

mharbach, 2019-09-03:
I also still have this issue in 6.1.1. Here's the iSpindel log

`calling InfluxDB
Sending to db: ispindel w/ credentials: ispindel:m76LBQuty8vR
INFLUXDB: posting to db: /write?db=ispindel
POST data: measurements,source=iSpindelMH
code: 400
calling InfluxDB
Sending to db: ispindel w/ credentials: ispindel:m76LBQuty8vR
INFLUXDB: posting to db: /write?db=ispindel
POST data: measurements,source=iSpindelMH
code: 400
`

and here's the influxDB access.log entry:

`109.41.192.51 - ispindel [03/Sep/2019:11:01:29 +0200] "POST /write?db=ispindel HTTP/1.1" 400 77 "-" "ESP8266HTTPClient" 6adecc26-ce29-11e9-85b2-b827ebdf3768 344
`

I guess the probelm might be that the POST data does not include any actual measurements. Accordingly, the access.log reports only 344 bytes in the request. When I create a manual request using curl, the size is somewhere in the 24000 bytes range. here's the curl command I use (except for password and host ;)):

`curl -X POST --data-binary 'measurements,source=iSpindelMH tilt=65.22439,temperature=23.9375,temp_units="C",battery=4.144943,gravity=19.42556,interval=30,RSSI=-42' -u ispindel:mypass http://myhost:18086/write?db=ispindel
`

TheNetStriker, 2019-09-25:
+1 I can also confirm this problem. Reverted to 6.0.2.

TheNetStriker, 2019-09-26:
I guess I found out what was causing my problem. My post data only contained measurements,source=iSpindel001, so there was no actual data in the http request. I found a simple fix for the problem. I changed the line in SenderClass::sendInfluxDB
from:
for (const auto &kv : _doc.to<JsonObject>())
to:
for (const auto &kv : _doc.as<JsonObject>())

Now the post contains data again and it also get's saved by the InfluxDB.

Closed 2019-10-27.

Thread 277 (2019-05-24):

Using multimeter to test ispindel-battery life

Gkire, 2019-05-24:
I bought a new 3000mah 18650 battery  with soldering strips from a respectable vendor in the Netherlands, and loaded it fully until the charger indicated blue.
Source: https://www.123accu.nl/UltraFire-18650-batterij-met-soldeerlippen-2-stuks-3000-mAh-i11094.html

I configered my ispindel to 6.0.6 and placed it in the water since 22 may with intervals of 900seconds

This morning my Ispindel stopped sending reports regularly:
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

I have bought a multi meter to establish what might be the problem.
However, apart from soldering and following instructions I have no electronic knowhow.

Could someone point me in the right direction as to what things to measure with the multimeter to find the root cause?

universam1, 2019-05-24:
did you follow the build instructions to remove the LED?

stefschin, 2019-05-24:
Did you set battery calibration factor? Ispindel turn off when it detects under 3V, but you should have to calibrate the sensor with this factor. Look at [FAQ](https://github.com/universam1/iSpindel/blob/master/docs/FAQ-en.md)

ErikdBr, 2019-05-26:
Any news on this?
Cause I didn't think that this was very important because I use a 3500mah battery. But after seeing this post I measured the voltage of the battery with a multimeter and I found that there was a difference of 0.4V between the displayed voltage(4.11) and the measured voltage(4.51). So I used the formula to calculate a new battery conversion factor and now the displayed value = measured value.

The formula to do this is you'll find in the FAQ that stefschin pointed out.

Other then that when I look at your figures I see a voltage drop of 0.6V in 3 hours and 20 minutes. I started a test 24 hours ago and I have a voltage drop of 0.03V with no leds removed what so ever. I don't know what that might be but I would try the conversion factor first.

Gkire, 2019-05-28:
Update:
To previous questions: Yes all leds are removed with the exception of the wemos itself.
Additionally I did 2 things in the last 4 days:

1. I corrected the battery conversion factor on my "3- Zwart Geel" ispindel from 191.8 to 192.2. I recharged it and had an other run.  Its progress has been as follows:
27 may 2019 13:13: 4.14V
27may 2019 23:59: 3.96V
27 may 2019 13:09 3.78V
28 may 2019 20:48: 3.51V

2. I built a second Ispindel with the second battery from the pack I bought I mentioned in my first post.
This one is called "6-Geel-Wit". Its progress has been as follows:
27 may 2019 14:26: 3.96V
27 may 2019 23:58: 3.96V
28 may 2019 14:30: 3.93V
28 may 2019 20:42 3.91V

My second Ispindel seems to use less energy. Both are on 6.0.6 so I am sure it is hardware related.
Any ideas what to measure in order to establish which component might be the culprit?

ErikdBr, 2019-06-02:
Other then that I agree that this is a hardware issue I only can say check all soldering points.
I am happy to say my battery (samsung 3500mah) is performing well, it is in a bucket with a fermenting sugar solution since last sunday with a 2 minutes update interval and here are the results of the battery:
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
So I am pretty sure it can survive a week of fermenting beer at a 15 minutes interval.

JETET, 2019-10-05:
how do I measure the battery on or off?
with what charge do I do the battery correction factor?

Closed 2019-10-09.

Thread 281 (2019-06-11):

Device will not reboot

Quernon, 2019-06-11:
Firstly, thank you for all your ongoing efforts on this great project.

I've been trying to get this to work for a while now but keep running into the same issue. I can configure the device to connect to my WiFi network and send data, and the data is correctly recorded. However, data is only sent once and only after pressing the reset button. After that, the device never wakes up again and never sends data.

I've looked at the serial log using putty. When the reset button is pressed it shows everything correctly. Then, after the time out, it just displays one line of unrecognisable characters and stops there.

I started with a resistor between RST and D0 but have changed that to a BAT43 diode (Cathode at D0) but the issue persists. I have now tried 3 different D1 Mini boards but all have had the same issue.

Looking at the regulator on the boards, it looks like they have the weak 150mA version. Could this be the cause? If so, do you know where it's possible to source boards which carry the correct regulator?

universam1, 2019-06-11:
For testing short cut the RST and D0 and see if it changes. How about the voltage

Quernon, 2019-06-11:
Do you mean that I should connect the RST and D0 pins directly, without the use of a diode or resistor?

And where should I be measuring the voltage between? RST and D0?

Thanks for your help.

Quernon, 2019-06-11:
Okay, so I've measured the voltage across D0 and RST. On first plugging in / turning on the D1 Mini it stays at a flat 0V. If I press the reset button it briefly flicks up to 1-2V but then stays at 0V thereafter.

If I hot wire the RST and D0 pins then the behaviour stays the same.

Quernon, 2019-06-13:
I have ordered an official board from Wemos/Lolin's aliexpress page and will update this when it arrives. If there is anything else I should try in the meantime please let me know.

universam1, 2019-06-13:
Yes short cut the RST and D0 to see if it’s about the resistor. Check that supply voltage is above 4V. If it is then still not working you got a hardware issue

Quernon, 2019-06-13:
I tried shorting RST and D0 yesterday but it made no difference. I'll try a more robust short this evening (I was trying to avoid soldering anything when I last tried).

Pretty sure supply voltage was above 4V but I'll double check and get back to you. This would be measured across 5V and GND, correct?

Quernon, 2019-06-17:
Shorting the RST and D0 pins made no difference. Supply voltage was >4V.

Looks like I have a hardware issue, probably due to the knockoff boards that I bought. I've ordered replacements and will update here when they arrive.

trafim-uakraine, 2019-06-17:
I bought 5 esp8266 https://ru.aliexpress.com/item/Smart-Electronics-D1-mini-Mini-NodeMcu-4M-bytes-Lua-WIFI-Internet-of-Things-development-board-based/32659152063.html ? spm = a2g0s.9042311.0.0.31ad33edDinub0
Two weeks suffered and came to the conclusion that these boards are not compatible with deep sleep.
DOIT.AM is written on the WiFi module.
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

ErikdBr, 2019-06-17:
I use these: € 3,17 | LOLIN D1 mini V3.1.0-WEMOS WIFI Internet van Dingen development board gebaseerd ESP8266 4 mb MicroPython Nodemcu Arduino Compatibel
https://s.click.aliexpress.com/e/pbB4qQQZd

Quernon, 2019-06-17:
@ErikdBr , those are the official ones from Wemos/Lolin so should be a safe bet. I've ordered the same.

pamarovis, 2019-06-19:
Hello, have you got any news? I have the same mistake with sending data only once.
I bought this board : https://www.aliexpress.com/item/32845084675.html?spm=a2g0s.9042311.0.0.12e24c4dH0a1nj

Quernon, 2019-06-19:
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

I'm still waiting for my replacement boards to arrive but will post here when they do.

ErikdBr, 2019-06-19:
When you follow the D1 mini link on here http://www.ispindel.de/docs/Parts_en.html you go to https://wiki.wemos.cc/products:d1:d1_mini
On there click on th buy now button and you'll go to: https://nl.aliexpress.com/store/product/D1-mini-Mini-NodeMcu-4M-bytes-Lua-WIFI-Internet-of-Things-development-board-based-ESP8266/1331105_32529101036.html

pamarovis, 2019-06-26:
Can you see anything weird in my putty log?

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

pamarovis, 2019-06-30:
Ok, so i solved my problem ! The problem was with BAT43 diode soldered wrong way. Check yours ! :)

Quernon, 2019-07-11:
Just confirming that the issue was with the clone board. Using the official one from Lolin has fixed the issue for me.

Closed 2019-07-11.

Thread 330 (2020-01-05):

Charging issue?

AlecPhilpott, 2020-01-05:
OK, I have solved a few newbie problems, but am stumpted with charging the battery.

The only connections to the TP4056 are as follows:

1)Bat+ and bat- to the battery (they are oriented correctly)
2) IN- to the temp sensor (also bridged to the GND on Wemos)
3)  Bat+ to the switch

Nothing to IN+ (which seems strange to me)

If I plug a usb cable into either the TP4056 or Wemos, there are no lights and the battery doesn't pick up in voltage.

Any pointers welcomed.

thanks in advance.

FWIW, I saw conflicting soldering of the switch in two separate photos - one picture bridged two of the 3 contacts and one did not.  I did not bridge any switch connections.

Alec

AlecPhilpott, 2020-01-13:
resolved - turns out this was a dud charging board

Closed 2020-01-13.

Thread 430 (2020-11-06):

Showing to much voltage?

savvas1802, 2020-11-06:
Hello today I have build my ispindel according to the instructions. I used the 1st variant( I made my own circuit board etc.) I used 220k resistors, 470ohm and a 4k7 ohm as instructed. Everything is working fine except for some reason the voltage of the battery is showing 5.34 volt but is 3.56 when measured with a multimeter. I can't adjust with the correction factor as it is more than 20%. What did I do wrong? Thanks.

ErikdBr, 2020-11-06:
I don't know if it has to do with your problem but the resistor 470Ω has been replaced by a 390Ω resistor or even better a BAT43 Schottkey diode, due to recovering from deep sleep issues.

savvas1802, 2020-11-06:
Thanks for the reply I will try that, 390 or 330ohm resistor?

Στις Παρ, 6 Νοε 2020, 10:57 π.μ. ο χρήστης Erik <notifications@github.com>
έγραψε:

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

ErikdBr, 2020-11-06:
330 I just read in the parts list.

savvas1802, 2020-11-06:
Nope I just replaced it, same issue. Ahh never mind it must be something maybe with the battery or coding?
Because when I take a measurement from the memos it is the same as the battery voltage 3.55.

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

thegreatgunbantoad, 2020-11-16:
Have you tried measuring the voltage after the pot down?  There's a 100k/220k in the Wemos and the iSpindel adds 230k to the other 220k.  So you should be seeing Vbat * 100/(100+220+230).  Assuming your battery is around 4Vish (I know they claim to be 3V7 but that's not what I've seen them measure in at when fully charged) you should be getting about 0.72V.

Closed 2021-01-22.

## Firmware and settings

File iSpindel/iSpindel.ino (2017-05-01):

/**************************************************************

"iSpindel"
All rights reserverd by S.Lang <universam@web.de>

**************************************************************/

// includes go here
#include "DallasTemperature.h"
#include "DoubleResetDetector.h" // https://github.com/datacute/DoubleResetDetector
#include "Globals.h"
#include "RunningMedian.h"
// #include "Ubidots.h"
#include "WiFiManagerKT.h"
#include <ArduinoJson.h> //https://github.com/bblanchon/ArduinoJson
#include <DNSServer.h>
#include <ESP8266WebServer.h>
#include <ESP8266WiFi.h> //https://github.com/esp8266/Arduino
#include <FS.h>          //this needs to be first
#include <Ticker.h>
#include "tinyexpr.h"

        // !DEBUG 1

// definitions go here
MPU6050_Base accelgyro;
OneWire oneWire(ONE_WIRE_BUS);
DallasTemperature DS18B20(&oneWire);
DeviceAddress tempDeviceAddress;
Ticker flasher;
RunningMedian samples = RunningMedian(MEDIANROUNDS);

DoubleResetDetector drd(DRD_TIMEOUT, DRD_ADDRESS);

#ifdef USE_DMP
#include "MPU6050.h"

// MPU control/status vars
bool dmpReady = false;  // set true if DMP init was successful
uint8_t mpuIntStatus;   // holds actual interrupt status byte from MPU
uint8_t devStatus;      // return status after each device operation (0 = success, !0 = error)
uint16_t packetSize;    // expected DMP packet size (default is 42 bytes)
uint16_t fifoCount;     // count of all bytes currently in FIFO
uint8_t fifoBuffer[64]; // FIFO storage buffer

// orientation/motion vars
Quaternion q;        // [w, x, y, z]         quaternion container
VectorInt16 aa;      // [x, y, z]            accel sensor measurements
VectorInt16 aaReal;  // [x, y, z]            gravity-free accel sensor measurements
VectorInt16 aaWorld; // [x, y, z]            world-frame accel sensor measurements
VectorFloat gravity; // [x, y, z]            gravity vector
float euler[3];      // [psi, theta, phi]    Euler angle container
float ypr[3];        // [yaw, pitch, roll]   yaw/pitch/roll container and gravity vector
#endif

bool shouldSaveConfig = false;

char my_token[TKIDSIZE];
char my_name[TKIDSIZE] = "iSpindel000";
char my_server[TKIDSIZE];
char my_url[TKIDSIZE];
char my_polynominal[70] = "-0.00031*tilt^2+0.557*tilt-14.054";

String my_ssid;
String my_psk;
uint8_t my_api;
uint32_t my_sleeptime = 15 * 60;
uint16_t my_port = 80;
float my_vfact = ADCDIVISOR;
int16_t my_aX = UNINIT, my_aY = UNINIT, my_aZ = UNINIT;

uint32_t DSreqTime;
float pitch, roll;

int16_t ax, ay, az;
float Volt, Temperatur, Tilt, Gravity;
// , corrGravity;

bool DSrequested = false;

bool isDebugEnabled()
{
#ifdef DEBUG
  return true;
#endif // DEBUG
  return false;
}

// generic serial output
template <typename T>
void SerialOut(const T aValue, bool newLine = true)
{
  if (!isDebugEnabled())
    return;
  Serial.print(aValue);
  if (newLine)
    Serial.print("\n");
}

void SerialOut() { SerialOut(""); }

// callback notifying us of the need to save config
void saveConfigCallback()
{
  // SerialOut(F("Should save config"));
  // WiFi.setAutoReconnect(true);
  shouldSaveConfig = true;
}

bool readConfig()
{
  SerialOut(F("mounting FS..."), false);

  if (SPIFFS.begin())
  {
    SerialOut(F(" mounted!"));
    if (SPIFFS.exists(CFGFILE))
    {
      // file exists, reading and loading
      SerialOut(F("reading config file"));
      File configFile = SPIFFS.open(CFGFILE, "r");
      if (configFile)
      {
        SerialOut(F("opened config file"));
        size_t size = configFile.size();
        // Allocate a buffer to store contents of the file.
        std::unique_ptr<char[]> buf(new char[size]);

        configFile.readBytes(buf.get(), size);
        DynamicJsonBuffer jsonBuffer;
        JsonObject &json = jsonBuffer.parseObject(buf.get());

        if (json.success())
        {
          SerialOut(F("\nparsed json"));

          if (json.containsKey("Name"))
            strcpy(my_name, json["Name"]);
          if (json.containsKey("Token"))
            strcpy(my_token, json["Token"]);
          if (json.containsKey("Server"))
            strcpy(my_server, json["Server"]);
          if (json.containsKey("Sleep"))
            my_sleeptime = json["Sleep"];
          if (json.containsKey("API"))
            my_api = json["API"];
          if (json.containsKey("Port"))
            my_port = json["Port"];
          if (json.containsKey("URL"))
            strcpy(my_url, json["URL"]);
          if (json.containsKey("Vfact"))
            my_vfact = json["Vfact"];

          if (json.containsKey("SSID"))
            my_ssid = json["SSID"].asString();
          if (json.containsKey("PSK"))
            my_psk = json["PSK"].asString();
          if (json.containsKey("POLY"))
            strcpy(my_polynominal, json["POLY"]);

          my_aX = UNINIT;
          my_aY = UNINIT;
          my_aZ = UNINIT;

          if (json.containsKey("aX"))
            my_aX = json["aX"];
          if (json.containsKey("aY"))
            my_aY = json["aY"];
          if (json.containsKey("aZ"))
            my_aZ = json["aZ"];
          applyOffset();

          SerialOut(F("parsed config:"));
          if (isDebugEnabled)
            json.printTo(Serial);
          return true;
        }
        else
        {
          SerialOut(F("ERROR: failed to load json config"));
          return false;
        }
      }
      SerialOut(F("ERROR: unable to open config file"));
    }
  }
  else
  {
    SerialOut(F(" ERROR: failed to mount FS!"));
    return false;
  }
}

bool shouldStartConfig()
{

  // we make sure that configuration is properly set and we are not woken by
  // RESET button
  // ensure this was called

  rst_info *_reset_info = ESP.getResetInfoPtr();
  uint8_t _reset_reason = _reset_info->reason;

  // The ESP reset info is sill buggy. see http://www.esp8266.com/viewtopic.php?f=32&t=8411
  // The reset reason is "5" (woken from deep-sleep) in most cases (also after a power-cycle)
  // I added a single reset detection as workaround to enter the config-mode easier
  SerialOut("Boot-Mode: ", false);
  SerialOut(_reset_reason);
  bool _poweredOnOffOn = _reset_reason == REASON_DEFAULT_RST || _reset_reason == REASON_EXT_SYS_RST;
  if (_poweredOnOffOn)
    SerialOut("power-cycle or reset detected, config mode");

  bool _dblreset = drd.detectDoubleReset();
  if (_dblreset)
    SerialOut("\nDouble Reset detected");
  bool _validConf = readConfig();
  if (!_validConf)
    SerialOut("\nERROR config corrupted");

  bool _wifiCred = (WiFi.SSID() != "");
  uint8_t c = 0;
  if (!_wifiCred)
    WiFi.begin();
  while (!_wifiCred)
  {
    if (c > 10)
      break;
    SerialOut('.', false);
    delay(100);
    c++;
    _wifiCred = (WiFi.SSID() != "");
  }
  if (!_wifiCred)
    SerialOut("\nERROR no Wifi credentials");

  if (_validConf && !_dblreset && _wifiCred && !_poweredOnOffOn)
  {
    SerialOut(F("\nwoken from deepsleep, normal mode"));
    return false;
  }
  // config mode
  else
  {
    SerialOut(F("\ngoing to Config Mode"));
    return true;
  }
}

void validateInput(const char *input, char *output)
{
  String tmp = String(input);
  tmp.trim();
  tmp.replace(' ', '_');
  tmp.toCharArray(output, tmp.length() + 1);
}

bool startConfiguration()
{

  WiFiManager wifiManager;

  wifiManager.setConfigPortalTimeout(PORTALTIMEOUT);
  wifiManager.setSaveConfigCallback(saveConfigCallback);
  wifiManager.setBreakAfterConfig(true);

  WiFiManagerParameter api_list(HTTP_API_LIST);
  WiFiManagerParameter custom_api("selAPI", "selAPI", String(my_api).c_str(),
                                  20, TYPE_HIDDEN, WFM_NO_LABEL);

  WiFiManagerParameter custom_name("name", "iSpindel Name", my_name,
                                   TKIDSIZE);
  WiFiManagerParameter custom_sleep("sleep", "Update Intervall (s)",
                                    String(my_sleeptime).c_str(), 5, TYPE_NUMBER);
  WiFiManagerParameter custom_token("token", "Ubidots Token", my_token,
                                    TKIDSIZE);
  WiFiManagerParameter custom_server("server", "Server Address",
                                     my_server, TKIDSIZE);
  WiFiManagerParameter custom_port("port", "Server Port",
                                   String(my_port).c_str(), TKIDSIZE,
                                   TYPE_NUMBER);
  WiFiManagerParameter custom_url("url", "Server URL", my_url, TKIDSIZE);
  WiFiManagerParameter custom_vfact("vfact", "Battery conversion factor",
                                    String(my_vfact).c_str(), 7, TYPE_NUMBER);

  wifiManager.addParameter(&custom_name);
  wifiManager.addParameter(&custom_sleep);
  wifiManager.addParameter(&custom_vfact);

  WiFiManagerParameter custom_api_hint("<hr><label for=\"API\">Service Type</label>");
  wifiManager.addParameter(&custom_api_hint);

  wifiManager.addParameter(&api_list);
  wifiManager.addParameter(&custom_api);

  wifiManager.addParameter(&custom_token);
  wifiManager.addParameter(&custom_server);
  wifiManager.addParameter(&custom_port);
  wifiManager.addParameter(&custom_url);
  WiFiManagerParameter custom_polynom_lbl("<hr><label for=\"POLYN\">Gravity conversion<br/>ex. \"0.00438*(tilt)*(tilt) + 0.13647*(tilt) - 6.96\"</label>");
  wifiManager.addParameter(&custom_polynom_lbl);
  // f.e. '0.00438*(tilt)*(tilt) + 0.13647*(tilt) - 6.96'
  WiFiManagerParameter custom_polynom("POLYN", "Polynominal", my_polynominal, 70, WFM_NO_LABEL);
  wifiManager.addParameter(&custom_polynom);
  // WiFiManagerParameter custom_polynom_temp("POLYTEMP", "calibration Temperatur C", String(my_polynominal_temp).c_str(), 5, TYPE_NUMBER);
  // wifiManager.addParameter(&custom_polynom_temp);

  SerialOut(F("started Portal"));
  wifiManager.startConfigPortal("iSpindel");

  strcpy(my_polynominal, custom_polynom.getValue());
  // my_polynominal_temp = String(custom_polynom_temp.getValue()).toInt();

  validateInput(custom_name.getValue(), my_name);
  validateInput(custom_token.getValue(), my_token);
  validateInput(custom_server.getValue(), my_server);
  my_sleeptime = String(custom_sleep.getValue()).toInt();

  my_api = String(custom_api.getValue()).toInt();
  my_port = String(custom_port.getValue()).toInt();
  validateInput(custom_url.getValue(), my_url);

  String tmp = String(custom_vfact.getValue());
  tmp.trim();
  tmp.replace(',', '.');
  my_vfact = tmp.toFloat();
  if (my_vfact < ADCDIVISOR * 0.8 || my_vfact > ADCDIVISOR * 1.2)
    my_vfact = ADCDIVISOR;

  // save the custom parameters to FS
  if (shouldSaveConfig)
  {
    // Wifi config
    WiFi.setAutoConnect(true);
    WiFi.setAutoReconnect(true);

    return saveConfig();
  }
  return false;
}

bool saveConfig()
{
  SerialOut(F("saving config..."), false);

  // if SPIFFS is not usable
  if (!SPIFFS.begin() || !SPIFFS.exists(CFGFILE) ||
      !SPIFFS.open(CFGFILE, "w"))
  {
    SerialOut(F("\nneed to format SPIFFS: "), false);
    SPIFFS.end();
    SPIFFS.begin();
    SerialOut(SPIFFS.format());
  }

  DynamicJsonBuffer jsonBuffer;
  JsonObject &json = jsonBuffer.createObject();

  json["Name"] = my_name;
  json["Token"] = my_token;
  json["Sleep"] = my_sleeptime;
  // first reboot is for test
  my_sleeptime = 1;
  json["Server"] = my_server;
  json["API"] = my_api;
  json["Port"] = my_port;
  json["URL"] = my_url;
  json["Vfact"] = my_vfact;

  // Store current Wifi credentials
  json["SSID"] = WiFi.SSID();
  json["PSK"] = WiFi.psk();

  json["POLY"] = my_polynominal;
  json["aX"] = my_aX;
  json["aY"] = my_aY;
  json["aZ"] = my_aZ;

  File configFile = SPIFFS.open(CFGFILE, "w+");
  if (!configFile)
  {
    SerialOut(F("failed to open config file for writing"), true);
    SPIFFS.end();
    return false;
  }
  else
  {
    if (isDebugEnabled)
      json.printTo(Serial);
    json.printTo(configFile);
    configFile.close();
    SPIFFS.end();
    SerialOut(F("saved successfully"), true);
    return true;
  }
}

bool uploadData(uint8_t service)
{
  char url[TKIDSIZE];
  uint16_t port;

#ifdef API_UBIDOTS
  if (service == DTUbiDots)
  {
    Ubidots ubiclient(my_token, my_name);
    ubiclient.add("tilt", Tilt);
    // ubiclient.add("corrGravity", corrGravity);
    ubiclient.add("temperature", Temperatur);
    ubiclient.add("battery", Volt);
    ubiclient.add("gravity", Gravity);
    // This creates a new Device, only with TCP transmission
    ubiclient.setDataSourceName(my_name);
    return ubiclient.sendAll(false);
  }
#endif

#ifdef API_GENERIC
  if ((service == DTHTTP) || (service == DTCraftbeepPi) || (service == DTTCP))
  {

    if (service == DTHTTP)
    {
      SerialOut(F("\ncalling DTHTTP "));
      strcpy(url, my_url);
      port = my_port;
    }
    else if (service == DTCraftbeepPi)
    {
      SerialOut(F("\ncalling DTCraftbeepPi "));
      strcpy(url, CBP_ENDPOINT);
      port = 5000;
    }
    else if (service == DTTCP)
    {
      SerialOut(F("\ncalling DTTCP "));
      port = my_port;
      strcpy(url, "");
    }

    genericHTTP genclient(my_name, my_server, port, url);
    genclient.add("angle", Tilt);
    genclient.add("temperature", Temperatur);
    genclient.add("battery", Volt);
    genclient.add("gravity", Gravity);

    if (service == DTTCP)
    {
      return genclient.sendTCP();
    }
    else
    {
      return genclient.sendHTTP();
    }
  }
#endif // DATABASESYSTEM

#ifdef API_FHEM
  if (service == DTFHEM)
  {
    FhemHttp fhemclient(my_name, my_server, my_port);
    fhemclient.add("angle", Tilt);
    fhemclient.add("temperature", Temperatur);
    fhemclient.add("battery", Volt);
    fhemclient.add("gravity", Gravity);
    return fhemclient.sendHTTP();
  }
#endif // DATABASESYSTEM ==
#ifdef API_TCONTROL
  if (service == DTTcontrol)
  {
    TControl tcclient(my_name, my_server, my_port);
    tcclient.add("T", Temperatur);
    tcclient.add("D", Tilt);
    tcclient.add("U", Volt);
    tcclient.add("G", Gravity);
    return tcclient.send();
  }
#endif // DATABASESYSTEM ==
}

void sleepManager()
{
  uint32_t left2sleep, validflag;
  ESP.rtcUserMemoryRead(RTCSLEEPADDR, &left2sleep, sizeof(left2sleep));
  ESP.rtcUserMemoryRead(RTCSLEEPADDR + 1, &validflag, sizeof(validflag));

  // check if we have to incarnate again
  if (left2sleep != 0 && !drd.detectDoubleReset() && validflag == RTCVALIDFLAG)
  {
    goodNight(left2sleep);
  }
  else
  {
    SerialOut(F("Worker run!"));
  }
}

void goodNight(uint32_t seconds)
{

  uint32_t _seconds = seconds;
  uint32_t left2sleep = 0;
  uint32_t validflag = RTCVALIDFLAG;

  drd.stop();

  // workaround for DS not floating
  pinMode(ONE_WIRE_BUS, OUTPUT);
  digitalWrite(ONE_WIRE_BUS, LOW);

  // we need another incarnation before work run
  if (_seconds > MAXSLEEPTIME)
  {
    left2sleep = _seconds - MAXSLEEPTIME;
    ESP.rtcUserMemoryWrite(RTCSLEEPADDR, &left2sleep, sizeof(left2sleep));
    ESP.rtcUserMemoryWrite(RTCSLEEPADDR + 1, &validflag, sizeof(validflag));
    SerialOut(String(F("\nStep-sleep: ")) + MAXSLEEPTIME + String("s; left: ") + left2sleep + String("s; RT:") + millis());
    ESP.deepSleep(MAXSLEEPTIME * 1000UL * 1000UL, WAKE_RF_DISABLED);
    // workaround proper power state init
    delay(500);
  }
  // regular sleep with RF enabled after wakeup
  else
  {
    // clearing RTC to mark next wake
    left2sleep = 0;
    ESP.rtcUserMemoryWrite(RTCSLEEPADDR, &left2sleep, sizeof(left2sleep));
    ESP.rtcUserMemoryWrite(RTCSLEEPADDR + 1, &validflag, sizeof(validflag));
    SerialOut(String(F("\nFinal-sleep: ")) + _seconds + String("s; RT:") + millis());
    // WAKE_RF_DEFAULT --> auto reconnect after wakeup
    ESP.deepSleep(_seconds * 1000UL * 1000UL, WAKE_RF_DEFAULT);
    // workaround proper power state init
    delay(500);
  }
}

void initDS18B20()
{

  // workaround for DS not enough power to boot
  pinMode(ONE_WIRE_BUS, OUTPUT);
  digitalWrite(ONE_WIRE_BUS, LOW);
  delay(100);
  // digitalWrite(ONE_WIRE_BUS, HIGH);
  // delay(500);
  // oneWire.reset();
  // Start up the DS18B20
  DS18B20.begin();
  DS18B20.setWaitForConversion(false);
  DS18B20.getAddress(tempDeviceAddress, 0);
  DS18B20.setResolution(tempDeviceAddress, RESOLUTION);
  requestTemp();
}

void initAccel()
{
  // join I2C bus (I2Cdev library doesn't do this automatically)
  Wire.begin(D3, D4);
  Wire.setClock(100000);
  Wire.setClockStretchLimit(2 * 230);

  // init the Accel
  accelgyro.initialize();
  accelgyro.setDLPFMode(MPU6050_DLPF_BW_5);
  accelgyro.setTempSensorEnabled(true);
#ifdef USE_DMP
  accelgyro.setDMPEnabled(true);
  packetSize = accelgyro.dmpGetFIFOPacketSize();
#endif
}

void applyOffset() {
  if (my_aX != UNINIT && my_aY != UNINIT && my_aZ != UNINIT) {
    SerialOut(F("applying offsets"));
    accelgyro.setXAccelOffset(my_aX);
    accelgyro.setYAccelOffset(my_aY);
    accelgyro.setZAccelOffset(my_aZ);
  }
  else
    SerialOut(F("offsets not available"));
}

float calculateTilt()
{
  float _ax = ax;
  float _ay = ay;
  float _az = az;
  float pitch = (atan2(_ay, sqrt(_ax * _ax + _az * _az))) * 180.0 / M_PI;
  float roll = (atan2(_ax, sqrt(_ay * _ay + _az * _az))) * 180.0 / M_PI;
  return sqrt(pitch * pitch + roll * roll);
}

float getTilt()
{
  // make sure enough time for Acc to start
  uint32_t start = ACCINTERVAL;

  for (uint8_t i = 0; i < MEDIANROUNDS; i++)
  {
    while (millis() - start < ACCINTERVAL)
      yield();
    start = millis();
    getAccSample();
    float _tilt = calculateTilt();
    SerialOut("Spl ", false);
    SerialOut(i, false);
    SerialOut(F(": "), false);
    SerialOut(_tilt);
    samples.add(_tilt);
  }
  return samples.getAverage(MEDIANAVRG);
}

void getAccSample()
{
  uint8_t res = Wire.status();
  uint8_t con = accelgyro.testConnection();
  if (res == I2C_OK && con == true)
    accelgyro.getAcceleration(&ax, &az, &ay);
  else
  {
    SerialOut(String("I2C ERROR: ") + res + String(" con:") + con);
  }
}

float getTemperature(bool block = false)
{
  // we need to wait for DS18b20 to finish conversion
  float t = Temperatur;

  // if we need the result we have to block
  while (block && (millis() - DSreqTime <= OWinterval))
    yield();

  if (millis() - DSreqTime >= OWinterval)
  {
    t = DS18B20.getTempCByIndex(0);
    DSrequested = false;

    if (t == DEVICE_DISCONNECTED_C || // DISCONNECTED
        t == 85.0)                    // we read 85 uninitialized
    {
      SerialOut(F("ERROR: OW DISCONNECTED"));
      pinMode(ONE_WIRE_BUS, OUTPUT);
      digitalWrite(ONE_WIRE_BUS, LOW);
      delay(100);
      // digitalWrite(ONE_WIRE_BUS, HIGH);
      // delay(500);
      oneWire.reset();

      if (block)
      {
        SerialOut(F("OW Retry"));
        initDS18B20();
        delay(OWinterval + 100);
        t = getTemperature(false);
      }
    }
  }
  return t;
}

void requestTemp()
{
  if (DSrequested == false)
  {
    DS18B20.requestTemperatures();
    DSreqTime = millis();
    DSrequested = true;
    // SerialOut("DEBUG DSreq:");
  }
}

void flash()
{
  // triggers the LED
  Volt = getBattery();
  getAccSample();
  Tilt = calculateTilt();
  Temperatur = getTemperature(false);
  Gravity = calculateGravity();
  requestTemp();
}

float getBattery()
{
  analogRead(A0); // drop first read
  return analogRead(A0) / my_vfact;
}

bool isSafeMode(float _volt)
{
  if (_volt < LOWBATT)
  {
    SerialOut("\nWARNING: low Battery");
    return true;
  }
  else
    return false;
}

void setup()
{

  Serial.begin(115200);

  SerialOut("\nFW " FIRMWAREVERSION);
  SerialOut(ESP.getSdkVersion());

  sleepManager();

  initAccel();
  initDS18B20();

  // decide whether we want configuration mode or normal mode
  if (shouldStartConfig())
  {
    uint32_t tmp;
    ESP.rtcUserMemoryRead(WIFIENADDR, &tmp, sizeof(tmp));

    // DIRTY hack to keep track of WAKE_RF_DEFAULT --> find a way to read WAKE_RF_*
    if (tmp != RTCVALIDFLAG)
    {
      drd.setRecentlyResetFlag();
      tmp = RTCVALIDFLAG;
      ESP.rtcUserMemoryWrite(WIFIENADDR, &tmp, sizeof(tmp));
      ESP.deepSleep(1, WAKE_RFCAL);
    }
    else
    {
      tmp = 0;
      ESP.rtcUserMemoryWrite(WIFIENADDR, &tmp, sizeof(tmp));
    }

    flasher.attach(1, flash);

    // rescue if wifi credentials lost because of power loss
    if (!startConfiguration())
    {
      // test if ssid exists
      if (WiFi.SSID() == "" &&
          my_ssid != "" && my_psk != "")
      {
        connectBackupCredentials();
      }
    }
    uint32_t left2sleep = 0;
    ESP.rtcUserMemoryWrite(RTCSLEEPADDR, &left2sleep, sizeof(left2sleep));

    flasher.detach();
  }
  // to make sure we wake up with STA but AP
  WiFi.mode(WIFI_STA);
  Volt = getBattery();
  // we try to survive
  if (isSafeMode(Volt))
    WiFi.setOutputPower(0);
  else
    WiFi.setOutputPower(20.5);
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
void loop()
{
  SerialOut(F("should never be here!"));
}

bool connectBackupCredentials()
{
  WiFi.disconnect();
  WiFi.begin(my_ssid.c_str(), my_psk.c_str());
  SerialOut(F("Rescue Wifi credentials"));
  delay(100);
}

float calculateGravity()
{
  double _tilt = Tilt;
  double _temp = Temperatur;
  float _gravity = 0;
  int err;
  te_variable vars[] = {{"tilt", &_tilt}, {"temp", &_temp}};
  te_expr *expr = te_compile(my_polynominal, vars, 2, &err);

  if (expr)
  {
    _gravity = te_eval(expr);
    te_free(expr);
  }
  else
  {
    Serial.println(String("Parse error at ") + err);
  }
  return _gravity;
}

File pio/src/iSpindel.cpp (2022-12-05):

/**************************************************************

"iSpindel"
All rights reserverd by S.Lang <universam@web.de>

**************************************************************/

// includes go here
#include "Globals.h"
#include "MPUOffset.h"
#include <PubSubClient.h>
// #endif
#include "OneWire.h"
#include "Wire.h"
// #include <Ticker.h>
#include "DallasTemperature.h"
#include "DoubleResetDetector.h" // https://github.com/datacute/DoubleResetDetector
#include "RunningMedian.h"
#include "Sender.h"
#include "WiFiManagerKT.h"
#include "secrets.h" //AWS - Currently a file for Keys, Certs, etc - Need to make this a captured variable for iSpindle
#include "tinyexpr.h"
#include <ArduinoJson.h> //https://github.com/bblanchon/ArduinoJson
#include <DNSServer.h>
#include <ESP8266WebServer.h>
#include <ESP8266WiFi.h> //https://github.com/esp8266/Arduino
#include <FS.h>          //this needs to be first
#include <LittleFS.h>
// !DEBUG 1

// definitions go here
MPU6050 accelgyro;
OneWire *oneWire;
DallasTemperature DS18B20;
DeviceAddress tempDeviceAddress;
Ticker flasher;
RunningMedian samples = RunningMedian(MEDIANROUNDSMAX);
DoubleResetDetector drd(DRD_TIMEOUT, DRD_ADDRESS);

int detectTempSensor(const uint8_t pins[]);
bool testAccel();

bool shouldSaveConfig = false;

iData myData;

#if API_MQTT_HASSIO
//myData.hassio = false;
bool hassio_changed = false;
#endif
bool usehttps_changed = false;

uint32_t DSreqTime = 0;

int16_t ax, ay, az;
float Volt, Temperatur, Tilt, Gravity;

float scaleTemperatureFromC(float t, uint8_t tempscale)
{
  if (tempscale == TEMP_CELSIUS)
    return t;
  else if (tempscale == TEMP_FAHRENHEIT)
    return (1.8f * t + 32);
  else if (tempscale == TEMP_KELVIN)
    return t + 273.15f;
  else
    return t; // Invalid value for myData.tempscale => default to celsius
}

String tempScaleLabel(uint8_t tempscale)
{
  if (tempscale == TEMP_CELSIUS)
    return "C";
  else if (tempscale == TEMP_FAHRENHEIT)
    return "F";
  else if (tempscale == TEMP_KELVIN)
    return "K";
  else
    return "C"; // Invalid value for myData.tempscale => default to celsius
}

// callback notifying us of the need to save config
void saveConfigCallback()
{
  shouldSaveConfig = true;
}

void applyOffset()
{
  if (myData.Offset[0] != UNINIT && myData.Offset[1] != UNINIT && myData.Offset[2] != UNINIT)
  {
    CONSOLELN(String("applying offsets: ") + myData.Offset[0] + ":" + myData.Offset[1] + ":" + myData.Offset[2]);

    accelgyro.setXAccelOffset(myData.Offset[0]);
    accelgyro.setYAccelOffset(myData.Offset[1]);
    accelgyro.setZAccelOffset(myData.Offset[2]);
    accelgyro.setXGyroOffset(myData.Offset[3]);
    accelgyro.setYGyroOffset(myData.Offset[4]);
    accelgyro.setZGyroOffset(myData.Offset[5]);
    delay(1);

    CONSOLELN(String("confirming offsets: ") + accelgyro.getXAccelOffset() + ":" + accelgyro.getYAccelOffset() + ":" +
              accelgyro.getZAccelOffset());
  }
  else
    CONSOLELN(F("offsets not available"));
}

bool readConfig()
{
  CONSOLE(F("mounting FS..."));

  if (!LittleFS.begin())
  {
    CONSOLELN(F(" ERROR: failed to mount FS!"));
    return false;
  }
  else
  {
    CONSOLELN(F(" mounted!"));
    if (!LittleFS.exists(CFGFILE))
    {
      CONSOLELN(F("ERROR: failed to load json config"));
      return false;
    }
    else
    {
      // file exists, reading and loading
      CONSOLELN(F("reading config file"));
      File configFile = LittleFS.open(CFGFILE, "r");
      if (!configFile)
      {
        CONSOLELN(F("ERROR: unable to open config file"));
      }
      else
      {
        size_t size = configFile.size();
        DynamicJsonDocument doc(size * 3);
        DeserializationError error = deserializeJson(doc, configFile);
        if (error)
        {
          CONSOLE(F("deserializeJson() failed: "));
          CONSOLELN(error.c_str());
        }
        else
        {
          if (doc.containsKey("Name"))
            strcpy(myData.name, doc["Name"]);
          if (doc.containsKey("Token"))
            strcpy(myData.token, doc["Token"]);
          if (doc.containsKey("Server"))
            strcpy(myData.server, doc["Server"]);
          if (doc.containsKey("Sleep"))
            myData.sleeptime = doc["Sleep"];
          if (doc.containsKey("API"))
            myData.api = doc["API"];
          if (doc.containsKey("Port"))
            myData.port = doc["Port"];
          if (doc.containsKey("Channel"))
            myData.channel = doc["Channel"];
          if (doc.containsKey("URI"))
            strcpy(myData.uri, doc["URI"]);
          if (doc.containsKey("Username"))
            strcpy(myData.username, doc["Username"]);
          if (doc.containsKey("Password"))
            strcpy(myData.password, doc["Password"]);
          if (doc.containsKey("Job"))
            strcpy(myData.job, doc["Job"]);
          if (doc.containsKey("Instance"))
            strcpy(myData.instance, doc["Instance"]);
          if (doc.containsKey("Vfact"))
            myData.vfact = doc["Vfact"];
          if (doc.containsKey("TS"))
            myData.tempscale = doc["TS"];
          if (doc.containsKey("OWpin"))
            myData.OWpin = doc["OWpin"];
          if (doc.containsKey("SSID"))
            myData.ssid = (const char *)doc["SSID"];
          if (doc.containsKey("PSK"))
            myData.psk = (const char *)doc["PSK"];
          if (doc.containsKey("POLY"))
            strcpy(myData.polynominal, doc["POLY"]);
#if API_MQTT_HASSIO
          if (doc.containsKey("Hassio"))
            myData.hassio = doc["Hassio"];
#endif
          if (doc.containsKey("UseHTTPS"))
            myData.usehttps = doc["UseHTTPS"];
          if (doc.containsKey("Offset"))
          {
            for (size_t i = 0; i < (sizeof(myData.Offset) / sizeof(*myData.Offset)); i++)
            {
              myData.Offset[i] = doc["Offset"][i];
            }
          }

          CONSOLELN(F("parsed config:"));
#ifdef DEBUG
          serializeJson(doc, Serial);
          CONSOLELN();
#endif
        }
      }
    }
  }
  return true;
}
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

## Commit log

2016-11-22 Update README.md
    Notiz wo die Lib her ist
2016-12-11 sources online
    [drawer-cachersworldXLv11.stl]
2016-12-13 Battery correction
2016-12-18 drawer v12
    [drawer-cachersworldXLv12.stl]
2016-12-20 PCB doku
2017-01-17 Create README_iSpindle.py.DE.txt (#19)
    Kurze Erläuterung zu Einsatz und Konfiguration des iSpindle.py Skripts (Generic TCP Protokoll)
2017-01-31 Pictures PCB
2017-02-07 PCB+Tray documentation (#22)
    * Gitignore: VS solution- and project-files and VS bin-directories
    * added PCB+Tray docs
    * updated PCB+Tray docu (GY-521 LED, typography)
2017-02-11 entering config-mode on power-cycle (#25)
    * enable config-mode on power-cycle (works if the ESP isn't in deep-sleep when powering off)
    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
2017-02-12 config-mode: ESP "reset-reason" workaround (#26)
    * The ESP reset info is sill buggy. see http://www.esp8266.com/viewtopic.php?f=32&t=8411
    The reset reason is "5" (woken from deep-sleep) in most cases (also after a power-cycle)
    I added a single reset detection as workaround to enter the config-mode easier
    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
    [iSpindel.ino]
2017-02-14 Update compile.md (#28)
    Added warning about Board Manager
2017-02-15 Fix: Random crash on entering config portal from config mode due to PROGMEM inconsistencies (#29)
    * Update compile.md
    * Fix: Random crash when entering config portal from config mode due to PROGMEM inconsistency
    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
    [WiFiManagerKT.cpp]
2017-02-21 Added Installation instructions for Raspbian (#33)
    * Added SysVinit start/stop script for iSpindle.py
    * Added Installation Howto for Raspbian
    * Update INSTALL.md
    * Update INSTALL.md
    * Update INSTALL.md
    * Update INSTALL.md
    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
2017-02-23 english docs added
    [drawer-combo-short.stl]
2017-02-28 calibration first version
2017-02-28 Charts for genericTCP (#34)
    * Added Visualization from mySQL using Highcharts. Includes Temperature/Angle as a first proof-of-concept.
    * Updated time zone setting for highcharts
    * Several Last-Minute Bugfixes
    * Added battery.php and status.php, adjusted output of angle.php
    * removed stupid mac .DS_Store files
    * Fixed minus temps on angle.php
    * Added Polynom Calibration
    Added Timezone Adjustment (defaults to Europe/Berlin)
    Added and fixed Status charts
    * Added Instructions README
    * Update README.md
    * Updated chart instructions
    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
2017-03-01 Some minor adjustments... (#35)
    * A few adjustments, and some edited Docs
    * Fixed merged status.php
    * Minor fixes, rounding extract ˚P tooltip now to 2 decim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
2017-04-12 clearify #45
    [drawer-36x133-thing2231986.stl, drawer-38x133.stl, drawer-38x139.stl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]
2017-04-12 Add files via upload (#50)
    Hereby a Dutch description for assembling a iSpindel using a breadboard.
2017-04-12 dutch assemble
2017-06-19 switched to platformio
2017-08-08 calibration tool
    [Geocachingshop2-arm.stl, Geocachingshop2.stl]
2017-08-28 Sender class complete rework, tackles #76
    [iSpindel.cpp]
2017-08-31 genericTCP/iSpindel.de: (#86)
    Compatibility with Firmware > 5.4.x
    Support for User Token
    Server script now supports forwarding to other instances/public server
    Minor fixes regarding charts
    Changed algebraic sign of second coeff in plato4.php charts (Calibration table)
    Algebraic sign of the coefficient has now to be entered as in the polynomial
    Unix file permissions fixed
    Updated Docs
    modified: tools/generic-TCP/INSTALL.md
    modified: tools/generic-TCP/INSTALL_en.md
    modified: tools/generic-TCP/MySQL_CreateTables.sql
    new file: tools/generic-TCP/MySQL_UpdateTable-2.sql
    modified: tools/generic-TCP/README.md
    modified: tools/generic-TCP/README_en.md
    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
2017-10-08 circuit diagram in english and portuguese #89
2017-10-11 Add english breadboard mounting section to the README (#108)
2017-10-17 potential fix for exception with CraftbeerPi
    [iSpindel.cpp]
2017-11-09 extend calibration variant
2018-02-07 allow sleep interval up to 27 days fix #138
    [iSpindel.cpp]
2018-02-11 transmitting RSSI Wifi strength fix #137
    [iSpindel.cpp]
2018-02-23 mwx drawer
    [U12.scad, iSpindelBackbone2.scad, iSpindelBackbone2.stl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]
2018-03-08 Fahrenheit (#157)
    * Add support for logging data to a influxdb database server
    * Added possibility to select unit of temperature to report to remote loggers (Celsius, Fahrenheit, Kelvin).
2018-03-11 5.8.4 temperature scale
2018-03-11 save Flashstring improvements (#164)
    * Serial print statements to Flashstring
    * removing generic SerialOut handler
2018-03-22 featured in Braumagazin.de
2018-04-08 Translated the calibration sheet and added column for SG values (#170)
    * Update Calibration_en.md
    [Kalibrierung_en.xlsm]
2018-05-13 allow longer SSID and Polynom fields fix #177 #172
    [iSpindel.cpp]
2018-08-17 using stable for now until stage is able to build
2018-08-22 Detection of DS18b20 pin
2018-08-23 using wait time on Temp sensor to gain more Accelerator samples
2018-09-04 Display temperature in info page according to selected unit. (#204)
2018-09-04 Add messages to return code and limit connection attempt (#202)
    * Add messages to return code and limit connection attempt
    It will prevent waste all the battery when the broker is down and add some readable messages for debug purpose.
    * Display temperature in info page according to selected unit.
2019-03-07 pin ArduinoJson version
2019-05-13 Miscelaneous fixes (#271)
    * url: expand size to support longer urls
    Services like Brewersfriend use the token as part of the url, which
    greatly increases the length of the url to post to. Increase the field
    to 80 (TKIDSIZE * 2) to support such services. As a reference,
    Brewerfriends url seems to be at least 51 characters long.
    * docs/build: fix build instructions
    `pio run` should be called from the top-level directory.
    [iSpindel.cpp]
2019-05-22 migrating to ArduinoJSON v6
2019-07-24 fix typo error check
    [iSpindel.cpp]
2019-10-07 Fix for prometheus sender data (#303)
    Seems that after the migrating to ArduinoJSON v6 it was incorrectly
    implemted in the Prometheus SenderClass. Might also affect others.
2019-10-27 Added support for ThingSpeak (#305) (#308)
    * Added support for ThingSpeak (#305)
    * Fixed displaying Channel, too short fieldlength
    [iSpindel.cpp]
2019-11-17 refactor to build on upstream I2Cdevlib-MPU6050 library
2019-11-17 new Offset Calibration method and Filesystem config improvements
2020-01-31 add two point calibration support (#336)
    Thank you @vitotai
2020-02-06 Blynk option and email notification (#264)
    * Blynk option and email notification
    * Update platformio.ini
    * Blynk option and email notification
    * Update platformio.ini
    * Json from 5 to 6
    * Json 5 to 6 fix
    * Remove email, Terminal and HTTP code
    * Update Docs
    * Fix Blynk App Image link
    [iSpindel.cpp]
2020-02-06 Increased Max voltage factor to 25% and Fixed MQTT serial Log (#341)
    * Changed Voltage Factor to +25% and Fixed MQTT log
    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
    [iSpindel.cpp]
2020-06-09 Create calibrate.py (#370)
    simple python calibration tool
2020-06-14 TempSelectUpdate (#386)
    Update to correct how the temperature type selection saves to stop user having to select it twice.
2020-06-17 Update calibrate.py (#392)
    3rd degree poly - also works with iSpindel
2020-06-25 Polynomial Generation tools (#396)
    Tools works in google sheets though I don't think the graph draws correctly in google sheets.
    [ManualPolyGenerator.xlsx, iSpindelPolyEstimator.xlsx]
2020-08-27 calibration.htm outputs polynomials that can be copied directly. (#412)
2020-08-27 Fix url and uri mixing (#415)
    [iSpindel.cpp]
2020-11-15 Adding support of Brewblox using MQTT (#398)
    * Adding support of Brewblox using MQTT
    It requires Brewblox develop version (>= 2020/06/23), the MQTT port
    needs to be exposed, the iSpindel must be configured as follows:
    - Server Adress: name or IP of Brewblox/MQTT broker
    - Server Port: MQTT port which is 1883 by default
    - Path / URI: must be set to 'brewcast/history' which is the topic
    for the history service
    - Username and Password: MQTT authentication not yet supported on
    Brewblox side but comming soon.
    [iSpindel.cpp]
2021-03-18 Division by zero in tilt calculation fix (#470)
    [iSpindel.cpp]
2021-03-29 Commit to provide secureMQTT with X.509 certs as an option in sender class (#451)
    * Commit to provide secureMQTT with X.509 certs as an option in sender
    This is pre-cursor work to AWS IoT Core integration option that required secure connection.
    The main features here are:
    1) Creation of a method, SenderClass::SendSecureMQTT which is a copy of SendMQTT class with parameters for secure connections
    2) Modification of SenderClass::MQTTConnect to select WifiClient or WifiClientSecure object based on input parameters
    3) Due to memory constraint I had to reduce JSON buffer to 256 from 1024 in sender.h. This seems to be sufficient from checks I did on ArduinoJSON test site for the standard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
2021-03-29 Update Calibration_en.md (#482)
    Incorrect milliliters for for step 6
2021-05-22 Added a "FAQ for Improvements" file so noobs can see the tried paths ……that never made it (#497)
    * Added a "FAQ for Improvements" file so noobs can see the tried paths that never made it
    and why.
    * Added a bit about pressurized fermentation.
    * Moved to the docs/FAQ-en file and put a note in the README.md
2021-06-05 Add Chinese Documentation (#505)
    Initial support for zh-docs, working in progress. Greeting from Beijing Homebrewing Society, many thanks to the iSpindel project !
    [Kalibrierung_zh.xlsm]
2021-06-05 migrate to LittleFS
    Note: the configuration will be wiped and needs to be reconfigured afterwards!
    SPIFFS is replaced in favor of LittleFS being its successor.
    [iSpindel.cpp]
2021-06-18 Fix preprocessor directives to be able to turn APIs on and off if needs (#511)
    * Fix preprocessor directives to be able to turn APIs on and off if needs
    * Same preprocessor fixes for Sender
    [iSpindel.cpp]
2021-06-18 Bricks support (#509)
    * bricks support, first commit
    * wip (before POST)
    * first contact & stabilized
    * a little cleanup
    * version bump to 7.1.0 (feature: Bricks support)
    * updated docu
    * cleaned up code
    * added documentation
    * docu rework (moved lower & added to outline)
    * created createMd5Hash, hashed GDPR sensitive information
    * fixed merge typo
    * debugging
    * round sensor readings
    * re-using existing _client to save RAM
    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
    [iSpindel.cpp]
2021-10-01 make tilt angle independent of the board orientation (#531)
2021-10-06 Pull Request #529 rebase (#543)
    * Pull Request #529 rebase
    * Rebase leftovers fix
    [iSpindel.cpp]
2022-02-04 Support SG on BierBot Bricks (#559)
    * support SG on BierBot Bricks
    If iSpindel transmits SG (and not °P) 1 decimal (1.0, `round(x*10)/10`) is not sufficient.
    * updated to 4 decimals (SG=1.0482)
    * remove value truncation
    * fixing docu
    * clang format comment
    [iSpindel.cpp]
2022-02-04 Latest expressif8266 platform update - I2CDev / MPU6050 libs incompatibility build error fix (#566)
2022-03-31 docs: correct antenna length in docs/FAQ-en.md (#579)
2022-05-01 Ability to save and load data of calibration points. (#572)
    * calibration.htm outputs polynomials that can be copied directly.
    * save & load calibration data
2022-08-25 Add timeout when waiting for gyro data ready status (#591)
2022-11-07 Calibrate Battery Voltage
    Measure current Battery voltage to calculate and store the conversion factor
2023-01-02 Repair for ArduinoJson 6.20.0 (#598)
2024-04-23 Update platformio.ini (#618)
    ArduinoJson version 7 and above is a huge change and causes the project to fail to compile
2025-02-12 Implement LocalServer. A simple http server that collects and plots iSpindel data. (#632)
    * Implement LocalServer. A simple http server written in Golang that collects and plots iSpindel data on local network.
    * Filter non alpha numerical characters from filename.
    [SpinHydro.csv, calibration.csv]
